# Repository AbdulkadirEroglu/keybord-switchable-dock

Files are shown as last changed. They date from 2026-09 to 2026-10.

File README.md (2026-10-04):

# Dual-PC Keyboard Router & Wireless Control Pad

A custom hardware project for sharing one physical USB keyboard between two computers while adding a detachable wireless control pad for call controls, media controls, macros, status feedback, and target selection.

The design prioritizes **reliability, recoverability, wired PC connections, explicit physical control, and independent debug paths**.

## System Overview

The project consists of two custom devices:

1. **Main Dock / Keyboard Router (v2)**
   - Accepts a normal USB keyboard (USB-C).
   - Connects to both Personal and Work PCs over USB and appears as a keyboard to each.
   - Routes keyboard/HID reports to the selected target.
   - Receives the pad's events and selector state over BLE.
   - Powered by its own **USB-C PD charger** (asks for 9 V; a 30 W charger is used). It never draws power from, or back-feeds, the PCs.
   - Chips on the board, built by **JLCPCB** (machine assembly); two through-hole parts are hand-soldered.

2. **Wireless Control Pad** (to be redesigned; current plan below)
   - Detachable and battery powered.
   - 12 mechanical keys.
   - Two rotary encoders with push switches.
   - 36 addressable RGB LEDs.
   - 1.69" colour IPS display (SPI).
   - Physical `PERSONAL | OFF | WORK` metal toggle switch.
   - Li-ion 21700 battery pack, charged while docked.
   - BLE is the normal data link; the pogo UART is reserved for diagnostics/recovery.

## High-Level Architecture

```text
┌──────────── WIRELESS CONTROL PAD ────────────┐
│ Pico 2 WH (RP2350 + CYW43439)   [v1 plan]    │
│ keys, encoders, RGB, display, selector,      │
│ battery + charger                            │
└──────────┬──────────────────────┬────────────┘
           │ BLE                  │ 7-pin magnetic pogo (5 V, DET, UART)
           ▼                      ▼
┌────────────────────── MAIN DOCK (v2) ──────────────────────┐
│ ESP32-C3-MINI-1 (BLE) ── UART ──┐                          │
│                                 ▼                          │
│ keyboard ═ USB-C ═ PIO-USB ═► RP2354A A ═ USB ═► PERSONAL  │
│                                 │ UART, RUN, BOOTSEL, SWD  │
│                                 ▼                          │
│                             RP2354A B ═══ USB ═► WORK      │
│                                                            │
│ USB-C PD charger ─ CH224A (9 V) ─ TPS54331 5 V ─ 3.3 V LDO │
└────────────────────────────────────────────────────────────┘
```

## Main Hardware

### Dock (v2)

| Function | Part |
|---|---|
| Keyboard host + Personal PC endpoint | RP2354A **A** (RP2350 with 2 MB flash, QFN-60): Pico-PIO-USB host + native USB device |
| Work PC endpoint | RP2354A **B** (native USB device) |
| BLE to the pad | ESP32-C3-MINI-1-H4X module (pre-certified, PCB antenna), UART to A |
| Power input | USB-C, CH224A PD sink (9 V, I2C status to A), SMBJ15A TVS |
| 5 V | TPS54331 buck (5.16 V, 3 A), SLO0630H6R8MTT 6.8 µH, SS54 |
| 3.3 V | AMS1117-3.3 |
| Keyboard VBUS | SY6280AAC, 1.0 A, switched on only when a keyboard is detected on CC |
| Pad 5 V (pogo) | SY6280AAC, 1.45 A, switched on in hardware when the pad is docked (DET) |
| ESD | TPD4E1U06 on every USB-C port and the pogo contacts |
| Connectors | 4 × USB-C (TYPE-C-31-M-12); 7-pin JST-XH header to the pogo board in the dock lid (straight 7-pin magnetic pogo contacts) |
| Crystals | ABM8-272-T3 (Raspberry Pi's recommended part) |

Every part, its value and LCSC number: [`hardware/dock-v2/DOCK_CONNECTIONS.md`](hardware/dock-v2/DOCK_CONNECTIONS.md). Why each was chosen: `docs/dock-v2-*.md`.

### Pad (v1 plan, to be redesigned)

| Function | Selected Part / Design |
|---|---|
| Pad MCU / wireless | Raspberry Pi Pico 2 WH, socketed (on-board buck-boost 3.3 V) |
| Pad GPIO expander | TCA9555 |
| Pad charger | TP4056 (switchable ≈ 146 / 510 mA, NTC 0–45 °C, Pico-controlled enable for a 70–80 % docked window) |
| Pad power path | TPS2116 (pogo 5 V priority, battery fallback) |
| Cell protection | DW01A + FS8205A |
| Battery | 2 × Samsung SDI INR21700-50E in parallel (3.6 V, ≈ 9.8 Ah Li-ion), dual 21700 holder |
| RGB 5 V boost | TPS61023 |
| RGB logic buffer | SN74AHCT1G125 |
| RGB LEDs | 36 × SK6812MINI-E (reverse mount) |
| Keys | 12 × Razer Yellow Linear (3-pin MX) in Kailh hot-swap sockets, FR4 plate |
| Encoders | 2 × Bourns PEC11R-4220F-S0024 (24 detents, push switch) |
| Target selector | Metal SPDT ON-OFF-ON toggle |
| Display | 1.69" 240×280 IPS TFT, ST7789, SPI, PWM backlight |

## Target Selection

The physical selector is located on the **control pad**, not the dock.

```text
PERSONAL
   │
  OFF
   │
 WORK
```

The mechanical switch is the source of truth. Its state travels:

```text
Toggle → Pad → BLE → ESP32-C3 → UART → RP2354A A
```

If the pad/BLE connection is lost, the dock must eventually release all active HID states and enter `OFF`.

## Communications

- Keyboard → RP2354A A: USB host (Pico-PIO-USB)
- RP2354A A → Personal PC: USB HID (native USB)
- RP2354A A ↔ RP2354A B: 1 Mbaud+ UART; B → Work PC: USB HID
- Pad ↔ dock: BLE (ESP32-C3 central, pad peripheral), ESP32-C3 ↔ A: UART
- Pogo UART (A's PIO UART): debug/recovery only

The internal UART protocol uses framed binary packets:

```text
SOF | TYPE | SEQ | LEN | PAYLOAD | CRC
```

Normal HID reports may be fire-and-forget. Critical control operations can require acknowledgement.

## Fail-Safe Philosophy

The design should fail toward **released keys and no routing**, not toward a stuck input.

- Target change → release the previous endpoint before changing the route.
- `OFF` → release both endpoints.
- BLE/pad timeout → release all and route OFF.
- A ↔ B link timeout → B sends a released state and idles; A can reset B.
- Keyboard faults → A power-cycles the keyboard's VBUS.
- Every MCU has a physical recovery path, and A can reflash B (SWD) and the ESP32-C3 (UART) from the Personal PC.

## Mechanical Baseline

- **Dock:** PCB 100 × 100 mm, 2 layers. PC cables leave at the back, the keyboard at the left, the charger at the right. **The pad sits on top of the dock:** the pogo contacts are on a small board in the dock lid, cabled to the dock board.
- **Pad (v1 plan):** wedge enclosure ≈ 160 × 110–120 mm, front ≈ 25 mm, back ≈ 44 mm, battery at the back under the display/encoder row.

Docking contacts (dock side), magnets on both sides:

```text
GND | +5V | DET | RX | TX | +5V | GND
```

## Repository Layout

```text
dock-pad/
├── hardware/
│   ├── dock-v2/        v2 dock: KiCad project, DOCK_CONNECTIONS.md, PCB_PLACEMENT.md
│   ├── dock/           v1 dock (Pico modules), reference
│   ├── pad/            pad (v1 plan)
│   ├── pogo/           pad pogo board
│   ├── libraries/      shared symbols/footprints/3D models (THIRD_PARTY.md)
│   ├── reference/      Raspberry Pi RP2350A Minimal design (MIT)
│   └── tools/          RPi core-layout copy script, dock v2 connection model and wiring checker
├── mechanical/
├── firmware/
├── datasheets/
├── docs/               dock v2 design decisions (dock-v2-*.md), pad drawings
├── README.md
└── DESIGN.md
```

## Current Project State

- **Dock v2 (branch `dock-v2`):** every part decided and placed on the six schematic sheets (154 parts, values, footprints, LCSC numbers). Next: wiring the schematic by hand from [DOCK_WIRING.md](hardware/dock-v2/DOCK_WIRING.md) (component by component; the circuit is explained in DOCK_CONNECTIONS.md) (checked with `hardware/tools/dock_v2_connections/check_wiring.py`), then placement and routing on a 4-layer board. The order cost will be calculated when the PCB is ready.
- **Pad:** being redesigned. Decided so far: **ESP32-S3-MINI-1-N8** (MCU + BLE, JLC assembly), the pad **sits on top of the dock** with its pogo board in the floor, **1 × 21700-50E** with an **ETA6003** switching charger (power path), charged only on the dock, TLV75733P 3.3 V LDO, direct-GPIO keys/encoders, SK6812MINI-E + XL-2020 LEDs on a TPS61023 5 V boost, Meon 1.69" ST7789 module. Decisions: `docs/pad-v2-*.md`. The rest of `hardware/pad/` is still the v1 plan.
- **v1 dock:** complete (routed, DRC clean) on `master`; superseded by v2.

See [DESIGN.md](DESIGN.md) for the engineering baseline.

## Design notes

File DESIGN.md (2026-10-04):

# DESIGN.md — Engineering Baseline

**Status (2026-09-29, branch `dock-v2`):**

- **Dock: v2**, chips on the board, JLCPCB assembly. Decided part by part in the design review; the reasoning is in `docs/dock-v2-mcu-selection.md`, `dock-v2-power-input.md`, `dock-v2-usb-ports.md`, `dock-v2-pogo.md`, `dock-v2-mcu-support.md`. The wiring is in [`hardware/dock-v2/DOCK_CONNECTIONS.md`](hardware/dock-v2/DOCK_CONNECTIONS.md), placement in [`hardware/dock-v2/PCB_PLACEMENT.md`](hardware/dock-v2/PCB_PLACEMENT.md). Sections 1–7 and 16–22 below describe the v2 dock.
- **Pad: to be redesigned.** Sections 8–14 are the v1 pad plan, kept unchanged as the starting point. Section 15 (docking) already has the v2 7-pin interface.
- **v1 dock** (three Pico modules, powered from the PCs): complete on `master` (`hardware/dock/`, the v1 version of this file).

## 1. Design Goals

- One physical USB keyboard shared between two computers.
- PC-side connections remain wired USB.
- No software running on either PC is required for basic keyboard routing.
- Physical `PERSONAL | OFF | WORK` selection (on the pad).
- Detachable wireless control pad.
- Robust recovery and debug access: every MCU can be reflashed without special tools.
- **The dock is powered by its own USB-C PD charger** (≥ 18 W; a 30 W charger is used). It does not draw power from the PCs, and it never back-feeds a PC that is switched off. (v1 ran from the PCs; dropped in v2, see `docs/dock-v2-power-input.md`.)
- Pad charges automatically while docked.
- BLE is used only between the pad and the dock.
- Failure states must avoid stuck keyboard/modifier/media reports.
- **Built by JLCPCB** (machine assembly of the fine-pitch parts); only a few through-hole parts are hand-soldered.

---

## 2. System Partitioning

### 2.1 Main Dock (v2)

Responsibilities:

- USB-host the physical keyboard (USB-C port, the dock is the source).
- Present a USB keyboard to each PC.
- Route keyboard/HID reports to the selected target.
- Receive pad events and the selector state over BLE.
- Power the keyboard (switched, current-limited) and the docked pad (switched by DET, current-limited).
- Negotiate 9 V from a USB-C PD charger and make 5 V and 3.3 V.

```text
 charger ═ J101 ─ CH224A (9 V) ─ TPS54331 ─ +5V ─┬─ AMS1117 ─ +3V3
                                                 ├─ SY6280 ─ KBD_VBUS ─► keyboard
                                                 └─ SY6280 ─ POGO_5V ──► pad
 keyboard ═ J201 ═ PIO-USB ─┐
                            ▼
 Personal PC ═ J202 ═══ RP2354A A ◄── UART0, RUN, BOOTSEL, SWD ──► RP2354A B ═══ J203 ═ Work PC
                            │  └── UART1 ──► ESP32-C3-MINI-1 ~~ BLE ~~ pad
                            └── PIO UART, DET ──► pogo J601 ═ pad (docked)
```

| Device | Ref | Job |
|---|---|---|
| RP2354A **A** (RP2350 + 2 MB flash, QFN-60) | U301 | Keyboard host (Pico-PIO-USB), Personal PC device (native USB), router, controls B, the ESP32 and the pogo |
| RP2354A **B** | U401 | Work PC device (native USB) |
| ESP32-C3-MINI-1-H4X | U501 | BLE central to the pad (pre-certified module, PCB antenna), UART to A |
| CH224A | U102 | USB-PD sink: asks for 9 V; I2C status to A |
| TPS54331 + SS54 + 6.8 µH | U103, D102, L101 | 5 V buck (5.16 V), 3 A; 100 % duty pass-through on a 5 V-only charger |
| AMS1117-3.3 | U104 | 3.3 V for A, B, the ESP32 |
| SY6280AAC × 2 | U202, U602 | Keyboard VBUS switch (1.0 A), pogo 5 V switch (1.45 A) |
| TPD4E1U06 × 5 | U101, U201, U203, U204, U601 | ESD on every USB-C port and the pogo contacts (clamps to GND only: no back-feed path into an unpowered PC) |
| TYPE-C-31-M-12 × 4 | J101, J201, J202, J203 | Power, keyboard, Personal PC, Work PC |
| Magnetic pogo, 7 pins | J601 | Pad docking (hand-soldered) |

Why two chips: no affordable MCU has three USB 2.0 controllers (researched in `docs/dock-v2-mcu-selection.md`); A does the host and one device, B the other device. Why RP2354A: same firmware base as v1 (TinyUSB + Pico-PIO-USB, hub support), UF2 flashing, no programmer needed.

### 2.2 Wireless Control Pad (v1 plan, to be redesigned)

> **Being redesigned (v2, 2026-10-04).** Decided so far: ESP32-S3-MINI-1-N8 replaces the Pico 2 WH and the TCA9555 (`docs/pad-v2-mcu-selection.md`); the pad sits on top of the dock (§15); one 21700-50E with an ETA6003 switching charger replaces the 2-cell pack, TP4056 and TPS2116, no USB-C charging, 3.3 V from a TLV75733P LDO (`docs/pad-v2-battery-charging.md`); keys, encoders and toggle on direct GPIOs (no TCA9555), hand-soldered hot-swap sockets and SK6812MINI-E key LEDs, XL-2020 ring LEDs, TPS61023 + AHCT1G125 (`docs/pad-v2-inputs-rgb.md`); Meon 1.69" ST7789V3 module on a cable, AO3401 power switch, PWM straight into BLK (`docs/pad-v2-display.md`). Sections 8–14 below are the v1 plan and are superseded where these docs differ.

Responsibilities:

- Read 12 mechanical keys.
- Decode two rotary encoders.
- Read two encoder push switches.
- Read the target selector.
- Drive 36 addressable RGB LEDs.
- Drive the display.
- Communicate with dock over BLE.
- Monitor battery and charger state.
- Manage sleep/wake and switched peripheral power.
- Charge from docked 5 V input.

Primary devices:

- MCU + BLE — Raspberry Pi Pico 2 WH (RP2350 + CYW43439), socketed like the dock modules (§18.1)
- TCA9555 — 16-bit I2C GPIO expander (keys, encoder switches, selector)
- TP4056 — Li-ion linear charger (ESOP-8), Pico-controlled enable
- TPS2116 — power path: pogo 5 V (priority) or battery → `PAD_SYS`
- DW01A + FS8205A — cell protection (over-discharge, overcurrent, short)
- TPS61023 — 5 V boost for the RGB LEDs
- TPS22919 — OLED load switch
- SN74AHCT1G125 — RGB data level shifter
- 2 × Samsung SDI INR21700-50E Li-ion cells (4900 mAh each, 9.8 Ah total) in parallel, in a dual 21700 holder, with a 10 k NTC between them
- 36 × SK6812MINI-E reverse-mount RGB LEDs
- 1.69" 240 × 280 ST7789 colour IPS display
- Separate small pogo board in the back wall (pogo connector, TVS, ESD), cable to the main board
- 12 × Razer Yellow Linear (MX-compatible, 3-pin) switches in Kailh hot-swap sockets, FR4 switch plate
- 2 × Bourns PEC11R-4220F-S0024 encoders with push switch

All parts are hand-solderable (leaded packages, or the TPS2116/TPS61023 TI SOT-5x3 family with extended hand-solder pads). No BGA/QFN/WSON parts: the BQ25185 and TPS63802 were dropped for that reason.

The Pico 2 WH has its own buck-boost 3.3 V regulator that runs from 1.8–5.5 V on `VSYS`, so the pad needs no 3.3 V regulator; the Pico's `3V3` pin (≤ 300 mA recommended) powers the TCA9555, pull-ups and the OLED switch.

---

## 3. Dock USB Ports (v2)

All four are the same 16-pin USB 2.0 USB-C receptacle (TYPE-C-31-M-12, rated 20 V / 5 A), each with a TPD4E1U06 within 5 mm (D+, D−, CC1, CC2).

| Port | Role | CC | Data | VBUS |
|---|---|---|---|---|
| J101 power (right edge) | sink | CH224A (built-in Rd) | CH224A D+/D− (QC/BC1.2) | VBUS_IN, SMBJ15A TVS |
| J201 keyboard (left edge) | **source** | 33 k Rp to 3.3 V (Default USB), read by A's ADC | A GPIO3 D+ / GPIO2 D− (PIO-USB, `PIO_USB_PINOUT_DMDP`) via 22 Ω, 15 k host pull-downs | KBD_VBUS from SY6280, 220 µF THT + 10 µF + 1 µF |
| J202 Personal PC (back) | sink | 5.1 k Rd | A USB_DP/DM via 22 Ω | **sense only**: 22 k / 33 k divider to A GPIO1 |
| J203 Work PC (back) | sink | 5.1 k Rd | B USB_DP/DM via 22 Ω | **sense only**: divider to B GPIO29 |

- **Keyboard port (cold socket):** KBD_VBUS stays off until A sees a sink's Rd on CC (≈ 0.44 V) for > 100 ms; off again on unplug. A charger or PC plugged in by mistake shows Rp, so the dock never turns VBUS on against it. EN has a 100 k pull-down: off at reset and with blank firmware.
- **PC ports:** the dock takes no power from the PCs. Each MCU enables its D+ pull-up (connects) only while its PC's VBUS is present.
- Ground is shared by both PCs, the charger and the dock (as in v1 and every KVM switch); the charger is isolated.

---

## 4. Dock Power (v2)

### 4.1 Input

```text
J101 VBUS ─ VBUS_IN ─┬─ SMBJ15A ─ GND
                     ├─ CH224A VHV/VBUS (CFG1 = 6.8 k → asks 9 V; SCL/SDA/PG → MCU A)
                     └─ TPS54331 VIN
```

- **9 V** is mandatory on every PD source above 15 W (12 V is optional and often missing).
- CH224A over I2C (0x22): which protocol won, requested voltage, maximum current of the current profile; can re-request 5 V. PG is a backup. The pad's charge speed follows from this (§12.2).
- On a charger without PD the dock still runs: the TPS54331 runs at 100 % duty and passes ≈ 4.7 V through; firmware then keeps pad charging slow.

### 4.2 Rails

| Rail | Source | Notes |
|---|---|---|
| +5V | TPS54331, 12 k / 2.2 k → 5.16 V | TI Table 7-1 values on Basic parts: 51 k + 4.7 nF + 47 pF compensation, 10 nF soft start, 3 × 22 µF out; L101 SLO0630H6R8MTT (Isat 8 A > 5.8 A max current limit). EN left open (a UVLO divider would stop the 5 V pass-through). |
| +3V3 | AMS1117-3.3 from +5V | ≤ 0.4 A peak (A, B, ESP32 BLE TX ≈ 170 mA at 0 dBm) |
| KBD_VBUS | SY6280, R_SET 6.8 k → 1.0 A (0.75–1.25 A) | EN from A (100 k pull-down); KBD_VBUS measured by A's ADC (replaces a fault pin) |
| POGO_5V | SY6280, R_SET 4.7 k → 1.45 A (1.09–1.81 A) | EN pulled high only when the pad grounds DET (hardware); A can veto (§15); POGO_5V measured by A's ADC |

### 4.3 Budget

| Load | Typical | Limit |
|---|---|---|
| Keyboard | 0.1–0.2 A (current keyboard: 200 mA rated) | 1.0 A |
| Pad (charging 0.51 A + electronics + LEDs) | 0.7–0.8 A | 1.45 A |
| 3.3 V rail | 0.15 A | 0.4 A |
| **+5V total** | **≈ 1 A** | ≈ 2.85 A at the nominal limits (TPS54331: 3 A) |

From 9 V at ≈ 90 % efficiency, even the worst case is ≈ 17 W: fine for the 30 W charger.

---

## 5. USB Endpoint Architecture (v2)

- **MCU A** is the keyboard host *and* the Personal PC's keyboard (native USB device). **MCU B** is the Work PC's keyboard. Each enumerates with its PC and stays enumerated when not selected.
- Each endpoint exposes at least Keyboard HID and Consumer Control HID; a vendor HID interface is optional.
- A and B run different firmware images (A: TinyUSB host + device + router + BLE link; B: device + link only).
- Each MCU watches its own PC's VBUS and connects its D+ pull-up only while VBUS is present (no back-feed into a PC that is off).
- A controls B: **RUN** (reset), **BOOTSEL** (via 1 k to B's QSPI_SS) and **SWD** (A can reflash and recover B, Raspberry Pi debugprobe style). B_RUN and B_BOOTSEL have 10 k pull-ups so A's reset-state pull-downs can't hold B in reset or BOOTSEL.

---

## 6. Internal Links (v2)

| Link | MCU A pins | Other end | Implementation |
|---|---|---|---|
| A ↔ B (HID reports, Work PC) | GPIO24 TX / GPIO23 RX | B GPIO5 RX / GPIO6 TX | hardware UART1 (RX on A and TX on B use the F11 aux function), 1 Mbaud or faster |
| A ↔ ESP32-C3 (BLE data, ESP32 flashing) | GPIO12 TX / GPIO13 RX | ESP32 RXD0 / TXD0 | hardware UART0 |
| ESP32 control | GPIO9 → EN, GPIO10 → GPIO9 (BOOT) | 10 k pull-ups, EN RC 10 k / 1 µF | open-drain |
| Pogo UART (diagnostics/recovery) | GPIO16 TX / GPIO15 RX; GPIO14 DET, GPIO11 OFF | pad, through 1 k on each side | PIO UART |
| CH224A | GPIO18 SDA / GPIO19 SCL, GPIO17 PG | CH224A | I2C1 |
| B control | GPIO20 RUN, GPIO25 BOOTSEL, GPIO22/21 SWCLK/SWDIO | B | open-drain / PIO SWD |

The full pin maps (every GPIO, with the reason for each choice) are in DOCK_CONNECTIONS.md §5–6. Keystrokes never pass through BLE: BLE carries only pad events and the selector state. With the radio on its own module, BLE stack faults can't disturb USB timing on A.

### 6.1 Packet Framing

Baseline (unchanged from v1):

```text
SOF | TYPE | SEQ | LEN | PAYLOAD | CRC
```

Likely message classes: `KEYBOARD_REPORT`, `CONSUMER_REPORT`, `RELEASE_ALL`, `PING`, `PONG`, `GET_STATUS`, `STATUS`, `RESET_USB`, `SET_MODE`.

Prefer complete HID state/report messages over key-down/key-up event streams. Normal HID traffic need not wait for an ACK; critical control operations may use ACK/sequence verification.

---

## 7. Routing Safety

Target changes (the Personal side is A's own USB device; the Work side is B over UART0):

- **PERSONAL → WORK:** receive the new selector state → release all on A's Personal device → change the route → B starts from a released state → forward the current state to B.
- **WORK → PERSONAL:** the same, reversed (`RELEASE_ALL` to B first).
- **Any target → OFF:** release Personal, send `RELEASE_ALL` to B, route NONE.
- **BLE loss** (no valid pad state for the timeout): release all, route OFF.
- **A ↔ B link loss:** B watches the link independently; on timeout it sends released keyboard and consumer reports, stays enumerated and idles safely. A resets B (RUN) if the link doesn't recover.
- **Keyboard faults:** A can power-cycle KBD_VBUS (SY6280 EN) to force re-enumeration.

---

> **Sections 8–14: the v1 pad plan, kept unchanged.** The pad will be redesigned; treat these as the starting point, not as decisions.

## 8. Pad User Interface

### 8.1 Mechanical Keys

V1:

- 12 keys
- Razer Yellow Linear (Gen-3) switches: MX-compatible, 3-pin, 45 g, transparent housing with an LED lens
- Kailh MX hot-swap sockets on the PCB
- 1.5 mm FR4 switch plate (14 mm cutouts), held on spacers to the pad PCB and enclosure. 3-pin switches have no PCB-locating pegs, so the plate carries them.
- 4 × 3 arrangement
- approximately 19.05 mm pitch
- One SK6812MINI-E per key, reverse-mounted under the switch's LED lens (§10)

```text
[01] [02] [03] [04]
[05] [06] [07] [08]
[09] [10] [11] [12]
```

### 8.2 Encoders

Two rotary encoders with push switches: Bourns PEC11R-4220F-S0024 (TME): 24 detents / 24 pulses, 20 mm metal flatted shaft, push switch, EC11-compatible 5-pin THT footprint (datasheet `datasheets/pec11r.pdf`). 24 detents = 2 clicks per LED on the 12-LED ring.

Intended roles:

- Encoder 1: volume
- Encoder 2: microphone/call controls

Quadrature A/B signals connect directly to Pico GPIO and are decoded by PIO. Each A/B line has a 10 kΩ pull-up to 3V3 and 10 nF to GND (debounce); the encoder common goes to GND.

Push switches connect through TCA9555.

### 8.3 Target Selector

Physical metal panel-mount SPDT `ON-OFF-ON` toggle.

States:

```text
PERSONAL
OFF
WORK
```

Two TCA9555 inputs encode the state:

| Input A | Input B | State |
|---:|---:|---|
| 0 | 1 | PERSONAL |
| 1 | 1 | OFF |
| 1 | 0 | WORK |
| 0 | 0 | INVALID / FAULT |

The selector is the authoritative target state.

---

## 9. TCA9555 Allocation

16 GPIO total:

```text
12 × mechanical keys
 2 × encoder push switches
 2 × target-selector contacts
------------------------------
16 × GPIO
```

- I2C SDA/SCL → Pico (hardware I2C)
- INT → Pico GPIO (also the wake source from dormant sleep)
- Exact pull-up implementation must be verified against the selected TCA9555 variant/datasheet during schematic capture.
- Encoder A/B signals do not use the expander.

### 9.1 Pad Pico GPIO Allocation

Initial map from the schematic (grouped by function; may be re-pinned by PCB position, as on the dock):

| GPIO | Pin | Signal | GPIO | Pin | Signal |
|---|---|---|---|---|---|
| GP0 | 1 | PAD_UART_TX (UART0, pogo) | GP16 | 21 | RGB_EN (TPS61023 EN) |
| GP1 | 2 | PAD_UART_RX (UART0, pogo) | GP17 | 22 | CHG_FAST (PROG MOSFET) |
| GP2 | 4 | ENC1_A (PIO) | GP18 | 24 | CHG_INHIBIT (CE MOSFET) |
| GP3 | 5 | ENC1_B (PIO) | GP19 | 25 | CHG_CHRG_N |
| GP4 | 6 | I2C_SDA (I2C0) | GP20 | 26 | CHG_STDBY_N |
| GP5 | 7 | I2C_SCL (I2C0) | GP21 | 27 | DOCKED (TPS2116 ST) |
| GP6 | 9 | ENC2_A (PIO) | GP22 | 29 | OLED_EN (TPS22919 ON) |
| GP7 | 10 | ENC2_B (PIO) | GP26 | 31 | VBAT_SENSE (ADC0, VBAT/2) |
| GP8 | 11 | TCA_INT_N (wake source) | GP27 | 32 | OLED_BLK (display backlight PWM) |
| GP9 | 12 | RGB_DATA_3V3 (PIO) | GP28 | 34 | spare (ADC2) |
| GP10 | 14 | OLED_SCK (SPI1) | GP15 | 20 | free (1×19 socket possible) |
| GP11 | 15 | OLED_MOSI (SPI1 TX) | | | |
| GP12 | 16 | OLED_DC | | | |
| GP13 | 17 | OLED_CS (SPI1 CSn) | | | |
| GP14 | 19 | OLED_RES | | | |

---

## 10. RGB System

### 10.1 LED Count

```text
Volume encoder ring       12
Microphone encoder ring   12
Key LEDs                  12
----------------------------
Total                     36
```

LED: SK6812MINI-E (reverse mount, side legs reachable with an iron), one part for keys and rings, one chain. Each LED sits in a small PCB cutout and shines up through it. Sourced from LCSC (C5149201), combined with the JLCPCB order.

Design power budget must tolerate approximately:

```text
36 × 15 mA ≈ 540 mA @ 5 V
≈ 2.7 W
```

even though firmware will normally impose a much lower global brightness.

### 10.2 RGB Power

```text
PAD_SYS
    │
TPS61023 (boost, EN from Pico)
    │
  5V_RGB
    ├── SN74AHCT1G125
    └── RGB LEDs
```

TPS61023 (SOT-563, hand-solder footprint like the TPS2116):

- Output set to ≈ 5.05 V: R1 = 750 kΩ (VOUT→FB), R2 = 100 kΩ (FB→GND); VREF ≈ 0.6 V ±2.5 %, worst case ≈ 5.2 V (< SK6812 5.5 V max).
- Inductor 1 µH, shielded ~4 × 4 mm, I_sat ≥ 4.5 A, DCR ≤ 20 mΩ (TI-recommended: Würth 74438357010, Coilcraft XEL4030-102ME, or equivalent). Worst-case peak ≈ 3.8 A at 2.7 V in, 1.5 A out.
- C_in 10 µF; C_out 2 × 22 µF X7R ≥ 16 V (≥ 4 µF effective after DC bias).
- `EN` from a Pico GPIO with a 100 kΩ pull-down, so the LEDs stay off while the Pico boots.
- True output disconnect when disabled: the LEDs draw nothing when the rail is off (SK6812 idle current would otherwise drain the cell).
- Docked (`PAD_SYS` ≈ 5 V) the device enters pass-through; on battery it boosts.

### 10.3 RGB Data

```text
Pico 3.3 V GPIO (PIO)
        │
SN74AHCT1G125
        │
 5 V logic data
        │
 33–100 Ω footprint
        │
 SK6812MINI-E DIN
```

Buffer supply comes from `5V_RGB` so the RGB subsystem loses both power and data drive when disabled.

---

## 11. Display

Display is required in V1.

Module: 1.69" 240 × 280 colour IPS TFT, ST7789 (V3) controller, SPI, rounded corners (Meon Otomasyon, "TFT LCD 1.69 İnç 240x280 ST7789 V3 SPI Display Modülü"). Chosen over the 1.3" monochrome OLED for colour and resolution at about the same module size, over the 1.9" 170 × 320 bar (not sold as a bare module in Turkey) and over the 2.0" GMT020-02 (its 62 × 37 mm module would push the board to ≈ 120 mm wide, and its backlight cannot be dimmed).

Typical pinout of these 8-pin modules (verify against the actual board before the PCB):

```text
GND
VCC   (3.3–5 V)
SCL   (SPI clock)
SDA   (SPI MOSI, not I2C)
RES
DC
CS
BLK   (backlight)
```

Backlight: ≈ 41 mA measured on this module type. BLK is driven through a P-MOSFET (AO3401A) from `OLED_VCC`, gate from Pico GP27 with a 10 kΩ pull-up to `OLED_VCC` (backlight off until firmware pulls GP27 low; PWM for dimming). The MOSFET works whether BLK is a direct LED anode or the input of an on-module transistor.

Firmware: ST7789 at 240 × 280 needs a 20-row offset (the controller RAM is 240 × 320).

Connection: the module is mounted to the case behind its window and wired to the main PCB with a short (≈ 10 cm) 9-wire JST-PH 2.0 mm cable (9-pin chosen because the ready-made cable is in stock at Robotistan). Main PCB: JST B9B-PH-K-S (9-pin PH, through-hole, shrouded, keyed; TME). Pins 1–8 carry the module's 8 signals; pin 9 is a second GND for a better SPI return path. The cable's bare end is soldered to the module's pads, both GND wires to the module's GND pad. The display's pads come unpopulated, so no header is needed on the module.

Mechanical allowance:

- module about 31 × 38 mm (typical); measure the real board outline, window and holes before placement

Power:

```text
Pico 3V3 → TPS22919 → OLED_VCC → module VCC and backlight MOSFET
```

The net names keep the `OLED_` prefix from the first design; they now refer to this TFT.

Shutdown sequence:

1. Turn the backlight off (GP27 high).
2. Put the display into sleep.
3. Put SPI/control pins into a safe low/high-impedance state.
4. Disable TPS22919.

---

## 12. Pad Battery and Charging

### 12.1 Cell

Samsung SDI INR21700-50E (datasheet: `datasheets/samsung-inr21700-50e.pdf`, spec v0.2). Buy from TME (authorized distributor, genuine cells); verify weight ≤ 69 g on arrival.

| Item | Datasheet value |
|---|---|
| Chemistry | Li-ion, 3.6 V nominal |
| Capacity | ≥ 4900 mAh (0.2C), ≥ 4753 mAh (1C) |
| Charge voltage | 4.2 V, CC-CV |
| Standard charge | 0.5C = 2450 mA, 0.02C cut-off |
| Max charge current | 4900 mA (not for cycle life) |
| Discharge cut-off | 2.5 V |
| Max continuous discharge | 9.8 A |
| Cycle life | ≥ 80 % after 500 cycles (0.5C charge to 4.2 V / 1C discharge to 2.5 V, full depth) |
| Charge temperature | 0 to 45 °C (cell surface) |
| Discharge temperature | −20 to 60 °C |
| Storage | ex-factory at ~30 % (3.43–3.63 V); 1 year at −20 to 23 °C |
| Size / weight | Ø 21.25 × 70.80 mm max (with sleeve), flat top, 69 g max |

Operating window chosen for maximum life. The datasheet gives only the hard limits; the narrower window is standard Li-ion practice (lower average voltage and shallower cycles slow both calendar and cycle ageing):

| Limit | Value | Enforced by |
|---|---|---|
| Hard max (datasheet) | 4.20 V | Charger CV regulation |
| Docked hold window (default) | stop at 4.00 V, resume below 3.90 V (≈ 80 % / 70 %) | Firmware via the charger enable pin |
| Full charge on request | 4.20 V | Firmware (e.g. before a long undocked session) |
| Charge current | ≈ 510 mA fast / 146 mA slow (≈ 0.05C / 0.015C for the 9.8 Ah pack) | TP4056 PROG network (§12.2) |
| Charge temperature | 0 to 45 °C | Charger NTC input |
| Low-battery warning | ≈ 3.50 V under light load | Firmware |
| Graceful shutdown | ≈ 3.30 V under light load | Firmware |
| Hard min (datasheet) | 2.5 V | — |
| Hardware backstop | ≈ 2.4 V (DW01A) | §12.4 |

Pack: 2 × INR21700-50E in parallel (1S2P, ≈ 9.8 Ah) in Motorobit's dual 21700 holder, which is wired in parallel internally and comes with flying leads. The holder is fixed to the case; its leads go to a 2-pin JST-XH (2.5 mm, 3 A) on the pad PCB, and the NTC to a separate 2-pin JST-XH. The holder's thin leads are adequate: the worst-case pack current is ≈ 1 A (full RGB brightness on battery). Insert both cells at the same voltage (charge each to 4.0 V first); after that they stay balanced. A 10 kΩ B3950 NTC sits between the two cells and goes to the charger's NTC input. Per-cell current is half the pack current, so every datasheet current limit has 2× margin.

### 12.2 Charger

TP4056 (NanJing Top Power, ESOP-8, datasheet `datasheets/tp4056.pdf`; genuine part LCSC C16581, also sold locally). Linear 4.2 V CC-CV Li-ion charger. The CN3058E chosen earlier was LiFePO4-only.

```text
POGO_5V → SMAJ5.0A → TP4056 VCC
                        └── BAT → DW01A/FS8205A → 2 × INR21700-50E
```

| Pin | Name | Connection |
|---|---|---|
| 1 | TEMP | NTC network: R1 = 5.6 kΩ (VCC→TEMP), NTC ∥ R2 = 75 kΩ (TEMP→GND). Charging runs only while TEMP is 45–80 % of VCC → ≈ 0–45 °C (the cell's charge range) |
| 2 | PROG | R_PROG = 8.2 kΩ to GND (≈ 146 mA); a 2N7002/AO3400 N-MOSFET, gate from a Pico GPIO (100 kΩ pull-down), adds 3.3 kΩ in parallel → ≈ 2.35 kΩ (≈ 510 mA). I = 1200 / R_PROG |
| 3 | GND + exposed pad | GND pour with vias; hand-solder hole from the back |
| 4 | VCC | `POGO_5V` (4–8 V), 10 µF |
| 5 | BAT | Pack + (protected side), 10 µF |
| 6 | STDBY | Open-drain, low = charge complete. 10 kΩ pull-up to 3V3, to Pico GPIO |
| 7 | CHRG | Open-drain, low = charging. 10 kΩ pull-up to 3V3, to Pico GPIO |
| 8 | CE | High = charge. 100 kΩ pull-up to `POGO_5V`; a 2N7002 from CE to GND, gate from a Pico GPIO (100 kΩ pull-down), pulls it low |

- Float voltage 4.2 V (4.137–4.263 V), C/10 termination, trickle below 2.9 V, automatic recharge, thermal regulation at 145 °C junction.
- CE defaults to charging. The pad charges even with blank, crashed or mid-flash firmware; the Pico only ever stops charging (docked hold window 3.90–4.00 V, §12.1).
- The charge speed is chosen by the dock over BLE from what its charger offers (CH224A over I2C, §4.1; v1 used the PC port's CC advertisement). Fast ≈ 510 mA is ≈ 0.05C for the 9.8 Ah pack; dissipation ≈ (5 − 3.7) V × 0.51 A ≈ 0.65 W.
- Both status pins high means no input, sleep, or temperature fault.
- SMAJ5.0A TVS on the pad's `POGO_5V` (pogo contacts hot-plug; ceramic input capacitors can ring).

No single leaded IC combines Li-ion charging, power path and protection (BQ2407x, BQ25185, MCP73871, ISL9301, LTC4089 are all QFN/DFN/WSON), so the pad uses three leaded blocks: TP4056 (charger), TPS2116 (power path, §12.3) and DW01A + FS8205A (protection, §12.4).

### 12.3 Power Path

A TPS2116 (same part and hand-solder footprint as the v1 dock's `U1`) selects the pad's system rail:

```text
POGO_5V ──► VIN1 (priority) ─┐
                             ├──► PAD_SYS
BAT (protected) ──► VIN2 ────┘
```

- PR1 divider 300 kΩ / 100 kΩ from `POGO_5V` (≈ 4.0 V switchover), MODE tied to VIN1, as on the v1 dock.
- Docked, the loads run from the pogo, so the charger sees only the cell and terminates correctly.
- `ST` (open-drain, high when VIN1 is in use) is pulled up to 3V3 and read by the Pico as the docked signal.
- Reverse-current blocking: with USB plugged into the Pico for flashing, VBUS reaches `PAD_SYS` but cannot flow back into the cell or the charger. No extra diode is needed.

### 12.4 Cell Protection

Linear chargers of this class have no battery undervoltage disconnect, so a DW01A + FS8205A pair (SOT-23-6 + TSSOP-8, the standard 1S protection) sits in the cell's negative lead:

- Over-discharge cut-off ≈ 2.4 V: a last-resort backstop if firmware hangs undocked (firmware shuts down at ≈ 3.3 V)
- Overcurrent and short-circuit protection
- Overcharge cut-off ≈ 4.3 V: backstop above the charger's 4.2 V.

Firmware remains the primary discharge limit (§14).

---

## 13. Pad Power Rails

```text
POGO +5V ──┬── SMAJ5.0A TVS
           ├── Charger ──► BAT ↔ INR21700-50E (via DW01A/FS8205A)
           │                 │
           └── TPS2116 VIN1  └── TPS2116 VIN2
                     │
                  PAD_SYS  (≈ 5 V docked, 3.3–4.2 V on battery)
                     │
                     ├── Pico 2 WH VSYS ──► on-board buck-boost ──► 3V3
                     │                                                ├── TCA9555
                     │                                                ├── encoder/switch pull-ups
                     │                                                └── TPS22919 → OLED
                     │
                     └── TPS61023 → 5V_RGB
                                     ├── SN74AHCT1G125
                                     └── 36 RGB LEDs
```

TPS61023 must be sized for the full RGB worst-case load, not merely normal firmware brightness (§10.2).

---

## 14. Battery Measurement

- Cell voltage: a permanent 100 kΩ / 100 kΩ divider from BAT to a Pico ADC pin (GP26–GP28), with 100 nF at the ADC pin. It draws ≈ 18 µA, which is negligible against 5000 mAh. It reads the cell even when docked.
- `PAD_SYS`: the Pico's own VSYS/3 on ADC3 (GP29, shared with the radio; the SDK handles the switching).

Firmware thresholds: see the operating-window table in §12.1 (warning ≈ 3.50 V, shutdown ≈ 3.30 V, docked hold 3.90–4.00 V). Voltage-to-charge mapping is approximate; charge counting in firmware can refine it later.

---

## 15. Docking Interface

Seven magnetic pogo contacts (Motorobit **straight** 7-pin 2.54 mm set, rated 1 A per contact). **The pad sits on top of the dock** (decided 2026-10-04): flat contacts on a small pogo board in the dock lid, spring pins on the pad's underside. The lid board connects 1:1 to the dock board's J601 (JST-XH 7-pin B7B-XH-A). Contact order:

```text
 dock (J601):  GND | +5V | DET | RX | TX | +5V | GND
 pad:          GND | +5V | TX  | RX | DET | +5V | GND      (mirror: pad pin 1 meets dock pin 7)
```

- **+5V at both ends (pins 2 and 6), GND at both ends (pins 1 and 7):** Because +5V (pins 2, 6) and GND (pins 1, 7) are mirror-symmetric, a pad fitted the wrong way round still gets +5V on +5V and GND on GND: it is powered and charges normally. Only the UART lines cross (dock TX → pad DET, pad TX → dock DET, RX ↔ RX), all through 1 kΩ, so nothing is damaged; the pogo UART just doesn't work that way round.
- **+5V on two contacts, GND on two:** 2 A capacity, so the dock's pogo switch can be set to 1.45 A (1.09–1.81 A) and the pad needs **no LED dimming while docked** (worst case: charging 0.51 A + electronics 0.15 A + all 36 LEDs white 0.54 A ≈ 1.2 A). On a low-tolerance switch the limit can cap that corner; the pad's power path then falls back to the battery, nothing is damaged.
- **DET:** the pad ties it to GND. On the dock, DET is pulled up to 3.3 V and drives a 2N7002 that holds the pogo switch's EN low while undocked. Docked, EN goes high and the pad gets 5 V **without firmware**. MCU A can veto through a second 2N7002 (POGO_OFF); its gate pull-down means "no veto" while A is in reset or has no firmware. A reads DET and measures POGO_5V.
- **RX/TX:** PIO UART on MCU A (GPIO16 TX / GPIO15 RX) through 1 kΩ on the dock and 1 kΩ on the pad; names from the dock's side. Reserved for diagnostics, recovery and fallback; it does not replace BLE during normal docking.
- ESD (TPD4E1U06) at the contacts on both sides; SMAJ5.0A on the pad's +5V.
- Magnets on both sides of the pogo area provide alignment and retention.
- **Orientation:** reversed docking is harmless (power pins are symmetric, see above), but the pogo UART only works the right way round. Mark pin 1 on both silkscreens and on the case.

Pad side: small pogo board (`hardware/pogo/`, 7 pins: +5V on pins 2 and 6) in the pad's **floor**, cable to the main board. The dock's lid board uses the same design: two identical boards facing each other meet pin 1 to pin 7, which gives the mirrored order above.

---

## 16. Debug and Recovery

Every programmable MCU has a physical debug/recovery path.

### Dock (v2)

| MCU | Normal update | Recovery |
|---|---|---|
| A (U301) | UF2: BOOTSEL A button (or firmware reboot-to-BOOTSEL) → drive on the **Personal PC** | RESET A button; SWD header J401 (GND, SWDIO, SWCLK) |
| B (U401) | UF2: BOOTSEL B button → drive on the **Work PC**; or A puts B into BOOTSEL (B_RUN + B_BOOTSEL) | **A reflashes B over SWD** (B_SWCLK/B_SWDIO); SWD header J501 |
| ESP32-C3 (U501) | A holds GPIO9 low, pulses EN, and bridges esptool from the Personal PC to the ESP32's UART0 | test pads TP503–505: TXD0/RXD0, GND (the native-USB pads were dropped) |

A single USB cable to the Personal PC can therefore update all three chips.

### Pad

- Pico 2 WH SWD: no SWD header on the pad PCB (the Pico's SWD holes would sit under key 5's centre post); a probe goes on the Pico 2 WH's own 3-pin JST-SH debug connector with the bottom cover off
- USB on the Pico itself (BOOTSEL/UF2) when the enclosure is open
- Pogo UART (§15) when docked

Pad recovery hierarchy:

```text
BLE  → normal operation
UART → diagnostics/recovery
SWD  → low-level recovery
```

---

## 17. Mechanical Baseline

### Dock (v2)

- PCB **90 × 70 mm** to start (shrink after placement), 4 layers, all SMD on top. Edges: **PC cables at the back** (Personal left, Work right), **keyboard left**, **charger right**, **pogo front** (see `hardware/dock-v2/PCB_PLACEMENT.md`).
- ESP32-C3 antenna at the left edge, front half; no metal, magnets or screws within ≈ 15 mm.
- **The pad sits on top of the dock** (decided 2026-10-04): saves table space; raises the pad by the dock's height. Pogo contacts on a small board in the dock lid, cabled to J601 (JST-XH 7-pin); the pad's pogo board sits in its floor.

### Pad (v1 plan, to be redesigned)

Wedge-shaped enclosure: keys, encoders and display all sit on one sloped top surface, so the main PCB is mounted at the same slope.

Decided (2026-09-28):

- **Slope 9–10°** (can change if the layout or ergonomics need it).
- **Heights: front ≈ 25 mm, back ≈ 44 mm** over ≈ 115 mm depth (≈ 9.4°). The first estimate (front 18–22, back 35–40 mm) is too low: the 21 mm battery holder at the back would hit the sloped PCB. The PCB underside must clear ≈ 28 mm (3 mm floor + 21 mm holder + 2 mm gap + 2 mm bottom-side parts) over the holder's front edge, which needs ≈ 25 mm at the front.
- **One main PCB** carries the keys, key LEDs, both encoders with their 12-LED rings (SK6812MINI-E on the board), the Pico and all power parts. Only the pogo board (forced by the slope) and the display (for a flush fit in the case window) are on cables. Rejected: off-board WS2812 rings (the locally sold 12-LED rings are 50 mm across, which widens the board instead of shrinking it; 37 mm rings have no reliable local source) and cabled encoder modules (no price gain, generic encoders, two more cables).
- **Display sideways** (landscape): 1.69" module ≈ 38 mm wide × 31 mm tall, between the two encoders, mounted to the case behind its window and connected by a 9-wire JST-PH cable (8 signals + a second GND).
- **Battery at the back**, under the top row (display/encoders), in the thick rear section. Never under the key field: the hot-swap sockets fill the underside there and the front is too thin.
- **Pogo board at the back**, in the back wall, on top of or beside the battery. Its height and position are aligned with the dock's pogo connector (J601 on the v2 dock) in the 3D enclosure design.
- **Selector toggle** (PERSONAL/OFF/WORK) on the right side of the key field, panel-mounted, wired to J5.
- **Pico** on the back side of the main PCB **under the key field**, long axis left-right, pin rows in the gaps between key rows (y = 50.0 and 67.78 mm), antenna end at the left board edge (plastic case wall there). The display strip can't take it: both of its ends are occupied by the encoder rings, and the antenna needs an edge. Exact positions: `hardware/pad/PCB_PLACEMENT.md`, drawings `docs/pad-pcb-1-top.png` … `docs/pad-pcb-4-front-cut.png`.

Main PCB sizing (20 mm knob; ring LEDs on a 12 mm radius, just outside the knob, so each ring is ≈ 27 mm across; 2 mm gaps to the display). Concept drawing: `docs/pad-concept.png`.

```text
                 BACK (high side, docks here; battery, Pico and pogo board below/behind)
 ┌───────────────────────────────────────────────────────┐
 │   ◯ ENC 1       ┌──────────────┐       ◯ ENC 2       │ ← top row ≈ 31–35 mm
 │  (12-LED ring)  │ 1.69" TFT    │    (12-LED ring)     │
 │                 │  sideways    │                      │
 │                 └──────────────┘                      │
 │          [01]   [02]   [03]   [04]                    │
 │          [05]   [06]   [07]   [08]                    │ ← keys 76 × 57 mm
 │          [09]   [10]   [11]   [12]                    │
 └───────────────────────────────────────────────────────┘
                 FRONT (low side)             main PCB 100 × 92 mm
```

Top row width ≈ 27 + 2 + 38 + 2 + 27 mm plus 1.5 mm edges ≈ 99–100 mm: the main PCB just fits the cheapest 100 × 100 mm JLCPCB size. Tight; if it ends a few mm over, the price step is small.

Enclosure envelope (from the first baseline, to be refined in CAD): width ~160 mm, depth ~110–120 mm. The PERSONAL/OFF/WORK toggle is panel-mounted in the enclosure to the right of the keys and wired to J5, so it widens the enclosure, not the PCB.

Still to measure before the PCB: display module outline, window and holes; knob diameter.

---

## 18. PCB Design Direction

### Dock (v2)

- **4 layers:** L1 parts + signals, L2 solid GND, L3 3.3 V / 5 V pours, L4 signals. **All SMD on the top side** (one-sided JLCPCB assembly).
- Rules (project file): clearance 0.15 mm, minimum track 0.15 mm, minimum drill 0.25 mm (what Raspberry Pi's RP2350 core layout uses; inside JLCPCB's standard 4-layer limits). Net classes: Default 0.2 mm, Power 0.6 mm (VBUS_IN, +5V, +3V3, KBD_VBUS, POGO_5V, GND, BUCK_SW), USB 90 Ω pairs.
- **RP2354A core:** Raspberry Pi's RP2350A Minimal layout copied exactly (regulator inductor orientation, pours, crystal), by `hardware/tools/copy_rpi_core_layout.py` after F8.
- ESD at each connector; USB pairs short, over solid ground; series resistors near the MCU.
- Buck hot loop (input caps → TPS54331 → PH → SS54) compact on L1 over L2 ground; feedback away from the switch node.
- ESP32-C3 antenna keep-out on all layers (in the footprint).
- Hand-soldered: C201 (220 µF THT, Özdisan) and J601 (pogo). Everything else is placed by JLCPCB.

### Pad (v1 plan)

- 2 layers, bottom GND pour; see `hardware/pad/PCB_PLACEMENT.md`.

---

## 19. KiCad Project Structure

```text
hardware/
├── dock-v2/                     v2 dock (this design)
│   ├── dock-v2.kicad_pro / .kicad_sch / .kicad_pcb
│   ├── power, usb_ports, mcu_a, mcu_b, ble, pogo .kicad_sch
│   ├── dock_v2_custom.kicad_sym  (RP2354A, ESP32-C3-MINI-1, CH224A, TPS54331, SY6280, TPD4E1U06)
│   ├── DOCK_CONNECTIONS.md       (wiring, pin maps; generated)
│   └── PCB_PLACEMENT.md
├── dock/                        v1 dock (reference; current on master)
├── pad/                         pad (v1 plan; to be redesigned)
├── pogo/                        pad pogo board (7-pin)
├── libraries/
│   ├── dock.pretty              Pogo-6, Pogo-7, v1 footprints
│   ├── dock_v2.pretty           RPi RP2350A QFN-60, core inductor/cap, ESP32-C3-MINI-1, 220 µF P5.00
│   └── THIRD_PARTY.md           sources and licences
├── reference/rpi-rp2350a-minimal/   Raspberry Pi's design (MIT)
└── tools/
    ├── copy_rpi_core_layout.py
    └── dock_v2_connections/     connection model, guide generator, wiring checker
```

Dock v2 sheets (annotation: sheet number × 100): POWER (1xx), USB_PORTS (2xx), MCU_A (3xx), MCU_B (4xx), BLE (5xx), POGO (6xx).

Pad hierarchical sheets (v1 plan):

```text
ROOT
├── BATTERY_CHARGER
├── POWER_RAILS
├── MCU (Pico 2 WH; file still named nrf52840.kicad_sch until renamed)
├── INPUTS
├── RGB
├── DISPLAY
└── DOCK_INTERFACE
```

---

## 20. Schematic Capture Order

### Dock (v2)

All parts are placed on their sheets (values, footprints, LCSC numbers). Wire them following [DOCK_WIRING.md](hardware/dock-v2/DOCK_WIRING.md) (component by component; DOCK_CONNECTIONS.md explains the circuit):

1. POWER: J101, CH224A, TPS54331, AMS1117 (+ PWR_FLAGs)
2. USB_PORTS: keyboard source port and switch, both PC ports
3. MCU_A: core (as RPi), then the GPIO map
4. MCU_B: core, links to A, pull-ups
5. BLE: ESP32-C3 straps and UART
6. POGO: connector, switch, DET/veto transistors
7. `hardware/tools/dock_v2_connections/check_wiring.py` until it reports OK, then ERC
8. F8, board outline, connectors at their edges, `copy_rpi_core_layout.py` for U301 and U401, then placement and routing

### Pad (v1 plan)

1. 21700 holder, NTC, DW01A + FS8205A protection
2. Pogo input (TVS, ESD, series resistors)
3. TP4056 charger with CE control and switchable PROG
4. TPS2116 power path → `PAD_SYS`
5. TPS61023 5V RGB rail
6. Pico 2 WH (socketed, VSYS, SWD header)
7. TCA9555 + switches/selector
8. Encoders
9. SN74AHCT1G125 + SK6812MINI-E chain
10. TPS22919 + OLED
11. Battery ADC divider
12. Power decoupling and final ERC review

---

## 21. Items to Verify

### Dock (v2), on the first boards

- CH224A: idle voltage of SCL/SDA (internal pull-up level) before connecting them to MCU A; behaviour with a charger that has no 9 V.
- TPS54331: loop with a load step on +5V; pass-through voltage on a 5 V-only charger at 2 A.
- USB enumeration with 22 Ω series resistors (RPi uses 27 Ω; 27 Ω is an Extended part).
- 220 µF lead spacing (footprint P5.00) and the 7-pin pogo body/ears (footprint scaled from Pogo-6) against the delivered parts.
- ESP32-C3 BLE with A, B and PIO-USB running together; RP2354A current at 240 MHz.

### Pad

Resolved for the pad before schematic capture:

- MCU: Raspberry Pi Pico 2 WH, socketed; no 3.3 V regulator (on-board buck-boost)
- Cell: 2 × Samsung SDI INR21700-50E in parallel, operating window §12.1
- Encoders: Bourns PEC11R-4220F-S0024 (24/24, 20 mm flatted shaft, push switch)
- Charger: TP4056, R_PROG 8.2 kΩ / 8.2 kΩ ∥ 3.3 kΩ (≈ 146 / 510 mA), CE default-on with Pico override, NTC R1 5.6 kΩ, R2 75 kΩ
- Power path: TPS2116, pogo priority, ST = docked sense
- Cell protection: DW01A + FS8205A
- RGB boost: TPS61023, 750 kΩ / 100 kΩ (≈ 5.05 V), 1 µH ≥ 4.5 A inductor
- LEDs: 36 × SK6812MINI-E (LCSC)
- Switches: Razer Yellow Linear, 3-pin MX, Kailh hot-swap, FR4 plate
- Display: 1.69" 240 × 280 ST7789 IPS TFT (Meon Otomasyon), backlight via P-MOSFET on GP27
- Pogo: separate pogo board (7 pins since the v2 dock review), 4-wire JST-XH cable to the main board; position part of the redesign
- Battery measurement: permanent 100 kΩ / 100 kΩ divider + Pico VSYS/3

---

## 22. Design Rule

When choosing between a slightly simpler implementation and one that materially improves diagnosis/recovery, prefer the recoverable implementation.

The project intentionally retains:

- independent USB endpoint MCUs (v2: A for Personal, B for Work)
- BLE normal link
- pogo UART fallback
- physical SWD access
- keyboard VBUS power control
- endpoint watchdogs
- explicit OFF state
- fail-safe HID release behavior

These are deliberate design features rather than temporary development conveniences.
Exception (v2): BLE runs on a separate pre-certified module (ESP32-C3) instead of a BLE-capable MCU, so no RF layout of our own is needed; A can reset and reflash it. Keystrokes never pass through BLE.

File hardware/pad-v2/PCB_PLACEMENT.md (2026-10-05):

# Pad v2 — PCB Placement Guide

Where everything goes on the pad v2 main board and the shared pogo board. The parts were decided in `docs/pad-v2-*.md`; the wiring guide (PAD_CONNECTIONS) comes with the schematic. The v1 guide (`hardware/pad/PCB_PLACEMENT.md`) is the starting point: key grid, encoder footprint and LED chain order are kept.

Drawing (to scale): [docs/pad-v2-pcb-top.png](../../docs/pad-v2-pcb-top.png).

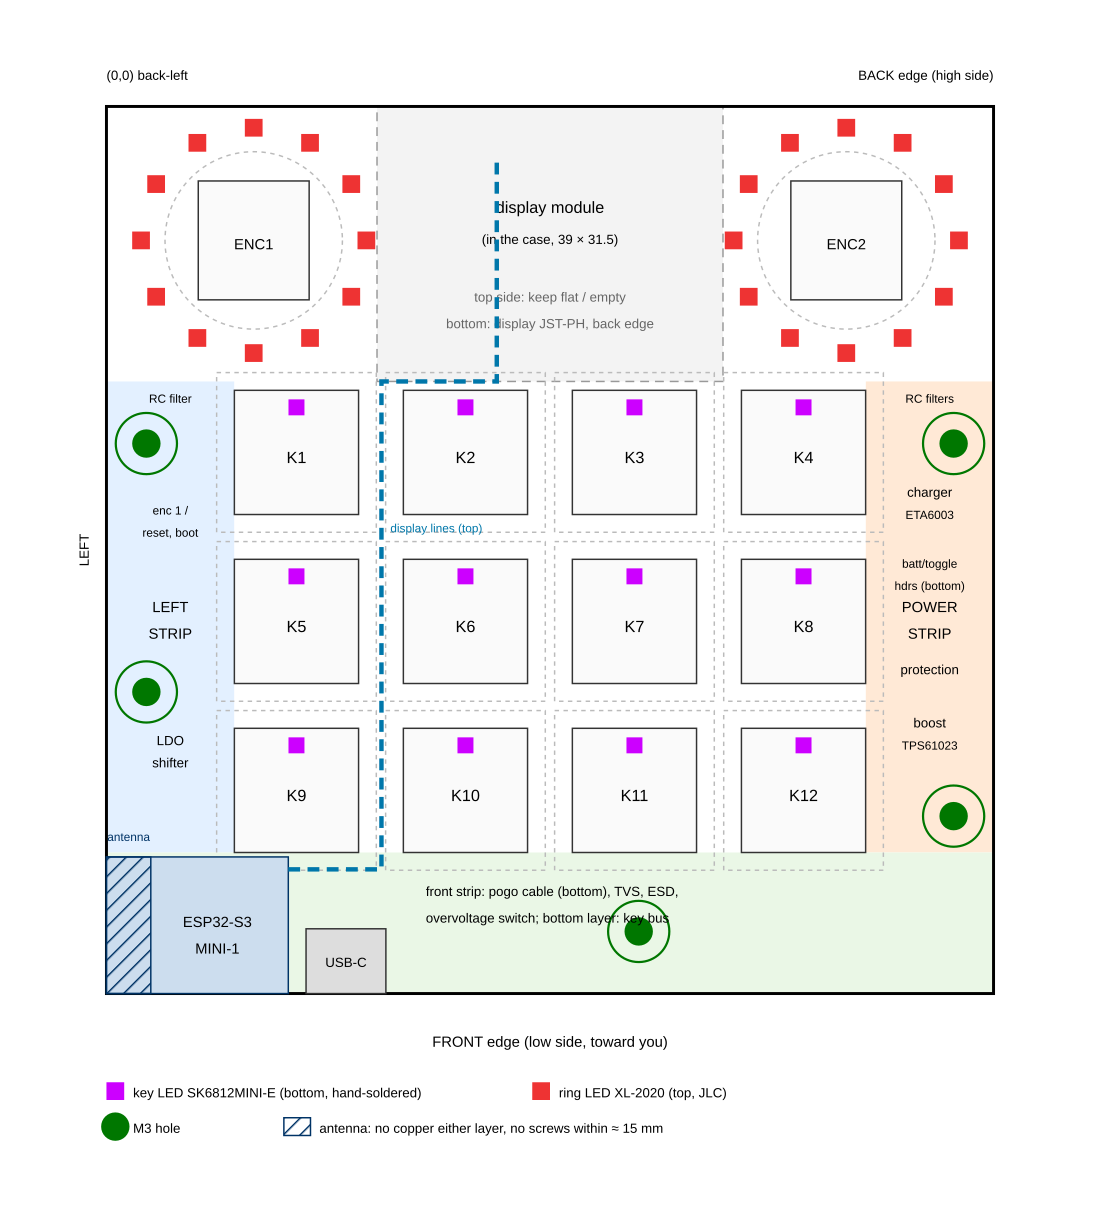
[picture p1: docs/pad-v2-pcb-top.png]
Pad v2 top view


## Contents

1. [What changed from v1](#1-what-changed-from-v1)
2. [Coordinates, outline, holes](#2-coordinates-outline-holes)
3. [Keys, sockets and key LEDs](#3-keys-sockets-and-key-leds)
4. [Encoders and ring LEDs](#4-encoders-and-ring-leds)
5. [ESP32-S3-MINI-1 and the antenna](#5-esp32-s3-mini-1-and-the-antenna)
6. [Zones for everything else](#6-zones-for-everything-else)
7. [Connectors](#7-connectors)
8. [Sides, heights and who solders what](#8-sides-heights-and-who-solders-what)
9. [Case, battery and docking](#9-case-battery-and-docking)
10. [Pogo board (pad floor and dock lid)](#10-pogo-board-pad-floor-and-dock-lid)
11. [Net classes](#11-net-classes)
12. [Open points](#12-open-points)
13. [Routing plan (GPIO map)](#13-routing-plan-gpio-map)

## 1. What changed from v1

| | v1 | v2 |
|---|---|---|
| Board | 100 × 92 mm | **100 × 100 mm** (the extra 8 mm at the front hold the ESP32 module) |
| MCU | socketed Pico 2 WH under the key field, bottom side | **ESP32-S3-MINI-1 at the front-left corner, top side** (JLC) |
| Encoders, rings, display | shafts at y = 16.6 | **1.5 mm further back (y = 15.1)**, so the key rows move back with them and the front strip is 15.9 mm deep |
| Key rows | y = 40.50 / 59.55 / 78.60 | **y = 39.00 / 58.05 / 77.10** (columns unchanged) |
| Ring LEDs | SK6812MINI-E, bottom side, through holes | **XL-2020RGBC-WS2812B, top side** (JLC) |
| Power parts, expander | bottom side, hand-soldered | **top side, JLC**; no expander (direct GPIOs) |
| Bottom side | almost everything | **only hand-soldered parts:** hot-swap sockets, key LEDs, THT encoder/connector pins |
| Pogo | board in the back wall, 4-wire cable | **board in the floor** (pad sits on top of the dock), 7-wire cable |

The JLC parts all sit on the top side, so the order stays single-sided assembly (no second-side setup fee).

## 2. Coordinates, outline, holes

Coordinates are **mm from the board's back-left corner**, seen from the top (key side): x to the right, y towards the front. KiCad setup as in v1: draw the outline, **Place → Grid Origin** at its top-left corner, and set **Display origin: Grid origin, Y axis: increases down**.

- **Outline:** 100 × 100 mm, already drawn in `pad-v2.kicad_pcb` from page position (100, 50) to (200, 150), with the grid origin at (100, 50). With **Display origin: Grid origin** the board reads (0, 0) to (100, 100). GND pours on both layers are in place. Fits JLC's 100 × 100 tier.
- **Mounting holes:** M3, `MountingHole:MountingHole_3.2mm_M3`, with schematic symbols this time (so the parity check stays clean).

| Hole | X | Y | Note |
|---|---|---|---|
| H1 | 4.50 | 38.00 | left strip, top |
| H2 | 95.50 | 38.00 | right strip, top |
| H3 | 4.50 | 66.00 | ≥ 15 mm from the antenna |
| H4 | 95.50 | 80.00 | right strip, bottom |
| H5 | 60.00 | 93.00 | front strip, ≈ 40 mm from the antenna |

## 3. Keys, sockets and key LEDs

- 4 × 3 grid, **19.05 mm pitch**. Columns x = **21.42, 40.47, 59.52, 78.58**; rows y = **39.00, 58.05, 77.10**.
- Switch footprint: MX with Kailh hot-swap socket and the two plastic-peg holes, so **3-pin and 5-pin switches** both fit (your pick, open). Origin = switch centre, **orientation 180°**: LED window towards the back, socket towards the front (as v1).
- **Key LED** (SK6812MINI-E, reverse mount) **5.08 mm behind the switch centre**, **bottom side**, shining up through its cutout. Its 100 nF goes on the **top side** in the gap between key rows, with a via to the LED's VDD (JLC places it; no 0402 for you to hand-solder).

| Key | X | Y | LED Y (bottom) |
|---|---|---|---|
| 1–4 | 21.42 / 40.47 / 59.52 / 78.58 | 39.00 | 33.92 |
| 5–8 | same | 58.05 | 52.97 |
| 9–12 | same | 77.10 | 72.02 |

Before ordering: print the key area 1:1 and check a switch, a socket and the LED window direction.

## 4. Encoders and ring LEDs

- Encoder footprint `dock:RotaryEncoder_Bourns_PEC11R-4xxxF-S_Vertical`, top side, 0°. Origin is pin A; **footprint position = shaft − (7.5, 2.5)**.

| Encoder | Role | Shaft | Footprint position |
|---|---|---|---|
| ENC1 | volume (left) | (16.60, 15.10) | (9.10, 12.60) |
| ENC2 | mic/call (right) | (83.40, 15.10) | (75.90, 12.60) |

- **Ring LEDs:** 12 per encoder, **top side**, on a **12.7 mm radius** (just outside a 20 mm knob), one every 30°. Each LED's 100 nF sits just outside the ring. The light reaches the case top through 12 small holes or a light-pipe ring (case design).
- Clock positions: 12 = towards the back edge. Chain order: see below the table.

| Clock | Ring 1 X | Ring 1 Y | Ring 2 X | Ring 2 Y |
|---|---|---|---|---|
| 6 | 16.60 | 27.80 | 83.40 | 27.80 |
| 7 | 10.25 | 26.10 | 77.05 | 26.10 |
| 8 | 5.60 | 21.45 | 72.40 | 21.45 |
| 9 | 3.90 | 15.10 | 70.70 | 15.10 |
| 10 | 5.60 | 8.75 | 72.40 | 8.75 |
| 11 | 10.25 | 4.10 | 77.05 | 4.10 |
| 12 | 16.60 | 2.40 | 83.40 | 2.40 |
| 1 | 22.95 | 4.10 | 89.75 | 4.10 |
| 2 | 27.60 | 8.75 | 94.40 | 8.75 |
| 3 | 29.30 | 15.10 | 96.10 | 15.10 |
| 4 | 27.60 | 21.45 | 94.40 | 21.45 |
| 5 | 22.95 | 26.10 | 89.75 | 26.10 |

**LED chain (changed 2026-10-05, firmware index = reference − 401):** 0–3 keys 9, 10, 11, 12; 4–7 keys 8, 7, 6, 5; 8–11 keys 1, 2, 3, 4; 12–23 ring 2 counter-clockwise from 7 o'clock (7, 6, 5 … 9, 8); 24–35 ring 1 counter-clockwise from 4 o'clock (4, 3, 2 … 6, 5). The chain starts at key 9, next to the ESP32, so the level shifter U402 and R404 sit at the bottom of the left strip and the data line is short. One long hop: ring 2's 8 o'clock LED to ring 1's 4 o'clock LED (≈ 45 mm, under the display).

## 5. ESP32-S3-MINI-1 and the antenna

- Module **15.4 × 20.5 mm, top side**, lying along the front edge at the **front-left corner**: x 0–20.5, y 84.6–100, **antenna end at the left board edge** (x = 0). Key 9's switch body ends at y 84.1, so 0.5 mm clearance.
- **Antenna keep-out:** no copper on either layer under and around the antenna end (the module's datasheet layout guide gives the exact zone), no screws, magnets or battery within ≈ 15 mm. The case wall at the front-left must be plastic.
- **Footprint:** `pad_v2:ESP32-S3-MINI-1` (`hardware/libraries/pad_v2.pretty`). Pads are KiCad's `ESP32-S2-MINI-1` land pattern (identical; KiCad's own S3 symbol points to it), with the body outline, courtyard and antenna keep-out redrawn for the 20.5 mm S3 module (datasheet v1.7, fig. 11-1). The keep-out covers only the antenna area, because the module sits inside the board with the antenna at the edge. **Position (9.50, 92.30), rotation 90°** puts the body at x 0–20.5, y 84.6–100 with the antenna at the left edge.
- **BLE path:** the dock's ESP32-C3 sits a few centimetres below, so the link is short; the battery (steel can) is at the back, away from the antenna.
- Decoupling (10 µF + 100 nF) at the module's 3V3 pins; the 3.3 V LDO in the left strip just above it.

## 6. Zones for everything else

Zones are in the drawing. Exact positions are your call while routing; keep the groups.

| Zone | Where | Parts |
|---|---|---|
| **Left strip** | x 0–14.4, y 31–84 (top) | top: encoder 1 RC filter (upper end), RESET and BOOT buttons, **TLV75733P LDO** + caps and the **level shifter SN74AHCT1G125 + R404** (lower end, near the ESP and key 9) |
| **Power strip** | x 85.6–100, y 31–84 (top) | top, from the back: encoder 2 RC filter, **ETA6003 charger** (QFN-16) + 2.2 µH + input/SYS/BAT caps + ISET1/ISET2 resistors, **DW01A + FS8205A** (TSSOP-8) protection, **TPS61023 boost** + 1 µH (≥ 4.5 A) + caps + FB divider. Keep each switcher's loop tight (input cap, IC, inductor, output cap within a few mm), FB dividers away from the inductors. The 3 MHz charger and 1 MHz boost stay on this side, away from the antenna |
| **Front strip** | y 84.1–100, x 20.5–100 | **USB-C** at the front edge, centre x = 27 (right next to the module's USB pins) with its TPD4E1U06; **pogo input:** SMBJ15A TVS, TPD4E1U06, 1 k series resistors on TX/RX, **WS3222D overvoltage switch** (cuts off at 5.69 V) feeding the charger |
| **Back strip** | x 30.5–69.5, y 0–31 | under the display module: **top side flat or empty** (≤ 1.2 mm parts at most); bottom: display connector |
| **Key field** | between switches | only flat SMD parts in the 5 mm gaps between switch bodies: key-LED 100 nF caps, LED data vias |

## 7. Connectors

All hand-soldered THT, **bottom side**, side-entry (horizontal) unless noted, opening towards the nearest edge.

| Connector | Type | Where | Wires |
|---|---|---|---|
| Display | JST-PH 9-pin, `S9B-PH-K` side entry | back strip, back edge | BLK CS DC RES SDA SCL VCC GND + GND |
| Pogo cable | JST-XH 7-pin (same as the dock's J601) | front strip, bottom | 1:1 to the pad's pogo board in the floor |
| Battery | JST-XH 2-pin | power strip, right edge | B+, B− (to FS8205A); from the 21700 holder's leads |
| Toggle | JST-XH 3-pin | power strip, right edge | PERSONAL, COM (GND), WORK |
| USB-C | TYPE-C-31-M-12 (as the dock), **top side, JLC** | **front edge, centre x = 27** | flashing / debug only (VBUS not used). Moved from the left edge: the ESP32's USB pins face this way, and it is ≥ 20 mm from the antenna |
| NTC | JST-XH 2-pin | power strip, next to the battery header | 10 k B3950 thermistor taped to the cell (or a 10 k resistor if you skip it) |

## 8. Sides, heights and who solders what

- **Top side (JLC):** ESP32-S3 module, all power parts, ring LEDs, all 0402/0603 passives, USB-C, buttons. Inside the key field the plate is ≈ 3.5 mm above the board: only flat SMD between switches. Under the display: flat or empty.
- **Bottom side (you, soldering iron):** 12 Kailh hot-swap sockets, 12 SK6812MINI-E (≈ 300–330 °C, 2–3 s per leg, keep sealed until use), the connectors above.
- **Through-hole (you):** 2 PEC11R encoders (top), THT connector pins.

## 9. Case, battery and docking

- Wedge as in v1: **front ≈ 25 mm, back ≈ 44 mm**, slope ≈ 9–10°. The main board sits under the case top at the slope; encoder shafts and keys come through it; the display module is mounted to the case behind its window, cabled to the back strip.
- **Battery:** one 21700 in a holder fixed to the case floor at the back, lying left-right under the back strip (its two leads and the NTC pair run to the power strip). With one cell the back could become a little lower than 44 mm; that's settled in the 3D model.
- **Floor:** flat, sits on the dock lid. The pad's pogo board is in the floor (§10); its position must match the dock lid board in the 3D design, with the magnets of the pogo set holding the pad.
- **Toggle:** panel-mounted on the right side of the case, wired to the 3-pin header.
- **USB-C:** opening in the front case wall, left of centre.

## 10. Pogo board (pad floor and dock lid)

One small board design, used twice:

- **Parts:** the straight Motorobit 7-pin 2.54 mm magnetic pogo set half (spring pins on the pad's board, flat contacts on the dock's), a **JST-XH 7-pin** header, two M2/M2.5 mounting holes. No other parts: the ESD, TVS and series resistors stay on the main boards (dock: U601 at J601; pad: front strip).
- **Pin mapping:** contact n ↔ header pin n, cable 1:1 on both sides. Two identical boards facing each other meet contact 1 to contact 7, which gives the mirrored order:

| Contact / pin | Dock lid board (dock names) | Pad floor board (pad names) |
|---|---|---|
| 1 | GND | GND |
| 2 | +5V | +5V |
| 3 | DET | PAD_RX (from dock TX) |
| 4 | RX | PAD_TX (to dock RX) |
| 5 | TX | DET → tied to GND on the pad main board |
| 6 | +5V | +5V |
| 7 | GND | GND |

- Size ≈ 30 × 12 mm (set by the pogo part and the header); exact footprint once the straight set is in hand. Mark contact 1 on both silkscreens and on the case.

## 11. Net classes

| Class | Nets | Width |
|---|---|---|
| Battery | B+, B−, FS8205 path | ≥ 1.0 mm |
| Power | POGO_5V (pad input), VSYS, 5V_RGB, 3V3 | ≥ 0.6 mm (single-LED branches 0.3 mm) |
| Switch nodes | ETA6003 SW, TPS61023 SW | short and wide (≥ 1 mm), small copper area |
| USB | D+ / D− | 0.3 mm pair, short |
| Default | everything else | 0.2–0.25 mm |

GND: pour on both layers, stitched; keep it out of the antenna keep-out and the key-LED cutouts.

## 12. Open points

- Pogo footprint for the straight set (check against the part), Kailh socket + 5-pin MX footprint (v1's `dock:SW_MX_Hotswap_Kailh` plus peg holes).
- Back height of the case with one cell.

## 13. Routing plan (GPIO map)

The full pin map is in [PAD_WIRING.md](PAD_WIRING.md) §2. It was chosen so each signal leaves the module on the side facing its destination. The module's four pad rows, as placed (rotation 90°):

| Row | Module pins | Where it is | Signals | How they leave |
|---|---|---|---|---|
| **Front** | 1–15 (GND, 3V3, IO0–IO11) | y = 99.3, only 0.3 mm from the board edge | BOOT, keys 2, 6, 10, 3, 7, 11, 4, 8, 12, VBAT_SENSE, VIN_SENSE | no room outward: a via **under the module** next to each pad, then the **bottom layer** eastwards. The hot-swap sockets are on the bottom anyway, so the keys need no second via |
| **Right** | 16–30 | x = 19.05, faces the front strip | south part (IO12–IO18): toggle, charger status/enable, encoder 2. Middle: USB D−/D+ to the connector 4 mm away. North part: CHG_ISEL, RGB_EN, then four display lines | south part is boxed in by the USB pair and connector: vias, bottom layer, eastwards. North part: top layer |
| **Back** | 31–45 | y = 85.3, faces key 9 and the left strip | east end (IO35–37): three display lines. Then keys 9, 5, 1 (column 1, straight up the gap at x ≈ 13). West end: encoder 1, RGB data, EN | top layer; TXD0/RXD0 (pogo UART) drop to the bottom and run east under the module |
| Antenna side | 46–60 | all GND | | |

Bundles, in the order that avoids crossings:

- **Key bus (bottom layer):** leaves under the module's right row at y ≈ 86–91 (north of the USB pads), runs east along the front strip. Order north → south = IO1 … IO9 = keys 2, 6, 10, 3, 7, 11, 4, 8, 12. It peels off northwards: keys 2 and 6 up the gap between columns 1 and 2 (x ≈ 31.5), key 10 straight to its socket, keys 3 and 7 up the next gap (x ≈ 50.6), key 11, keys 4 and 8 (x ≈ 69.6), key 12. Each key's **signal pad is its west socket pad** (x = column − 5.84), the east pad is GND.
- **Right-strip bus (bottom layer, south of the key bus):** VBAT_SENSE, VIN_SENSE, then IO18 … IO12 = ENC2_A, ENC2_B, ENC2_SW, CHG_EN_N, CHG_STAT, TGL_PERSONAL, TGL_WORK. At the right strip it turns north: the encoder lines stay on the inside and continue to the top, the charger and toggle lines peel off to the east.
- **Display bundle (top layer):** seven lines gather at the module's north-east corner, run east along y ≈ 85, then north through the gap between key columns 1 and 2 (top layer is free there between the peg holes, x 27.4–34.5), to J501 at the back. Lanes west → east: BLK, CS, DC, RES, SDA, SCL, DISP_EN_N = J501 pins 1–6 and Q501. Place J501 with pin 1 on the left; if the footprint ends up mirrored, tell me and I mirror the six assignments (they are free to swap).
- **Left strip (top layer):** ENC1_A, ENC1_B, ENC1_SW up to the encoder; RGB_DATA to U402 at the bottom of the strip; EN to the RESET button.
- **3V3 to the module (pin 3, at the front edge):** via behind the module → bottom layer under it → via next to pin 3. C201/C202 sit just behind the module (the module has its own decoupling inside).
- **Top layer under the switches is free** except for each switch's five holes; the bottom layer there holds the sockets and LEDs.

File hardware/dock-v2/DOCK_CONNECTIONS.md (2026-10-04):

# Dock v2 — Connection & Placement Guide

Use this to understand the v2 dock circuit, sheet by sheet (sketches, reasons, placement). **To wire the schematic, use the component-by-component list [DOCK_WIRING.md](DOCK_WIRING.md)**: every part, every pin, what it connects to and which label to draw.
All parts are already on their sheets (`hardware/dock-v2/`, placed, not wired) with the references used here.
Why each part was chosen is in `docs/dock-v2-*.md`; where it goes on the board is in [PCB_PLACEMENT.md](PCB_PLACEMENT.md).

The tables are generated from one connection model and checked against the placed schematic: 158 parts, 490 connected pins on 90 nets, 79 no-connect pins. Every pin of every part is listed once, either on a net or as a no-connect.

How to read the tables:

- **Parts**: what is on the sheet (value, footprint and LCSC number are already filled in).
- **Wiring**: each row is one pin and the net it belongs to. Everything with the same net name is wired together.
  Nets in **bold** leave the sheet: use a **global label** with exactly that name. The rest are **local labels** (or plain wires) inside the sheet.
- **Placement**: what has to sit next to what on the PCB, and why.

Net names used everywhere:

| Net | What it is |
|---|---|
| **GND** | Board ground (also the two PCs' and the charger's ground) |
| **VBUS_IN** | Charger input after J101: 9 V with a PD charger, 5 V without |
| **+5V** | Buck output, 5.16 V (≈ 4.7 V pass-through on a 5 V-only charger) |
| **+3V3** | AMS1117 output: both RP2354A, the ESP32-C3, all pull-ups |
| **KBD_VBUS** | Keyboard 5 V after the SY6280 switch (off until a keyboard is detected) |
| **POGO_5V** | Pad 5 V after the pogo SY6280 switch (on while the pad is docked); two contacts, limit ≈ 1.45 A |
| A_1V1, B_1V1 | Each RP2354A's own 1.1 V core rail. **Local labels, never a `+1V1` power symbol**: a power symbol is global and would join A's and B's regulators |
| PC1_VBUS, PC2_VBUS | The PCs' VBUS: **sense only**, never joined to a dock rail |

## Contents

1. [Power input and PD (J101, CH224A)](#1-power-input-and-pd-j101-ch224a)
2. [5 V buck and 3.3 V LDO](#2-5-v-buck-and-33-v-ldo)
3. [Keyboard port (J201, USB-C source)](#3-keyboard-port-j201-usb-c-source)
4. [PC ports (J202 Personal, J203 Work)](#4-pc-ports-j202-personal-j203-work)
5. [MCU A (RP2354A)](#5-mcu-a-rp2354a)
6. [MCU B (RP2354A)](#6-mcu-b-rp2354a)
7. [BLE (ESP32-C3-MINI-1)](#7-ble-esp32-c3-mini-1)
8. [Pogo interface](#8-pogo-interface)
9. [Signals that cross between sheets](#9-signals-that-cross-between-sheets)
10. [Board-wide rules, PWR_FLAGs and no-connects](#10-board-wide-rules-pwr_flags-and-no-connects)
11. [Appendix: full net index](#appendix--full-net-index-generated)

## The whole dock at a glance

```text
 charger ═ J101 ─ VBUS_IN ─┬─ CH224A (asks 9 V) ── I2C, PG ──────────────────────────┐
                           └─ TPS54331 ── +5V ─┬─ AMS1117 ── +3V3 ──► A, B, ESP32      │
                                               ├─ SY6280 ── KBD_VBUS ──► J201 keyboard │
                                               └─ SY6280 ── POGO_5V ───► J601 pogo     │
                                                                                       ▼
 keyboard ═ J201 ── PIO-USB (GPIO2/3) ──►┌────────────┐── UART1 ──►┌────────────┐
                    CC1/CC2 → ADC        │ RP2354A  A │◄─ RUN, BOOTSEL, SWD ─│ RP2354A  B │══ J203 ═ Work PC
 Personal PC ═ J202 ══ native USB ═══════│  (U301)    │            │  (U401)    │
                                         └─────┬──────┘            └────────────┘
                              UART0, EN, BOOT  │  PIO UART, DET, OFF, ADC
                                  ESP32-C3 ◄───┴───► pogo J601 ═ pad
```

Each sketch below is only a reading aid: `●` is a junction, `─` a wire, `→`/`←` show which way a signal goes. The tables under each sketch are the exact reference.

---

## 1. Power input and PD (J101, CH224A)

Sheet `power.kicad_sch`.

```text
 J101 VBUS (A4, A9, B4, B9) ──●── VBUS_IN ──► buck VIN (section 2)
                              ├── D101 SMBJ15A cathode (pin 1); anode (pin 2) ── GND
                              ├── C101 1 µF 50 V ── GND
                              └── U102 pin 1 VHV and pin 8 VBUS (tied together, datasheet)
 J101 CC1 (A5) ──●── PD_CC1 ── U102 pin 7        J101 D+ (A6, B6) ──●── PD_DP ── U102 pin 4
                 └── U101 pin 3 (ESD)                               └── U101 pin 1
 J101 CC2 (B5) ──●── PD_CC2 ── U102 pin 6        J101 D− (A7, B7) ──●── PD_DM ── U102 pin 5
                 └── U101 pin 4                                     └── U101 pin 6
 U102 pin 9 CFG1 ── PD_CFG1 ── R101 6.8 k ── GND            (requests 9 V on its own)
 U102 pin 2 CFG2/SCL ──●── PD_SCL ──► MCU A GPIO19      (R103 4.7 k to +3V3)
 U102 pin 3 CFG3/SDA ──●── PD_SDA ◄─► MCU A GPIO18      (R104 4.7 k to +3V3)
 U102 pin 10 PG ───────●── PD_PG ───► MCU A GPIO17      (R102 10 k to +3V3)
 U102 pin 11 (exposed pad) ── GND;  J101 A1, A12, B1, B12, SH ── GND;  SBU A8/B8: no-connect
```

**Parts**

| Ref | Value | Footprint | LCSC | Job |
|---|---|---|---|---|
| J101 | TYPE-C-31-M-12 | `USB_C_Receptacle_HRO_TYPE-C-31-M-12` | C165948 | Power input: charger, 9 V PD |
| U101 | TPD4E1U06DBVR | `SOT-23-6` | C124691 | ESD on CC1, CC2, D+, D-, <=5 mm from J101 |
| D101 | SMBJ15A | `D_SMB` | C113988 | VBUS_IN TVS, at J101 VBUS |
| U102 | CH224A | `SSOP-10-1EP_3.9x4.9mm_P1mm_EP2.1x3.3mm` | C42459160 | VBUS (8) tied to VHV (1) |
| C101 | 1uF | `C_0603_1608Metric` | C15849 | VHV to GND |
| R101 | 6.8k | `R_0402_1005Metric` | C25917 | CFG1 to GND: requests 9 V |
| R102 | 10k | `R_0402_1005Metric` | C25744 | PG pull-up to 3V3 |
| R103 | 4.7k | `R_0402_1005Metric` | C25900 | SCL pull-up to 3V3 |
| R104 | 4.7k | `R_0402_1005Metric` | C25900 | SDA pull-up to 3V3 |

**Wiring — J101 (USB-C, power input)**

| J101 pin | Name | Net | Also on this net |
|---|---|---|---|
| A1 | GND | **GND** | 138 other pins |
| A4 | VBUS | **VBUS_IN** | D101.1, U102.1, U102.8, C101.1, U103.2, C102.1, C103.1 |
| A5 | CC1 | **PD_CC1** | U101.3, U102.7 |
| A6 | D+ | **PD_DP** | U101.1, U102.4 |
| A7 | D- | **PD_DM** | U101.6, U102.5 |
| A8 | SBU1 | no-connect flag | |
| A9 | VBUS | **VBUS_IN** | D101.1, U102.1, U102.8, C101.1, U103.2, C102.1, C103.1 |
| A12 | GND | **GND** | 138 other pins |
| B1 | GND | **GND** | 138 other pins |
| B4 | VBUS | **VBUS_IN** | D101.1, U102.1, U102.8, C101.1, U103.2, C102.1, C103.1 |
| B5 | CC2 | **PD_CC2** | U101.4, U102.6 |
| B6 | D+ | **PD_DP** | U101.1, U102.4 |
| B7 | D- | **PD_DM** | U101.6, U102.5 |
| B8 | SBU2 | no-connect flag | |
| B9 | VBUS | **VBUS_IN** | D101.1, U102.1, U102.8, C101.1, U103.2, C102.1, C103.1 |
| B12 | GND | **GND** | 138 other pins |
| SH | SHIELD | **GND** | 138 other pins |

**Wiring — U101 (ESD) and U102 (CH224A)**

| U101 pin | Name | Net | Also on this net |
|---|---|---|---|
| 1 | D1+ | **PD_DP** | J101.A6, J101.B6, U102.4 |
| 2 | GND | **GND** | 142 other pins |
| 3 | D2+ | **PD_CC1** | J101.A5, U102.7 |
| 4 | D2- | **PD_CC2** | J101.B5, U102.6 |
| 5 | NC | no-connect flag | |
| 6 | D1- | **PD_DM** | J101.A7, J101.B7, U102.5 |

| U102 pin | Name | Net | Also on this net |
|---|---|---|---|
| 1 | VHV | **VBUS_IN** | J101.A4, J101.A9, J101.B4, J101.B9, D101.1, C101.1, U103.2, C102.1 … |
| 2 | CFG2/SCL | **PD_SCL** | R103.2, U301.31 |
| 3 | CFG3/SDA | **PD_SDA** | R104.2, U301.29 |
| 4 | DP | **PD_DP** | J101.A6, J101.B6, U101.1 |
| 5 | DM | **PD_DM** | J101.A7, J101.B7, U101.6 |
| 6 | CC2 | **PD_CC2** | J101.B5, U101.4 |
| 7 | CC1 | **PD_CC1** | J101.A5, U101.3 |
| 8 | VBUS | **VBUS_IN** | J101.A4, J101.A9, J101.B4, J101.B9, D101.1, C101.1, U103.2, C102.1 … |
| 9 | CFG1 | PD_CFG1 | R101.1 |
| 10 | PG | **PD_PG** | R102.2, U301.28 |
| 11 | GND | **GND** | 142 other pins |

| Part | Pin 1 | Pin 2 |
|---|---|---|
| D101 (1 = cathode band) | **VBUS_IN** | **GND** |
| C101 | **VBUS_IN** | **GND** |
| R101 | PD_CFG1 | **GND** |
| R102 | **+3V3** | **PD_PG** |
| R103 | **+3V3** | **PD_SCL** |
| R104 | **+3V3** | **PD_SDA** |

Notes:
- D101 uses KiCad's `D_TVS` symbol, drawn bidirectional (pins A1/A2). The SMBJ15A is **unidirectional**: pin 1 (A1) is the footprint's **cathode-band** pad, so pin 1 goes to VBUS_IN.
- Not verified: the level of the CH224A's internal CFG2/CFG3 pull-ups. Measure SCL/SDA idle voltage on the first board before connecting the I2C lines to MCU A (both are rated 6.5 V; the RP2354A pins are 3.3 V).

**Placement**

- J101 on the right edge. U101 within 5 mm of J101, signals pass its pads first. D101 right at J101's VBUS pads.
- U102 next to J101: short CC and D± runs. C101 at U102 pin 1. R101 at pin 9.
- VBUS_IN is a Power-class net (0.6 mm).

---

## 2. 5 V buck and 3.3 V LDO

Sheet `power.kicad_sch`. Values from TI's TPS54331 Table 7-1 (5 V design), on JLCPCB Basic parts: see `docs/dock-v2-power-input.md` §4b.

```text
 VBUS_IN ──●── U103 pin 2 VIN                    U103 pin 8 PH ──●── BUCK_SW ──●── L101 6.8 µH ──●── +5V
           ├── C102 10 µF ── GND                                 │             └── D102 SS54 cathode; anode ── GND
           └── C103 10 µF ── GND                                 └── C104 100 nF ── U103 pin 1 BOOT
 U103 pin 3 EN: no-connect (internal pull-up; a UVLO divider would stop the 5 V pass-through)
 U103 pin 4 SS ── BUCK_SS ── C105 10 nF ── GND                       (≈ 4 ms soft start)
 U103 pin 6 COMP ──●── BUCK_COMP ── R105 51 k ── BUCK_COMP_RC ── C106 4.7 nF ── GND
                   └── C107 47 pF ── GND
 +5V ── R106 12 k ──●── BUCK_FB ── U103 pin 5 VSENSE            (0.8 V × (1 + 12/2.2) = 5.16 V)
                    └── R107 2.2 k ── GND
 +5V ──●── C108, C109, C110 22 µF ── GND
       └── U104 pin 3 VI (AMS1117)   U104 pin 2 VO ──●── +3V3     U104 pin 1 GND
           C111 10 µF at VI                          └── C112 10 µF ── GND
```

**Parts**

| Ref | Value | Footprint | LCSC | Job |
|---|---|---|---|---|
| U103 | TPS54331DR | `SOIC-8_3.9x4.9mm_P1.27mm` | C9865 | EN left open (5 V pass-through) |
| C102 | 10uF | `C_0805_2012Metric` | C15850 | VIN, at pins 2/7 |
| C103 | 10uF | `C_0805_2012Metric` | C15850 | VIN |
| C104 | 100nF | `C_0402_1005Metric` | C1525 | BOOT to PH |
| C105 | 10nF | `C_0402_1005Metric` | C15195 | SS: ~4 ms soft start |
| R105 | 51k | `R_0402_1005Metric` | C25794 | COMP series R |
| C106 | 4.7nF | `C_0402_1005Metric` | C1538 | COMP series C |
| C107 | 47pF | `C_0402_1005Metric` | C1567 | COMP to GND |
| R106 | 12k | `R_0402_1005Metric` | C25752 | FB top: 0.8*(1+12/2.2)=5.16 V |
| R107 | 2.2k | `R_0402_1005Metric` | C25879 | FB bottom |
| D102 | SS54 | `D_SMC` | C22452 | catch diode PH to GND |
| L101 | 6.8uH | `L_TechFuse_SL0630` | C207841 | SLO0630H6R8MTT: Isat 8 A (> 5.8 A max current limit), 45 mOhm, 7.1x6.6x3.0 |
| C108 | 22uF 25V | `C_1206_3216Metric` | C12891 | +5V output |
| C109 | 22uF 25V | `C_1206_3216Metric` | C12891 | +5V output |
| C110 | 22uF 25V | `C_1206_3216Metric` | C12891 | +5V output |
| U104 | AMS1117-3.3 | `SOT-223-3_TabPin2` | C6186 | +5V to +3V3, tab on copper |
| C111 | 10uF | `C_0805_2012Metric` | C15850 | LDO input |
| C112 | 10uF | `C_0805_2012Metric` | C15850 | LDO output |
| H101 | (not in the schematic) | `— (choose)` | — | not in the schematic |
| H102 | (not in the schematic) | `— (choose)` | — | not in the schematic |
| H103 | (not in the schematic) | `— (choose)` | — | not in the schematic |
| H104 | (not in the schematic) | `— (choose)` | — | not in the schematic |

**Wiring — U103 (TPS54331) and U104 (AMS1117)**

| U103 pin | Name | Net | Also on this net |
|---|---|---|---|
| 1 | BOOT | BUCK_BOOT | C104.1 |
| 2 | VIN | **VBUS_IN** | J101.A4, J101.A9, J101.B4, J101.B9, D101.1, U102.1, U102.8, C101.1 … |
| 3 | EN | no-connect flag | |
| 4 | SS | BUCK_SS | C105.1 |
| 5 | VSENSE | BUCK_FB | R106.2, R107.1 |
| 6 | COMP | BUCK_COMP | R105.1, C107.1 |
| 7 | GND | **GND** | 142 other pins |
| 8 | PH | BUCK_SW | C104.2, D102.1, L101.1 |

| U104 pin | Name | Net | Also on this net |
|---|---|---|---|
| 1 | GND | **GND** | 142 other pins |
| 2 | VO | **+3V3** | 57 other pins |
| 3 | VI | **+5V** | 10 other pins |

| Part | Pin 1 | Pin 2 |
|---|---|---|
| C102 | **VBUS_IN** | **GND** |
| C103 | **VBUS_IN** | **GND** |
| C104 | BUCK_BOOT | BUCK_SW |
| C105 | BUCK_SS | **GND** |
| R105 | BUCK_COMP | BUCK_COMP_RC |
| C106 | BUCK_COMP_RC | **GND** |
| C107 | BUCK_COMP | **GND** |
| R106 | **+5V** | BUCK_FB |
| R107 | BUCK_FB | **GND** |
| D102 (1 = K, 2 = A) | BUCK_SW | **GND** |
| L101 | BUCK_SW | **+5V** |
| C108 | **+5V** | **GND** |
| C109 | **+5V** | **GND** |
| C110 | **+5V** | **GND** |
| C111 | **+5V** | **GND** |
| C112 | **+3V3** | **GND** |

H101–H104 (M3 holes) have no pins.

**Placement**

- Front-right corner. The **hot loop**: C102/C103 → U103 VIN/GND → PH → D102 → GND. Keep it tiny, on the top layer, over the In1 ground plane.
- L101 next to the PH pin; C108–C110 between L101 and the +5V trunk. Copper pour around U103 GND and D102 for heat.
- R106/R107 at U103 pin 5, fed from the +5V side of C108–C110; keep BUCK_FB away from BUCK_SW, L101 and D102.
- C104 right at pins 1 and 8. C105, R105/C106/C107 right at pins 4 and 6.
- U104 in the centre of the board (it feeds A, B and the ESP32); tab on a copper area. C111/C112 at its pins.
- L101 = Sunltech **SLO0630H6R8MTT** (C207841): 6.8 µH, saturation 8 A (above the TPS54331's 5.8 A maximum current limit, so it can't saturate in an overload), 45 mΩ, 7.1 × 6.6 × 3.0 mm, footprint `Inductor_SMD:L_TechFuse_SL0630` (same body and pad gap as Sunltech's land pattern). Extended part: JLCPCB has no Basic power inductor.

---

## 3. Keyboard port (J201, USB-C source)

Sheet `usb_ports.kicad_sch`. The dock is the **source** here: Rp pull-ups on CC, 5 V only after the firmware sees a keyboard (docs/dock-v2-usb-ports.md §4).

```text
 +5V ──●── U202 pin 5 IN (SY6280)        U202 pin 1 OUT ──●── KBD_VBUS ──► J201 VBUS (A4, A9, B4, B9)
       └── C204 1 µF ── GND                               ├── C201 220 µF THT (+ = pin 1), hand-soldered
 U202 pin 4 EN ──●── KBD_VBUS_EN ◄── MCU A GPIO8          ├── C202 10 µF, C203 1 µF ── GND
                 └── R208 100 k ── GND  (off at reset)    └── R209 10 k ──●── KBD_VBUS_SENSE ──► MCU A GPIO27 (ADC1)
 U202 pin 3 ISET ── R207 6.8 k ── GND  (1.0 A)                             └── R210 15 k ── GND
 +3V3 ── R201 33 k ──●── KBD_CC1 ── J201 CC1 (A5) ──► MCU A GPIO29 (ADC3);  U201 pin 3
 +3V3 ── R202 33 k ──●── KBD_CC2 ── J201 CC2 (B5) ──► MCU A GPIO28 (ADC2);  U201 pin 4
 J201 D+ (A6, B6) ──●── KBD_USBJ_D_P ── R205 22 Ω ── KBD_USB_D_P ──► MCU A GPIO3 (PIO-USB D+)
                    ├── U201 pin 1;  R203 15 k ── GND
 J201 D− (A7, B7) ──●── KBD_USBJ_D_N ── R206 22 Ω ── KBD_USB_D_N ──► MCU A GPIO2 (PIO-USB D−)
                    ├── U201 pin 6;  R204 15 k ── GND
 J201 A1, A12, B1, B12, SH ── GND;  SBU A8/B8: no-connect
```

**Parts**

| Ref | Value | Footprint | LCSC | Job |
|---|---|---|---|---|
| J201 | TYPE-C-31-M-12 | `USB_C_Receptacle_HRO_TYPE-C-31-M-12` | C165948 | Keyboard |
| U201 | TPD4E1U06DBVR | `SOT-23-6` | C124691 | ESD D+, D-, CC1, CC2 |
| R201 | 33k | `R_0402_1005Metric` | C25779 | CC1 Rp to 3V3 (Default USB) |
| R202 | 33k | `R_0402_1005Metric` | C25779 | CC2 Rp to 3V3 |
| R203 | 15k | `R_0402_1005Metric` | C25756 | D+ host pull-down |
| R204 | 15k | `R_0402_1005Metric` | C25756 | D- host pull-down |
| R205 | 22 | `R_0402_1005Metric` | C25092 | D+ series, near MCU A |
| R206 | 22 | `R_0402_1005Metric` | C25092 | D- series, near MCU A |
| U202 | SY6280AAC | `SOT-23-5` | C55136 | KBD_VBUS switch, EN from MCU A |
| R207 | 6.8k | `R_0402_1005Metric` | C25917 | ISET: 1.0 A |
| R208 | 100k | `R_0402_1005Metric` | C25741 | EN pull-down (off at reset) |
| C201 | 220uF 16V | `CP_Radial_D6.3mm_P5.00mm` | — | HAND-SOLDER: Koshin PKRJ-016V221ME070-T/A5.0 (Ozdisan) |
| C202 | 10uF | `C_0805_2012Metric` | C15850 | KBD_VBUS at J201 |
| C203 | 1uF | `C_0402_1005Metric` | C52923 | KBD_VBUS at J201 |
| C204 | 1uF | `C_0402_1005Metric` | C52923 | U202 input |
| R209 | 10k | `R_0402_1005Metric` | C25744 | KBD_VBUS divider top -> ADC |
| R210 | 15k | `R_0402_1005Metric` | C25756 | KBD_VBUS divider bottom |

**Wiring**

| J201 pin | Name | Net | Also on this net |
|---|---|---|---|
| A1 | GND | **GND** | 138 other pins |
| A4 | VBUS | **KBD_VBUS** | U202.1, C201.1, C202.1, C203.1, R209.1 |
| A5 | CC1 | **KBD_CC1** | U201.3, R201.2, U301.43 |
| A6 | D+ | KBD_USBJ_D_P | U201.1, R203.1, R205.1 |
| A7 | D- | KBD_USBJ_D_N | U201.6, R204.1, R206.1 |
| A8 | SBU1 | no-connect flag | |
| A9 | VBUS | **KBD_VBUS** | U202.1, C201.1, C202.1, C203.1, R209.1 |
| A12 | GND | **GND** | 138 other pins |
| B1 | GND | **GND** | 138 other pins |
| B4 | VBUS | **KBD_VBUS** | U202.1, C201.1, C202.1, C203.1, R209.1 |
| B5 | CC2 | **KBD_CC2** | U201.4, R202.2, U301.42 |
| B6 | D+ | KBD_USBJ_D_P | U201.1, R203.1, R205.1 |
| B7 | D- | KBD_USBJ_D_N | U201.6, R204.1, R206.1 |
| B8 | SBU2 | no-connect flag | |
| B9 | VBUS | **KBD_VBUS** | U202.1, C201.1, C202.1, C203.1, R209.1 |
| B12 | GND | **GND** | 138 other pins |
| SH | SHIELD | **GND** | 138 other pins |

| U201 pin | Name | Net | Also on this net |
|---|---|---|---|
| 1 | D1+ | KBD_USBJ_D_P | J201.A6, J201.B6, R203.1, R205.1 |
| 2 | GND | **GND** | 142 other pins |
| 3 | D2+ | **KBD_CC1** | J201.A5, R201.2, U301.43 |
| 4 | D2- | **KBD_CC2** | J201.B5, R202.2, U301.42 |
| 5 | NC | no-connect flag | |
| 6 | D1- | KBD_USBJ_D_N | J201.A7, J201.B7, R204.1, R206.1 |

| U202 pin | Name | Net | Also on this net |
|---|---|---|---|
| 1 | OUT | **KBD_VBUS** | J201.A4, J201.A9, J201.B4, J201.B9, C201.1, C202.1, C203.1, R209.1 |
| 2 | GND | **GND** | 142 other pins |
| 3 | ISET | KBD_ISET | R207.1 |
| 4 | EN | **KBD_VBUS_EN** | R208.1, U301.12 |
| 5 | IN | **+5V** | 10 other pins |

| Part | Pin 1 | Pin 2 |
|---|---|---|
| R201 | **+3V3** | **KBD_CC1** |
| R202 | **+3V3** | **KBD_CC2** |
| R203 | KBD_USBJ_D_P | **GND** |
| R204 | KBD_USBJ_D_N | **GND** |
| R205 | KBD_USBJ_D_P | **KBD_USB_D_P** |
| R206 | KBD_USBJ_D_N | **KBD_USB_D_N** |
| R207 | KBD_ISET | **GND** |
| R208 | **KBD_VBUS_EN** | **GND** |
| C201 (1 = +) | **KBD_VBUS** | **GND** |
| C202 | **KBD_VBUS** | **GND** |
| C203 | **KBD_VBUS** | **GND** |
| C204 | **+5V** | **GND** |
| R209 | **KBD_VBUS** | **KBD_VBUS_SENSE** |
| R210 | **KBD_VBUS_SENSE** | **GND** |

**Placement**

- J201 on the left edge. U201 within 5 mm. R201/R202 near J201.
- U202 between the +5V trunk and J201; R207 short to U202 pin 3. C201 (Ø 6.3 mm, THT) and C202/C203 at J201's VBUS pads.
- R205/R206 **near MCU A** (series termination at the driver); R203/R204 anywhere on the pair, near J201 is fine.
- KBD_USB pair as a 90 Ω differential pair; GPIO2/GPIO3 are on MCU A's left side, facing J201.
- KBD_VBUS is Power class.

---

## 4. PC ports (J202 Personal, J203 Work)

Sheet `usb_ports.kicad_sch`. The dock is a **sink** (Rd) but draws no power: VBUS is only sensed.

```text
 J202 (Personal PC, back edge)                               J203 (Work PC) is the same with R217–R222, U204,
 J202 VBUS ── PC1_VBUS ── R213 22 k ──●── PC1_VBUS_DET ──► MCU A GPIO1     PC2_* nets, MCU B GPIO29 and B's USB pins
                                      └── R214 33 k ── GND
 J202 CC1 (A5) ──●── PC1_CC1 ── R211 5.1 k ── GND;  U203 pin 3
 J202 CC2 (B5) ──●── PC1_CC2 ── R212 5.1 k ── GND;  U203 pin 4
 J202 D+ (A6, B6) ──●── PC1_USBJ_D_P ── R215 22 Ω ── PC1_USB_D_P ──► MCU A pin 52 USB_DP
                    └── U203 pin 1
 J202 D− (A7, B7) ──●── PC1_USBJ_D_N ── R216 22 Ω ── PC1_USB_D_N ──► MCU A pin 51 USB_DM
                    └── U203 pin 6
 J202 A1, A12, B1, B12, SH ── GND;  SBU A8/B8: no-connect
```

**Parts**

| Ref | Value | Footprint | LCSC | Job |
|---|---|---|---|---|
| J202 | TYPE-C-31-M-12 | `USB_C_Receptacle_HRO_TYPE-C-31-M-12` | C165948 | Personal PC |
| U203 | TPD4E1U06DBVR | `SOT-23-6` | C124691 | ESD D+, D-, CC1, CC2 |
| R211 | 5.1k | `R_0402_1005Metric` | C25905 | CC1 Rd |
| R212 | 5.1k | `R_0402_1005Metric` | C25905 | CC2 Rd |
| R213 | 22k | `R_0402_1005Metric` | C25768 | VBUS sense top |
| R214 | 33k | `R_0402_1005Metric` | C25779 | VBUS sense bottom |
| R215 | 22 | `R_0402_1005Metric` | C25092 | D+ series, near MCU A |
| R216 | 22 | `R_0402_1005Metric` | C25092 | D- series, near MCU A |
| J203 | TYPE-C-31-M-12 | `USB_C_Receptacle_HRO_TYPE-C-31-M-12` | C165948 | Work PC |
| U204 | TPD4E1U06DBVR | `SOT-23-6` | C124691 | ESD D+, D-, CC1, CC2 |
| R217 | 5.1k | `R_0402_1005Metric` | C25905 | CC1 Rd |
| R218 | 5.1k | `R_0402_1005Metric` | C25905 | CC2 Rd |
| R219 | 22k | `R_0402_1005Metric` | C25768 | VBUS sense top |
| R220 | 33k | `R_0402_1005Metric` | C25779 | VBUS sense bottom |
| R221 | 22 | `R_0402_1005Metric` | C25092 | D+ series, near MCU B |
| R222 | 22 | `R_0402_1005Metric` | C25092 | D- series, near MCU B |

**Wiring — J202 / U203 (Personal)**

| J202 pin | Name | Net | Also on this net |
|---|---|---|---|
| A1 | GND | **GND** | 138 other pins |
| A4 | VBUS | **PC1_VBUS** | R213.1 |
| A5 | CC1 | **PC1_CC1** | U203.3, R211.1 |
| A6 | D+ | PC1_USBJ_D_P | U203.1, R215.1 |
| A7 | D- | PC1_USBJ_D_N | U203.6, R216.1 |
| A8 | SBU1 | no-connect flag | |
| A9 | VBUS | **PC1_VBUS** | R213.1 |
| A12 | GND | **GND** | 138 other pins |
| B1 | GND | **GND** | 138 other pins |
| B4 | VBUS | **PC1_VBUS** | R213.1 |
| B5 | CC2 | **PC1_CC2** | U203.4, R212.1 |
| B6 | D+ | PC1_USBJ_D_P | U203.1, R215.1 |
| B7 | D- | PC1_USBJ_D_N | U203.6, R216.1 |
| B8 | SBU2 | no-connect flag | |
| B9 | VBUS | **PC1_VBUS** | R213.1 |
| B12 | GND | **GND** | 138 other pins |
| SH | SHIELD | **GND** | 138 other pins |

| U203 pin | Name | Net | Also on this net |
|---|---|---|---|
| 1 | D1+ | PC1_USBJ_D_P | J202.A6, J202.B6, R215.1 |
| 2 | GND | **GND** | 142 other pins |
| 3 | D2+ | **PC1_CC1** | J202.A5, R211.1 |
| 4 | D2- | **PC1_CC2** | J202.B5, R212.1 |
| 5 | NC | no-connect flag | |
| 6 | D1- | PC1_USBJ_D_N | J202.A7, J202.B7, R216.1 |

| Part | Pin 1 | Pin 2 |
|---|---|---|
| R211 | **PC1_CC1** | **GND** |
| R212 | **PC1_CC2** | **GND** |
| R213 | **PC1_VBUS** | **PC1_VBUS_DET** |
| R214 | **PC1_VBUS_DET** | **GND** |
| R215 | PC1_USBJ_D_P | **PC1_USB_D_P** |
| R216 | PC1_USBJ_D_N | **PC1_USB_D_N** |

**Wiring — J203 / U204 (Work)**

| J203 pin | Name | Net | Also on this net |
|---|---|---|---|
| A1 | GND | **GND** | 138 other pins |
| A4 | VBUS | **PC2_VBUS** | R219.1 |
| A5 | CC1 | **PC2_CC1** | U204.3, R217.1 |
| A6 | D+ | PC2_USBJ_D_P | U204.1, R221.1 |
| A7 | D- | PC2_USBJ_D_N | U204.6, R222.1 |
| A8 | SBU1 | no-connect flag | |
| A9 | VBUS | **PC2_VBUS** | R219.1 |
| A12 | GND | **GND** | 138 other pins |
| B1 | GND | **GND** | 138 other pins |
| B4 | VBUS | **PC2_VBUS** | R219.1 |
| B5 | CC2 | **PC2_CC2** | U204.4, R218.1 |
| B6 | D+ | PC2_USBJ_D_P | U204.1, R221.1 |
| B7 | D- | PC2_USBJ_D_N | U204.6, R222.1 |
| B8 | SBU2 | no-connect flag | |
| B9 | VBUS | **PC2_VBUS** | R219.1 |
| B12 | GND | **GND** | 138 other pins |
| SH | SHIELD | **GND** | 138 other pins |

| U204 pin | Name | Net | Also on this net |
|---|---|---|---|
| 1 | D1+ | PC2_USBJ_D_P | J203.A6, J203.B6, R221.1 |
| 2 | GND | **GND** | 142 other pins |
| 3 | D2+ | **PC2_CC1** | J203.A5, R217.1 |
| 4 | D2- | **PC2_CC2** | J203.B5, R218.1 |
| 5 | NC | no-connect flag | |
| 6 | D1- | PC2_USBJ_D_N | J203.A7, J203.B7, R222.1 |

| Part | Pin 1 | Pin 2 |
|---|---|---|
| R217 | **PC2_CC1** | **GND** |
| R218 | **PC2_CC2** | **GND** |
| R219 | **PC2_VBUS** | **PC2_VBUS_DET** |
| R220 | **PC2_VBUS_DET** | **GND** |
| R221 | PC2_USBJ_D_P | **PC2_USB_D_P** |
| R222 | PC2_USBJ_D_N | **PC2_USB_D_N** |

**Placement**

- J202 back edge, left (towards MCU A); J203 back edge, right (towards MCU B). ESD within 5 mm of each.
- R215/R216 near MCU A's USB pins, R221/R222 near MCU B's.
- PCx_VBUS is **never** connected to +5V or any dock rail. Firmware connects each MCU's USB (D+ pull-up) only while its PCx_VBUS_DET is high, so a switched-off PC is never back-fed.

---

## 5. MCU A (RP2354A)

Sheet `mcu_a.kicad_sch`. Core circuit = Raspberry Pi's Minimal design (`hardware/reference/rpi-rp2350a-minimal`); after F8, `hardware/tools/copy_rpi_core_layout.py … U301` copies RPi's layout.

```text
 +3V3 ──●── U301 IOVDD (1, 11, 20, 30, 38, 45), ADC_AVDD (44), USB_OTP_VDD (53), QSPI_IOVDD (54)
        ├── U301 pin 49 VREG_VIN ── C301 4.7 µF ── GND
        └── R301 33 Ω ──●── A_VREG_AVDD ── U301 pin 46;  C303 4.7 µF ── GND
 U301 pin 48 VREG_LX ── A_VREG_LX ── L301 pin 2      L301 pin 1 (dot) ──●── A_1V1
 A_1V1 ── U301 DVDD (6, 23, 39) and VREG_FB (50);  C302 4.7 µF, C304–C306 100 nF ── GND
 +3V3 ── C307–C313 100 nF, C314 10 µF ── GND          U301 pin 47 VREG_PGND, pin 61 pad ── GND
 U301 pin 21 XIN ──●── A_XIN ── Y301 pin 1;  C315 15 pF ── GND
 U301 pin 22 XOUT ── A_XOUT ── R302 1 k ── A_XOUT_R ──●── Y301 pin 3;  C316 15 pF ── GND
 Y301 pins 2, 4 ── GND
 U301 pin 60 QSPI_SS ── A_QSPI_SS ── R303 1 k ── A_BOOTSEL_BTN ── SW301 ── GND      (BOOTSEL A)
 U301 pin 26 RUN ── A_RUN ── SW302 ── GND                                            (RESET A)
 U301 pins 24/25 SWCLK/SWDIO ── J401 pins 3/2 (1x3 2.54 mm SWD header; pin 1 = GND)
 U301 GPIO0 ── A_LED ── R305 1 k ── A_LED_R ── D301 anode (2); cathode (1) ── GND
 QSPI_SD0–3, QSPI_SCLK (55–59): no-connect (the 2 MB flash inside uses them)
```

**Parts**

| Ref | Value | Footprint | LCSC | Job |
|---|---|---|---|---|
| U301 | RP2354A | `RP2350A_QFN-60_RPi_Vias` | C41378174 | A: keyboard host (PIO-USB) + Personal PC |
| L301 | 3.3uH | `L_Abracon_AOTA-B201610S3R3_0806` | C42411119 | pin 1 (dot) = +1V1, pin 2 = VREG_LX |
| C301 | 4.7uF | `C_0402_RPi_Wide` | C23733 | VREG_VIN (RPi C6) |
| C302 | 4.7uF | `C_0402_RPi_Wide` | C23733 | +1V1 output (RPi C7) |
| C303 | 4.7uF | `C_0402_1005Metric` | C23733 | VREG_AVDD (RPi C9) |
| R301 | 33 | `R_0402_1005Metric` | C25105 | 3V3 -> VREG_AVDD (RPi R3) |
| C304 | 100nF | `C_0402_1005Metric` | C1525 | DVDD 1 (+1V1) |
| C305 | 100nF | `C_0402_1005Metric` | C1525 | DVDD 2 (+1V1) |
| C306 | 100nF | `C_0402_1005Metric` | C1525 | DVDD 3 (+1V1) |
| C307 | 100nF | `C_0402_1005Metric` | C1525 | IOVDD / ADC / USB_OTP / QSPI (+3V3) |
| C308 | 100nF | `C_0402_1005Metric` | C1525 | IOVDD / ADC / USB_OTP / QSPI (+3V3) |
| C309 | 100nF | `C_0402_1005Metric` | C1525 | IOVDD / ADC / USB_OTP / QSPI (+3V3) |
| C310 | 100nF | `C_0402_1005Metric` | C1525 | IOVDD / ADC / USB_OTP / QSPI (+3V3) |
| C311 | 100nF | `C_0402_1005Metric` | C1525 | IOVDD / ADC / USB_OTP / QSPI (+3V3) |
| C312 | 100nF | `C_0402_1005Metric` | C1525 | IOVDD / ADC / USB_OTP / QSPI (+3V3) |
| C313 | 100nF | `C_0402_1005Metric` | C1525 | IOVDD / ADC / USB_OTP / QSPI (+3V3) |
| C314 | 10uF | `C_0805_2012Metric` | C15850 | +3V3 bulk |
| Y301 | 12MHz | `Crystal_SMD_3225-4Pin_3.2x2.5mm` | C20625731 | ABM8-272-T3 (10 pF, 50 ohm) |
| C315 | 15pF | `C_0402_1005Metric` | C1548 | XIN load |
| C316 | 15pF | `C_0402_1005Metric` | C1548 | XOUT load |
| R302 | 1k | `R_0402_1005Metric` | C11702 | XOUT series (RPi R2) |
| SW301 | SW_Push | `SW_Push_1P1T_XKB_TS-1187A` | C318884 | BOOTSEL A |
| R303 | 1k | `R_0402_1005Metric` | C11702 | QSPI_SS -> BOOTSEL button |
| SW302 | SW_Push | `SW_Push_1P1T_XKB_TS-1187A` | C318884 | RESET A (RUN to GND) |
| D301 | LED red | `LED_0603_1608Metric` | C2286 | status LED |
| R305 | 1k | `R_0402_1005Metric` | C11702 | LED series |
| J401 | Conn_01x03 | `PinHeader_1x03_P2.54mm_Vertical` | — |  |

**Pin map — MCU A GPIOs**

| GPIO | Pin | Net | Goes to |
|---|---|---|---|
| GPIO0 | 2 | A_LED | R305 → D301 |
| GPIO1 | 3 | **PC1_VBUS_DET** | J202 VBUS divider (R213/R214) |
| GPIO2 | 4 | **KBD_USB_D_N** | PIO-USB D− → R206 → J201 (D− = D+ − 1: PIO_USB_PINOUT_DMDP) |
| GPIO3 | 5 | **KBD_USB_D_P** | PIO-USB D+ → R205 → J201 |
| GPIO4 | 7 | spare (no-connect flag) |  |
| GPIO5 | 8 | spare (no-connect flag) |  |
| GPIO6 | 9 | spare (no-connect flag) |  |
| GPIO7 | 10 | spare (no-connect flag) |  |
| GPIO8 | 12 | **KBD_VBUS_EN** | U202 EN (R208 pull-down) |
| GPIO9 | 13 | **BLE_EN** | ESP32 EN, open-drain |
| GPIO10 | 14 | **BLE_BOOT** | ESP32 GPIO9, open-drain |
| GPIO11 | 15 | **POGO_OFF** | Q602 gate: high = pogo 5 V off |
| GPIO12 | 16 | **BLE_TX** | UART0 TX → ESP32 RXD0 (U501.30) |
| GPIO13 | 17 | **BLE_RX** | UART0 RX ← ESP32 TXD0 (U501.31) |
| GPIO14 | 18 | **POGO_DET** | pogo DET (low = docked), also Q601 gate |
| GPIO15 | 19 | **POGO_RX** | PIO UART RX ← R602 ← pogo pin 4 |
| GPIO16 | 27 | **POGO_TX** | PIO UART TX → R601 → pogo pin 5 |
| GPIO17 | 28 | **PD_PG** | CH224A PG (R102 pull-up) |
| GPIO18 | 29 | **PD_SDA** | I2C1 SDA → CH224A CFG3/SDA |
| GPIO19 | 31 | **PD_SCL** | I2C1 SCL → CH224A CFG2/SCL |
| GPIO20 | 32 | **B_RUN** | B RUN, open-drain (R406 pull-up) |
| GPIO21 | 33 | **B_SWDIO** | B SWDIO |
| GPIO22 | 34 | **B_SWCLK** | B SWCLK (PIO SWD probe) |
| GPIO23 | 35 | **B_LINK_RX** | UART1 RX (F11 aux) ← B GPIO6 (TX) |
| GPIO24 | 36 | **B_LINK_TX** | UART1 TX → B GPIO5 (RX) |
| GPIO25 | 37 | **B_BOOTSEL** | R404 → B QSPI_SS, open-drain (R407 pull-up) |
| GPIO26 | 40 | **POGO_5V_SENSE** | ADC0: R607/R608 divider |
| GPIO27 | 41 | **KBD_VBUS_SENSE** | ADC1: R209/R210 divider |
| GPIO28 | 42 | **KBD_CC2** | ADC2: J201 CC2 (Rp R202) |
| GPIO29 | 43 | **KBD_CC1** | ADC3: J201 CC1 (Rp R201) |

Why these pins (chosen to keep the routing on 2 layers with as few crossings as possible): hardware UART0 TX/RX exist on GPIO 0/1, 2/3, 12/13, 14/15, 16/17, 18/19, 28/29 (TX even, RX odd); UART1 on 4/5, 6/7, 8/9, 10/11, 20/21, 22/23, 24/25, 26/27 (any TX with any RX of the same UART); I2C1 SDA/SCL on 18/19 (and 2/3, 6/7, 10/11, 14/15, 22/23); the ADC only on 26–29; PIO-USB needs two adjacent GPIOs — here D− = D+ − 1, so the firmware uses `PIO_USB_PINOUT_DMDP` with `pin_dp = 3`. The ESP32 is on UART0 and the B link on UART1; the CH224A is on I2C1. Sides of the QFN-60 (top view, pin 1 top-left, counter-clockwise): left = GPIO0–11 (faces J201), bottom = GPIO12–18 (faces the ESP32 and the pogo), right = GPIO19–29 (faces MCU B; the CH224A lines run under B), top = regulator and USB (faces J202).

**Wiring — U301**

| U301 pin | Name | Net | Also on this net |
|---|---|---|---|
| 1 | IOVDD | **+3V3** | 48 other pins |
| 2 | GPIO0 | A_LED | R305.1 |
| 3 | GPIO1 | **PC1_VBUS_DET** | R213.2, R214.1 |
| 4 | GPIO2 | **KBD_USB_D_N** | R206.2 |
| 5 | GPIO3 | **KBD_USB_D_P** | R205.2 |
| 6 | DVDD | A_1V1 | L301.1, C302.1, C304.1, C305.1, C306.1 |
| 7 | GPIO4 | no-connect flag | |
| 8 | GPIO5 | no-connect flag | |
| 9 | GPIO6 | no-connect flag | |
| 10 | GPIO7 | no-connect flag | |
| 11 | IOVDD | **+3V3** | 48 other pins |
| 12 | GPIO8 | **KBD_VBUS_EN** | U202.4, R208.1 |
| 13 | GPIO9 | **BLE_EN** | U501.8, R501.2, C501.1 |
| 14 | GPIO10 | **BLE_BOOT** | U501.23, R504.2 |
| 15 | GPIO11 | **POGO_OFF** | Q602.1, R609.1 |
| 16 | GPIO12 | **BLE_TX** | U501.30, TP504.1 |
| 17 | GPIO13 | **BLE_RX** | U501.31, TP503.1 |
| 18 | GPIO14 | **POGO_DET** | R603.2, Q601.1, R604.2 |
| 19 | GPIO15 | **POGO_RX** | R602.2 |
| 20 | IOVDD | **+3V3** | 48 other pins |
| 21 | XIN | A_XIN | Y301.1, C315.1 |
| 22 | XOUT | A_XOUT | R302.1 |
| 23 | DVDD | A_1V1 | L301.1, C302.1, C304.1, C305.1, C306.1 |
| 24 | SWCLK | A_SWCLK | J401.3 |
| 25 | SWDIO | A_SWDIO | J401.2 |
| 26 | RUN | A_RUN | SW302.1 |
| 27 | GPIO16 | **POGO_TX** | R601.1 |
| 28 | GPIO17 | **PD_PG** | U102.10, R102.2 |
| 29 | GPIO18 | **PD_SDA** | U102.3, R104.2 |
| 30 | IOVDD | **+3V3** | 48 other pins |
| 31 | GPIO19 | **PD_SCL** | U102.2, R103.2 |
| 32 | GPIO20 | **B_RUN** | U401.26, R406.2 |
| 33 | GPIO21 | **B_SWDIO** | U401.25, J501.2 |
| 34 | GPIO22 | **B_SWCLK** | U401.24, J501.3 |
| 35 | GPIO23 | **B_LINK_RX** | U401.9 |
| 36 | GPIO24 | **B_LINK_TX** | U401.8 |
| 37 | GPIO25 | **B_BOOTSEL** | R404.1, R407.2 |
| 38 | IOVDD | **+3V3** | 48 other pins |
| 39 | DVDD | A_1V1 | L301.1, C302.1, C304.1, C305.1, C306.1 |
| 40 | GPIO26/ADC0 | **POGO_5V_SENSE** | R607.2, R608.1 |
| 41 | GPIO27/ADC1 | **KBD_VBUS_SENSE** | R209.2, R210.1 |
| 42 | GPIO28/ADC2 | **KBD_CC2** | J201.B5, U201.4, R202.2 |
| 43 | GPIO29/ADC3 | **KBD_CC1** | J201.A5, U201.3, R201.2 |
| 44 | ADC_AVDD | **+3V3** | 48 other pins |
| 45 | IOVDD | **+3V3** | 48 other pins |
| 46 | VREG_AVDD | A_VREG_AVDD | C303.1, R301.2 |
| 47 | VREG_PGND | **GND** | 141 other pins |
| 48 | VREG_LX | A_VREG_LX | L301.2 |
| 49 | VREG_VIN | **+3V3** | 48 other pins |
| 50 | VREG_FB | A_1V1 | L301.1, C302.1, C304.1, C305.1, C306.1 |
| 51 | USB_DM | **PC1_USB_D_N** | R216.2 |
| 52 | USB_DP | **PC1_USB_D_P** | R215.2 |
| 53 | USB_OTP_VDD | **+3V3** | 48 other pins |
| 54 | QSPI_IOVDD | **+3V3** | 48 other pins |
| 55 | QSPI_SD3 | no-connect flag | |
| 56 | QSPI_SCLK | no-connect flag | |
| 57 | QSPI_SD0 | no-connect flag | |
| 58 | QSPI_SD2 | no-connect flag | |
| 59 | QSPI_SD1 | no-connect flag | |
| 60 | QSPI_SS | A_QSPI_SS | R303.1 |
| 61 | GND | **GND** | 141 other pins |

| Part | Pin 1 | Pin 2 |
|---|---|---|
| L301 | A_1V1 | A_VREG_LX |
| C301 | **+3V3** | **GND** |
| C302 | A_1V1 | **GND** |
| C303 | A_VREG_AVDD | **GND** |
| R301 | **+3V3** | A_VREG_AVDD |
| C304 | A_1V1 | **GND** |
| C305 | A_1V1 | **GND** |
| C306 | A_1V1 | **GND** |
| C307 | **+3V3** | **GND** |
| C308 | **+3V3** | **GND** |
| C309 | **+3V3** | **GND** |
| C310 | **+3V3** | **GND** |
| C311 | **+3V3** | **GND** |
| C312 | **+3V3** | **GND** |
| C313 | **+3V3** | **GND** |
| C314 | **+3V3** | **GND** |
| C315 | A_XIN | **GND** |
| C316 | A_XOUT_R | **GND** |
| R302 | A_XOUT | A_XOUT_R |
| R303 | A_QSPI_SS | A_BOOTSEL_BTN |
| SW301 | A_BOOTSEL_BTN | **GND** |
| SW302 | A_RUN | **GND** |
| R305 | A_LED | A_LED_R |
| D301 (1 = K, 2 = A) | **GND** | A_LED_R |

Crystal: Y301 → A_XIN is 4 pins — 1 = A_XIN, 3 = A_XOUT_R, 2 and 4 = GND.

**Placement**

- U301 back-left; top side (regulator, USB pins) towards J202, left side towards J201.
- Run `copy_rpi_core_layout.py … U301`: it places L301, C301–C313, R301, Y301, C315, C316, R302 exactly as RPi does (inductor dot towards A_1V1) and copies the pours and tracks.
- C314 (10 µF) near U104's +3V3 feed into this chip. SW301/SW302 reachable from above.

---

## 6. MCU B (RP2354A)

Sheet `mcu_b.kicad_sch`. Same core as MCU A (B_ nets, U401 …). What differs: B has no reset button (A resets it), and A controls B's RUN, BOOTSEL and SWD.

```text
 (core: as MCU A, with U401, L401, C401–C416, R401, R402, Y401, B_* local nets)
 U401 pin 26 RUN ── B_RUN ◄── MCU A GPIO20 (open-drain);  R406 10 k to +3V3
 U401 pin 60 QSPI_SS ──●── B_QSPI_SS ── R403 1 k ── B_BOOTSEL_BTN ── SW401 ── GND     (BOOTSEL B)
                       └── R404 1 k ── B_BOOTSEL ◄── MCU A GPIO25 (open-drain);  R407 10 k to +3V3
 U401 pins 24/25 SWCLK/SWDIO ──●── B_SWCLK / B_SWDIO ◄── MCU A GPIO22 / GPIO21
                               └── J501 pins 3/2 (1x3 SWD header; pin 1 = GND)
 U401 GPIO6 (UART1 TX) ── B_LINK_RX ──► MCU A GPIO23 (UART1 RX)
 U401 GPIO5 (UART1 RX) ◄── B_LINK_TX ◄── MCU A GPIO24 (UART1 TX)
 U401 GPIO29 ◄── PC2_VBUS_DET;   U401 GPIO3 ── B_LED ── R405 1 k ── D401 ── GND
 U401 pins 52/51 USB_DP/DM ── PC2_USB_D_P / PC2_USB_D_N (from R221/R222)
```

R406/R407 matter: at reset and in BOOTSEL mode, MCU A's pins are inputs with weak pull-downs. Without the 10 k pull-ups, B_RUN and B_BOOTSEL would sit at mid-level against B's weak internal pull-ups, and B could stay in reset or boot into BOOTSEL whenever A restarts.

**Parts**

| Ref | Value | Footprint | LCSC | Job |
|---|---|---|---|---|
| U401 | RP2354A | `RP2350A_QFN-60_RPi_Vias` | C41378174 | B: Work PC device |
| L401 | 3.3uH | `L_Abracon_AOTA-B201610S3R3_0806` | C42411119 | pin 1 (dot) = +1V1, pin 2 = VREG_LX |
| C401 | 4.7uF | `C_0402_RPi_Wide` | C23733 | VREG_VIN (RPi C6) |
| C402 | 4.7uF | `C_0402_RPi_Wide` | C23733 | +1V1 output (RPi C7) |
| C403 | 4.7uF | `C_0402_1005Metric` | C23733 | VREG_AVDD (RPi C9) |
| R401 | 33 | `R_0402_1005Metric` | C25105 | 3V3 -> VREG_AVDD (RPi R3) |
| C404 | 100nF | `C_0402_1005Metric` | C1525 | DVDD 1 (+1V1) |
| C405 | 100nF | `C_0402_1005Metric` | C1525 | DVDD 2 (+1V1) |
| C406 | 100nF | `C_0402_1005Metric` | C1525 | DVDD 3 (+1V1) |
| C407 | 100nF | `C_0402_1005Metric` | C1525 | IOVDD / ADC / USB_OTP / QSPI (+3V3) |
| C408 | 100nF | `C_0402_1005Metric` | C1525 | IOVDD / ADC / USB_OTP / QSPI (+3V3) |
| C409 | 100nF | `C_0402_1005Metric` | C1525 | IOVDD / ADC / USB_OTP / QSPI (+3V3) |
| C410 | 100nF | `C_0402_1005Metric` | C1525 | IOVDD / ADC / USB_OTP / QSPI (+3V3) |
| C411 | 100nF | `C_0402_1005Metric` | C1525 | IOVDD / ADC / USB_OTP / QSPI (+3V3) |
| C412 | 100nF | `C_0402_1005Metric` | C1525 | IOVDD / ADC / USB_OTP / QSPI (+3V3) |
| C413 | 100nF | `C_0402_1005Metric` | C1525 | IOVDD / ADC / USB_OTP / QSPI (+3V3) |
| C414 | 10uF | `C_0805_2012Metric` | C15850 | +3V3 bulk |
| Y401 | 12MHz | `Crystal_SMD_3225-4Pin_3.2x2.5mm` | C20625731 | ABM8-272-T3 (10 pF, 50 ohm) |
| C415 | 15pF | `C_0402_1005Metric` | C1548 | XIN load |
| C416 | 15pF | `C_0402_1005Metric` | C1548 | XOUT load |
| R402 | 1k | `R_0402_1005Metric` | C11702 | XOUT series (RPi R2) |
| SW401 | SW_Push | `SW_Push_1P1T_XKB_TS-1187A` | C318884 | BOOTSEL B |
| R403 | 1k | `R_0402_1005Metric` | C11702 | QSPI_SS -> BOOTSEL button |
| R404 | 1k | `R_0402_1005Metric` | C11702 | QSPI_SS <- B_BOOTSEL from MCU A |
| R406 | 10k | `R_0402_1005Metric` | C25744 | B_RUN pull-up (beats A pull-down at reset) |
| R407 | 10k | `R_0402_1005Metric` | C25744 | B_BOOTSEL pull-up (beats A pull-down) |
| D401 | LED red | `LED_0603_1608Metric` | C2286 | status LED |
| R405 | 1k | `R_0402_1005Metric` | C11702 | LED series |
| J501 | Conn_01x03 | `PinHeader_1x03_P2.54mm_Vertical` | — |  |

**Pin map — MCU B GPIOs**

| GPIO | Pin | Net | Goes to |
|---|---|---|---|
| GPIO3 | 5 | B_LED | R405 → D401 |
| GPIO5 | 8 | **B_LINK_TX** | UART1 RX ← A GPIO24 |
| GPIO6 | 9 | **B_LINK_RX** | UART1 TX (F11 aux) → A GPIO23 |
| GPIO29 | 43 | **PC2_VBUS_DET** | J203 VBUS divider (R219/R220) |
| all other GPIOs | … | spare (no-connect flags) | |

**Wiring — U401**

| U401 pin | Name | Net | Also on this net |
|---|---|---|---|
| 1 | IOVDD | **+3V3** | 48 other pins |
| 2 | GPIO0 | no-connect flag | |
| 3 | GPIO1 | no-connect flag | |
| 4 | GPIO2 | no-connect flag | |
| 5 | GPIO3 | B_LED | R405.1 |
| 6 | DVDD | B_1V1 | L401.1, C402.1, C404.1, C405.1, C406.1 |
| 7 | GPIO4 | no-connect flag | |
| 8 | GPIO5 | **B_LINK_TX** | U301.36 |
| 9 | GPIO6 | **B_LINK_RX** | U301.35 |
| 10 | GPIO7 | no-connect flag | |
| 11 | IOVDD | **+3V3** | 48 other pins |
| 12 | GPIO8 | no-connect flag | |
| 13 | GPIO9 | no-connect flag | |
| 14 | GPIO10 | no-connect flag | |
| 15 | GPIO11 | no-connect flag | |
| 16 | GPIO12 | no-connect flag | |
| 17 | GPIO13 | no-connect flag | |
| 18 | GPIO14 | no-connect flag | |
| 19 | GPIO15 | no-connect flag | |
| 20 | IOVDD | **+3V3** | 48 other pins |
| 21 | XIN | B_XIN | Y401.1, C415.1 |
| 22 | XOUT | B_XOUT | R402.1 |
| 23 | DVDD | B_1V1 | L401.1, C402.1, C404.1, C405.1, C406.1 |
| 24 | SWCLK | **B_SWCLK** | U301.34, J501.3 |
| 25 | SWDIO | **B_SWDIO** | U301.33, J501.2 |
| 26 | RUN | **B_RUN** | U301.32, R406.2 |
| 27 | GPIO16 | no-connect flag | |
| 28 | GPIO17 | no-connect flag | |
| 29 | GPIO18 | no-connect flag | |
| 30 | IOVDD | **+3V3** | 48 other pins |
| 31 | GPIO19 | no-connect flag | |
| 32 | GPIO20 | no-connect flag | |
| 33 | GPIO21 | no-connect flag | |
| 34 | GPIO22 | no-connect flag | |
| 35 | GPIO23 | no-connect flag | |
| 36 | GPIO24 | no-connect flag | |
| 37 | GPIO25 | no-connect flag | |
| 38 | IOVDD | **+3V3** | 48 other pins |
| 39 | DVDD | B_1V1 | L401.1, C402.1, C404.1, C405.1, C406.1 |
| 40 | GPIO26/ADC0 | no-connect flag | |
| 41 | GPIO27/ADC1 | no-connect flag | |
| 42 | GPIO28/ADC2 | no-connect flag | |
| 43 | GPIO29/ADC3 | **PC2_VBUS_DET** | R219.2, R220.1 |
| 44 | ADC_AVDD | **+3V3** | 48 other pins |
| 45 | IOVDD | **+3V3** | 48 other pins |
| 46 | VREG_AVDD | B_VREG_AVDD | C403.1, R401.2 |
| 47 | VREG_PGND | **GND** | 141 other pins |
| 48 | VREG_LX | B_VREG_LX | L401.2 |
| 49 | VREG_VIN | **+3V3** | 48 other pins |
| 50 | VREG_FB | B_1V1 | L401.1, C402.1, C404.1, C405.1, C406.1 |
| 51 | USB_DM | **PC2_USB_D_N** | R222.2 |
| 52 | USB_DP | **PC2_USB_D_P** | R221.2 |
| 53 | USB_OTP_VDD | **+3V3** | 48 other pins |
| 54 | QSPI_IOVDD | **+3V3** | 48 other pins |
| 55 | QSPI_SD3 | no-connect flag | |
| 56 | QSPI_SCLK | no-connect flag | |
| 57 | QSPI_SD0 | no-connect flag | |
| 58 | QSPI_SD2 | no-connect flag | |
| 59 | QSPI_SD1 | no-connect flag | |
| 60 | QSPI_SS | B_QSPI_SS | R403.1, R404.2 |
| 61 | GND | **GND** | 141 other pins |

| Part | Pin 1 | Pin 2 |
|---|---|---|
| L401 | B_1V1 | B_VREG_LX |
| C401 | **+3V3** | **GND** |
| C402 | B_1V1 | **GND** |
| C403 | B_VREG_AVDD | **GND** |
| R401 | **+3V3** | B_VREG_AVDD |
| C404 | B_1V1 | **GND** |
| C405 | B_1V1 | **GND** |
| C406 | B_1V1 | **GND** |
| C407 | **+3V3** | **GND** |
| C408 | **+3V3** | **GND** |
| C409 | **+3V3** | **GND** |
| C410 | **+3V3** | **GND** |
| C411 | **+3V3** | **GND** |
| C412 | **+3V3** | **GND** |
| C413 | **+3V3** | **GND** |
| C414 | **+3V3** | **GND** |
| C415 | B_XIN | **GND** |
| C416 | B_XOUT_R | **GND** |
| R402 | B_XOUT | B_XOUT_R |
| R403 | B_QSPI_SS | B_BOOTSEL_BTN |
| R404 | **B_BOOTSEL** | B_QSPI_SS |
| R406 | **+3V3** | **B_RUN** |
| R407 | **+3V3** | **B_BOOTSEL** |
| SW401 | B_BOOTSEL_BTN | **GND** |
| R405 | B_LED | B_LED_R |
| D401 (1 = K, 2 = A) | **GND** | B_LED_R |

Crystal: Y401 → B_XIN (1 = B_XIN, 3 = B_XOUT_R, 2 and 4 = GND).

**Placement**

- U401 back-right; top side towards J203. Its left side (link, LED) faces MCU A; PC2_VBUS_DET is on the top-right pin towards J203.
- `copy_rpi_core_layout.py … U401` for the core.
- R406/R407 near U401 (RUN pin 26, QSPI_SS pin 60); R404 at QSPI_SS.

---
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

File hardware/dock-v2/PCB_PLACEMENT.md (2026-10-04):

# Dock v2 — PCB placement groups

Where the parts of the v2 dock go. **What connects to what: [DOCK_WIRING.md](DOCK_WIRING.md)** (component by component, for wiring) and [DOCK_CONNECTIONS.md](DOCK_CONNECTIONS.md) (the circuit explained, MCU pin maps). What each part does and why it was chosen is in the design docs:
[power input](../../docs/dock-v2-power-input.md), [USB ports](../../docs/dock-v2-usb-ports.md), [pogo](../../docs/dock-v2-pogo.md), [MCU support](../../docs/dock-v2-mcu-support.md), [MCU selection](../../docs/dock-v2-mcu-selection.md).

References below match the placed schematic and DOCK_CONNECTIONS.md, using one hundred-block per schematic sheet (KiCad: *Annotate → Use first free number after sheet number × 100*). Renumber freely.

| Sheet | File | Refs |
|---|---|---|
| 1 Power | `power.kicad_sch` | 1xx |
| 2 USB ports | `usb_ports.kicad_sch` | 2xx |
| 3 MCU A | `mcu_a.kicad_sch` | 3xx |
| 4 MCU B | `mcu_b.kicad_sch` | 4xx |
| 5 BLE | `ble.kicad_sch` | 5xx |
| 6 Pogo | `pogo.kicad_sch` | 6xx |
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

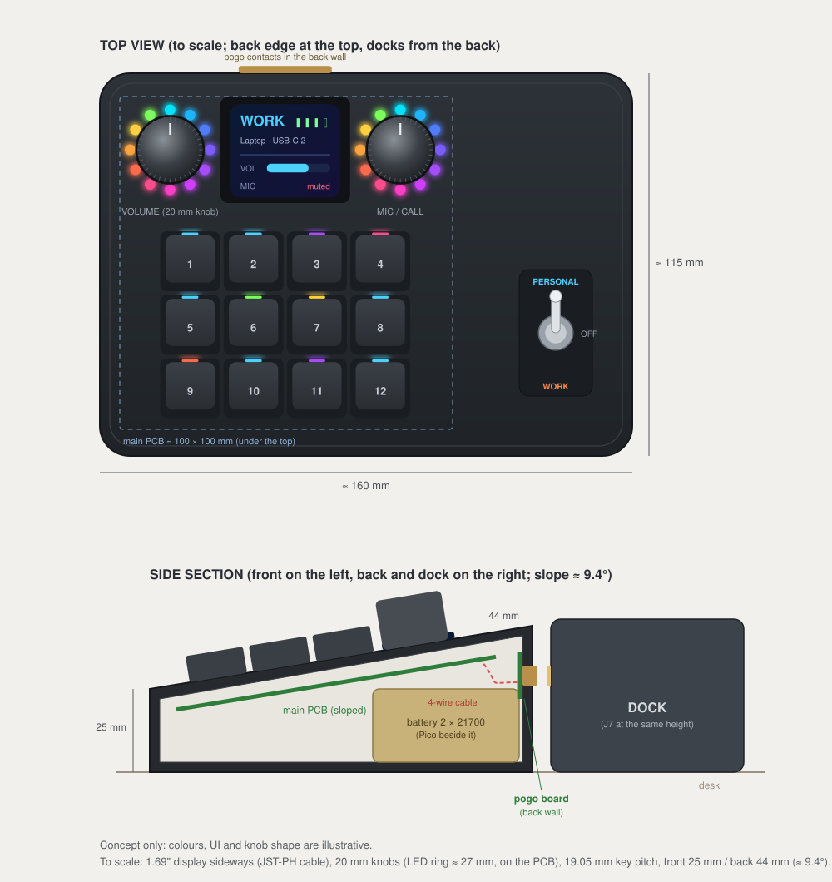
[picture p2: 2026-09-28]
docs/pad-concept.png

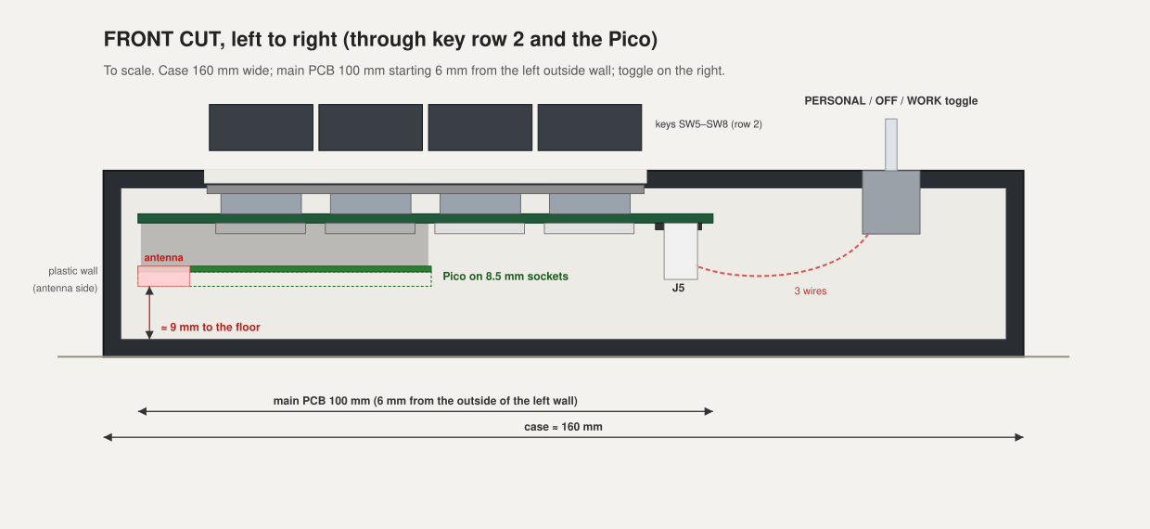
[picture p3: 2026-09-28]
docs/pad-pcb-4-front-cut.png

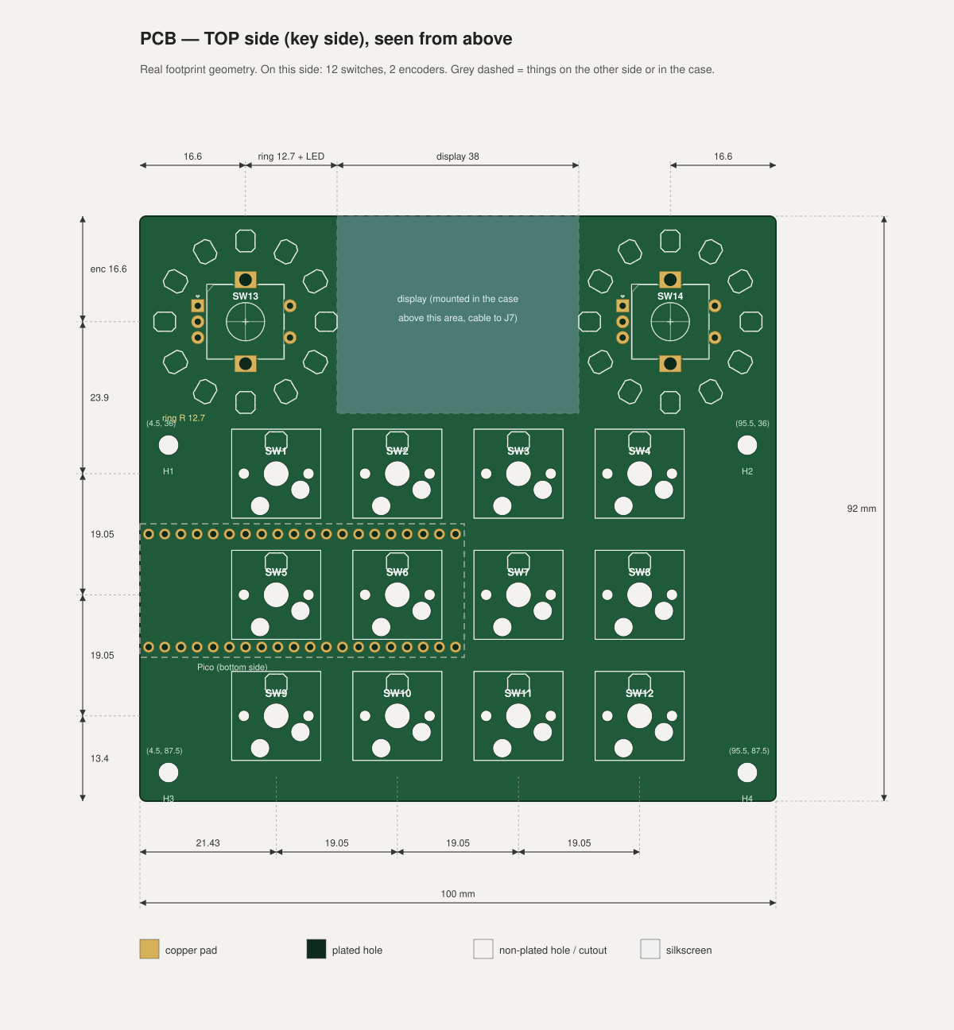
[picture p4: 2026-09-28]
docs/pad-pcb-1-top.png

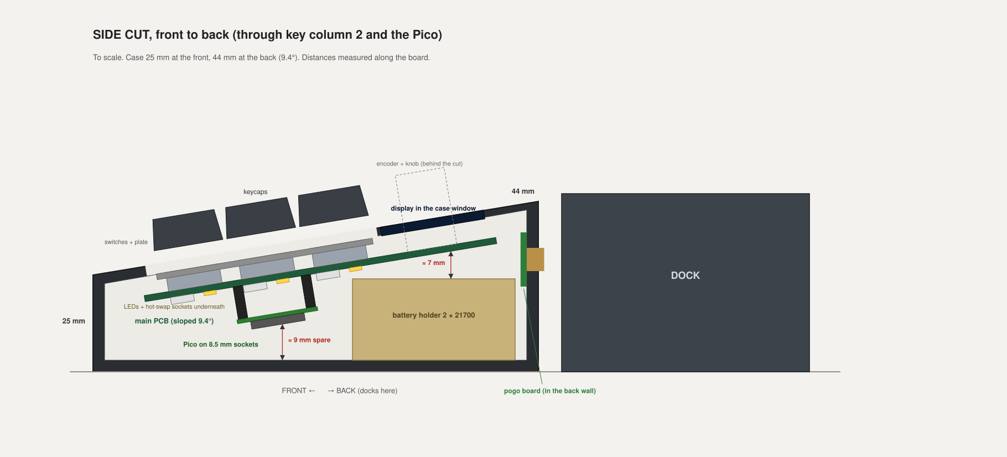
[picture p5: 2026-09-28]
docs/pad-pcb-3-side-cut.png

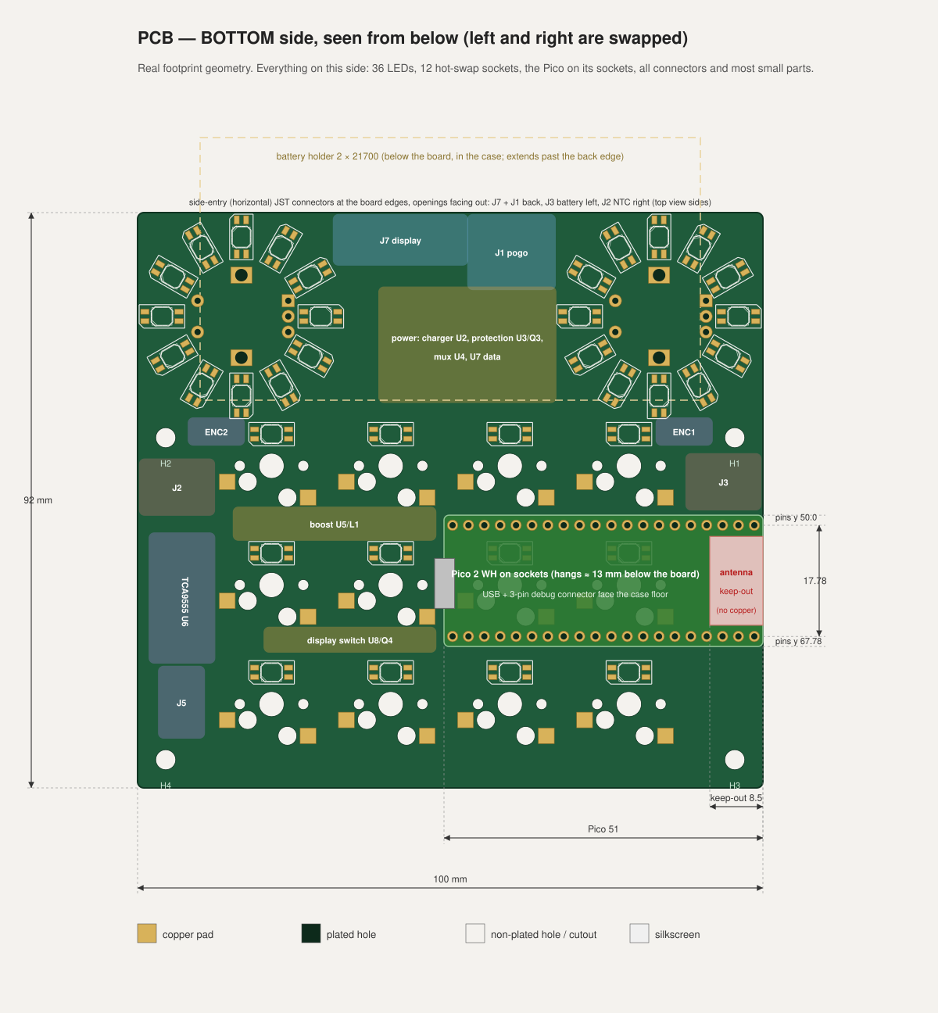
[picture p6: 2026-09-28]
docs/pad-pcb-2-bottom.png

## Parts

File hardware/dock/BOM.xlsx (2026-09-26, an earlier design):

Dock-pad — Dock PCB bill of materials
Generated from the hardware/dock schematic (66 parts) plus mechanical items. Prices in TL.
Boards to build |  | 1 |  | How to use:
Total cost (TL) |  | 3499.96 TL |  | Yellow cells are yours to edit: boards to build, spares, pack size, price per pack, shop, URL, notes.
Lines with a price |  | 25 |  | Black cells are formulas: Needed = Qty/board × Boards + Spares; Packs = ROUNDUP(Needed ÷ Pack size); Line total = Packs × Price per pack.
Lines still missing a price |  | 0 |  | Blue prices were seen on the listed shop on 2026-09-24 — verify before ordering. USD prices: multiply by the rate in C8.
USD → TL rate |  | 48.92
# | Group | Refs | Description | Part number | Package / footprint | Qty / board | Spares | Needed | Pack size | Packs to order | Price per pack (TL) | Line total (TL) | Shop | URL | Notes
1 | Modules | A1 | Host + BLE module | Raspberry Pi Pico 2 W | Socketed, 2×20 headers | 1 | 0 | 1 | 1 | 1 | 559.61 | 559.61 | Robotistan | https://www.robotistan.com/raspberry-pi-pico-2-w-header | Solder male 1×20 headers + a 1×3 header on the debug holes (pointing down)
2 | Modules | A2, A3 | HID endpoint modules | Raspberry Pi Pico 2 | Socketed, 2×20 headers | 2 | 0 | 2 | 1 | 2 | 416.24 | 832.48 | Robotistan | https://www.robotistan.com/raspberry-pi-pico-2-header?language=tr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 | Solder male 1×20 headers (pointing down)
3 | ICs | U1 | Priority power mux 2.5 A | TPS2116DRLR | SOT-583-8 (hand-solder footprint) | 1 | 4 | 5 | 1 | 5 | 34.31 | 171.55 | tme | https://www.tme.eu/tr/tr/details/tps2116drlr/analog-coklayicilar-ve-anahtarlar/texas-instruments/ | Seen at LCSC for ~0.25 USD (2026-09-24). Tiny 0.5 mm pitch — spares recommended
4 | ICs | U3 | USB power switch, active-high EN | TPS2553DBVR | SOT-23-6 | 1 | 1 | 2 | 1 | 2 | 26.81 | 53.62 | Özdisan | https://ozdisan.com/integrated-circuits-ics/power-management-ics/power-switches/TPS2553DBVR | Price seen 2026-09-24 (1 pc) — verify before ordering
5 | ICs | U8 | USB power switch, active-low EN | TPS2552DBVR | SOT-23-6 | 1 | 1 | 2 | 1 | 2 | 27.02 | 54.04 | Özdisan | https://ozdisan.com/integrated-circuits-ics/power-management-ics/power-switches/TPS2552DBVR | Price seen 2026-09-24 (1 pc) — verify before ordering. Not the -1 (latch-off) version
6 | ICs | U4, U5, U6, U9 | 4-channel ESD protection | TPD4E1U06DBVR | SOT-23-6 | 4 | 2 | 6 | 1 | 6 | 11.88 | 71.28 | Özdisan | https://ozdisan.com/power-semiconductors/diodes-diode-modules-and-rectifiers/tvs-diodes/TPD4E1U06DBVR | Price seen 2026-09-24 (1 pc) — verify before ordering
7 | Connectors | J1, J4, J5 | USB-C receptacle, USB 2.0, 16-pin SMD | KLS L-KLS1-5416-L1-01-R | USB-C 16-pin SMD | 3 | 2 | 5 | 1 | 5 | 4.16 | 20.82 | Özdisan | https://www.ozdisan.com/p/usb-konnektorler-357/kls-electronic-l-kls1-5416-l1-01-r-1564461 | Fine-pitch pads — spares for practice
8 | Connectors | J7 | Pogo connector, 6-pin, 2.54 mm | (choose — must mate with the pad side) | THT 1×6, 2.54 mm | 1 | 0 | 1 | 1 | 1 | 360.00 | 360.00 | Motorbit | https://www.motorobit.com/6-pin-254mm-90c-pogo-pin-magnetic-connector-set-with-ear | GND | +5V | DET | RX | TX | GND
9 | Connectors | J2, J3, J6 | SWD header 1×5, 2.54 mm | Male pin header 1×5 | THT | 3 | 0 | 3 | 8 | 1 | 3.6 | 3.60 | Motorbit | https://www.motorobit.com/1x40-erkek-header-40-pin-254mm-180-derece | Can be cut from a 1×40 strip
10 | Capacitors | C13, C14, C15, C16 | Bulk capacitor 100 µF 25 V, 105 °C | Panasonic EEE-FK1E101XP | 6.3 × 7.7 mm SMD can | 4 | 1 | 5 | 1 | 5 | 14.33 | 71.65 | Özdisan | https://www.ozdisan.com/passive-components/capacitors/aluminum-capacitors/EEE-FK1E101XP/622893 | Price seen 2026-09-24 (1 pc) — verify before ordering. Polarized: stripe = −
11 | Capacitors | C3, C6, C7, C8, C9, C11, C12 | 1 µF, ≥10 V, X7R | samsung CL21B105KBFNNNE | 0805 capacitor | 7 | 13 | 20 | 1 | 20 | 1.27 | 25.38 | Özdisan | https://www.ozdisan.com/p/smt-smd-ve-mlcc-kapasitorler-184/samsung-cl21b105kbfnnne-347740?catSequenceId=184
12 | Capacitors | C1, C2, C10 | 100 nF, ≥16 V, X7R | samsung CL21B104KBCNNNC | 0805 capacitor | 3 | 17 | 20 | 1 | 20 | 0.53 | 10.55 | Özdisan | https://www.ozdisan.com/p/smt-smd-ve-mlcc-kapasitorler-184/samsung-cl21b104kbcnnnc-14777?catSequenceId=184 | Shield termination
13 | Resistors | R3, R6, R13, R17, R18, R24, R29, R30, R31, R32, R36, R37 | 10 kΩ 1% | 0805S8F1002T5E | 0805 resistor | 12 | 3 | 15 | 100 | 1 | 10.68 | 10.68 | Özdisan | https://www.ozdisan.com/p/smt-smd-ve-cip-direncler-194/royalohm-0805s8f1002t5e-30240?catSequenceId=194
14 | Resistors | R25, R26, R27, R33, R34 | 1 kΩ 1% | RC0805FR-071KL | 0805 resistor | 5 | 2 | 7 | 50 | 1 | 12.60 | 12.60 | Özdisan | https://www.ozdisan.com/p/smt-smd-ve-cip-direncler-194/yageo-rc0805fr-071kl-460155?catSequenceId=194
15 | Resistors | R11, R12, R15, R16 | 5.1 kΩ 1% | 0805S8F5101T5E | 0805 resistor | 4 | 2 | 6 | 100 | 1 | 10.68 | 10.68 | Özdisan | https://www.ozdisan.com/p/smt-smd-ve-cip-direncler-194/royalohm-0805s8f5101t5e-358456?catSequenceId=194 | USB-C CC pull-downs
16 | Resistors | R9, R10, R14 | 330 Ω 1% | 0805S8F3300T5E | 0805 resistor | 3 | 2 | 5 | 100 | 1 | 10.68 | 10.68 | Özdisan | https://www.ozdisan.com/p/smt-smd-ve-cip-direncler-194/royalohm-0805s8f3300t5e-36831?catSequenceId=194
17 | Resistors | R5, R23 | 26.1 kΩ 1% | 0805S8F2612T5E | 0805 resistor | 2 | 2 | 4 | 100 | 1 | 7.26 | 7.26 | Özdisan | https://www.ozdisan.com/p/smt-smd-ve-cip-direncler-194/royalohm-0805s8f2612t5e-505551?catSequenceId=194 | Sets the 1 A current limit (U3, U8)
18 | Resistors | R7, R8 | 56 kΩ 1% | 0805S8F5602T5E | 0805 resistor | 2 | 2 | 4 | 100 | 1 | 10.68 | 10.68 | Özdisan | https://www.ozdisan.com/p/smt-smd-ve-cip-direncler-194/royalohm-0805s8f5602t5e-340670?catSequenceId=194 | Keyboard-port CC pull-ups
19 | Resistors | R19, R21 | 22 kΩ 1% | 0805S8F2202T5E | 0805 resistor | 2 | 2 | 4 | 100 | 1 | 10.68 | 10.68 | Özdisan | https://www.ozdisan.com/p/smt-smd-ve-cip-direncler-194/royalohm-0805s8f2202t5e-335040?catSequenceId=194 | VBUS sense divider (top)
20 | Resistors | R20, R22 | 33 kΩ 1% | 0805S8F3302T5E | 0805 resistor | 2 | 2 | 4 | 100 | 1 | 10.68 | 10.68 | Özdisan | https://www.ozdisan.com/p/smt-smd-ve-cip-direncler-194/royalohm-0805s8f3302t5e-339608?catSequenceId=194 | VBUS sense divider (bottom)
21 | Resistors | R2, R28 | 100 kΩ 1% | 0805S8F1003T5E | 0805 resistor | 2 | 2 | 4 | 100 | 1 | 10.68 | 10.68 | Özdisan | https://www.ozdisan.com/p/smt-smd-ve-cip-direncler-194/royalohm-0805s8f1003t5e-30244?catSequenceId=194
22 | Resistors | R1 | 300 kΩ 1% | 0805S8F3003T5E | 0805 resistor | 1 | 2 | 3 | 100 | 1 | 10.68 | 10.68 | Özdisan |  | TPS2116 PR1 divider (≈4.0 V switchover)
23 | Mechanical | — | Female socket 2.54 mm, 8.5 mm tall (cut from 1×40) | generic | THT | 6 | 3 | 9 | 2 | 5 | 6.60 | 33.00 | motorbit | https://www.motorobit.com/1x40-disi-header-40-pin-180-derece | One 1×40 strip gives one 1×20 + one 1×19 (a pin is lost at the cut). Put the 1×19 on the pin 1–20 side, leaving pin 1 or 20 empty: GP0 and GP15 are unused on all three Picos
27 | Mechanical | — | Spring probe P50-B1 | P50-B1 | 0.68 mm barrel, 16.35 mm | 15 | 0 | 15 | 100 | 1 | 270.00 | 270.00 | motorbit | https://www.motorobit.com/yayli-pogo-p50-b1-test-probu-100-adet | 10 required + 5 optional (GND). Sold as 100-pack; price seen 2026-09-24 — verify
28 | PCB | — | Dock PCB, 2-layer, 100 × 100 mm, 1.6 mm, HASL | JLCPCB / PCBWay | — | 1 | 0 | 1 | 5 | 1 | 857.08 | 857.08 | JLCPCB |  | 17.52 USD for 5 boards incl. e-post shipping to my address (JLCPCB quote 2026-09-26). Import taxes not included
 |  |  |  |  |  |  |  |  |  |  | Total | 3499.96

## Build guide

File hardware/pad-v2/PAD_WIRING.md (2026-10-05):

# Pad v2 — Wiring List (component by component)

Open a sheet, go through its parts in the order below (same order as the dashed group boxes), and for each pin draw what the **Draw** column says. After wiring, `python3 hardware/tools/pad_v2_connections/check_wiring.py` compares the schematic with this list (it checks which pins are joined; net names may differ).

How to draw each kind of connection:

- **power symbol** `GND`, `+3V3`: KiCad power symbols (they connect across all sheets).
- **global label**: the net continues on another sheet. Same name on every sheet where it appears.
- **wire (or local label)**: the net stays on this sheet.
- **no-connect flag**: the pin is deliberately unused: put an X on it.
- Each connection appears at both of its ends. Draw it once.
- Resistors, capacitors, inductors and push switches may be drawn either way round. The four ESD channels of a TPD4E1U06 (pins 1, 3, 4, 6) are interchangeable.

## 1. Power chain

```text
 pogo +5V (J101 2, 6) ─ D101 TVS ─ U102 WS3222D (cuts off at 5.69 V) ─ VIN_PROT ─ U103 ETA6003 ─┬─ VSYS ─┬─ U105 LDO ─ +3V3 ─ ESP32, display, pull-ups
                                                                                │        └─ U401 boost ─ 5V_RGB ─ 36 LEDs, U402
                                                                                └─ VBAT ─ J102 battery + ;  battery − = BAT_N ─ Q101 ─ GND
```

- `BAT_N` (battery minus) is **not** GND: it reaches GND only through Q101 (the protection FETs). Only J102 pin 2, U104 GND, C107 and Q101 S1 are on BAT_N.
- Put a PWR_FLAG on: `POGO_5V`, `VIN_PROT`, `VSYS`, `VBAT`, `BAT_N`, `+3V3`, `GND`, `5V_RGB`, `DISP_VCC` (ERC needs one on every supply net that no power-output pin drives).

## 2. ESP32-S3 pin map

Chosen for the placement in PCB_PLACEMENT.md (module at the front-left, rotation 90°): each signal leaves the module on the side facing its destination. All 39 GPIOs are used.

| GPIO | Module pin | Net | Leaves the module at | Goes to |
|---|---|---|---|---|
| IO0 | 4 | BOOT | front edge row (via under the module) | SW202 (BOOT button); strapping pin, internal pull-up |
| IO1 | 5 | KEY2 | front edge row (via under the module) | SW302 (key 2) |
| IO2 | 6 | KEY6 | front edge row (via under the module) | SW306 (key 6) |
| IO3 | 7 | KEY10 | front edge row (via under the module) | SW310 (key 10) |
| IO4 | 8 | KEY3 | front edge row (via under the module) | SW303 (key 3) |
| IO5 | 9 | KEY7 | front edge row (via under the module) | SW307 (key 7) |
| IO6 | 10 | KEY11 | front edge row (via under the module) | SW311 (key 11) |
| IO7 | 11 | KEY4 | front edge row (via under the module) | SW304 (key 4) |
| IO8 | 12 | KEY8 | front edge row (via under the module) | SW308 (key 8) |
| IO9 | 13 | KEY12 | front edge row (via under the module) | SW312 (key 12) |
| IO10 | 14 | VBAT_SENSE | front edge row (via under the module) | R117/R118 divider (ADC1_CH9) |
| IO11 | 15 | VIN_SENSE | front edge row (via under the module) | R106/R107 divider: dock 5 V present (ADC2_CH0 or digital) |
| IO12 | 16 | TGL_WORK | right row, south of USB (pocket: via, bottom layer) | J301 pin 3 |
| IO13 | 17 | TGL_PERSONAL | right row, south of USB (pocket: via, bottom layer) | J301 pin 1 |
| IO14 | 18 | CHG_STAT | right row, south of USB (pocket: via, bottom layer) | ETA6003 STAT (open drain, R114 pull-up) |
| IO15 | 19 | CHG_EN_N | right row, south of USB (pocket: via, bottom layer) | ETA6003 ENB: low = charge (R113 pull-down) |
| IO16 | 20 | ENC2_SW | right row, south of USB (pocket: via, bottom layer) | SW314 push switch |
| IO17 | 21 | ENC2_B | right row, south of USB (pocket: via, bottom layer) | SW314 B through R308/C304 |
| IO18 | 22 | ENC2_A | right row, south of USB (pocket: via, bottom layer) | SW314 A through R307/C303 |
| IO19 | 23 | USB_DN | right row | J201 D- (fixed pin) |
| IO20 | 24 | USB_DP | right row | J201 D+ (fixed pin) |
| IO21 | 25 | CHG_ISEL | right row, north of USB | ETA6003 USB_DET: low = 1.0 A, high = 0.45 A |
| IO26 | 26 | RGB_EN | right row, north of USB | TPS61023 EN (R403 pull-down) |
| IO47 | 27 | DISP_EN_N | right row, north | Q501 gate: low = display on (R501 pull-up) |
| IO33 | 28 | DISP_SCL | right row, north | J501 pin 6 |
| IO34 | 29 | DISP_SDA | right row, north | J501 pin 5 |
| IO48 | 30 | DISP_RES | right row, north | J501 pin 4 |
| IO35 | 31 | DISP_DC | back row, east end | J501 pin 3 |
| IO36 | 32 | DISP_CS | back row, east end | J501 pin 2 |
| IO37 | 33 | DISP_BLK | back row, east end | J501 pin 1 (backlight PWM) |
| IO38 | 34 | KEY9 | back row | SW309 (key 9) |
| IO39 | 35 | KEY5 | back row | SW305 (key 5) |
| IO40 | 36 | KEY1 | back row | SW301 (key 1) |
| IO41 | 37 | ENC1_B | back row | SW313 B through R304/C302 |
| IO42 | 38 | ENC1_A | back row | SW313 A through R303/C301 |
| TXD0 (IO43) | 39 | PAD_TX | back row (via, bottom layer) | R102 -> pogo pin 4 (UART0 TX, also the ROM bootloader) |
| RXD0 (IO44) | 40 | PAD_RX | back row (via, bottom layer) | R101 <- pogo pin 3 (UART0 RX) |
| IO45 | 41 | ENC1_SW | back row, west | SW313 push switch (strapping pin IO45: no external pull-up) |
| IO46 | 44 | RGB_DATA | back row, west | U402 input (strapping pin IO46: low at reset) |

Notes:

- **Strapping pins:** IO0 = BOOT button. IO45 must not be pulled high at reset (it carries only the encoder switch to GND). IO46 is low at reset (RGB data idles low). IO3 is a key to GND (harmless).
- The display, encoder and key pins can be swapped among themselves in firmware (GPIO matrix); USB (IO19/20), UART0 (TXD0/RXD0) and the ADC pin IO10 are fixed.
- Firmware: enable the internal pull-ups on the key, encoder-switch, toggle and BOOT pins.

## 3. LED chain (firmware index = reference − 401)

| Index | LED | Where |
|---|---|---|
| 0 | D401 | key 9 (SK6812MINI-E, bottom) |
| 1 | D402 | key 10 (SK6812MINI-E, bottom) |
| 2 | D403 | key 11 (SK6812MINI-E, bottom) |
| 3 | D404 | key 12 (SK6812MINI-E, bottom) |
| 4 | D405 | key 8 (SK6812MINI-E, bottom) |
| 5 | D406 | key 7 (SK6812MINI-E, bottom) |
| 6 | D407 | key 6 (SK6812MINI-E, bottom) |
| 7 | D408 | key 5 (SK6812MINI-E, bottom) |
| 8 | D409 | key 1 (SK6812MINI-E, bottom) |
| 9 | D410 | key 2 (SK6812MINI-E, bottom) |
| 10 | D411 | key 3 (SK6812MINI-E, bottom) |
| 11 | D412 | key 4 (SK6812MINI-E, bottom) |
| 12 | D413 | ring 2, 7 o'clock (XL-2020, top) |
| 13 | D414 | ring 2, 6 o'clock (XL-2020, top) |
| 14 | D415 | ring 2, 5 o'clock (XL-2020, top) |
| 15 | D416 | ring 2, 4 o'clock (XL-2020, top) |
| 16 | D417 | ring 2, 3 o'clock (XL-2020, top) |
| 17 | D418 | ring 2, 2 o'clock (XL-2020, top) |
| 18 | D419 | ring 2, 1 o'clock (XL-2020, top) |
| 19 | D420 | ring 2, 12 o'clock (XL-2020, top) |
| 20 | D421 | ring 2, 11 o'clock (XL-2020, top) |
| 21 | D422 | ring 2, 10 o'clock (XL-2020, top) |
| 22 | D423 | ring 2, 9 o'clock (XL-2020, top) |
| 23 | D424 | ring 2, 8 o'clock (XL-2020, top) |
| 24 | D425 | ring 1, 4 o'clock (XL-2020, top) |
| 25 | D426 | ring 1, 3 o'clock (XL-2020, top) |
| 26 | D427 | ring 1, 2 o'clock (XL-2020, top) |
| 27 | D428 | ring 1, 1 o'clock (XL-2020, top) |
| 28 | D429 | ring 1, 12 o'clock (XL-2020, top) |
| 29 | D430 | ring 1, 11 o'clock (XL-2020, top) |
| 30 | D431 | ring 1, 10 o'clock (XL-2020, top) |
| 31 | D432 | ring 1, 9 o'clock (XL-2020, top) |
| 32 | D433 | ring 1, 8 o'clock (XL-2020, top) |
| 33 | D434 | ring 1, 7 o'clock (XL-2020, top) |
| 34 | D435 | ring 1, 6 o'clock (XL-2020, top) |
| 35 | D436 | ring 1, 5 o'clock (XL-2020, top) |

## Sheets

---

## Sheet POWER

File `power.kicad_sch` · 44 parts

- Power symbols: `+3V3`, `GND`
- Global labels on this sheet: `CHG_EN_N`, `CHG_ISEL`, `CHG_STAT`, `PAD_RX`, `PAD_TX`, `VBAT_SENSE`, `VIN_SENSE`, `VSYS`
- PWR_FLAG on: `+3V3`, `BAT_N`, `GND`, `POGO_5V`, `VBAT`, `VIN_PROT`, `VSYS`
- No-connect flags: 5

### Pogo input (front strip)

#### J101 · Pogo cable (to floor board) · HAND-SOLDER, bottom. 1 GND, 2 +5V, 3 PAD_RX (dock TX), 4 PAD_TX (dock RX), 5 DET -> GND, 6 +5V, 7 GND

| Pin | Net | Connects to | Draw |
|---|---|---|---|
| 1 Pin_1 | GND |  | power symbol `GND` |
| 2 Pin_2 | POGO_5V | D101.1 (A1), U102.6 (IN), U102.7 (IN), U102.8 (IN), C101.1, R103.1 | wire (or local label `POGO_5V`) |
| 3 Pin_3 | PAD_RX_J | U101.1 (D1+), R101.1 | wire (or local label `PAD_RX_J`) |
| 4 Pin_4 | PAD_TX_J | U101.3 (D2+), R102.1 | wire (or local label `PAD_TX_J`) |
| 5 Pin_5 | GND |  | power symbol `GND` |
| 6 Pin_6 | POGO_5V | D101.1 (A1), U102.6 (IN), U102.7 (IN), U102.8 (IN), C101.1, R103.1 | wire (or local label `POGO_5V`) |
| 7 Pin_7 | GND |  | power symbol `GND` |

#### D101 · SMBJ15A · TVS on the pogo +5V (before the OVP switch): pin 1 (cathode band) to +5V, pin 2 to GND

| Pin | Net | Connects to | Draw |
|---|---|---|---|
| 1 A1 | POGO_5V | J101.2 (Pin_2), J101.6 (Pin_6), U102.6 (IN), U102.7 (IN), U102.8 (IN), C101.1, R103.1 | wire (or local label `POGO_5V`) |
| 2 A2 | GND |  | power symbol `GND` |

#### U101 · TPD4E1U06DBVR · ESD on PAD_RX and PAD_TX at J101

| Pin | Net | Connects to | Draw |
|---|---|---|---|
| 1 D1+ | PAD_RX_J | J101.3 (Pin_3), R101.1 | wire (or local label `PAD_RX_J`) |
| 2 GND | GND |  | power symbol `GND` |
| 3 D2+ | PAD_TX_J | J101.4 (Pin_4), R102.1 | wire (or local label `PAD_TX_J`) |
| 4 D2- | — | nothing | no-connect flag (X) |
| 5 NC | — | nothing | no-connect flag (X) |
| 6 D1- | — | nothing | no-connect flag (X) |

#### R101 · 1k · PAD_RX series (J101 pin 3 to ESP RXD0)

| Pin | Net | Connects to | Draw |
|---|---|---|---|
| 1 | PAD_RX_J | J101.3 (Pin_3), U101.1 (D1+) | wire (or local label `PAD_RX_J`) |
| 2 | PAD_RX | MCU sheet: U201.40 (RXD0) | **global label `PAD_RX`** |

#### R102 · 1k · PAD_TX series (ESP TXD0 to J101 pin 4)

| Pin | Net | Connects to | Draw |
|---|---|---|---|
| 1 | PAD_TX_J | J101.4 (Pin_4), U101.3 (D2+) | wire (or local label `PAD_TX_J`) |
| 2 | PAD_TX | MCU sheet: U201.39 (TXD0) | **global label `PAD_TX`** |

### Overvoltage switch WS3222D (5.69 V)

#### U102 · WS3222D · pogo +5V -> VIN_PROT (charger input); EP to GND

| Pin | Net | Connects to | Draw |
|---|---|---|---|
| 1 OUT | VIN_PROT | U103.2 (IN), R106.1, C102.1, C103.1, R110.1, R111.1 | wire (or local label `VIN_PROT`) |
| 2 OUT | VIN_PROT | U103.2 (IN), R106.1, C102.1, C103.1, R110.1, R111.1 | wire (or local label `VIN_PROT`) |
| 3 OUT | VIN_PROT | U103.2 (IN), R106.1, C102.1, C103.1, R110.1, R111.1 | wire (or local label `VIN_PROT`) |
| 4 GND | GND |  | power symbol `GND` |
| 5 OVLO | OVLO | R104.2, R105.1 | wire (or local label `OVLO`) |
| 6 IN | POGO_5V | J101.2 (Pin_2), J101.6 (Pin_6), D101.1 (A1), C101.1, R103.1 | wire (or local label `POGO_5V`) |
| 7 IN | POGO_5V | J101.2 (Pin_2), J101.6 (Pin_6), D101.1 (A1), C101.1, R103.1 | wire (or local label `POGO_5V`) |
| 8 IN | POGO_5V | J101.2 (Pin_2), J101.6 (Pin_6), D101.1 (A1), C101.1, R103.1 | wire (or local label `POGO_5V`) |
| 9 EP | GND |  | power symbol `GND` |

#### C101 · 1uF 50V · U102 IN

| Pin | Net | Connects to | Draw |
|---|---|---|---|
| 1 | POGO_5V | J101.2 (Pin_2), J101.6 (Pin_6), D101.1 (A1), U102.6 (IN), U102.7 (IN), U102.8 (IN), R103.1 | wire (or local label `POGO_5V`) |
| 2 | GND |  | power symbol `GND` |

#### R103 · 51k · OVLO top, part 1 (IN to R104)

| Pin | Net | Connects to | Draw |
|---|---|---|---|
| 1 | POGO_5V | J101.2 (Pin_2), J101.6 (Pin_6), D101.1 (A1), U102.6 (IN), U102.7 (IN), U102.8 (IN), C101.1 | wire (or local label `POGO_5V`) |
| 2 | OVLO_TOP | R104.1 | wire (or local label `OVLO_TOP`) |

#### R104 · 5.1k · OVLO top, part 2 (R103 to OVLO): 56.1k total

| Pin | Net | Connects to | Draw |
|---|---|---|---|
| 1 | OVLO_TOP | R103.2 | wire (or local label `OVLO_TOP`) |
| 2 | OVLO | U102.5 (OVLO), R105.1 | wire (or local label `OVLO`) |

#### R105 · 15k · OVLO bottom: 1.2 x (1 + 56.1/15) = 5.69 V

| Pin | Net | Connects to | Draw |
|---|---|---|---|
| 1 | OVLO | U102.5 (OVLO), R104.2 | wire (or local label `OVLO`) |
| 2 | GND |  | power symbol `GND` |

#### R106 · 10k · dock-5V sense top (VIN_PROT -> VIN_SENSE, IO11)

| Pin | Net | Connects to | Draw |
|---|---|---|---|
| 1 | VIN_PROT | U102.1 (OUT), U102.2 (OUT), U102.3 (OUT), U103.2 (IN), C102.1, C103.1, R110.1, R111.1 | wire (or local label `VIN_PROT`) |
| 2 | VIN_SENSE | R107.1; MCU sheet: U201.15 (IO11) | **global label `VIN_SENSE`** |

#### R107 · 15k · dock-5V sense bottom

| Pin | Net | Connects to | Draw |
|---|---|---|---|
| 1 | VIN_SENSE | R106.2; MCU sheet: U201.15 (IO11) | **global label `VIN_SENSE`** |
| 2 | GND |  | power symbol `GND` |

### Charger ETA6003 (1 A / 0.45 A, power path)

#### U103 · ETA6003 · ENPPB to GND; ENB = CHG_EN_N (IO15); USB_DET = CHG_ISEL (IO21); STAT = CHG_STAT (IO14); EP to GND

| Pin | Net | Connects to | Draw |
|---|---|---|---|
| 1 SYS | VSYS | L101.2, C104.1, C105.1, U105.1 (IN), U105.3 (EN), C109.1; RGB sheet: U401.3 (VIN), L401.1, C401.1 | **global label `VSYS`** |
| 2 IN | VIN_PROT | U102.1 (OUT), U102.2 (OUT), U102.3 (OUT), R106.1, C102.1, C103.1, R110.1, R111.1 | wire (or local label `VIN_PROT`) |
| 3 SW | CHG_SW | L101.1 | wire (or local label `CHG_SW`) |
| 4 SW | CHG_SW | L101.1 | wire (or local label `CHG_SW`) |
| 5 PGND | GND |  | power symbol `GND` |
| 6 ENB | CHG_EN_N | R113.1; MCU sheet: U201.19 (IO15) | **global label `CHG_EN_N`** |
| 7 NTC | CHG_NTC | J103.1 (Pin_1), R110.2, R111.2, R112.1 | wire (or local label `CHG_NTC`) |
| 8 ENPPB | GND |  | power symbol `GND` |
| 9 STAT | CHG_STAT | R114.1; MCU sheet: U201.18 (IO14) | **global label `CHG_STAT`** |
| 10 GND | GND |  | power symbol `GND` |
| 11 ISET1 | CHG_ISET1 | R108.1 | wire (or local label `CHG_ISET1`) |
| 12 ISET2 | CHG_ISET2 | R109.1 | wire (or local label `CHG_ISET2`) |
| 13 USB_DET | CHG_ISEL | MCU sheet: U201.25 (IO21) | **global label `CHG_ISEL`** |
| 14 BATT | VBAT | J102.1 (Pin_1), C106.1, R115.1, R117.1 | wire (or local label `VBAT`) |
| 15 SYS | VSYS | L101.2, C104.1, C105.1, U105.1 (IN), U105.3 (EN), C109.1; RGB sheet: U401.3 (VIN), L401.1, C401.1 | **global label `VSYS`** |
| 16 BATT | VBAT | J102.1 (Pin_1), C106.1, R115.1, R117.1 | wire (or local label `VBAT`) |
| 17 EP | GND |  | power symbol `GND` |

#### C102 · 10uF · IN (pin 2) to PGND (pin 5), closest to the IC

| Pin | Net | Connects to | Draw |
|---|---|---|---|
| 1 | VIN_PROT | U102.1 (OUT), U102.2 (OUT), U102.3 (OUT), U103.2 (IN), R106.1, C103.1, R110.1, R111.1 | wire (or local label `VIN_PROT`) |
| 2 | GND |  | power symbol `GND` |

#### C103 · 10uF · IN to GND (pin 10)

| Pin | Net | Connects to | Draw |
|---|---|---|---|
| 1 | VIN_PROT | U102.1 (OUT), U102.2 (OUT), U102.3 (OUT), U103.2 (IN), R106.1, C102.1, R110.1, R111.1 | wire (or local label `VIN_PROT`) |
| 2 | GND |  | power symbol `GND` |

#### L101 · 2.2uH · SW to SYS. Isat >= 3.5 A, 4x4 mm (LCSC number at BOM time)

| Pin | Net | Connects to | Draw |
|---|---|---|---|
| 1 | CHG_SW | U103.3 (SW), U103.4 (SW) | wire (or local label `CHG_SW`) |
| 2 | VSYS | U103.1 (SYS), U103.15 (SYS), C104.1, C105.1, U105.1 (IN), U105.3 (EN), C109.1; RGB sheet: U401.3 (VIN), L401.1, C401.1 | **global label `VSYS`** |

#### C104 · 22uF · SYS output

| Pin | Net | Connects to | Draw |
|---|---|---|---|
| 1 | VSYS | U103.1 (SYS), U103.15 (SYS), L101.2, C105.1, U105.1 (IN), U105.3 (EN), C109.1; RGB sheet: U401.3 (VIN), L401.1, C401.1 | **global label `VSYS`** |
| 2 | GND |  | power symbol `GND` |

#### C105 · 22uF · SYS output

| Pin | Net | Connects to | Draw |
|---|---|---|---|
| 1 | VSYS | U103.1 (SYS), U103.15 (SYS), L101.2, C104.1, U105.1 (IN), U105.3 (EN), C109.1; RGB sheet: U401.3 (VIN), L401.1, C401.1 | **global label `VSYS`** |
| 2 | GND |  | power symbol `GND` |

#### C106 · 10uF · BATT

| Pin | Net | Connects to | Draw |
|---|---|---|---|
| 1 | VBAT | U103.14 (BATT), U103.16 (BATT), J102.1 (Pin_1), R115.1, R117.1 | wire (or local label `VBAT`) |
| 2 | GND |  | power symbol `GND` |

#### R108 · 1k · ISET1: 1.0 A (USB_DET low)

| Pin | Net | Connects to | Draw |
|---|---|---|---|
| 1 | CHG_ISET1 | U103.11 (ISET1) | wire (or local label `CHG_ISET1`) |
| 2 | GND |  | power symbol `GND` |

#### R109 · 2.2k · ISET2: 0.45 A (USB_DET high)

| Pin | Net | Connects to | Draw |
|---|---|---|---|
| 1 | CHG_ISET2 | U103.12 (ISET2) | wire (or local label `CHG_ISET2`) |
| 2 | GND |  | power symbol `GND` |

#### R110 · 10k · NTC top a (IN to NTC), parallel with R111

| Pin | Net | Connects to | Draw |
|---|---|---|---|
| 1 | VIN_PROT | U102.1 (OUT), U102.2 (OUT), U102.3 (OUT), U103.2 (IN), R106.1, C102.1, C103.1, R111.1 | wire (or local label `VIN_PROT`) |
| 2 | CHG_NTC | U103.7 (NTC), J103.1 (Pin_1), R111.2, R112.1 | wire (or local label `CHG_NTC`) |

#### R111 · 33k · NTC top b: 10k || 33k = 7.67k

| Pin | Net | Connects to | Draw |
|---|---|---|---|
| 1 | VIN_PROT | U102.1 (OUT), U102.2 (OUT), U102.3 (OUT), U103.2 (IN), R106.1, C102.1, C103.1, R110.1 | wire (or local label `VIN_PROT`) |
| 2 | CHG_NTC | U103.7 (NTC), J103.1 (Pin_1), R110.2, R112.1 | wire (or local label `CHG_NTC`) |

#### R112 · 100k · NTC to GND (parallel with the 10k B3950 NTC): charge window 0-45 C

| Pin | Net | Connects to | Draw |
|---|---|---|---|
| 1 | CHG_NTC | U103.7 (NTC), J103.1 (Pin_1), R110.2, R111.2 | wire (or local label `CHG_NTC`) |
| 2 | GND |  | power symbol `GND` |

#### R113 · 100k · ENB pull-down: charging on without firmware

| Pin | Net | Connects to | Draw |
|---|---|---|---|
| 1 | CHG_EN_N | U103.6 (ENB); MCU sheet: U201.19 (IO15) | **global label `CHG_EN_N`** |
| 2 | GND |  | power symbol `GND` |

#### R114 · 10k · STAT pull-up to 3V3

| Pin | Net | Connects to | Draw |
|---|---|---|---|
| 1 | CHG_STAT | U103.9 (STAT); MCU sheet: U201.18 (IO14) | **global label `CHG_STAT`** |
| 2 | +3V3 |  | power symbol `+3V3` |

### Battery protection and sense

#### J102 · Battery 1x 21700 (holder with leads) · HAND-SOLDER, bottom. 1 B+, 2 B-

| Pin | Net | Connects to | Draw |
|---|---|---|---|
| 1 Pin_1 | VBAT | U103.14 (BATT), U103.16 (BATT), C106.1, R115.1, R117.1 | wire (or local label `VBAT`) |
| 2 Pin_2 | BAT_N | U104.6 (GND), Q101.2 (S1), Q101.3 (S1), C107.2 | wire (or local label `BAT_N`) |

#### J103 · NTC 10k B3950 (on the cell) · HAND-SOLDER, bottom. 1 NTC, 2 GND. No thermistor: fit a 10k resistor across it

| Pin | Net | Connects to | Draw |
|---|---|---|---|
| 1 Pin_1 | CHG_NTC | U103.7 (NTC), R110.2, R111.2, R112.1 | wire (or local label `CHG_NTC`) |
| 2 Pin_2 | GND |  | power symbol `GND` |

#### U104 · DW01A · cell protection

| Pin | Net | Connects to | Draw |
|---|---|---|---|
| 1 OD | DW_OD | Q101.4 (G1) | wire (or local label `DW_OD`) |
| 2 CS | DW_CS | R116.1 | wire (or local label `DW_CS`) |
| 3 OC | DW_OC | Q101.5 (G2) | wire (or local label `DW_OC`) |
| 4 TD | — | nothing | no-connect flag (X) |
| 5 VCC | DW_VCC | R115.2, C107.1 | wire (or local label `DW_VCC`) |
| 6 GND | BAT_N | J102.2 (Pin_2), Q101.2 (S1), Q101.3 (S1), C107.2 | wire (or local label `BAT_N`) |

#### Q101 · FS8205A · dual N-FET between B- and GND

| Pin | Net | Connects to | Draw |
|---|---|---|---|
| 1 D12 | FET_D | (only this part) | wire (or local label `FET_D`) |
| 2 S1 | BAT_N | J102.2 (Pin_2), U104.6 (GND), C107.2 | wire (or local label `BAT_N`) |
| 3 S1 | BAT_N | J102.2 (Pin_2), U104.6 (GND), C107.2 | wire (or local label `BAT_N`) |
| 4 G1 | DW_OD | U104.1 (OD) | wire (or local label `DW_OD`) |
| 5 G2 | DW_OC | U104.3 (OC) | wire (or local label `DW_OC`) |
| 6 S2 | GND |  | power symbol `GND` |
| 7 S2 | GND |  | power symbol `GND` |
| 8 D12 | FET_D | (only this part) | wire (or local label `FET_D`) |

#### R115 · 100 · DW01A VCC series (100 ohm; LCSC number at BOM time)

| Pin | Net | Connects to | Draw |
|---|---|---|---|
| 1 | VBAT | U103.14 (BATT), U103.16 (BATT), J102.1 (Pin_1), C106.1, R117.1 | wire (or local label `VBAT`) |
| 2 | DW_VCC | U104.5 (VCC), C107.1 | wire (or local label `DW_VCC`) |

#### C107 · 100nF · DW01A VCC

| Pin | Net | Connects to | Draw |
|---|---|---|---|
| 1 | DW_VCC | U104.5 (VCC), R115.2 | wire (or local label `DW_VCC`) |
| 2 | BAT_N | J102.2 (Pin_2), U104.6 (GND), Q101.2 (S1), Q101.3 (S1) | wire (or local label `BAT_N`) |

#### R116 · 1k · DW01A CS

| Pin | Net | Connects to | Draw |
|---|---|---|---|
| 1 | DW_CS | U104.2 (CS) | wire (or local label `DW_CS`) |
| 2 | GND |  | power symbol `GND` |

#### R117 · 100k · battery sense top (VBAT -> VBAT_SENSE, IO10)

| Pin | Net | Connects to | Draw |
|---|---|---|---|
| 1 | VBAT | U103.14 (BATT), U103.16 (BATT), J102.1 (Pin_1), C106.1, R115.1 | wire (or local label `VBAT`) |
| 2 | VBAT_SENSE | R118.1, C108.1; MCU sheet: U201.14 (IO10) | **global label `VBAT_SENSE`** |

#### R118 · 100k · battery sense bottom

| Pin | Net | Connects to | Draw |
|---|---|---|---|
| 1 | VBAT_SENSE | R117.2, C108.1; MCU sheet: U201.14 (IO10) | **global label `VBAT_SENSE`** |
| 2 | GND |  | power symbol `GND` |

#### C108 · 100nF · battery sense filter

| Pin | Net | Connects to | Draw |
|---|---|---|---|
| 1 | VBAT_SENSE | R117.2, R118.1; MCU sheet: U201.14 (IO10) | **global label `VBAT_SENSE`** |
| 2 | GND |  | power symbol `GND` |

### 3.3 V LDO (left strip, near the ESP32)

#### U105 · TLV75733PDBV · VSYS -> 3V3, EN tied to IN

| Pin | Net | Connects to | Draw |
|---|---|---|---|
| 1 IN | VSYS | U103.1 (SYS), U103.15 (SYS), L101.2, C104.1, C105.1, C109.1; RGB sheet: U401.3 (VIN), L401.1, C401.1 | **global label `VSYS`** |
| 2 GND | GND |  | power symbol `GND` |
| 3 EN | VSYS | U103.1 (SYS), U103.15 (SYS), L101.2, C104.1, C105.1, C109.1; RGB sheet: U401.3 (VIN), L401.1, C401.1 | **global label `VSYS`** |
| 4 NC | — | nothing | no-connect flag (X) |
| 5 OUT | +3V3 |  | power symbol `+3V3` |

#### C109 · 1uF · LDO input

| Pin | Net | Connects to | Draw |
|---|---|---|---|
| 1 | VSYS | U103.1 (SYS), U103.15 (SYS), L101.2, C104.1, C105.1, U105.1 (IN), U105.3 (EN); RGB sheet: U401.3 (VIN), L401.1, C401.1 | **global label `VSYS`** |
| 2 | GND |  | power symbol `GND` |

#### C110 · 1uF · LDO output

| Pin | Net | Connects to | Draw |
|---|---|---|---|
| 1 | +3V3 |  | power symbol `+3V3` |
| 2 | GND |  | power symbol `GND` |

### Mounting holes (M3)

#### H101 · M3 · (4.5, 38)

No pins (mechanical only).

#### H102 · M3 · (95.5, 38)

No pins (mechanical only).

#### H103 · M3 · (4.5, 66)

No pins (mechanical only).

#### H104 · M3 · (95.5, 80)

No pins (mechanical only).

#### H105 · M3 · (60, 93)

No pins (mechanical only).

---

## Sheet MCU

File `mcu.kicad_sch` · 11 parts

- Power symbols: `+3V3`, `GND`
- Global labels on this sheet: `CHG_EN_N`, `CHG_ISEL`, `CHG_STAT`, `DISP_BLK`, `DISP_CS`, `DISP_DC`, `DISP_EN_N`, `DISP_RES`, `DISP_SCL`, `DISP_SDA`, `ENC1_A`, `ENC1_B`, `ENC1_SW`, `ENC2_A`, `ENC2_B`, `ENC2_SW`, `KEY1`, `KEY10`, `KEY11`, `KEY12`, `KEY2`, `KEY3`, `KEY4`, `KEY5`, `KEY6`, `KEY7`, `KEY8`, `KEY9`, `PAD_RX`, `PAD_TX`, `RGB_DATA`, `RGB_EN`, `TGL_PERSONAL`, `TGL_WORK`, `VBAT_SENSE`, `VIN_SENSE`
- PWR_FLAG on: none
- No-connect flags: 5

### ESP32-S3-MINI-1 (front-left, antenna at the left edge)

#### U201 · ESP32-S3-MINI-1-N8 · position (9.50, 92.30), rotation 90

| Pin | Net | Connects to | Draw |
|---|---|---|---|
| 1 GND | GND |  | power symbol `GND` |
| 2 GND | GND |  | power symbol `GND` |
| 3 3V3 | +3V3 |  | power symbol `+3V3` |
| 4 IO0 | BOOT | SW202.1 | wire (or local label `BOOT`) |
| 5 IO1 | KEY2 | INPUTS sheet: SW302.1 | **global label `KEY2`** |
| 6 IO2 | KEY6 | INPUTS sheet: SW306.1 | **global label `KEY6`** |
| 7 IO3 | KEY10 | INPUTS sheet: SW310.1 | **global label `KEY10`** |
| 8 IO4 | KEY3 | INPUTS sheet: SW303.1 | **global label `KEY3`** |
| 9 IO5 | KEY7 | INPUTS sheet: SW307.1 | **global label `KEY7`** |
| 10 IO6 | KEY11 | INPUTS sheet: SW311.1 | **global label `KEY11`** |
| 11 IO7 | KEY4 | INPUTS sheet: SW304.1 | **global label `KEY4`** |
| 12 IO8 | KEY8 | INPUTS sheet: SW308.1 | **global label `KEY8`** |
| 13 IO9 | KEY12 | INPUTS sheet: SW312.1 | **global label `KEY12`** |
| 14 IO10 | VBAT_SENSE | POWER sheet: R117.2, R118.1, C108.1 | **global label `VBAT_SENSE`** |
| 15 IO11 | VIN_SENSE | POWER sheet: R106.2, R107.1 | **global label `VIN_SENSE`** |
| 16 IO12 | TGL_WORK | INPUTS sheet: J301.3 (Pin_3) | **global label `TGL_WORK`** |
| 17 IO13 | TGL_PERSONAL | INPUTS sheet: J301.1 (Pin_1) | **global label `TGL_PERSONAL`** |
| 18 IO14 | CHG_STAT | POWER sheet: U103.9 (STAT), R114.1 | **global label `CHG_STAT`** |
| 19 IO15 | CHG_EN_N | POWER sheet: U103.6 (ENB), R113.1 | **global label `CHG_EN_N`** |
| 20 IO16 | ENC2_SW | INPUTS sheet: SW314.S1 | **global label `ENC2_SW`** |
| 21 IO17 | ENC2_B | INPUTS sheet: R308.2, C304.1 | **global label `ENC2_B`** |
| 22 IO18 | ENC2_A | INPUTS sheet: R307.2, C303.1 | **global label `ENC2_A`** |
| 23 USB_D- | USB_DN | J201.A7 (D-), J201.B7 (D-), U202.3 (D2+) | wire (or local label `USB_DN`) |
| 24 USB_D+ | USB_DP | J201.A6 (D+), J201.B6 (D+), U202.1 (D1+) | wire (or local label `USB_DP`) |
| 25 IO21 | CHG_ISEL | POWER sheet: U103.13 (USB_DET) | **global label `CHG_ISEL`** |
| 26 IO26 | RGB_EN | RGB sheet: U401.2 (EN), R403.1 | **global label `RGB_EN`** |
| 27 IO47 | DISP_EN_N | DISPLAY sheet: Q501.1 (G), R501.1 | **global label `DISP_EN_N`** |
| 28 IO33 | DISP_SCL | DISPLAY sheet: J501.6 (Pin_6) | **global label `DISP_SCL`** |
| 29 IO34 | DISP_SDA | DISPLAY sheet: J501.5 (Pin_5) | **global label `DISP_SDA`** |
| 30 IO48 | DISP_RES | DISPLAY sheet: J501.4 (Pin_4) | **global label `DISP_RES`** |
| 31 IO35 | DISP_DC | DISPLAY sheet: J501.3 (Pin_3) | **global label `DISP_DC`** |
| 32 IO36 | DISP_CS | DISPLAY sheet: J501.2 (Pin_2) | **global label `DISP_CS`** |
| 33 IO37 | DISP_BLK | DISPLAY sheet: J501.1 (Pin_1) | **global label `DISP_BLK`** |
| 34 IO38 | KEY9 | INPUTS sheet: SW309.1 | **global label `KEY9`** |
| 35 IO39 | KEY5 | INPUTS sheet: SW305.1 | **global label `KEY5`** |
| 36 IO40 | KEY1 | INPUTS sheet: SW301.1 | **global label `KEY1`** |
| 37 IO41 | ENC1_B | INPUTS sheet: R304.2, C302.1 | **global label `ENC1_B`** |
| 38 IO42 | ENC1_A | INPUTS sheet: R303.2, C301.1 | **global label `ENC1_A`** |
| 39 TXD0 | PAD_TX | POWER sheet: R102.2 | **global label `PAD_TX`** |
| 40 RXD0 | PAD_RX | POWER sheet: R101.2 | **global label `PAD_RX`** |
| 41 IO45 | ENC1_SW | INPUTS sheet: SW313.S1 | **global label `ENC1_SW`** |
| 42 GND | GND |  | power symbol `GND` |
| 43 GND | GND |  | power symbol `GND` |
| 44 IO46 | RGB_DATA | RGB sheet: U402.2 | **global label `RGB_DATA`** |
| 45 EN | ESP_EN | R201.2, C203.1, SW201.1 | wire (or local label `ESP_EN`) |
| 46 GND | GND |  | power symbol `GND` |
| 47 GND | GND |  | power symbol `GND` |
| 48 GND | GND |  | power symbol `GND` |
| 49 GND | GND |  | power symbol `GND` |
| 50 GND | GND |  | power symbol `GND` |
| 51 GND | GND |  | power symbol `GND` |
| 52 GND | GND |  | power symbol `GND` |
| 53 GND | GND |  | power symbol `GND` |
| 54 GND | GND |  | power symbol `GND` |
| 55 GND | GND |  | power symbol `GND` |
| 56 GND | GND |  | power symbol `GND` |
| 57 GND | GND |  | power symbol `GND` |
| 58 GND | GND |  | power symbol `GND` |
| 59 GND | GND |  | power symbol `GND` |
| 60 GND | GND |  | power symbol `GND` |
| 61 GND | GND |  | power symbol `GND` |
| 62 GND | GND |  | power symbol `GND` |
| 63 GND | GND |  | power symbol `GND` |
| 64 GND | GND |  | power symbol `GND` |
| 65 GND | GND |  | power symbol `GND` |

#### C201 · 10uF · 3V3 at the module

| Pin | Net | Connects to | Draw |
|---|---|---|---|
| 1 | +3V3 |  | power symbol `+3V3` |
| 2 | GND |  | power symbol `GND` |

#### C202 · 100nF · 3V3 at the module

| Pin | Net | Connects to | Draw |
|---|---|---|---|
| 1 | +3V3 |  | power symbol `+3V3` |
| 2 | GND |  | power symbol `GND` |

### Reset and boot

#### R201 · 10k · EN pull-up

| Pin | Net | Connects to | Draw |
|---|---|---|---|
| 1 | +3V3 |  | power symbol `+3V3` |
| 2 | ESP_EN | U201.45 (EN), C203.1, SW201.1 | wire (or local label `ESP_EN`) |

#### C203 · 1uF · EN to GND (RC delay)

| Pin | Net | Connects to | Draw |
|---|---|---|---|
| 1 | ESP_EN | U201.45 (EN), R201.2, SW201.1 | wire (or local label `ESP_EN`) |
| 2 | GND |  | power symbol `GND` |

#### SW201 · SW_Push · RESET: EN to GND

| Pin | Net | Connects to | Draw |
|---|---|---|---|
| 1 | ESP_EN | U201.45 (EN), R201.2, C203.1 | wire (or local label `ESP_EN`) |
| 2 | GND |  | power symbol `GND` |

#### SW202 · SW_Push · BOOT: GPIO0 to GND

| Pin | Net | Connects to | Draw |
|---|---|---|---|
| 1 | BOOT | U201.4 (IO0) | wire (or local label `BOOT`) |
| 2 | GND |  | power symbol `GND` |

### USB-C (flashing / debug only, front edge next to the module)

#### J201 · TYPE-C-31-M-12 · FRONT edge, x = 27 (next to the module). D+/D- to IO20/IO19; VBUS pins joined, not used

| Pin | Net | Connects to | Draw |
|---|---|---|---|
| A1 GND | GND |  | power symbol `GND` |
| A4 VBUS | USB_VBUS | (only this part) | wire (or local label `USB_VBUS`) |
| A5 CC1 | USB_CC1 | R202.1 | wire (or local label `USB_CC1`) |
| A6 D+ | USB_DP | U201.24 (USB_D+), U202.1 (D1+) | wire (or local label `USB_DP`) |
| A7 D- | USB_DN | U201.23 (USB_D-), U202.3 (D2+) | wire (or local label `USB_DN`) |
| A8 SBU1 | — | nothing | no-connect flag (X) |
| A9 VBUS | USB_VBUS | (only this part) | wire (or local label `USB_VBUS`) |
| A12 GND | GND |  | power symbol `GND` |
| B1 GND | GND |  | power symbol `GND` |
| B4 VBUS | USB_VBUS | (only this part) | wire (or local label `USB_VBUS`) |
| B5 CC2 | USB_CC2 | R203.1 | wire (or local label `USB_CC2`) |
| B6 D+ | USB_DP | U201.24 (USB_D+), U202.1 (D1+) | wire (or local label `USB_DP`) |
| B7 D- | USB_DN | U201.23 (USB_D-), U202.3 (D2+) | wire (or local label `USB_DN`) |
| B8 SBU2 | — | nothing | no-connect flag (X) |
| B9 VBUS | USB_VBUS | (only this part) | wire (or local label `USB_VBUS`) |
| B12 GND | GND |  | power symbol `GND` |
| SH SHIELD | GND |  | power symbol `GND` |

#### U202 · TPD4E1U06DBVR · ESD on D+, D-

| Pin | Net | Connects to | Draw |
|---|---|---|---|
| 1 D1+ | USB_DP | U201.24 (USB_D+), J201.A6 (D+), J201.B6 (D+) | wire (or local label `USB_DP`) |
| 2 GND | GND |  | power symbol `GND` |
| 3 D2+ | USB_DN | U201.23 (USB_D-), J201.A7 (D-), J201.B7 (D-) | wire (or local label `USB_DN`) |
| 4 D2- | — | nothing | no-connect flag (X) |
| 5 NC | — | nothing | no-connect flag (X) |
| 6 D1- | — | nothing | no-connect flag (X) |

#### R202 · 5.1k · CC1 Rd

| Pin | Net | Connects to | Draw |
|---|---|---|---|
| 1 | USB_CC1 | J201.A5 (CC1) | wire (or local label `USB_CC1`) |
| 2 | GND |  | power symbol `GND` |

#### R203 · 5.1k · CC2 Rd

| Pin | Net | Connects to | Draw |
|---|---|---|---|
| 1 | USB_CC2 | J201.B5 (CC2) | wire (or local label `USB_CC2`) |
| 2 | GND |  | power symbol `GND` |

---

## Sheet INPUTS

File `inputs.kicad_sch` · 27 parts

- Power symbols: `+3V3`, `GND`
- Global labels on this sheet: `ENC1_A`, `ENC1_B`, `ENC1_SW`, `ENC2_A`, `ENC2_B`, `ENC2_SW`, `KEY1`, `KEY10`, `KEY11`, `KEY12`, `KEY2`, `KEY3`, `KEY4`, `KEY5`, `KEY6`, `KEY7`, `KEY8`, `KEY9`, `TGL_PERSONAL`, `TGL_WORK`
- PWR_FLAG on: none
- No-connect flags: 0

### Keys 1-12 (one GPIO each, other side to GND)

#### SW301 · MX switch (hot-swap socket) · key 1 -> IO40; socket HAND-SOLDER, bottom

| Pin | Net | Connects to | Draw |
|---|---|---|---|
| 1 | KEY1 | MCU sheet: U201.36 (IO40) | **global label `KEY1`** |
| 2 | GND |  | power symbol `GND` |

#### SW302 · MX switch (hot-swap socket) · key 2 -> IO1; socket HAND-SOLDER, bottom

| Pin | Net | Connects to | Draw |
|---|---|---|---|
| 1 | KEY2 | MCU sheet: U201.5 (IO1) | **global label `KEY2`** |
| 2 | GND |  | power symbol `GND` |

#### SW303 · MX switch (hot-swap socket) · key 3 -> IO4; socket HAND-SOLDER, bottom

| Pin | Net | Connects to | Draw |
|---|---|---|---|
| 1 | KEY3 | MCU sheet: U201.8 (IO4) | **global label `KEY3`** |
| 2 | GND |  | power symbol `GND` |

#### SW304 · MX switch (hot-swap socket) · key 4 -> IO7; socket HAND-SOLDER, bottom

| Pin | Net | Connects to | Draw |
|---|---|---|---|
| 1 | KEY4 | MCU sheet: U201.11 (IO7) | **global label `KEY4`** |
| 2 | GND |  | power symbol `GND` |

#### SW305 · MX switch (hot-swap socket) · key 5 -> IO39; socket HAND-SOLDER, bottom

| Pin | Net | Connects to | Draw |
|---|---|---|---|
| 1 | KEY5 | MCU sheet: U201.35 (IO39) | **global label `KEY5`** |
| 2 | GND |  | power symbol `GND` |

#### SW306 · MX switch (hot-swap socket) · key 6 -> IO2; socket HAND-SOLDER, bottom

| Pin | Net | Connects to | Draw |
|---|---|---|---|
| 1 | KEY6 | MCU sheet: U201.6 (IO2) | **global label `KEY6`** |
| 2 | GND |  | power symbol `GND` |

#### SW307 · MX switch (hot-swap socket) · key 7 -> IO5; socket HAND-SOLDER, bottom

| Pin | Net | Connects to | Draw |
|---|---|---|---|
| 1 | KEY7 | MCU sheet: U201.9 (IO5) | **global label `KEY7`** |
| 2 | GND |  | power symbol `GND` |

#### SW308 · MX switch (hot-swap socket) · key 8 -> IO8; socket HAND-SOLDER, bottom

| Pin | Net | Connects to | Draw |
|---|---|---|---|
| 1 | KEY8 | MCU sheet: U201.12 (IO8) | **global label `KEY8`** |
| 2 | GND |  | power symbol `GND` |

#### SW309 · MX switch (hot-swap socket) · key 9 -> IO38; socket HAND-SOLDER, bottom

| Pin | Net | Connects to | Draw |
|---|---|---|---|
| 1 | KEY9 | MCU sheet: U201.34 (IO38) | **global label `KEY9`** |
| 2 | GND |  | power symbol `GND` |

#### SW310 · MX switch (hot-swap socket) · key 10 -> IO3; socket HAND-SOLDER, bottom

| Pin | Net | Connects to | Draw |
|---|---|---|---|
| 1 | KEY10 | MCU sheet: U201.7 (IO3) | **global label `KEY10`** |
| 2 | GND |  | power symbol `GND` |

#### SW311 · MX switch (hot-swap socket) · key 11 -> IO6; socket HAND-SOLDER, bottom

| Pin | Net | Connects to | Draw |
|---|---|---|---|
| 1 | KEY11 | MCU sheet: U201.10 (IO6) | **global label `KEY11`** |
| 2 | GND |  | power symbol `GND` |

#### SW312 · MX switch (hot-swap socket) · key 12 -> IO9; socket HAND-SOLDER, bottom

| Pin | Net | Connects to | Draw |
|---|---|---|---|
| 1 | KEY12 | MCU sheet: U201.13 (IO9) | **global label `KEY12`** |
| 2 | GND |  | power symbol `GND` |

### Encoder 1: volume (left)

#### SW313 · PEC11R-4220F-S0024 · HAND-SOLDER. C, MP (lugs), S2 to GND; A/B via RC to IO42/IO41; S1 to IO45

| Pin | Net | Connects to | Draw |
|---|---|---|---|
| A | ENC1_A_RAW | R301.1, R303.1 | wire (or local label `ENC1_A_RAW`) |
| B | ENC1_B_RAW | R302.1, R304.1 | wire (or local label `ENC1_B_RAW`) |
| C | GND |  | power symbol `GND` |
| MP | GND |  | power symbol `GND` |
| S1 | ENC1_SW | MCU sheet: U201.41 (IO45) | **global label `ENC1_SW`** |
| S2 | GND |  | power symbol `GND` |

#### R301 · 10k · A pull-up to 3V3

| Pin | Net | Connects to | Draw |
|---|---|---|---|
| 1 | ENC1_A_RAW | SW313.A, R303.1 | wire (or local label `ENC1_A_RAW`) |
| 2 | +3V3 |  | power symbol `+3V3` |

#### R302 · 10k · B pull-up to 3V3

| Pin | Net | Connects to | Draw |
|---|---|---|---|
| 1 | ENC1_B_RAW | SW313.B, R304.1 | wire (or local label `ENC1_B_RAW`) |
| 2 | +3V3 |  | power symbol `+3V3` |

#### R303 · 10k · A series

| Pin | Net | Connects to | Draw |
|---|---|---|---|
| 1 | ENC1_A_RAW | SW313.A, R301.1 | wire (or local label `ENC1_A_RAW`) |
| 2 | ENC1_A | C301.1; MCU sheet: U201.38 (IO42) | **global label `ENC1_A`** |

#### R304 · 10k · B series

| Pin | Net | Connects to | Draw |
|---|---|---|---|
| 1 | ENC1_B_RAW | SW313.B, R302.1 | wire (or local label `ENC1_B_RAW`) |
| 2 | ENC1_B | C302.1; MCU sheet: U201.37 (IO41) | **global label `ENC1_B`** |

#### C301 · 10nF · A filter, GPIO side

| Pin | Net | Connects to | Draw |
|---|---|---|---|
| 1 | ENC1_A | R303.2; MCU sheet: U201.38 (IO42) | **global label `ENC1_A`** |
| 2 | GND |  | power symbol `GND` |

#### C302 · 10nF · B filter, GPIO side

| Pin | Net | Connects to | Draw |
|---|---|---|---|
| 1 | ENC1_B | R304.2; MCU sheet: U201.37 (IO41) | **global label `ENC1_B`** |
| 2 | GND |  | power symbol `GND` |

### Encoder 2: mic / call (right)

#### SW314 · PEC11R-4220F-S0024 · HAND-SOLDER. C, MP, S2 to GND; A/B via RC to IO18/IO17; S1 to IO16

| Pin | Net | Connects to | Draw |
|---|---|---|---|
| A | ENC2_A_RAW | R305.1, R307.1 | wire (or local label `ENC2_A_RAW`) |
| B | ENC2_B_RAW | R306.1, R308.1 | wire (or local label `ENC2_B_RAW`) |
| C | GND |  | power symbol `GND` |
| MP | GND |  | power symbol `GND` |
| S1 | ENC2_SW | MCU sheet: U201.20 (IO16) | **global label `ENC2_SW`** |
| S2 | GND |  | power symbol `GND` |

#### R305 · 10k · A pull-up to 3V3

| Pin | Net | Connects to | Draw |
|---|---|---|---|
| 1 | ENC2_A_RAW | SW314.A, R307.1 | wire (or local label `ENC2_A_RAW`) |
| 2 | +3V3 |  | power symbol `+3V3` |

#### R306 · 10k · B pull-up to 3V3

| Pin | Net | Connects to | Draw |
|---|---|---|---|
| 1 | ENC2_B_RAW | SW314.B, R308.1 | wire (or local label `ENC2_B_RAW`) |
| 2 | +3V3 |  | power symbol `+3V3` |

#### R307 · 10k · A series

| Pin | Net | Connects to | Draw |
|---|---|---|---|
| 1 | ENC2_A_RAW | SW314.A, R305.1 | wire (or local label `ENC2_A_RAW`) |
| 2 | ENC2_A | C303.1; MCU sheet: U201.22 (IO18) | **global label `ENC2_A`** |

#### R308 · 10k · B series

| Pin | Net | Connects to | Draw |
|---|---|---|---|
| 1 | ENC2_B_RAW | SW314.B, R306.1 | wire (or local label `ENC2_B_RAW`) |
| 2 | ENC2_B | C304.1; MCU sheet: U201.21 (IO17) | **global label `ENC2_B`** |

#### C303 · 10nF · A filter, GPIO side

| Pin | Net | Connects to | Draw |
|---|---|---|---|
| 1 | ENC2_A | R307.2; MCU sheet: U201.22 (IO18) | **global label `ENC2_A`** |
| 2 | GND |  | power symbol `GND` |

#### C304 · 10nF · B filter, GPIO side

| Pin | Net | Connects to | Draw |
|---|---|---|---|
| 1 | ENC2_B | R308.2; MCU sheet: U201.21 (IO17) | **global label `ENC2_B`** |
| 2 | GND |  | power symbol `GND` |

### Selector toggle (on the case)

#### J301 · Toggle PERSONAL-OFF-WORK · HAND-SOLDER, bottom. 1 PERSONAL (IO13), 2 GND (common), 3 WORK (IO12)

| Pin | Net | Connects to | Draw |
|---|---|---|---|
| 1 Pin_1 | TGL_PERSONAL | MCU sheet: U201.17 (IO13) | **global label `TGL_PERSONAL`** |
| 2 Pin_2 | GND |  | power symbol `GND` |
| 3 Pin_3 | TGL_WORK | MCU sheet: U201.16 (IO12) | **global label `TGL_WORK`** |

---

## Sheet RGB

File `rgb.kicad_sch` · 83 parts

- Power symbols: `GND`
- Global labels on this sheet: `RGB_DATA`, `RGB_EN`, `VSYS`
- PWR_FLAG on: `5V_RGB`
- No-connect flags: 1

### 5 V boost TPS61023 (power strip)

#### U401 · TPS61023DRLR · VSYS -> 5V_RGB; EN = RGB_EN (IO26), true disconnect when low

| Pin | Net | Connects to | Draw |
|---|---|---|---|
| 1 FB | BOOST_FB | R401.2, R402.1 | wire (or local label `BOOST_FB`) |
| 2 EN | RGB_EN | R403.1; MCU sheet: U201.26 (IO26) | **global label `RGB_EN`** |
| 3 VIN | VSYS | L401.1, C401.1; POWER sheet: U103.1 (SYS), U103.15 (SYS), L101.2, C104.1, C105.1, U105.1 (IN), U105.3 (EN), C109.1 | **global label `VSYS`** |
| 4 GND | GND |  | power symbol `GND` |
| 5 SW | BOOST_SW | L401.2 | wire (or local label `BOOST_SW`) |
| 6 VOUT | 5V_RGB | 77 other pins: use the label | wire (or local label `5V_RGB`) |

#### L401 · 1uH · XRNR4030-1uH/N, Isat 5.26 A

| Pin | Net | Connects to | Draw |
|---|---|---|---|
| 1 | VSYS | U401.3 (VIN), C401.1; POWER sheet: U103.1 (SYS), U103.15 (SYS), L101.2, C104.1, C105.1, U105.1 (IN), U105.3 (EN), C109.1 | **global label `VSYS`** |
| 2 | BOOST_SW | U401.5 (SW) | wire (or local label `BOOST_SW`) |

#### C401 · 10uF · boost input

| Pin | Net | Connects to | Draw |
|---|---|---|---|
| 1 | VSYS | U401.3 (VIN), L401.1; POWER sheet: U103.1 (SYS), U103.15 (SYS), L101.2, C104.1, C105.1, U105.1 (IN), U105.3 (EN), C109.1 | **global label `VSYS`** |
| 2 | GND |  | power symbol `GND` |

#### C402 · 22uF · 5V_RGB output

| Pin | Net | Connects to | Draw |
|---|---|---|---|
| 1 | 5V_RGB | 77 other pins: use the label | wire (or local label `5V_RGB`) |
| 2 | GND |  | power symbol `GND` |

#### C403 · 22uF · 5V_RGB output

| Pin | Net | Connects to | Draw |
|---|---|---|---|
| 1 | 5V_RGB | 77 other pins: use the label | wire (or local label `5V_RGB`) |
| 2 | GND |  | power symbol `GND` |

#### R401 · 51k · FB top: 0.595 x (1 + 51/6.8) = 5.06 V

| Pin | Net | Connects to | Draw |
|---|---|---|---|
| 1 | 5V_RGB | 77 other pins: use the label | wire (or local label `5V_RGB`) |
| 2 | BOOST_FB | U401.1 (FB), R402.1 | wire (or local label `BOOST_FB`) |

#### R402 · 6.8k · FB bottom

| Pin | Net | Connects to | Draw |
|---|---|---|---|
| 1 | BOOST_FB | U401.1 (FB), R401.2 | wire (or local label `BOOST_FB`) |
| 2 | GND |  | power symbol `GND` |

#### R403 · 100k · EN pull-down (LEDs off at reset)

| Pin | Net | Connects to | Draw |
|---|---|---|---|
| 1 | RGB_EN | U401.2 (EN); MCU sheet: U201.26 (IO26) | **global label `RGB_EN`** |
| 2 | GND |  | power symbol `GND` |

### Data level shifter

#### U402 · SN74AHCT1G125DBVR · input RGB_DATA (IO46); powered from 5V_RGB; OE (pin 1) to GND; place near the ESP32 / key 9

| Pin | Net | Connects to | Draw |
|---|---|---|---|
| 1 | GND |  | power symbol `GND` |
| 2 | RGB_DATA | MCU sheet: U201.44 (IO46) | **global label `RGB_DATA`** |
| 3 GND | GND |  | power symbol `GND` |
| 4 | RGB_DATA_5V | R404.1 | wire (or local label `RGB_DATA_5V`) |
| 5 VCC | 5V_RGB | 77 other pins: use the label | wire (or local label `5V_RGB`) |

#### C404 · 100nF · U402 VCC

| Pin | Net | Connects to | Draw |
|---|---|---|---|
| 1 | 5V_RGB | 77 other pins: use the label | wire (or local label `5V_RGB`) |
| 2 | GND |  | power symbol `GND` |

#### R404 · 33 · series, U402 output to D401 DIN (key 9 LED)

| Pin | Net | Connects to | Draw |
|---|---|---|---|
| 1 | RGB_DATA_5V | U402.4 | wire (or local label `RGB_DATA_5V`) |
| 2 | LED_D0 | D401.2 (DIN) | wire (or local label `LED_D0`) |

### Key LEDs: keys 9, 10, 11, 12 (chain starts here)

#### D401 · SK6812MINI-E · chain index 0: key 9 (bottom side, HAND-SOLDER)

| Pin | Net | Connects to | Draw |
|---|---|---|---|
| 1 VSS | GND |  | power symbol `GND` |
| 2 DIN | LED_D0 | R404.2 | wire (or local label `LED_D0`) |
| 3 VDD | 5V_RGB | 77 other pins: use the label | wire (or local label `5V_RGB`) |
| 4 DOUT | LED_D1 | D402.2 (DIN) | wire (or local label `LED_D1`) |

#### C405 · 100nF · at D401 VDD (top side)

| Pin | Net | Connects to | Draw |
|---|---|---|---|
| 1 | 5V_RGB | 77 other pins: use the label | wire (or local label `5V_RGB`) |
| 2 | GND |  | power symbol `GND` |

#### D402 · SK6812MINI-E · chain index 1: key 10 (bottom side, HAND-SOLDER)

| Pin | Net | Connects to | Draw |
|---|---|---|---|
| 1 VSS | GND |  | power symbol `GND` |
| 2 DIN | LED_D1 | D401.4 (DOUT) | wire (or local label `LED_D1`) |
| 3 VDD | 5V_RGB | 77 other pins: use the label | wire (or local label `5V_RGB`) |
| 4 DOUT | LED_D2 | D403.2 (DIN) | wire (or local label `LED_D2`) |

#### C406 · 100nF · at D402 VDD (top side)

| Pin | Net | Connects to | Draw |
|---|---|---|---|
| 1 | 5V_RGB | 77 other pins: use the label | wire (or local label `5V_RGB`) |
| 2 | GND |  | power symbol `GND` |

#### D403 · SK6812MINI-E · chain index 2: key 11 (bottom side, HAND-SOLDER)

| Pin | Net | Connects to | Draw |
|---|---|---|---|
| 1 VSS | GND |  | power symbol `GND` |
| 2 DIN | LED_D2 | D402.4 (DOUT) | wire (or local label `LED_D2`) |
| 3 VDD | 5V_RGB | 77 other pins: use the label | wire (or local label `5V_RGB`) |
| 4 DOUT | LED_D3 | D404.2 (DIN) | wire (or local label `LED_D3`) |

#### C407 · 100nF · at D403 VDD (top side)

| Pin | Net | Connects to | Draw |
|---|---|---|---|
| 1 | 5V_RGB | 77 other pins: use the label | wire (or local label `5V_RGB`) |
| 2 | GND |  | power symbol `GND` |

#### D404 · SK6812MINI-E · chain index 3: key 12 (bottom side, HAND-SOLDER)

| Pin | Net | Connects to | Draw |
|---|---|---|---|
| 1 VSS | GND |  | power symbol `GND` |
| 2 DIN | LED_D3 | D403.4 (DOUT) | wire (or local label `LED_D3`) |
| 3 VDD | 5V_RGB | 77 other pins: use the label | wire (or local label `5V_RGB`) |
| 4 DOUT | LED_D4 | D405.2 (DIN) | wire (or local label `LED_D4`) |

#### C408 · 100nF · at D404 VDD (top side)

| Pin | Net | Connects to | Draw |
|---|---|---|---|
| 1 | 5V_RGB | 77 other pins: use the label | wire (or local label `5V_RGB`) |
| 2 | GND |  | power symbol `GND` |

### Key LEDs: keys 8, 7, 6, 5

#### D405 · SK6812MINI-E · chain index 4: key 8 (bottom side, HAND-SOLDER)

| Pin | Net | Connects to | Draw |
|---|---|---|---|
| 1 VSS | GND |  | power symbol `GND` |
| 2 DIN | LED_D4 | D404.4 (DOUT) | wire (or local label `LED_D4`) |
| 3 VDD | 5V_RGB | 77 other pins: use the label | wire (or local label `5V_RGB`) |
| 4 DOUT | LED_D5 | D406.2 (DIN) | wire (or local label `LED_D5`) |

#### C409 · 100nF · at D405 VDD (top side)

| Pin | Net | Connects to | Draw |
|---|---|---|---|
| 1 | 5V_RGB | 77 other pins: use the label | wire (or local label `5V_RGB`) |
| 2 | GND |  | power symbol `GND` |

#### D406 · SK6812MINI-E · chain index 5: key 7 (bottom side, HAND-SOLDER)

| Pin | Net | Connects to | Draw |
|---|---|---|---|
| 1 VSS | GND |  | power symbol `GND` |
| 2 DIN | LED_D5 | D405.4 (DOUT) | wire (or local label `LED_D5`) |
| 3 VDD | 5V_RGB | 77 other pins: use the label | wire (or local label `5V_RGB`) |
| 4 DOUT | LED_D6 | D407.2 (DIN) | wire (or local label `LED_D6`) |

#### C410 · 100nF · at D406 VDD (top side)

| Pin | Net | Connects to | Draw |
|---|---|---|---|
| 1 | 5V_RGB | 77 other pins: use the label | wire (or local label `5V_RGB`) |
| 2 | GND |  | power symbol `GND` |

#### D407 · SK6812MINI-E · chain index 6: key 6 (bottom side, HAND-SOLDER)

| Pin | Net | Connects to | Draw |
|---|---|---|---|
| 1 VSS | GND |  | power symbol `GND` |
| 2 DIN | LED_D6 | D406.4 (DOUT) | wire (or local label `LED_D6`) |
| 3 VDD | 5V_RGB | 77 other pins: use the label | wire (or local label `5V_RGB`) |
| 4 DOUT | LED_D7 | D408.2 (DIN) | wire (or local label `LED_D7`) |

#### C411 · 100nF · at D407 VDD (top side)

| Pin | Net | Connects to | Draw |
|---|---|---|---|
| 1 | 5V_RGB | 77 other pins: use the label | wire (or local label `5V_RGB`) |
| 2 | GND |  | power symbol `GND` |

#### D408 · SK6812MINI-E · chain index 7: key 5 (bottom side, HAND-SOLDER)

| Pin | Net | Connects to | Draw |
|---|---|---|---|
| 1 VSS | GND |  | power symbol `GND` |
| 2 DIN | LED_D7 | D407.4 (DOUT) | wire (or local label `LED_D7`) |
| 3 VDD | 5V_RGB | 77 other pins: use the label | wire (or local label `5V_RGB`) |
| 4 DOUT | LED_D8 | D409.2 (DIN) | wire (or local label `LED_D8`) |

#### C412 · 100nF · at D408 VDD (top side)

| Pin | Net | Connects to | Draw |
|---|---|---|---|
| 1 | 5V_RGB | 77 other pins: use the label | wire (or local label `5V_RGB`) |
| 2 | GND |  | power symbol `GND` |

### Key LEDs: keys 1, 2, 3, 4

#### D409 · SK6812MINI-E · chain index 8: key 1 (bottom side, HAND-SOLDER)

| Pin | Net | Connects to | Draw |
|---|---|---|---|
| 1 VSS | GND |  | power symbol `GND` |
| 2 DIN | LED_D8 | D408.4 (DOUT) | wire (or local label `LED_D8`) |
| 3 VDD | 5V_RGB | 77 other pins: use the label | wire (or local label `5V_RGB`) |
| 4 DOUT | LED_D9 | D410.2 (DIN) | wire (or local label `LED_D9`) |

#### C413 · 100nF · at D409 VDD (top side)

| Pin | Net | Connects to | Draw |
|---|---|---|---|
| 1 | 5V_RGB | 77 other pins: use the label | wire (or local label `5V_RGB`) |
| 2 | GND |  | power symbol `GND` |

#### D410 · SK6812MINI-E · chain index 9: key 2 (bottom side, HAND-SOLDER)

| Pin | Net | Connects to | Draw |
|---|---|---|---|
| 1 VSS | GND |  | power symbol `GND` |
| 2 DIN | LED_D9 | D409.4 (DOUT) | wire (or local label `LED_D9`) |
| 3 VDD | 5V_RGB | 77 other pins: use the label | wire (or local label `5V_RGB`) |
| 4 DOUT | LED_D10 | D411.2 (DIN) | wire (or local label `LED_D10`) |

#### C414 · 100nF · at D410 VDD (top side)

| Pin | Net | Connects to | Draw |
|---|---|---|---|
| 1 | 5V_RGB | 77 other pins: use the label | wire (or local label `5V_RGB`) |
| 2 | GND |  | power symbol `GND` |

#### D411 · SK6812MINI-E · chain index 10: key 3 (bottom side, HAND-SOLDER)

| Pin | Net | Connects to | Draw |
|---|---|---|---|
| 1 VSS | GND |  | power symbol `GND` |
| 2 DIN | LED_D10 | D410.4 (DOUT) | wire (or local label `LED_D10`) |
| 3 VDD | 5V_RGB | 77 other pins: use the label | wire (or local label `5V_RGB`) |
| 4 DOUT | LED_D11 | D412.2 (DIN) | wire (or local label `LED_D11`) |

#### C415 · 100nF · at D411 VDD (top side)

| Pin | Net | Connects to | Draw |
|---|---|---|---|
| 1 | 5V_RGB | 77 other pins: use the label | wire (or local label `5V_RGB`) |
| 2 | GND |  | power symbol `GND` |

#### D412 · SK6812MINI-E · chain index 11: key 4 (bottom side, HAND-SOLDER)

| Pin | Net | Connects to | Draw |
|---|---|---|---|
| 1 VSS | GND |  | power symbol `GND` |
| 2 DIN | LED_D11 | D411.4 (DOUT) | wire (or local label `LED_D11`) |
| 3 VDD | 5V_RGB | 77 other pins: use the label | wire (or local label `5V_RGB`) |
| 4 DOUT | LED_D12 | D413.3 (DIN) | wire (or local label `LED_D12`) |

#### C416 · 100nF · at D412 VDD (top side)

| Pin | Net | Connects to | Draw |
|---|---|---|---|
| 1 | 5V_RGB | 77 other pins: use the label | wire (or local label `5V_RGB`) |
| 2 | GND |  | power symbol `GND` |

### Ring 2 (ENC2), counter-clockwise from 7 o'clock

#### D413 · XL-2020RGBC-WS2812B · chain index 12: ring 2, 7 o'clock

| Pin | Net | Connects to | Draw |
|---|---|---|---|
| 1 DOUT | LED_D13 | D414.3 (DIN) | wire (or local label `LED_D13`) |
| 2 VSS | GND |  | power symbol `GND` |
| 3 DIN | LED_D12 | D412.4 (DOUT) | wire (or local label `LED_D12`) |
| 4 VDD | 5V_RGB | 77 other pins: use the label | wire (or local label `5V_RGB`) |

#### C417 · 100nF · at D413 VDD (top side)

| Pin | Net | Connects to | Draw |
|---|---|---|---|
| 1 | 5V_RGB | 77 other pins: use the label | wire (or local label `5V_RGB`) |
| 2 | GND |  | power symbol `GND` |

#### D414 · XL-2020RGBC-WS2812B · chain index 13: ring 2, 6 o'clock

| Pin | Net | Connects to | Draw |
|---|---|---|---|
| 1 DOUT | LED_D14 | D415.3 (DIN) | wire (or local label `LED_D14`) |
| 2 VSS | GND |  | power symbol `GND` |
| 3 DIN | LED_D13 | D413.1 (DOUT) | wire (or local label `LED_D13`) |
| 4 VDD | 5V_RGB | 77 other pins: use the label | wire (or local label `5V_RGB`) |

#### C418 · 100nF · at D414 VDD (top side)

| Pin | Net | Connects to | Draw |
|---|---|---|---|
| 1 | 5V_RGB | 77 other pins: use the label | wire (or local label `5V_RGB`) |
| 2 | GND |  | power symbol `GND` |

#### D415 · XL-2020RGBC-WS2812B · chain index 14: ring 2, 5 o'clock

| Pin | Net | Connects to | Draw |
|---|---|---|---|
| 1 DOUT | LED_D15 | D416.3 (DIN) | wire (or local label `LED_D15`) |
| 2 VSS | GND |  | power symbol `GND` |
| 3 DIN | LED_D14 | D414.1 (DOUT) | wire (or local label `LED_D14`) |
| 4 VDD | 5V_RGB | 77 other pins: use the label | wire (or local label `5V_RGB`) |

#### C419 · 100nF · at D415 VDD (top side)

| Pin | Net | Connects to | Draw |
|---|---|---|---|
| 1 | 5V_RGB | 77 other pins: use the label | wire (or local label `5V_RGB`) |
| 2 | GND |  | power symbol `GND` |

#### D416 · XL-2020RGBC-WS2812B · chain index 15: ring 2, 4 o'clock

| Pin | Net | Connects to | Draw |
|---|---|---|---|
| 1 DOUT | LED_D16 | D417.3 (DIN) | wire (or local label `LED_D16`) |
| 2 VSS | GND |  | power symbol `GND` |
| 3 DIN | LED_D15 | D415.1 (DOUT) | wire (or local label `LED_D15`) |
| 4 VDD | 5V_RGB | 77 other pins: use the label | wire (or local label `5V_RGB`) |

#### C420 · 100nF · at D416 VDD (top side)

| Pin | Net | Connects to | Draw |
|---|---|---|---|
| 1 | 5V_RGB | 77 other pins: use the label | wire (or local label `5V_RGB`) |
| 2 | GND |  | power symbol `GND` |

#### D417 · XL-2020RGBC-WS2812B · chain index 16: ring 2, 3 o'clock

| Pin | Net | Connects to | Draw |
|---|---|---|---|
| 1 DOUT | LED_D17 | D418.3 (DIN) | wire (or local label `LED_D17`) |
| 2 VSS | GND |  | power symbol `GND` |
| 3 DIN | LED_D16 | D416.1 (DOUT) | wire (or local label `LED_D16`) |
| 4 VDD | 5V_RGB | 77 other pins: use the label | wire (or local label `5V_RGB`) |

#### C421 · 100nF · at D417 VDD (top side)

| Pin | Net | Connects to | Draw |
|---|---|---|---|
| 1 | 5V_RGB | 77 other pins: use the label | wire (or local label `5V_RGB`) |
| 2 | GND |  | power symbol `GND` |

#### D418 · XL-2020RGBC-WS2812B · chain index 17: ring 2, 2 o'clock

| Pin | Net | Connects to | Draw |
|---|---|---|---|
| 1 DOUT | LED_D18 | D419.3 (DIN) | wire (or local label `LED_D18`) |
| 2 VSS | GND |  | power symbol `GND` |
| 3 DIN | LED_D17 | D417.1 (DOUT) | wire (or local label `LED_D17`) |
| 4 VDD | 5V_RGB | 77 other pins: use the label | wire (or local label `5V_RGB`) |

#### C422 · 100nF · at D418 VDD (top side)

| Pin | Net | Connects to | Draw |
|---|---|---|---|
| 1 | 5V_RGB | 77 other pins: use the label | wire (or local label `5V_RGB`) |
| 2 | GND |  | power symbol `GND` |

#### D419 · XL-2020RGBC-WS2812B · chain index 18: ring 2, 1 o'clock

| Pin | Net | Connects to | Draw |
|---|---|---|---|
| 1 DOUT | LED_D19 | D420.3 (DIN) | wire (or local label `LED_D19`) |
| 2 VSS | GND |  | power symbol `GND` |
| 3 DIN | LED_D18 | D418.1 (DOUT) | wire (or local label `LED_D18`) |
| 4 VDD | 5V_RGB | 77 other pins: use the label | wire (or local label `5V_RGB`) |

#### C423 · 100nF · at D419 VDD (top side)

| Pin | Net | Connects to | Draw |
|---|---|---|---|
| 1 | 5V_RGB | 77 other pins: use the label | wire (or local label `5V_RGB`) |
| 2 | GND |  | power symbol `GND` |

#### D420 · XL-2020RGBC-WS2812B · chain index 19: ring 2, 12 o'clock

| Pin | Net | Connects to | Draw |
|---|---|---|---|
| 1 DOUT | LED_D20 | D421.3 (DIN) | wire (or local label `LED_D20`) |
| 2 VSS | GND |  | power symbol `GND` |
| 3 DIN | LED_D19 | D419.1 (DOUT) | wire (or local label `LED_D19`) |
| 4 VDD | 5V_RGB | 77 other pins: use the label | wire (or local label `5V_RGB`) |

#### C424 · 100nF · at D420 VDD (top side)

| Pin | Net | Connects to | Draw |
|---|---|---|---|
| 1 | 5V_RGB | 77 other pins: use the label | wire (or local label `5V_RGB`) |
| 2 | GND |  | power symbol `GND` |

#### D421 · XL-2020RGBC-WS2812B · chain index 20: ring 2, 11 o'clock

| Pin | Net | Connects to | Draw |
|---|---|---|---|
| 1 DOUT | LED_D21 | D422.3 (DIN) | wire (or local label `LED_D21`) |
| 2 VSS | GND |  | power symbol `GND` |
| 3 DIN | LED_D20 | D420.1 (DOUT) | wire (or local label `LED_D20`) |
| 4 VDD | 5V_RGB | 77 other pins: use the label | wire (or local label `5V_RGB`) |

#### C425 · 100nF · at D421 VDD (top side)

| Pin | Net | Connects to | Draw |
|---|---|---|---|
| 1 | 5V_RGB | 77 other pins: use the label | wire (or local label `5V_RGB`) |
| 2 | GND |  | power symbol `GND` |

#### D422 · XL-2020RGBC-WS2812B · chain index 21: ring 2, 10 o'clock

| Pin | Net | Connects to | Draw |
|---|---|---|---|
| 1 DOUT | LED_D22 | D423.3 (DIN) | wire (or local label `LED_D22`) |
| 2 VSS | GND |  | power symbol `GND` |
| 3 DIN | LED_D21 | D421.1 (DOUT) | wire (or local label `LED_D21`) |
| 4 VDD | 5V_RGB | 77 other pins: use the label | wire (or local label `5V_RGB`) |

#### C426 · 100nF · at D422 VDD (top side)

| Pin | Net | Connects to | Draw |
|---|---|---|---|
| 1 | 5V_RGB | 77 other pins: use the label | wire (or local label `5V_RGB`) |
| 2 | GND |  | power symbol `GND` |

#### D423 · XL-2020RGBC-WS2812B · chain index 22: ring 2, 9 o'clock

| Pin | Net | Connects to | Draw |
|---|---|---|---|
| 1 DOUT | LED_D23 | D424.3 (DIN) | wire (or local label `LED_D23`) |
| 2 VSS | GND |  | power symbol `GND` |
| 3 DIN | LED_D22 | D422.1 (DOUT) | wire (or local label `LED_D22`) |
| 4 VDD | 5V_RGB | 77 other pins: use the label | wire (or local label `5V_RGB`) |

#### C427 · 100nF · at D423 VDD (top side)

| Pin | Net | Connects to | Draw |
|---|---|---|---|
| 1 | 5V_RGB | 77 other pins: use the label | wire (or local label `5V_RGB`) |
| 2 | GND |  | power symbol `GND` |

#### D424 · XL-2020RGBC-WS2812B · chain index 23: ring 2, 8 o'clock

| Pin | Net | Connects to | Draw |
|---|---|---|---|
| 1 DOUT | LED_D24 | D425.3 (DIN) | wire (or local label `LED_D24`) |
| 2 VSS | GND |  | power symbol `GND` |
| 3 DIN | LED_D23 | D423.1 (DOUT) | wire (or local label `LED_D23`) |
| 4 VDD | 5V_RGB | 77 other pins: use the label | wire (or local label `5V_RGB`) |

#### C428 · 100nF · at D424 VDD (top side)

| Pin | Net | Connects to | Draw |
|---|---|---|---|
| 1 | 5V_RGB | 77 other pins: use the label | wire (or local label `5V_RGB`) |
| 2 | GND |  | power symbol `GND` |

### Ring 1 (ENC1), counter-clockwise from 4 o'clock

#### D425 · XL-2020RGBC-WS2812B · chain index 24: ring 1, 4 o'clock

| Pin | Net | Connects to | Draw |
|---|---|---|---|
| 1 DOUT | LED_D25 | D426.3 (DIN) | wire (or local label `LED_D25`) |
| 2 VSS | GND |  | power symbol `GND` |
| 3 DIN | LED_D24 | D424.1 (DOUT) | wire (or local label `LED_D24`) |
| 4 VDD | 5V_RGB | 77 other pins: use the label | wire (or local label `5V_RGB`) |

#### C429 · 100nF · at D425 VDD (top side)

| Pin | Net | Connects to | Draw |
|---|---|---|---|
| 1 | 5V_RGB | 77 other pins: use the label | wire (or local label `5V_RGB`) |
| 2 | GND |  | power symbol `GND` |

#### D426 · XL-2020RGBC-WS2812B · chain index 25: ring 1, 3 o'clock

| Pin | Net | Connects to | Draw |
|---|---|---|---|
| 1 DOUT | LED_D26 | D427.3 (DIN) | wire (or local label `LED_D26`) |
| 2 VSS | GND |  | power symbol `GND` |
| 3 DIN | LED_D25 | D425.1 (DOUT) | wire (or local label `LED_D25`) |
| 4 VDD | 5V_RGB | 77 other pins: use the label | wire (or local label `5V_RGB`) |

#### C430 · 100nF · at D426 VDD (top side)

| Pin | Net | Connects to | Draw |
|---|---|---|---|
| 1 | 5V_RGB | 77 other pins: use the label | wire (or local label `5V_RGB`) |
| 2 | GND |  | power symbol `GND` |

#### D427 · XL-2020RGBC-WS2812B · chain index 26: ring 1, 2 o'clock

| Pin | Net | Connects to | Draw |
|---|---|---|---|
| 1 DOUT | LED_D27 | D428.3 (DIN) | wire (or local label `LED_D27`) |
| 2 VSS | GND |  | power symbol `GND` |
| 3 DIN | LED_D26 | D426.1 (DOUT) | wire (or local label `LED_D26`) |
| 4 VDD | 5V_RGB | 77 other pins: use the label | wire (or local label `5V_RGB`) |

#### C431 · 100nF · at D427 VDD (top side)

| Pin | Net | Connects to | Draw |
|---|---|---|---|
| 1 | 5V_RGB | 77 other pins: use the label | wire (or local label `5V_RGB`) |
| 2 | GND |  | power symbol `GND` |

#### D428 · XL-2020RGBC-WS2812B · chain index 27: ring 1, 1 o'clock

| Pin | Net | Connects to | Draw |
|---|---|---|---|
| 1 DOUT | LED_D28 | D429.3 (DIN) | wire (or local label `LED_D28`) |
| 2 VSS | GND |  | power symbol `GND` |
| 3 DIN | LED_D27 | D427.1 (DOUT) | wire (or local label `LED_D27`) |
| 4 VDD | 5V_RGB | 77 other pins: use the label | wire (or local label `5V_RGB`) |

#### C432 · 100nF · at D428 VDD (top side)

| Pin | Net | Connects to | Draw |
|---|---|---|---|
| 1 | 5V_RGB | 77 other pins: use the label | wire (or local label `5V_RGB`) |
| 2 | GND |  | power symbol `GND` |

#### D429 · XL-2020RGBC-WS2812B · chain index 28: ring 1, 12 o'clock

| Pin | Net | Connects to | Draw |
|---|---|---|---|
| 1 DOUT | LED_D29 | D430.3 (DIN) | wire (or local label `LED_D29`) |
| 2 VSS | GND |  | power symbol `GND` |
| 3 DIN | LED_D28 | D428.1 (DOUT) | wire (or local label `LED_D28`) |
| 4 VDD | 5V_RGB | 77 other pins: use the label | wire (or local label `5V_RGB`) |

#### C433 · 100nF · at D429 VDD (top side)

| Pin | Net | Connects to | Draw |
|---|---|---|---|
| 1 | 5V_RGB | 77 other pins: use the label | wire (or local label `5V_RGB`) |
| 2 | GND |  | power symbol `GND` |

#### D430 · XL-2020RGBC-WS2812B · chain index 29: ring 1, 11 o'clock

| Pin | Net | Connects to | Draw |
|---|---|---|---|
| 1 DOUT | LED_D30 | D431.3 (DIN) | wire (or local label `LED_D30`) |
| 2 VSS | GND |  | power symbol `GND` |
| 3 DIN | LED_D29 | D429.1 (DOUT) | wire (or local label `LED_D29`) |
| 4 VDD | 5V_RGB | 77 other pins: use the label | wire (or local label `5V_RGB`) |

#### C434 · 100nF · at D430 VDD (top side)

| Pin | Net | Connects to | Draw |
|---|---|---|---|
| 1 | 5V_RGB | 77 other pins: use the label | wire (or local label `5V_RGB`) |
| 2 | GND |  | power symbol `GND` |

#### D431 · XL-2020RGBC-WS2812B · chain index 30: ring 1, 10 o'clock

| Pin | Net | Connects to | Draw |
|---|---|---|---|
| 1 DOUT | LED_D31 | D432.3 (DIN) | wire (or local label `LED_D31`) |
| 2 VSS | GND |  | power symbol `GND` |
| 3 DIN | LED_D30 | D430.1 (DOUT) | wire (or local label `LED_D30`) |
| 4 VDD | 5V_RGB | 77 other pins: use the label | wire (or local label `5V_RGB`) |

#### C435 · 100nF · at D431 VDD (top side)

| Pin | Net | Connects to | Draw |
|---|---|---|---|
| 1 | 5V_RGB | 77 other pins: use the label | wire (or local label `5V_RGB`) |
| 2 | GND |  | power symbol `GND` |

#### D432 · XL-2020RGBC-WS2812B · chain index 31: ring 1, 9 o'clock

| Pin | Net | Connects to | Draw |
|---|---|---|---|
| 1 DOUT | LED_D32 | D433.3 (DIN) | wire (or local label `LED_D32`) |
| 2 VSS | GND |  | power symbol `GND` |
| 3 DIN | LED_D31 | D431.1 (DOUT) | wire (or local label `LED_D31`) |
| 4 VDD | 5V_RGB | 77 other pins: use the label | wire (or local label `5V_RGB`) |

#### C436 · 100nF · at D432 VDD (top side)

| Pin | Net | Connects to | Draw |
|---|---|---|---|
| 1 | 5V_RGB | 77 other pins: use the label | wire (or local label `5V_RGB`) |
| 2 | GND |  | power symbol `GND` |

#### D433 · XL-2020RGBC-WS2812B · chain index 32: ring 1, 8 o'clock

| Pin | Net | Connects to | Draw |
|---|---|---|---|
| 1 DOUT | LED_D33 | D434.3 (DIN) | wire (or local label `LED_D33`) |
| 2 VSS | GND |  | power symbol `GND` |
| 3 DIN | LED_D32 | D432.1 (DOUT) | wire (or local label `LED_D32`) |
| 4 VDD | 5V_RGB | 77 other pins: use the label | wire (or local label `5V_RGB`) |

#### C437 · 100nF · at D433 VDD (top side)

| Pin | Net | Connects to | Draw |
|---|---|---|---|
| 1 | 5V_RGB | 77 other pins: use the label | wire (or local label `5V_RGB`) |
| 2 | GND |  | power symbol `GND` |

#### D434 · XL-2020RGBC-WS2812B · chain index 33: ring 1, 7 o'clock

| Pin | Net | Connects to | Draw |
|---|---|---|---|
| 1 DOUT | LED_D34 | D435.3 (DIN) | wire (or local label `LED_D34`) |
| 2 VSS | GND |  | power symbol `GND` |
| 3 DIN | LED_D33 | D433.1 (DOUT) | wire (or local label `LED_D33`) |
| 4 VDD | 5V_RGB | 77 other pins: use the label | wire (or local label `5V_RGB`) |

#### C438 · 100nF · at D434 VDD (top side)

| Pin | Net | Connects to | Draw |
|---|---|---|---|
| 1 | 5V_RGB | 77 other pins: use the label | wire (or local label `5V_RGB`) |
| 2 | GND |  | power symbol `GND` |

#### D435 · XL-2020RGBC-WS2812B · chain index 34: ring 1, 6 o'clock

| Pin | Net | Connects to | Draw |
|---|---|---|---|
| 1 DOUT | LED_D35 | D436.3 (DIN) | wire (or local label `LED_D35`) |
| 2 VSS | GND |  | power symbol `GND` |
| 3 DIN | LED_D34 | D434.1 (DOUT) | wire (or local label `LED_D34`) |
| 4 VDD | 5V_RGB | 77 other pins: use the label | wire (or local label `5V_RGB`) |

#### C439 · 100nF · at D435 VDD (top side)

| Pin | Net | Connects to | Draw |
|---|---|---|---|
| 1 | 5V_RGB | 77 other pins: use the label | wire (or local label `5V_RGB`) |
| 2 | GND |  | power symbol `GND` |

#### D436 · XL-2020RGBC-WS2812B · chain index 35: ring 1, 5 o'clock

| Pin | Net | Connects to | Draw |
|---|---|---|---|
| 1 DOUT | — | nothing | no-connect flag (X) |
| 2 VSS | GND |  | power symbol `GND` |
| 3 DIN | LED_D35 | D435.1 (DOUT) | wire (or local label `LED_D35`) |
| 4 VDD | 5V_RGB | 77 other pins: use the label | wire (or local label `5V_RGB`) |

#### C440 · 100nF · at D436 VDD (top side)

| Pin | Net | Connects to | Draw |
|---|---|---|---|
| 1 | 5V_RGB | 77 other pins: use the label | wire (or local label `5V_RGB`) |
| 2 | GND |  | power symbol `GND` |

---

## Sheet DISPLAY

File `display.kicad_sch` · 4 parts

- Power symbols: `+3V3`, `GND`
- Global labels on this sheet: `DISP_BLK`, `DISP_CS`, `DISP_DC`, `DISP_EN_N`, `DISP_RES`, `DISP_SCL`, `DISP_SDA`
- PWR_FLAG on: `DISP_VCC`
- No-connect flags: 0

### Display connector (back strip, bottom side)

#### J501 · Display 1.69in ST7789V3 · HAND-SOLDER. 1 BLK IO37, 2 CS IO36, 3 DC IO35, 4 RES IO48, 5 SDA IO34, 6 SCL IO33, 7 VCC, 8 GND, 9 GND

| Pin | Net | Connects to | Draw |
|---|---|---|---|
| 1 Pin_1 | DISP_BLK | MCU sheet: U201.33 (IO37) | **global label `DISP_BLK`** |
| 2 Pin_2 | DISP_CS | MCU sheet: U201.32 (IO36) | **global label `DISP_CS`** |
| 3 Pin_3 | DISP_DC | MCU sheet: U201.31 (IO35) | **global label `DISP_DC`** |
| 4 Pin_4 | DISP_RES | MCU sheet: U201.30 (IO48) | **global label `DISP_RES`** |
| 5 Pin_5 | DISP_SDA | MCU sheet: U201.29 (IO34) | **global label `DISP_SDA`** |
| 6 Pin_6 | DISP_SCL | MCU sheet: U201.28 (IO33) | **global label `DISP_SCL`** |
| 7 Pin_7 | DISP_VCC | Q501.3 (D), C501.1 | wire (or local label `DISP_VCC`) |
| 8 Pin_8 | GND |  | power symbol `GND` |
| 9 Pin_9 | GND |  | power symbol `GND` |

#### C501 · 1uF · DISP_VCC at J501

| Pin | Net | Connects to | Draw |
|---|---|---|---|
| 1 | DISP_VCC | J501.7 (Pin_7), Q501.3 (D) | wire (or local label `DISP_VCC`) |
| 2 | GND |  | power symbol `GND` |

### Display power switch

#### Q501 · AO3401A · source 3V3, drain DISP_VCC, gate DISP_EN_N (IO47), low = on

| Pin | Net | Connects to | Draw |
|---|---|---|---|
| 1 G | DISP_EN_N | R501.1; MCU sheet: U201.27 (IO47) | **global label `DISP_EN_N`** |
| 2 S | +3V3 |  | power symbol `+3V3` |
| 3 D | DISP_VCC | J501.7 (Pin_7), C501.1 | wire (or local label `DISP_VCC`) |

#### R501 · 100k · gate pull-up to 3V3 (off at reset)

| Pin | Net | Connects to | Draw |
|---|---|---|---|
| 1 | DISP_EN_N | Q501.1 (G); MCU sheet: U201.27 (IO47) | **global label `DISP_EN_N`** |
| 2 | +3V3 |  | power symbol `+3V3` |

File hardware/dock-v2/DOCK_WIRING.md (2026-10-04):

# Dock v2 — Wiring List (component by component)

Open a sheet, go through its parts in the order below (same order as the dashed group boxes on the sheet), and for each pin draw what the **Draw** column says.
Generated from the same checked connection model as [DOCK_CONNECTIONS.md](DOCK_CONNECTIONS.md) (the sketches and reasons are there). After wiring, `python3 hardware/tools/dock_v2_connections/check_wiring.py` compares the schematic with this list.

How to draw each kind of connection:

- **power symbol** `GND`, `+3V3`, `+5V`: the KiCad power symbols (they connect across all sheets by themselves).
- **global label**: the net continues on another sheet. Use a global label with exactly this name on every sheet where it appears.
- **wire (or local label)**: the net stays on this sheet. Draw a wire to the listed pins, or put the same local label on each pin if the parts are far apart.
- **no-connect flag**: the pin is deliberately unused: put an X on it.
- The same net is listed at every pin that belongs to it, so each connection appears twice (once from each end). Draw it once.
- `A_*` and `B_*` nets are each MCU's own (for example A_1V1 and B_1V1): use local labels, never power symbols, or the two chips' rails would be joined.

## Contents

- [POWER](#sheet-power)
- [USB_PORTS](#sheet-usb_ports)
- [MCU_A](#sheet-mcu_a)
- [MCU_B](#sheet-mcu_b)
- [BLE](#sheet-ble)
- [POGO](#sheet-pogo)

---

## Sheet POWER

File `power.kicad_sch` · 31 parts

- Power symbols: `+3V3`, `+5V`, `GND`
- Global labels on this sheet: `PD_PG`, `PD_SCL`, `PD_SDA`
- PWR_FLAG on: `+5V`, `VBUS_IN`
- No-connect flags: 4

### USB-C power input (right edge)

On the PCB: right edge, y ≈ 48 (J101 mouth on the edge; ESD and TVS within 5 mm)

#### J101 · TYPE-C-31-M-12 · Power input: charger, 9 V PD

| Pin | Net | Connects to | Draw |
|---|---|---|---|
| A1 GND | GND |  | power symbol `GND` |
| A4 VBUS | VBUS_IN | D101.1 (A1), U102.1 (VHV), U102.8 (VBUS), C101.1, U103.2 (VIN), C102.1, C103.1 | wire (or local label `VBUS_IN`) |
| A5 CC1 | PD_CC1 | U101.3 (D2+), U102.7 (CC1) | wire (or local label `PD_CC1`) |
| A6 D+ | PD_DP | U101.1 (D1+), U102.4 (DP) | wire (or local label `PD_DP`) |
| A7 D- | PD_DM | U101.6 (D1-), U102.5 (DM) | wire (or local label `PD_DM`) |
| A8 SBU1 | — | nothing | no-connect flag (X) |
| A9 VBUS | VBUS_IN | D101.1 (A1), U102.1 (VHV), U102.8 (VBUS), C101.1, U103.2 (VIN), C102.1, C103.1 | wire (or local label `VBUS_IN`) |
| A12 GND | GND |  | power symbol `GND` |
| B1 GND | GND |  | power symbol `GND` |
| B4 VBUS | VBUS_IN | D101.1 (A1), U102.1 (VHV), U102.8 (VBUS), C101.1, U103.2 (VIN), C102.1, C103.1 | wire (or local label `VBUS_IN`) |
| B5 CC2 | PD_CC2 | U101.4 (D2-), U102.6 (CC2) | wire (or local label `PD_CC2`) |
| B6 D+ | PD_DP | U101.1 (D1+), U102.4 (DP) | wire (or local label `PD_DP`) |
| B7 D- | PD_DM | U101.6 (D1-), U102.5 (DM) | wire (or local label `PD_DM`) |
| B8 SBU2 | — | nothing | no-connect flag (X) |
| B9 VBUS | VBUS_IN | D101.1 (A1), U102.1 (VHV), U102.8 (VBUS), C101.1, U103.2 (VIN), C102.1, C103.1 | wire (or local label `VBUS_IN`) |
| B12 GND | GND |  | power symbol `GND` |
| SH SHIELD | GND |  | power symbol `GND` |

#### U101 · TPD4E1U06DBVR · ESD on CC1, CC2, D+, D-, <=5 mm from J101

| Pin | Net | Connects to | Draw |
|---|---|---|---|
| 1 D1+ | PD_DP | J101.A6 (D+), J101.B6 (D+), U102.4 (DP) | wire (or local label `PD_DP`) |
| 2 GND | GND |  | power symbol `GND` |
| 3 D2+ | PD_CC1 | J101.A5 (CC1), U102.7 (CC1) | wire (or local label `PD_CC1`) |
| 4 D2- | PD_CC2 | J101.B5 (CC2), U102.6 (CC2) | wire (or local label `PD_CC2`) |
| 5 NC | — | nothing | no-connect flag (X) |
| 6 D1- | PD_DM | J101.A7 (D-), J101.B7 (D-), U102.5 (DM) | wire (or local label `PD_DM`) |

#### D101 · SMBJ15A · VBUS_IN TVS, at J101 VBUS

| Pin | Net | Connects to | Draw |
|---|---|---|---|
| 1 A1 | VBUS_IN | J101.A4 (VBUS), J101.A9 (VBUS), J101.B4 (VBUS), J101.B9 (VBUS), U102.1 (VHV), U102.8 (VBUS), C101.1, U103.2 (VIN), C102.1, C103.1 | wire (or local label `VBUS_IN`) |
| 2 A2 | GND |  | power symbol `GND` |

### PD sink CH224A (9 V, I2C to MCU A)

On the PCB: right edge, next to J101

#### U102 · CH224A · VBUS (8) tied to VHV (1)

| Pin | Net | Connects to | Draw |
|---|---|---|---|
| 1 VHV | VBUS_IN | J101.A4 (VBUS), J101.A9 (VBUS), J101.B4 (VBUS), J101.B9 (VBUS), D101.1 (A1), C101.1, U103.2 (VIN), C102.1, C103.1 | wire (or local label `VBUS_IN`) |
| 2 CFG2/SCL | PD_SCL | R103.2; MCU_A sheet: U301.31 (GPIO19) | **global label `PD_SCL`** |
| 3 CFG3/SDA | PD_SDA | R104.2; MCU_A sheet: U301.29 (GPIO18) | **global label `PD_SDA`** |
| 4 DP | PD_DP | J101.A6 (D+), J101.B6 (D+), U101.1 (D1+) | wire (or local label `PD_DP`) |
| 5 DM | PD_DM | J101.A7 (D-), J101.B7 (D-), U101.6 (D1-) | wire (or local label `PD_DM`) |
| 6 CC2 | PD_CC2 | J101.B5 (CC2), U101.4 (D2-) | wire (or local label `PD_CC2`) |
| 7 CC1 | PD_CC1 | J101.A5 (CC1), U101.3 (D2+) | wire (or local label `PD_CC1`) |
| 8 VBUS | VBUS_IN | J101.A4 (VBUS), J101.A9 (VBUS), J101.B4 (VBUS), J101.B9 (VBUS), D101.1 (A1), C101.1, U103.2 (VIN), C102.1, C103.1 | wire (or local label `VBUS_IN`) |
| 9 CFG1 | PD_CFG1 | R101.1 | wire (or local label `PD_CFG1`) |
| 10 PG | PD_PG | R102.2; MCU_A sheet: U301.28 (GPIO17) | **global label `PD_PG`** |
| 11 GND | GND |  | power symbol `GND` |

#### C101 · 1uF · VHV to GND

| Pin | Net | Connects to | Draw |
|---|---|---|---|
| 1 | VBUS_IN | J101.A4 (VBUS), J101.A9 (VBUS), J101.B4 (VBUS), J101.B9 (VBUS), D101.1 (A1), U102.1 (VHV), U102.8 (VBUS), U103.2 (VIN), C102.1, C103.1 | wire (or local label `VBUS_IN`) |
| 2 | GND |  | power symbol `GND` |

#### R101 · 6.8k · CFG1 to GND: requests 9 V

| Pin | Net | Connects to | Draw |
|---|---|---|---|
| 1 | PD_CFG1 | U102.9 (CFG1) | wire (or local label `PD_CFG1`) |
| 2 | GND |  | power symbol `GND` |

#### R102 · 10k · PG pull-up to 3V3

| Pin | Net | Connects to | Draw |
|---|---|---|---|
| 1 | +3V3 |  | power symbol `+3V3` |
| 2 | PD_PG | U102.10 (PG); MCU_A sheet: U301.28 (GPIO17) | **global label `PD_PG`** |

#### R103 · 4.7k · SCL pull-up to 3V3

| Pin | Net | Connects to | Draw |
|---|---|---|---|
| 1 | +3V3 |  | power symbol `+3V3` |
| 2 | PD_SCL | U102.2 (CFG2/SCL); MCU_A sheet: U301.31 (GPIO19) | **global label `PD_SCL`** |

#### R104 · 4.7k · SDA pull-up to 3V3

| Pin | Net | Connects to | Draw |
|---|---|---|---|
| 1 | +3V3 |  | power symbol `+3V3` |
| 2 | PD_SDA | U102.3 (CFG3/SDA); MCU_A sheet: U301.29 (GPIO18) | **global label `PD_SDA`** |

### 5 V buck TPS54331 (TI Table 7-1, 5 V)

On the PCB: front-right corner (keep the hot loop tiny)

#### U103 · TPS54331DR · EN left open (5 V pass-through)

| Pin | Net | Connects to | Draw |
|---|---|---|---|
| 1 BOOT | BUCK_BOOT | C104.1 | wire (or local label `BUCK_BOOT`) |
| 2 VIN | VBUS_IN | J101.A4 (VBUS), J101.A9 (VBUS), J101.B4 (VBUS), J101.B9 (VBUS), D101.1 (A1), U102.1 (VHV), U102.8 (VBUS), C101.1, C102.1, C103.1 | wire (or local label `VBUS_IN`) |
| 3 EN | — | nothing | no-connect flag (X) |
| 4 SS | BUCK_SS | C105.1 | wire (or local label `BUCK_SS`) |
| 5 VSENSE | BUCK_FB | R106.2, R107.1 | wire (or local label `BUCK_FB`) |
| 6 COMP | BUCK_COMP | R105.1, C107.1 | wire (or local label `BUCK_COMP`) |
| 7 GND | GND |  | power symbol `GND` |
| 8 PH | BUCK_SW | C104.2, D102.1 (K), L101.1 | wire (or local label `BUCK_SW`) |

#### C102 · 10uF · VIN, at pins 2/7

| Pin | Net | Connects to | Draw |
|---|---|---|---|
| 1 | VBUS_IN | J101.A4 (VBUS), J101.A9 (VBUS), J101.B4 (VBUS), J101.B9 (VBUS), D101.1 (A1), U102.1 (VHV), U102.8 (VBUS), C101.1, U103.2 (VIN), C103.1 | wire (or local label `VBUS_IN`) |
| 2 | GND |  | power symbol `GND` |

#### C103 · 10uF · VIN

| Pin | Net | Connects to | Draw |
|---|---|---|---|
| 1 | VBUS_IN | J101.A4 (VBUS), J101.A9 (VBUS), J101.B4 (VBUS), J101.B9 (VBUS), D101.1 (A1), U102.1 (VHV), U102.8 (VBUS), C101.1, U103.2 (VIN), C102.1 | wire (or local label `VBUS_IN`) |
| 2 | GND |  | power symbol `GND` |

#### C104 · 100nF · BOOT to PH

| Pin | Net | Connects to | Draw |
|---|---|---|---|
| 1 | BUCK_BOOT | U103.1 (BOOT) | wire (or local label `BUCK_BOOT`) |
| 2 | BUCK_SW | U103.8 (PH), D102.1 (K), L101.1 | wire (or local label `BUCK_SW`) |

#### C105 · 10nF · SS: ~4 ms soft start

| Pin | Net | Connects to | Draw |
|---|---|---|---|
| 1 | BUCK_SS | U103.4 (SS) | wire (or local label `BUCK_SS`) |
| 2 | GND |  | power symbol `GND` |

#### R105 · 51k · COMP series R

| Pin | Net | Connects to | Draw |
|---|---|---|---|
| 1 | BUCK_COMP | U103.6 (COMP), C107.1 | wire (or local label `BUCK_COMP`) |
| 2 | BUCK_COMP_RC | C106.1 | wire (or local label `BUCK_COMP_RC`) |

#### C106 · 4.7nF · COMP series C

| Pin | Net | Connects to | Draw |
|---|---|---|---|
| 1 | BUCK_COMP_RC | R105.2 | wire (or local label `BUCK_COMP_RC`) |
| 2 | GND |  | power symbol `GND` |

#### C107 · 47pF · COMP to GND

| Pin | Net | Connects to | Draw |
|---|---|---|---|
| 1 | BUCK_COMP | U103.6 (COMP), R105.1 | wire (or local label `BUCK_COMP`) |
| 2 | GND |  | power symbol `GND` |

#### R106 · 12k · FB top: 0.8*(1+12/2.2)=5.16 V

| Pin | Net | Connects to | Draw |
|---|---|---|---|
| 1 | +5V |  | power symbol `+5V` |
| 2 | BUCK_FB | U103.5 (VSENSE), R107.1 | wire (or local label `BUCK_FB`) |

#### R107 · 2.2k · FB bottom

| Pin | Net | Connects to | Draw |
|---|---|---|---|
| 1 | BUCK_FB | U103.5 (VSENSE), R106.2 | wire (or local label `BUCK_FB`) |
| 2 | GND |  | power symbol `GND` |

#### D102 · SS54 · catch diode PH to GND

| Pin | Net | Connects to | Draw |
|---|---|---|---|
| 1 K | BUCK_SW | U103.8 (PH), C104.2, L101.1 | wire (or local label `BUCK_SW`) |
| 2 A | GND |  | power symbol `GND` |

#### L101 · 6.8uH · SLO0630H6R8MTT: Isat 8 A (> 5.8 A max current limit), 45 mOhm, 7.1x6.6x3.0

| Pin | Net | Connects to | Draw |
|---|---|---|---|
| 1 | BUCK_SW | U103.8 (PH), C104.2, D102.1 (K) | wire (or local label `BUCK_SW`) |
| 2 | +5V |  | power symbol `+5V` |

#### C108 · 22uF 25V · +5V output

| Pin | Net | Connects to | Draw |
|---|---|---|---|
| 1 | +5V |  | power symbol `+5V` |
| 2 | GND |  | power symbol `GND` |

#### C109 · 22uF 25V · +5V output

| Pin | Net | Connects to | Draw |
|---|---|---|---|
| 1 | +5V |  | power symbol `+5V` |
| 2 | GND |  | power symbol `GND` |

#### C110 · 22uF 25V · +5V output

| Pin | Net | Connects to | Draw |
|---|---|---|---|
| 1 | +5V |  | power symbol `+5V` |
| 2 | GND |  | power symbol `GND` |

### 3.3 V LDO

On the PCB: centre of the board, ≈ (45, 38)

#### U104 · AMS1117-3.3 · +5V to +3V3, tab on copper

| Pin | Net | Connects to | Draw |
|---|---|---|---|
| 1 GND | GND |  | power symbol `GND` |
| 2 VO | +3V3 |  | power symbol `+3V3` |
| 3 VI | +5V |  | power symbol `+5V` |

#### C111 · 10uF · LDO input

| Pin | Net | Connects to | Draw |
|---|---|---|---|
| 1 | +5V |  | power symbol `+5V` |
| 2 | GND |  | power symbol `GND` |

#### C112 · 10uF · LDO output

| Pin | Net | Connects to | Draw |
|---|---|---|---|
| 1 | +3V3 |  | power symbol `+3V3` |
| 2 | GND |  | power symbol `GND` |

### Mounting holes (M3)

On the PCB: (4, 4), (86, 4), (86, 66), (20, 66)

#### H101 · (not in the schematic) · not in the schematic

No pins (mechanical only).

#### H102 · (not in the schematic) · not in the schematic

No pins (mechanical only).

#### H103 · (not in the schematic) · not in the schematic

No pins (mechanical only).

#### H104 · (not in the schematic) · not in the schematic

No pins (mechanical only).

---

## Sheet USB_PORTS

File `usb_ports.kicad_sch` · 33 parts

- Power symbols: `+3V3`, `+5V`, `GND`
- Global labels on this sheet: `KBD_CC1`, `KBD_CC2`, `KBD_USB_D_N`, `KBD_USB_D_P`, `KBD_VBUS_EN`, `KBD_VBUS_SENSE`, `PC1_USB_D_N`, `PC1_USB_D_P`, `PC1_VBUS_DET`, `PC2_USB_D_N`, `PC2_USB_D_P`, `PC2_VBUS_DET`
- PWR_FLAG on: none
- No-connect flags: 9

### Keyboard port J201 (USB-C source, left edge)

On the PCB: left edge, y ≈ 18 (22 Ω resistors near MCU A)

#### J201 · TYPE-C-31-M-12 · Keyboard

| Pin | Net | Connects to | Draw |
|---|---|---|---|
| A1 GND | GND |  | power symbol `GND` |
| A4 VBUS | KBD_VBUS | U202.1 (OUT), C201.1, C202.1, C203.1, R209.1 | wire (or local label `KBD_VBUS`) |
| A5 CC1 | KBD_CC1 | U201.3 (D2+), R201.2; MCU_A sheet: U301.43 (GPIO29/ADC3) | **global label `KBD_CC1`** |
| A6 D+ | KBD_USBJ_D_P | U201.1 (D1+), R203.1, R205.1 | wire (or local label `KBD_USBJ_D_P`) |
| A7 D- | KBD_USBJ_D_N | U201.6 (D1-), R204.1, R206.1 | wire (or local label `KBD_USBJ_D_N`) |
| A8 SBU1 | — | nothing | no-connect flag (X) |
| A9 VBUS | KBD_VBUS | U202.1 (OUT), C201.1, C202.1, C203.1, R209.1 | wire (or local label `KBD_VBUS`) |
| A12 GND | GND |  | power symbol `GND` |
| B1 GND | GND |  | power symbol `GND` |
| B4 VBUS | KBD_VBUS | U202.1 (OUT), C201.1, C202.1, C203.1, R209.1 | wire (or local label `KBD_VBUS`) |
| B5 CC2 | KBD_CC2 | U201.4 (D2-), R202.2; MCU_A sheet: U301.42 (GPIO28/ADC2) | **global label `KBD_CC2`** |
| B6 D+ | KBD_USBJ_D_P | U201.1 (D1+), R203.1, R205.1 | wire (or local label `KBD_USBJ_D_P`) |
| B7 D- | KBD_USBJ_D_N | U201.6 (D1-), R204.1, R206.1 | wire (or local label `KBD_USBJ_D_N`) |
| B8 SBU2 | — | nothing | no-connect flag (X) |
| B9 VBUS | KBD_VBUS | U202.1 (OUT), C201.1, C202.1, C203.1, R209.1 | wire (or local label `KBD_VBUS`) |
| B12 GND | GND |  | power symbol `GND` |
| SH SHIELD | GND |  | power symbol `GND` |

#### U201 · TPD4E1U06DBVR · ESD D+, D-, CC1, CC2

| Pin | Net | Connects to | Draw |
|---|---|---|---|
| 1 D1+ | KBD_USBJ_D_P | J201.A6 (D+), J201.B6 (D+), R203.1, R205.1 | wire (or local label `KBD_USBJ_D_P`) |
| 2 GND | GND |  | power symbol `GND` |
| 3 D2+ | KBD_CC1 | J201.A5 (CC1), R201.2; MCU_A sheet: U301.43 (GPIO29/ADC3) | **global label `KBD_CC1`** |
| 4 D2- | KBD_CC2 | J201.B5 (CC2), R202.2; MCU_A sheet: U301.42 (GPIO28/ADC2) | **global label `KBD_CC2`** |
| 5 NC | — | nothing | no-connect flag (X) |
| 6 D1- | KBD_USBJ_D_N | J201.A7 (D-), J201.B7 (D-), R204.1, R206.1 | wire (or local label `KBD_USBJ_D_N`) |

#### R201 · 33k · CC1 Rp to 3V3 (Default USB)

| Pin | Net | Connects to | Draw |
|---|---|---|---|
| 1 | +3V3 |  | power symbol `+3V3` |
| 2 | KBD_CC1 | J201.A5 (CC1), U201.3 (D2+); MCU_A sheet: U301.43 (GPIO29/ADC3) | **global label `KBD_CC1`** |

#### R202 · 33k · CC2 Rp to 3V3

| Pin | Net | Connects to | Draw |
|---|---|---|---|
| 1 | +3V3 |  | power symbol `+3V3` |
| 2 | KBD_CC2 | J201.B5 (CC2), U201.4 (D2-); MCU_A sheet: U301.42 (GPIO28/ADC2) | **global label `KBD_CC2`** |

#### R203 · 15k · D+ host pull-down

| Pin | Net | Connects to | Draw |
|---|---|---|---|
| 1 | KBD_USBJ_D_P | J201.A6 (D+), J201.B6 (D+), U201.1 (D1+), R205.1 | wire (or local label `KBD_USBJ_D_P`) |
| 2 | GND |  | power symbol `GND` |

#### R204 · 15k · D- host pull-down

| Pin | Net | Connects to | Draw |
|---|---|---|---|
| 1 | KBD_USBJ_D_N | J201.A7 (D-), J201.B7 (D-), U201.6 (D1-), R206.1 | wire (or local label `KBD_USBJ_D_N`) |
| 2 | GND |  | power symbol `GND` |

#### R205 · 22 · D+ series, near MCU A

| Pin | Net | Connects to | Draw |
|---|---|---|---|
| 1 | KBD_USBJ_D_P | J201.A6 (D+), J201.B6 (D+), U201.1 (D1+), R203.1 | wire (or local label `KBD_USBJ_D_P`) |
| 2 | KBD_USB_D_P | MCU_A sheet: U301.5 (GPIO3) | **global label `KBD_USB_D_P`** |

#### R206 · 22 · D- series, near MCU A

| Pin | Net | Connects to | Draw |
|---|---|---|---|
| 1 | KBD_USBJ_D_N | J201.A7 (D-), J201.B7 (D-), U201.6 (D1-), R204.1 | wire (or local label `KBD_USBJ_D_N`) |
| 2 | KBD_USB_D_N | MCU_A sheet: U301.4 (GPIO2) | **global label `KBD_USB_D_N`** |

### Keyboard VBUS switch

On the PCB: between J201 and the +5V trunk; C201 (THT) at J201

#### U202 · SY6280AAC · KBD_VBUS switch, EN from MCU A

| Pin | Net | Connects to | Draw |
|---|---|---|---|
| 1 OUT | KBD_VBUS | J201.A4 (VBUS), J201.A9 (VBUS), J201.B4 (VBUS), J201.B9 (VBUS), C201.1, C202.1, C203.1, R209.1 | wire (or local label `KBD_VBUS`) |
| 2 GND | GND |  | power symbol `GND` |
| 3 ISET | KBD_ISET | R207.1 | wire (or local label `KBD_ISET`) |
| 4 EN | KBD_VBUS_EN | R208.1; MCU_A sheet: U301.12 (GPIO8) | **global label `KBD_VBUS_EN`** |
| 5 IN | +5V |  | power symbol `+5V` |

#### R207 · 6.8k · ISET: 1.0 A

| Pin | Net | Connects to | Draw |
|---|---|---|---|
| 1 | KBD_ISET | U202.3 (ISET) | wire (or local label `KBD_ISET`) |
| 2 | GND |  | power symbol `GND` |

#### R208 · 100k · EN pull-down (off at reset)

| Pin | Net | Connects to | Draw |
|---|---|---|---|
| 1 | KBD_VBUS_EN | U202.4 (EN); MCU_A sheet: U301.12 (GPIO8) | **global label `KBD_VBUS_EN`** |
| 2 | GND |  | power symbol `GND` |

#### C201 · 220uF 16V · HAND-SOLDER: Koshin PKRJ-016V221ME070-T/A5.0 (Ozdisan)

| Pin | Net | Connects to | Draw |
|---|---|---|---|
| 1 | KBD_VBUS | J201.A4 (VBUS), J201.A9 (VBUS), J201.B4 (VBUS), J201.B9 (VBUS), U202.1 (OUT), C202.1, C203.1, R209.1 | wire (or local label `KBD_VBUS`) |
| 2 | GND |  | power symbol `GND` |

#### C202 · 10uF · KBD_VBUS at J201

| Pin | Net | Connects to | Draw |
|---|---|---|---|
| 1 | KBD_VBUS | J201.A4 (VBUS), J201.A9 (VBUS), J201.B4 (VBUS), J201.B9 (VBUS), U202.1 (OUT), C201.1, C203.1, R209.1 | wire (or local label `KBD_VBUS`) |
| 2 | GND |  | power symbol `GND` |

#### C203 · 1uF · KBD_VBUS at J201

| Pin | Net | Connects to | Draw |
|---|---|---|---|
| 1 | KBD_VBUS | J201.A4 (VBUS), J201.A9 (VBUS), J201.B4 (VBUS), J201.B9 (VBUS), U202.1 (OUT), C201.1, C202.1, R209.1 | wire (or local label `KBD_VBUS`) |
| 2 | GND |  | power symbol `GND` |

#### C204 · 1uF · U202 input

| Pin | Net | Connects to | Draw |
|---|---|---|---|
| 1 | +5V |  | power symbol `+5V` |
| 2 | GND |  | power symbol `GND` |

#### R209 · 10k · KBD_VBUS divider top -> ADC

| Pin | Net | Connects to | Draw |
|---|---|---|---|
| 1 | KBD_VBUS | J201.A4 (VBUS), J201.A9 (VBUS), J201.B4 (VBUS), J201.B9 (VBUS), U202.1 (OUT), C201.1, C202.1, C203.1 | wire (or local label `KBD_VBUS`) |
| 2 | KBD_VBUS_SENSE | R210.1; MCU_A sheet: U301.41 (GPIO27/ADC1) | **global label `KBD_VBUS_SENSE`** |

#### R210 · 15k · KBD_VBUS divider bottom

| Pin | Net | Connects to | Draw |
|---|---|---|---|
| 1 | KBD_VBUS_SENSE | R209.2; MCU_A sheet: U301.41 (GPIO27/ADC1) | **global label `KBD_VBUS_SENSE`** |
| 2 | GND |  | power symbol `GND` |

### Personal PC port J202 (back, left)

On the PCB: back edge, left, above MCU A (22 Ω near MCU A)

#### J202 · TYPE-C-31-M-12 · Personal PC

| Pin | Net | Connects to | Draw |
|---|---|---|---|
| A1 GND | GND |  | power symbol `GND` |
| A4 VBUS | PC1_VBUS | R213.1 | wire (or local label `PC1_VBUS`) |
| A5 CC1 | PC1_CC1 | U203.3 (D2+), R211.1 | wire (or local label `PC1_CC1`) |
| A6 D+ | PC1_USBJ_D_P | U203.1 (D1+), R215.1 | wire (or local label `PC1_USBJ_D_P`) |
| A7 D- | PC1_USBJ_D_N | U203.6 (D1-), R216.1 | wire (or local label `PC1_USBJ_D_N`) |
| A8 SBU1 | — | nothing | no-connect flag (X) |
| A9 VBUS | PC1_VBUS | R213.1 | wire (or local label `PC1_VBUS`) |
| A12 GND | GND |  | power symbol `GND` |
| B1 GND | GND |  | power symbol `GND` |
| B4 VBUS | PC1_VBUS | R213.1 | wire (or local label `PC1_VBUS`) |
| B5 CC2 | PC1_CC2 | U203.4 (D2-), R212.1 | wire (or local label `PC1_CC2`) |
| B6 D+ | PC1_USBJ_D_P | U203.1 (D1+), R215.1 | wire (or local label `PC1_USBJ_D_P`) |
| B7 D- | PC1_USBJ_D_N | U203.6 (D1-), R216.1 | wire (or local label `PC1_USBJ_D_N`) |
| B8 SBU2 | — | nothing | no-connect flag (X) |
| B9 VBUS | PC1_VBUS | R213.1 | wire (or local label `PC1_VBUS`) |
| B12 GND | GND |  | power symbol `GND` |
| SH SHIELD | GND |  | power symbol `GND` |

#### U203 · TPD4E1U06DBVR · ESD D+, D-, CC1, CC2

| Pin | Net | Connects to | Draw |
|---|---|---|---|
| 1 D1+ | PC1_USBJ_D_P | J202.A6 (D+), J202.B6 (D+), R215.1 | wire (or local label `PC1_USBJ_D_P`) |
| 2 GND | GND |  | power symbol `GND` |
| 3 D2+ | PC1_CC1 | J202.A5 (CC1), R211.1 | wire (or local label `PC1_CC1`) |
| 4 D2- | PC1_CC2 | J202.B5 (CC2), R212.1 | wire (or local label `PC1_CC2`) |
| 5 NC | — | nothing | no-connect flag (X) |
| 6 D1- | PC1_USBJ_D_N | J202.A7 (D-), J202.B7 (D-), R216.1 | wire (or local label `PC1_USBJ_D_N`) |

#### R211 · 5.1k · CC1 Rd

| Pin | Net | Connects to | Draw |
|---|---|---|---|
| 1 | PC1_CC1 | J202.A5 (CC1), U203.3 (D2+) | wire (or local label `PC1_CC1`) |
| 2 | GND |  | power symbol `GND` |

#### R212 · 5.1k · CC2 Rd

| Pin | Net | Connects to | Draw |
|---|---|---|---|
| 1 | PC1_CC2 | J202.B5 (CC2), U203.4 (D2-) | wire (or local label `PC1_CC2`) |
| 2 | GND |  | power symbol `GND` |

#### R213 · 22k · VBUS sense top

| Pin | Net | Connects to | Draw |
|---|---|---|---|
| 1 | PC1_VBUS | J202.A4 (VBUS), J202.A9 (VBUS), J202.B4 (VBUS), J202.B9 (VBUS) | wire (or local label `PC1_VBUS`) |
| 2 | PC1_VBUS_DET | R214.1; MCU_A sheet: U301.3 (GPIO1) | **global label `PC1_VBUS_DET`** |

#### R214 · 33k · VBUS sense bottom

| Pin | Net | Connects to | Draw |
|---|---|---|---|
| 1 | PC1_VBUS_DET | R213.2; MCU_A sheet: U301.3 (GPIO1) | **global label `PC1_VBUS_DET`** |
| 2 | GND |  | power symbol `GND` |

#### R215 · 22 · D+ series, near MCU A

| Pin | Net | Connects to | Draw |
|---|---|---|---|
| 1 | PC1_USBJ_D_P | J202.A6 (D+), J202.B6 (D+), U203.1 (D1+) | wire (or local label `PC1_USBJ_D_P`) |
| 2 | PC1_USB_D_P | MCU_A sheet: U301.52 (USB_DP) | **global label `PC1_USB_D_P`** |

#### R216 · 22 · D- series, near MCU A

| Pin | Net | Connects to | Draw |
|---|---|---|---|
| 1 | PC1_USBJ_D_N | J202.A7 (D-), J202.B7 (D-), U203.6 (D1-) | wire (or local label `PC1_USBJ_D_N`) |
| 2 | PC1_USB_D_N | MCU_A sheet: U301.51 (USB_DM) | **global label `PC1_USB_D_N`** |

### Work PC port J203 (back, right)

On the PCB: back edge, right, above MCU B (22 Ω near MCU B)

#### J203 · TYPE-C-31-M-12 · Work PC

| Pin | Net | Connects to | Draw |
|---|---|---|---|
| A1 GND | GND |  | power symbol `GND` |
| A4 VBUS | PC2_VBUS | R219.1 | wire (or local label `PC2_VBUS`) |
| A5 CC1 | PC2_CC1 | U204.3 (D2+), R217.1 | wire (or local label `PC2_CC1`) |
| A6 D+ | PC2_USBJ_D_P | U204.1 (D1+), R221.1 | wire (or local label `PC2_USBJ_D_P`) |
| A7 D- | PC2_USBJ_D_N | U204.6 (D1-), R222.1 | wire (or local label `PC2_USBJ_D_N`) |
| A8 SBU1 | — | nothing | no-connect flag (X) |
| A9 VBUS | PC2_VBUS | R219.1 | wire (or local label `PC2_VBUS`) |
| A12 GND | GND |  | power symbol `GND` |
| B1 GND | GND |  | power symbol `GND` |
| B4 VBUS | PC2_VBUS | R219.1 | wire (or local label `PC2_VBUS`) |
| B5 CC2 | PC2_CC2 | U204.4 (D2-), R218.1 | wire (or local label `PC2_CC2`) |
| B6 D+ | PC2_USBJ_D_P | U204.1 (D1+), R221.1 | wire (or local label `PC2_USBJ_D_P`) |
| B7 D- | PC2_USBJ_D_N | U204.6 (D1-), R222.1 | wire (or local label `PC2_USBJ_D_N`) |
| B8 SBU2 | — | nothing | no-connect flag (X) |
| B9 VBUS | PC2_VBUS | R219.1 | wire (or local label `PC2_VBUS`) |
| B12 GND | GND |  | power symbol `GND` |
| SH SHIELD | GND |  | power symbol `GND` |

#### U204 · TPD4E1U06DBVR · ESD D+, D-, CC1, CC2

| Pin | Net | Connects to | Draw |
|---|---|---|---|
| 1 D1+ | PC2_USBJ_D_P | J203.A6 (D+), J203.B6 (D+), R221.1 | wire (or local label `PC2_USBJ_D_P`) |
| 2 GND | GND |  | power symbol `GND` |
| 3 D2+ | PC2_CC1 | J203.A5 (CC1), R217.1 | wire (or local label `PC2_CC1`) |
| 4 D2- | PC2_CC2 | J203.B5 (CC2), R218.1 | wire (or local label `PC2_CC2`) |
| 5 NC | — | nothing | no-connect flag (X) |
| 6 D1- | PC2_USBJ_D_N | J203.A7 (D-), J203.B7 (D-), R222.1 | wire (or local label `PC2_USBJ_D_N`) |

#### R217 · 5.1k · CC1 Rd

| Pin | Net | Connects to | Draw |
|---|---|---|---|
| 1 | PC2_CC1 | J203.A5 (CC1), U204.3 (D2+) | wire (or local label `PC2_CC1`) |
| 2 | GND |  | power symbol `GND` |

#### R218 · 5.1k · CC2 Rd

| Pin | Net | Connects to | Draw |
|---|---|---|---|
| 1 | PC2_CC2 | J203.B5 (CC2), U204.4 (D2-) | wire (or local label `PC2_CC2`) |
| 2 | GND |  | power symbol `GND` |

#### R219 · 22k · VBUS sense top

| Pin | Net | Connects to | Draw |
|---|---|---|---|
| 1 | PC2_VBUS | J203.A4 (VBUS), J203.A9 (VBUS), J203.B4 (VBUS), J203.B9 (VBUS) | wire (or local label `PC2_VBUS`) |
| 2 | PC2_VBUS_DET | R220.1; MCU_B sheet: U401.43 (GPIO29/ADC3) | **global label `PC2_VBUS_DET`** |

#### R220 · 33k · VBUS sense bottom

| Pin | Net | Connects to | Draw |
|---|---|---|---|
| 1 | PC2_VBUS_DET | R219.2; MCU_B sheet: U401.43 (GPIO29/ADC3) | **global label `PC2_VBUS_DET`** |
| 2 | GND |  | power symbol `GND` |

#### R221 · 22 · D+ series, near MCU B

| Pin | Net | Connects to | Draw |
|---|---|---|---|
| 1 | PC2_USBJ_D_P | J203.A6 (D+), J203.B6 (D+), U204.1 (D1+) | wire (or local label `PC2_USBJ_D_P`) |
| 2 | PC2_USB_D_P | MCU_B sheet: U401.52 (USB_DP) | **global label `PC2_USB_D_P`** |

#### R222 · 22 · D- series, near MCU B

| Pin | Net | Connects to | Draw |
|---|---|---|---|
| 1 | PC2_USBJ_D_N | J203.A7 (D-), J203.B7 (D-), U204.6 (D1-) | wire (or local label `PC2_USBJ_D_N`) |
| 2 | PC2_USB_D_N | MCU_B sheet: U401.51 (USB_DM) | **global label `PC2_USB_D_N`** |

---

## Sheet MCU_A

File `mcu_a.kicad_sch` · 27 parts

- Power symbols: `+3V3`, `GND`
- Global labels on this sheet: `A_SWCLK`, `A_SWDIO`, `BLE_BOOT`, `BLE_EN`, `BLE_RX`, `BLE_TX`, `B_BOOTSEL`, `B_LINK_RX`, `B_LINK_TX`, `B_RUN`, `B_SWCLK`, `B_SWDIO`, `KBD_CC1`, `KBD_CC2`, `KBD_USB_D_N`, `KBD_USB_D_P`, `KBD_VBUS_EN`, `KBD_VBUS_SENSE`, `PC1_USB_D_N`, `PC1_USB_D_P`, `PC1_VBUS_DET`, `PD_PG`, `PD_SCL`, `PD_SDA`, `POGO_5V_SENSE`, `POGO_DET`, `POGO_OFF`, `POGO_RX`, `POGO_TX`
- PWR_FLAG on: `A_1V1`, `A_VREG_AVDD`
- No-connect flags: 9

### RP2354A A

On the PCB: back-left, ≈ (24, 22); regulator/USB side towards J202

#### U301 · RP2354A · A: keyboard host (PIO-USB) + Personal PC

| Pin | Net | Connects to | Draw |
|---|---|---|---|
| 1 IOVDD | +3V3 |  | power symbol `+3V3` |
| 2 GPIO0 | A_LED | R305.1 | wire (or local label `A_LED`) |
| 3 GPIO1 | PC1_VBUS_DET | USB_PORTS sheet: R213.2, R214.1 | **global label `PC1_VBUS_DET`** |
| 4 GPIO2 | KBD_USB_D_N | USB_PORTS sheet: R206.2 | **global label `KBD_USB_D_N`** |
| 5 GPIO3 | KBD_USB_D_P | USB_PORTS sheet: R205.2 | **global label `KBD_USB_D_P`** |
| 6 DVDD | A_1V1 | L301.1, C302.1, C304.1, C305.1, C306.1 | wire (or local label `A_1V1`) |
| 7 GPIO4 | — | nothing | no-connect flag (X) |
| 8 GPIO5 | — | nothing | no-connect flag (X) |
| 9 GPIO6 | — | nothing | no-connect flag (X) |
| 10 GPIO7 | — | nothing | no-connect flag (X) |
| 11 IOVDD | +3V3 |  | power symbol `+3V3` |
| 12 GPIO8 | KBD_VBUS_EN | USB_PORTS sheet: U202.4 (EN), R208.1 | **global label `KBD_VBUS_EN`** |
| 13 GPIO9 | BLE_EN | BLE sheet: U501.8 (EN/CHIP_PU), R501.2, C501.1 | **global label `BLE_EN`** |
| 14 GPIO10 | BLE_BOOT | BLE sheet: U501.23 (GPIO9), R504.2 | **global label `BLE_BOOT`** |
| 15 GPIO11 | POGO_OFF | POGO sheet: Q602.1 (G), R609.1 | **global label `POGO_OFF`** |
| 16 GPIO12 | BLE_TX | BLE sheet: U501.30 (GPIO20/U0RXD), TP504.1 | **global label `BLE_TX`** |
| 17 GPIO13 | BLE_RX | BLE sheet: U501.31 (GPIO21/U0TXD), TP503.1 | **global label `BLE_RX`** |
| 18 GPIO14 | POGO_DET | POGO sheet: R603.2, Q601.1 (G), R604.2 | **global label `POGO_DET`** |
| 19 GPIO15 | POGO_RX | POGO sheet: R602.2 | **global label `POGO_RX`** |
| 20 IOVDD | +3V3 |  | power symbol `+3V3` |
| 21 XIN | A_XIN | Y301.1, C315.1 | wire (or local label `A_XIN`) |
| 22 XOUT | A_XOUT | R302.1 | wire (or local label `A_XOUT`) |
| 23 DVDD | A_1V1 | L301.1, C302.1, C304.1, C305.1, C306.1 | wire (or local label `A_1V1`) |
| 24 SWCLK | A_SWCLK | MCU_B sheet: J401.3 (Pin_3) | **global label `A_SWCLK`** |
| 25 SWDIO | A_SWDIO | MCU_B sheet: J401.2 (Pin_2) | **global label `A_SWDIO`** |
| 26 RUN | A_RUN | SW302.1 | wire (or local label `A_RUN`) |
| 27 GPIO16 | POGO_TX | POGO sheet: R601.1 | **global label `POGO_TX`** |
| 28 GPIO17 | PD_PG | POWER sheet: U102.10 (PG), R102.2 | **global label `PD_PG`** |
| 29 GPIO18 | PD_SDA | POWER sheet: U102.3 (CFG3/SDA), R104.2 | **global label `PD_SDA`** |
| 30 IOVDD | +3V3 |  | power symbol `+3V3` |
| 31 GPIO19 | PD_SCL | POWER sheet: U102.2 (CFG2/SCL), R103.2 | **global label `PD_SCL`** |
| 32 GPIO20 | B_RUN | MCU_B sheet: U401.26 (RUN), R406.2 | **global label `B_RUN`** |
| 33 GPIO21 | B_SWDIO | MCU_B sheet: U401.25 (SWDIO); BLE sheet: J501.2 (Pin_2) | **global label `B_SWDIO`** |
| 34 GPIO22 | B_SWCLK | MCU_B sheet: U401.24 (SWCLK); BLE sheet: J501.3 (Pin_3) | **global label `B_SWCLK`** |
| 35 GPIO23 | B_LINK_RX | MCU_B sheet: U401.9 (GPIO6) | **global label `B_LINK_RX`** |
| 36 GPIO24 | B_LINK_TX | MCU_B sheet: U401.8 (GPIO5) | **global label `B_LINK_TX`** |
| 37 GPIO25 | B_BOOTSEL | MCU_B sheet: R404.1, R407.2 | **global label `B_BOOTSEL`** |
| 38 IOVDD | +3V3 |  | power symbol `+3V3` |
| 39 DVDD | A_1V1 | L301.1, C302.1, C304.1, C305.1, C306.1 | wire (or local label `A_1V1`) |
| 40 GPIO26/ADC0 | POGO_5V_SENSE | POGO sheet: R607.2, R608.1 | **global label `POGO_5V_SENSE`** |
| 41 GPIO27/ADC1 | KBD_VBUS_SENSE | USB_PORTS sheet: R209.2, R210.1 | **global label `KBD_VBUS_SENSE`** |
| 42 GPIO28/ADC2 | KBD_CC2 | USB_PORTS sheet: J201.B5 (CC2), U201.4 (D2-), R202.2 | **global label `KBD_CC2`** |
| 43 GPIO29/ADC3 | KBD_CC1 | USB_PORTS sheet: J201.A5 (CC1), U201.3 (D2+), R201.2 | **global label `KBD_CC1`** |
| 44 ADC_AVDD | +3V3 |  | power symbol `+3V3` |
| 45 IOVDD | +3V3 |  | power symbol `+3V3` |
| 46 VREG_AVDD | A_VREG_AVDD | C303.1, R301.2 | wire (or local label `A_VREG_AVDD`) |
| 47 VREG_PGND | GND |  | power symbol `GND` |
| 48 VREG_LX | A_VREG_LX | L301.2 | wire (or local label `A_VREG_LX`) |
| 49 VREG_VIN | +3V3 |  | power symbol `+3V3` |
| 50 VREG_FB | A_1V1 | L301.1, C302.1, C304.1, C305.1, C306.1 | wire (or local label `A_1V1`) |
| 51 USB_DM | PC1_USB_D_N | USB_PORTS sheet: R216.2 | **global label `PC1_USB_D_N`** |
| 52 USB_DP | PC1_USB_D_P | USB_PORTS sheet: R215.2 | **global label `PC1_USB_D_P`** |
| 53 USB_OTP_VDD | +3V3 |  | power symbol `+3V3` |
| 54 QSPI_IOVDD | +3V3 |  | power symbol `+3V3` |
| 55 QSPI_SD3 | — | nothing | no-connect flag (X) |
| 56 QSPI_SCLK | — | nothing | no-connect flag (X) |
| 57 QSPI_SD0 | — | nothing | no-connect flag (X) |
| 58 QSPI_SD2 | — | nothing | no-connect flag (X) |
| 59 QSPI_SD1 | — | nothing | no-connect flag (X) |
| 60 QSPI_SS | A_QSPI_SS | R303.1 | wire (or local label `A_QSPI_SS`) |
| 61 GND | GND |  | power symbol `GND` |

### Core regulator (copy_rpi_core_layout.py)

On the PCB: around the MCU exactly as Raspberry Pi (placed by copy_rpi_core_layout.py)

#### L301 · 3.3uH · pin 1 (dot) = +1V1, pin 2 = VREG_LX

| Pin | Net | Connects to | Draw |
|---|---|---|---|
| 1 | A_1V1 | U301.6 (DVDD), U301.23 (DVDD), U301.39 (DVDD), U301.50 (VREG_FB), C302.1, C304.1, C305.1, C306.1 | wire (or local label `A_1V1`) |
| 2 | A_VREG_LX | U301.48 (VREG_LX) | wire (or local label `A_VREG_LX`) |

#### C301 · 4.7uF · VREG_VIN (RPi C6)

| Pin | Net | Connects to | Draw |
|---|---|---|---|
| 1 | +3V3 |  | power symbol `+3V3` |
| 2 | GND |  | power symbol `GND` |

#### C302 · 4.7uF · +1V1 output (RPi C7)

| Pin | Net | Connects to | Draw |
|---|---|---|---|
| 1 | A_1V1 | U301.6 (DVDD), U301.23 (DVDD), U301.39 (DVDD), U301.50 (VREG_FB), L301.1, C304.1, C305.1, C306.1 | wire (or local label `A_1V1`) |
| 2 | GND |  | power symbol `GND` |

#### C303 · 4.7uF · VREG_AVDD (RPi C9)

| Pin | Net | Connects to | Draw |
|---|---|---|---|
| 1 | A_VREG_AVDD | U301.46 (VREG_AVDD), R301.2 | wire (or local label `A_VREG_AVDD`) |
| 2 | GND |  | power symbol `GND` |

#### R301 · 33 · 3V3 -> VREG_AVDD (RPi R3)

| Pin | Net | Connects to | Draw |
|---|---|---|---|
| 1 | +3V3 |  | power symbol `+3V3` |
| 2 | A_VREG_AVDD | U301.46 (VREG_AVDD), C303.1 | wire (or local label `A_VREG_AVDD`) |

### Decoupling

On the PCB: one capacitor on each power pin (placed by copy_rpi_core_layout.py)

#### C304 · 100nF · DVDD 1 (+1V1)

| Pin | Net | Connects to | Draw |
|---|---|---|---|
| 1 | A_1V1 | U301.6 (DVDD), U301.23 (DVDD), U301.39 (DVDD), U301.50 (VREG_FB), L301.1, C302.1, C305.1, C306.1 | wire (or local label `A_1V1`) |
| 2 | GND |  | power symbol `GND` |

#### C305 · 100nF · DVDD 2 (+1V1)

| Pin | Net | Connects to | Draw |
|---|---|---|---|
| 1 | A_1V1 | U301.6 (DVDD), U301.23 (DVDD), U301.39 (DVDD), U301.50 (VREG_FB), L301.1, C302.1, C304.1, C306.1 | wire (or local label `A_1V1`) |
| 2 | GND |  | power symbol `GND` |

#### C306 · 100nF · DVDD 3 (+1V1)

| Pin | Net | Connects to | Draw |
|---|---|---|---|
| 1 | A_1V1 | U301.6 (DVDD), U301.23 (DVDD), U301.39 (DVDD), U301.50 (VREG_FB), L301.1, C302.1, C304.1, C305.1 | wire (or local label `A_1V1`) |
| 2 | GND |  | power symbol `GND` |

#### C307 · 100nF · IOVDD / ADC / USB_OTP / QSPI (+3V3)

| Pin | Net | Connects to | Draw |
|---|---|---|---|
| 1 | +3V3 |  | power symbol `+3V3` |
| 2 | GND |  | power symbol `GND` |

#### C308 · 100nF · IOVDD / ADC / USB_OTP / QSPI (+3V3)

| Pin | Net | Connects to | Draw |
|---|---|---|---|
| 1 | +3V3 |  | power symbol `+3V3` |
| 2 | GND |  | power symbol `GND` |

#### C309 · 100nF · IOVDD / ADC / USB_OTP / QSPI (+3V3)

| Pin | Net | Connects to | Draw |
|---|---|---|---|
| 1 | +3V3 |  | power symbol `+3V3` |
| 2 | GND |  | power symbol `GND` |

#### C310 · 100nF · IOVDD / ADC / USB_OTP / QSPI (+3V3)

| Pin | Net | Connects to | Draw |
|---|---|---|---|
| 1 | +3V3 |  | power symbol `+3V3` |
| 2 | GND |  | power symbol `GND` |

#### C311 · 100nF · IOVDD / ADC / USB_OTP / QSPI (+3V3)

| Pin | Net | Connects to | Draw |
|---|---|---|---|
| 1 | +3V3 |  | power symbol `+3V3` |
| 2 | GND |  | power symbol `GND` |

#### C312 · 100nF · IOVDD / ADC / USB_OTP / QSPI (+3V3)

| Pin | Net | Connects to | Draw |
|---|---|---|---|
| 1 | +3V3 |  | power symbol `+3V3` |
| 2 | GND |  | power symbol `GND` |

#### C313 · 100nF · IOVDD / ADC / USB_OTP / QSPI (+3V3)

| Pin | Net | Connects to | Draw |
|---|---|---|---|
| 1 | +3V3 |  | power symbol `+3V3` |
| 2 | GND |  | power symbol `GND` |

#### C314 · 10uF · +3V3 bulk

| Pin | Net | Connects to | Draw |
|---|---|---|---|
| 1 | +3V3 |  | power symbol `+3V3` |
| 2 | GND |  | power symbol `GND` |

### Crystal

On the PCB: next to XIN/XOUT (placed by copy_rpi_core_layout.py)

#### Y301 · 12MHz · ABM8-272-T3 (10 pF, 50 ohm)

| Pin | Net | Connects to | Draw |
|---|---|---|---|
| 1 | A_XIN | U301.21 (XIN), C315.1 | wire (or local label `A_XIN`) |
| 2 G | GND |  | power symbol `GND` |
| 3 | A_XOUT_R | C316.1, R302.2 | wire (or local label `A_XOUT_R`) |
| 4 G | GND |  | power symbol `GND` |

#### C315 · 15pF · XIN load

| Pin | Net | Connects to | Draw |
|---|---|---|---|
| 1 | A_XIN | U301.21 (XIN), Y301.1 | wire (or local label `A_XIN`) |
| 2 | GND |  | power symbol `GND` |

#### C316 · 15pF · XOUT load

| Pin | Net | Connects to | Draw |
|---|---|---|---|
| 1 | A_XOUT_R | Y301.3, R302.2 | wire (or local label `A_XOUT_R`) |
| 2 | GND |  | power symbol `GND` |

#### R302 · 1k · XOUT series (RPi R2)

| Pin | Net | Connects to | Draw |
|---|---|---|---|
| 1 | A_XOUT | U301.22 (XOUT) | wire (or local label `A_XOUT`) |
| 2 | A_XOUT_R | Y301.3, C316.1 | wire (or local label `A_XOUT_R`) |

### Buttons, SWD pads, LED

On the PCB: near the MCU, buttons reachable from above

#### SW301 · SW_Push · BOOTSEL A

| Pin | Net | Connects to | Draw |
|---|---|---|---|
| 1 | A_BOOTSEL_BTN | R303.2 | wire (or local label `A_BOOTSEL_BTN`) |
| 2 | GND |  | power symbol `GND` |

#### R303 · 1k · QSPI_SS -> BOOTSEL button

| Pin | Net | Connects to | Draw |
|---|---|---|---|
| 1 | A_QSPI_SS | U301.60 (QSPI_SS) | wire (or local label `A_QSPI_SS`) |
| 2 | A_BOOTSEL_BTN | SW301.1 | wire (or local label `A_BOOTSEL_BTN`) |

#### SW302 · SW_Push · RESET A (RUN to GND)

| Pin | Net | Connects to | Draw |
|---|---|---|---|
| 1 | A_RUN | U301.26 (RUN) | wire (or local label `A_RUN`) |
| 2 | GND |  | power symbol `GND` |

#### D301 · LED red · status LED

| Pin | Net | Connects to | Draw |
|---|---|---|---|
| 1 K | GND |  | power symbol `GND` |
| 2 A | A_LED_R | R305.2 | wire (or local label `A_LED_R`) |

#### R305 · 1k · LED series

| Pin | Net | Connects to | Draw |
|---|---|---|---|
| 1 | A_LED | U301.2 (GPIO0) | wire (or local label `A_LED`) |
| 2 | A_LED_R | D301.2 (A) | wire (or local label `A_LED_R`) |

#### J401 · Conn_01x03

| Pin | Net | Connects to | Draw |
|---|---|---|---|
| 1 Pin_1 | GND |  | power symbol `GND` |
| 2 Pin_2 | A_SWDIO | U301.25 (SWDIO) | **global label `A_SWDIO`** |
| 3 Pin_3 | A_SWCLK | U301.24 (SWCLK) | **global label `A_SWCLK`** |

---

## Sheet MCU_B

File `mcu_b.kicad_sch` · 29 parts

- Power symbols: `+3V3`, `GND`
- Global labels on this sheet: `B_BOOTSEL`, `B_LINK_RX`, `B_LINK_TX`, `B_RUN`, `B_SWCLK`, `B_SWDIO`, `PC2_USB_D_N`, `PC2_USB_D_P`, `PC2_VBUS_DET`
- PWR_FLAG on: `B_1V1`, `B_VREG_AVDD`
- No-connect flags: 31

### RP2354A B

On the PCB: back-right, ≈ (64, 22); regulator/USB side towards J203

#### U401 · RP2354A · B: Work PC device

| Pin | Net | Connects to | Draw |
|---|---|---|---|
| 1 IOVDD | +3V3 |  | power symbol `+3V3` |
| 2 GPIO0 | — | nothing | no-connect flag (X) |
| 3 GPIO1 | — | nothing | no-connect flag (X) |
| 4 GPIO2 | — | nothing | no-connect flag (X) |
| 5 GPIO3 | B_LED | R405.1 | wire (or local label `B_LED`) |
| 6 DVDD | B_1V1 | L401.1, C402.1, C404.1, C405.1, C406.1 | wire (or local label `B_1V1`) |
| 7 GPIO4 | — | nothing | no-connect flag (X) |
| 8 GPIO5 | B_LINK_TX | MCU_A sheet: U301.36 (GPIO24) | **global label `B_LINK_TX`** |
| 9 GPIO6 | B_LINK_RX | MCU_A sheet: U301.35 (GPIO23) | **global label `B_LINK_RX`** |
| 10 GPIO7 | — | nothing | no-connect flag (X) |
| 11 IOVDD | +3V3 |  | power symbol `+3V3` |
| 12 GPIO8 | — | nothing | no-connect flag (X) |
| 13 GPIO9 | — | nothing | no-connect flag (X) |
| 14 GPIO10 | — | nothing | no-connect flag (X) |
| 15 GPIO11 | — | nothing | no-connect flag (X) |
| 16 GPIO12 | — | nothing | no-connect flag (X) |
| 17 GPIO13 | — | nothing | no-connect flag (X) |
| 18 GPIO14 | — | nothing | no-connect flag (X) |
| 19 GPIO15 | — | nothing | no-connect flag (X) |
| 20 IOVDD | +3V3 |  | power symbol `+3V3` |
| 21 XIN | B_XIN | Y401.1, C415.1 | wire (or local label `B_XIN`) |
| 22 XOUT | B_XOUT | R402.1 | wire (or local label `B_XOUT`) |
| 23 DVDD | B_1V1 | L401.1, C402.1, C404.1, C405.1, C406.1 | wire (or local label `B_1V1`) |
| 24 SWCLK | B_SWCLK | MCU_A sheet: U301.34 (GPIO22); BLE sheet: J501.3 (Pin_3) | **global label `B_SWCLK`** |
| 25 SWDIO | B_SWDIO | MCU_A sheet: U301.33 (GPIO21); BLE sheet: J501.2 (Pin_2) | **global label `B_SWDIO`** |
| 26 RUN | B_RUN | R406.2; MCU_A sheet: U301.32 (GPIO20) | **global label `B_RUN`** |
| 27 GPIO16 | — | nothing | no-connect flag (X) |
| 28 GPIO17 | — | nothing | no-connect flag (X) |
| 29 GPIO18 | — | nothing | no-connect flag (X) |
| 30 IOVDD | +3V3 |  | power symbol `+3V3` |
| 31 GPIO19 | — | nothing | no-connect flag (X) |
| 32 GPIO20 | — | nothing | no-connect flag (X) |
| 33 GPIO21 | — | nothing | no-connect flag (X) |
| 34 GPIO22 | — | nothing | no-connect flag (X) |
| 35 GPIO23 | — | nothing | no-connect flag (X) |
| 36 GPIO24 | — | nothing | no-connect flag (X) |
| 37 GPIO25 | — | nothing | no-connect flag (X) |
| 38 IOVDD | +3V3 |  | power symbol `+3V3` |
| 39 DVDD | B_1V1 | L401.1, C402.1, C404.1, C405.1, C406.1 | wire (or local label `B_1V1`) |
| 40 GPIO26/ADC0 | — | nothing | no-connect flag (X) |
| 41 GPIO27/ADC1 | — | nothing | no-connect flag (X) |
| 42 GPIO28/ADC2 | — | nothing | no-connect flag (X) |
| 43 GPIO29/ADC3 | PC2_VBUS_DET | USB_PORTS sheet: R219.2, R220.1 | **global label `PC2_VBUS_DET`** |
| 44 ADC_AVDD | +3V3 |  | power symbol `+3V3` |
| 45 IOVDD | +3V3 |  | power symbol `+3V3` |
| 46 VREG_AVDD | B_VREG_AVDD | C403.1, R401.2 | wire (or local label `B_VREG_AVDD`) |
| 47 VREG_PGND | GND |  | power symbol `GND` |
| 48 VREG_LX | B_VREG_LX | L401.2 | wire (or local label `B_VREG_LX`) |
| 49 VREG_VIN | +3V3 |  | power symbol `+3V3` |
| 50 VREG_FB | B_1V1 | L401.1, C402.1, C404.1, C405.1, C406.1 | wire (or local label `B_1V1`) |
| 51 USB_DM | PC2_USB_D_N | USB_PORTS sheet: R222.2 | **global label `PC2_USB_D_N`** |
| 52 USB_DP | PC2_USB_D_P | USB_PORTS sheet: R221.2 | **global label `PC2_USB_D_P`** |
| 53 USB_OTP_VDD | +3V3 |  | power symbol `+3V3` |
| 54 QSPI_IOVDD | +3V3 |  | power symbol `+3V3` |
| 55 QSPI_SD3 | — | nothing | no-connect flag (X) |
| 56 QSPI_SCLK | — | nothing | no-connect flag (X) |
| 57 QSPI_SD0 | — | nothing | no-connect flag (X) |
| 58 QSPI_SD2 | — | nothing | no-connect flag (X) |
| 59 QSPI_SD1 | — | nothing | no-connect flag (X) |
| 60 QSPI_SS | B_QSPI_SS | R403.1, R404.2 | wire (or local label `B_QSPI_SS`) |
| 61 GND | GND |  | power symbol `GND` |

### Core regulator (copy_rpi_core_layout.py)

On the PCB: around the MCU exactly as Raspberry Pi (placed by copy_rpi_core_layout.py)

#### L401 · 3.3uH · pin 1 (dot) = +1V1, pin 2 = VREG_LX

| Pin | Net | Connects to | Draw |
|---|---|---|---|
| 1 | B_1V1 | U401.6 (DVDD), U401.23 (DVDD), U401.39 (DVDD), U401.50 (VREG_FB), C402.1, C404.1, C405.1, C406.1 | wire (or local label `B_1V1`) |
| 2 | B_VREG_LX | U401.48 (VREG_LX) | wire (or local label `B_VREG_LX`) |

#### C401 · 4.7uF · VREG_VIN (RPi C6)

| Pin | Net | Connects to | Draw |
|---|---|---|---|
| 1 | +3V3 |  | power symbol `+3V3` |
| 2 | GND |  | power symbol `GND` |

#### C402 · 4.7uF · +1V1 output (RPi C7)

| Pin | Net | Connects to | Draw |
|---|---|---|---|
| 1 | B_1V1 | U401.6 (DVDD), U401.23 (DVDD), U401.39 (DVDD), U401.50 (VREG_FB), L401.1, C404.1, C405.1, C406.1 | wire (or local label `B_1V1`) |
| 2 | GND |  | power symbol `GND` |

#### C403 · 4.7uF · VREG_AVDD (RPi C9)

| Pin | Net | Connects to | Draw |
|---|---|---|---|
| 1 | B_VREG_AVDD | U401.46 (VREG_AVDD), R401.2 | wire (or local label `B_VREG_AVDD`) |
| 2 | GND |  | power symbol `GND` |

#### R401 · 33 · 3V3 -> VREG_AVDD (RPi R3)

| Pin | Net | Connects to | Draw |
|---|---|---|---|
| 1 | +3V3 |  | power symbol `+3V3` |
| 2 | B_VREG_AVDD | U401.46 (VREG_AVDD), C403.1 | wire (or local label `B_VREG_AVDD`) |

### Decoupling

On the PCB: one capacitor on each power pin (placed by copy_rpi_core_layout.py)

#### C404 · 100nF · DVDD 1 (+1V1)

| Pin | Net | Connects to | Draw |
|---|---|---|---|
| 1 | B_1V1 | U401.6 (DVDD), U401.23 (DVDD), U401.39 (DVDD), U401.50 (VREG_FB), L401.1, C402.1, C405.1, C406.1 | wire (or local label `B_1V1`) |
| 2 | GND |  | power symbol `GND` |

#### C405 · 100nF · DVDD 2 (+1V1)

| Pin | Net | Connects to | Draw |
|---|---|---|---|
| 1 | B_1V1 | U401.6 (DVDD), U401.23 (DVDD), U401.39 (DVDD), U401.50 (VREG_FB), L401.1, C402.1, C404.1, C406.1 | wire (or local label `B_1V1`) |
| 2 | GND |  | power symbol `GND` |

#### C406 · 100nF · DVDD 3 (+1V1)

| Pin | Net | Connects to | Draw |
|---|---|---|---|
| 1 | B_1V1 | U401.6 (DVDD), U401.23 (DVDD), U401.39 (DVDD), U401.50 (VREG_FB), L401.1, C402.1, C404.1, C405.1 | wire (or local label `B_1V1`) |
| 2 | GND |  | power symbol `GND` |

#### C407 · 100nF · IOVDD / ADC / USB_OTP / QSPI (+3V3)

| Pin | Net | Connects to | Draw |
|---|---|---|---|
| 1 | +3V3 |  | power symbol `+3V3` |
| 2 | GND |  | power symbol `GND` |

#### C408 · 100nF · IOVDD / ADC / USB_OTP / QSPI (+3V3)

| Pin | Net | Connects to | Draw |
|---|---|---|---|
| 1 | +3V3 |  | power symbol `+3V3` |
| 2 | GND |  | power symbol `GND` |

#### C409 · 100nF · IOVDD / ADC / USB_OTP / QSPI (+3V3)

| Pin | Net | Connects to | Draw |
|---|---|---|---|
| 1 | +3V3 |  | power symbol `+3V3` |
| 2 | GND |  | power symbol `GND` |

#### C410 · 100nF · IOVDD / ADC / USB_OTP / QSPI (+3V3)

| Pin | Net | Connects to | Draw |
|---|---|---|---|
| 1 | +3V3 |  | power symbol `+3V3` |
| 2 | GND |  | power symbol `GND` |

#### C411 · 100nF · IOVDD / ADC / USB_OTP / QSPI (+3V3)

| Pin | Net | Connects to | Draw |
|---|---|---|---|
| 1 | +3V3 |  | power symbol `+3V3` |
| 2 | GND |  | power symbol `GND` |

#### C412 · 100nF · IOVDD / ADC / USB_OTP / QSPI (+3V3)

| Pin | Net | Connects to | Draw |
|---|---|---|---|
| 1 | +3V3 |  | power symbol `+3V3` |
| 2 | GND |  | power symbol `GND` |

#### C413 · 100nF · IOVDD / ADC / USB_OTP / QSPI (+3V3)

| Pin | Net | Connects to | Draw |
|---|---|---|---|
| 1 | +3V3 |  | power symbol `+3V3` |
| 2 | GND |  | power symbol `GND` |

#### C414 · 10uF · +3V3 bulk

| Pin | Net | Connects to | Draw |
|---|---|---|---|
| 1 | +3V3 |  | power symbol `+3V3` |
| 2 | GND |  | power symbol `GND` |

### Crystal

On the PCB: next to XIN/XOUT (placed by copy_rpi_core_layout.py)

#### Y401 · 12MHz · ABM8-272-T3 (10 pF, 50 ohm)

| Pin | Net | Connects to | Draw |
|---|---|---|---|
| 1 | B_XIN | U401.21 (XIN), C415.1 | wire (or local label `B_XIN`) |
| 2 G | GND |  | power symbol `GND` |
| 3 | B_XOUT_R | C416.1, R402.2 | wire (or local label `B_XOUT_R`) |
| 4 G | GND |  | power symbol `GND` |

#### C415 · 15pF · XIN load

| Pin | Net | Connects to | Draw |
|---|---|---|---|
| 1 | B_XIN | U401.21 (XIN), Y401.1 | wire (or local label `B_XIN`) |
| 2 | GND |  | power symbol `GND` |

#### C416 · 15pF · XOUT load

| Pin | Net | Connects to | Draw |
|---|---|---|---|
| 1 | B_XOUT_R | Y401.3, R402.2 | wire (or local label `B_XOUT_R`) |
| 2 | GND |  | power symbol `GND` |

#### R402 · 1k · XOUT series (RPi R2)

| Pin | Net | Connects to | Draw |
|---|---|---|---|
| 1 | B_XOUT | U401.22 (XOUT) | wire (or local label `B_XOUT`) |
| 2 | B_XOUT_R | Y401.3, C416.1 | wire (or local label `B_XOUT_R`) |

### Buttons, SWD pads, LED

On the PCB: near the MCU, buttons reachable from above

#### SW401 · SW_Push · BOOTSEL B

| Pin | Net | Connects to | Draw |
|---|---|---|---|
| 1 | B_BOOTSEL_BTN | R403.2 | wire (or local label `B_BOOTSEL_BTN`) |
| 2 | GND |  | power symbol `GND` |

#### R403 · 1k · QSPI_SS -> BOOTSEL button

| Pin | Net | Connects to | Draw |
|---|---|---|---|
| 1 | B_QSPI_SS | U401.60 (QSPI_SS), R404.2 | wire (or local label `B_QSPI_SS`) |
| 2 | B_BOOTSEL_BTN | SW401.1 | wire (or local label `B_BOOTSEL_BTN`) |

#### R404 · 1k · QSPI_SS <- B_BOOTSEL from MCU A

| Pin | Net | Connects to | Draw |
|---|---|---|---|
| 1 | B_BOOTSEL | R407.2; MCU_A sheet: U301.37 (GPIO25) | **global label `B_BOOTSEL`** |
| 2 | B_QSPI_SS | U401.60 (QSPI_SS), R403.1 | wire (or local label `B_QSPI_SS`) |

#### R406 · 10k · B_RUN pull-up (beats A pull-down at reset)

| Pin | Net | Connects to | Draw |
|---|---|---|---|
| 1 | +3V3 |  | power symbol `+3V3` |
| 2 | B_RUN | U401.26 (RUN); MCU_A sheet: U301.32 (GPIO20) | **global label `B_RUN`** |

#### R407 · 10k · B_BOOTSEL pull-up (beats A pull-down)

| Pin | Net | Connects to | Draw |
|---|---|---|---|
| 1 | +3V3 |  | power symbol `+3V3` |
| 2 | B_BOOTSEL | R404.1; MCU_A sheet: U301.37 (GPIO25) | **global label `B_BOOTSEL`** |

#### D401 · LED red · status LED

| Pin | Net | Connects to | Draw |
|---|---|---|---|
| 1 K | GND |  | power symbol `GND` |
| 2 A | B_LED_R | R405.2 | wire (or local label `B_LED_R`) |

#### R405 · 1k · LED series

| Pin | Net | Connects to | Draw |
|---|---|---|---|
| 1 | B_LED | U401.5 (GPIO3) | wire (or local label `B_LED`) |
| 2 | B_LED_R | D401.2 (A) | wire (or local label `B_LED_R`) |

#### J501 · Conn_01x03

| Pin | Net | Connects to | Draw |
|---|---|---|---|
| 1 Pin_1 | GND |  | power symbol `GND` |
| 2 Pin_2 | B_SWDIO | U401.25 (SWDIO); MCU_A sheet: U301.33 (GPIO21) | **global label `B_SWDIO`** |
| 3 Pin_3 | B_SWCLK | U401.24 (SWCLK); MCU_A sheet: U301.34 (GPIO22) | **global label `B_SWCLK`** |

---

## Sheet BLE

File `ble.kicad_sch` · 11 parts

- Power symbols: `+3V3`, `GND`
- Global labels on this sheet: `BLE_BOOT`, `BLE_EN`, `BLE_RX`, `BLE_TX`
- PWR_FLAG on: none
- No-connect flags: 24

### ESP32-C3-MINI-1 (antenna at the left edge)

On the PCB: left edge, front half, antenna end on the edge, keep-out clear

#### U501 · ESP32-C3-MINI-1-H4X · BLE; UART0 to MCU A UART1

| Pin | Net | Connects to | Draw |
|---|---|---|---|
| 1 GND | GND |  | power symbol `GND` |
| 2 GND | GND |  | power symbol `GND` |
| 3 3V3 | +3V3 |  | power symbol `+3V3` |
| 4 NC | — | nothing | no-connect flag (X) |
| 5 GPIO2/ADC1_CH2 | BLE_GPIO2 | R503.2 | wire (or local label `BLE_GPIO2`) |
| 6 GPIO3/ADC1_CH3 | — | nothing | no-connect flag (X) |
| 7 NC | — | nothing | no-connect flag (X) |
| 8 EN/CHIP_PU | BLE_EN | R501.2, C501.1; MCU_A sheet: U301.13 (GPIO9) | **global label `BLE_EN`** |
| 9 NC | — | nothing | no-connect flag (X) |
| 10 NC | — | nothing | no-connect flag (X) |
| 11 GND | GND |  | power symbol `GND` |
| 12 GPIO0/ADC1_CH0/XTAL_32K_P | — | nothing | no-connect flag (X) |
| 13 GPIO1/ADC1_CH1/XTAL_32K_N | — | nothing | no-connect flag (X) |
| 14 GND | GND |  | power symbol `GND` |
| 15 NC | — | nothing | no-connect flag (X) |
| 16 GPIO10 | — | nothing | no-connect flag (X) |
| 17 NC | — | nothing | no-connect flag (X) |
| 18 GPIO4/ADC1_CH4 | — | nothing | no-connect flag (X) |
| 19 GPIO5/ADC2_CH0 | — | nothing | no-connect flag (X) |
| 20 GPIO6 | — | nothing | no-connect flag (X) |
| 21 GPIO7 | — | nothing | no-connect flag (X) |
| 22 GPIO8 | BLE_GPIO8 | R502.2 | wire (or local label `BLE_GPIO8`) |
| 23 GPIO9 | BLE_BOOT | R504.2; MCU_A sheet: U301.14 (GPIO10) | **global label `BLE_BOOT`** |
| 24 NC | — | nothing | no-connect flag (X) |
| 25 NC | — | nothing | no-connect flag (X) |
| 26 GPIO18/USB_D- | — | nothing | no-connect flag (X) |
| 27 GPIO19/USB_D+ | — | nothing | no-connect flag (X) |
| 28 NC | — | nothing | no-connect flag (X) |
| 29 NC | — | nothing | no-connect flag (X) |
| 30 GPIO20/U0RXD | BLE_TX | TP504.1; MCU_A sheet: U301.16 (GPIO12) | **global label `BLE_TX`** |
| 31 GPIO21/U0TXD | BLE_RX | TP503.1; MCU_A sheet: U301.17 (GPIO13) | **global label `BLE_RX`** |
| 32 NC | — | nothing | no-connect flag (X) |
| 33 NC | — | nothing | no-connect flag (X) |
| 34 NC | — | nothing | no-connect flag (X) |
| 35 NC | — | nothing | no-connect flag (X) |
| 36 GND | GND |  | power symbol `GND` |
| 37 GND | GND |  | power symbol `GND` |
| 38 GND | GND |  | power symbol `GND` |
| 39 GND | GND |  | power symbol `GND` |
| 40 GND | GND |  | power symbol `GND` |
| 41 GND | GND |  | power symbol `GND` |
| 42 GND | GND |  | power symbol `GND` |
| 43 GND | GND |  | power symbol `GND` |
| 44 GND | GND |  | power symbol `GND` |
| 45 GND | GND |  | power symbol `GND` |
| 46 GND | GND |  | power symbol `GND` |
| 47 GND | GND |  | power symbol `GND` |
| 48 GND | GND |  | power symbol `GND` |
| 49 GND | GND |  | power symbol `GND` |
| 50 GND | GND |  | power symbol `GND` |
| 51 GND | GND |  | power symbol `GND` |
| 52 GND | GND |  | power symbol `GND` |
| 53 GND | GND |  | power symbol `GND` |

#### C502 · 10uF · 3V3 bulk

| Pin | Net | Connects to | Draw |
|---|---|---|---|
| 1 | +3V3 |  | power symbol `+3V3` |
| 2 | GND |  | power symbol `GND` |

#### C503 · 100nF · 3V3 at pin 3

| Pin | Net | Connects to | Draw |
|---|---|---|---|
| 1 | +3V3 |  | power symbol `+3V3` |
| 2 | GND |  | power symbol `GND` |

### Reset / boot straps

On the PCB: at the module's EN (8), GPIO8/9 (22/23), GPIO2 (5) pins

#### R501 · 10k · EN pull-up (also MCU A, open-drain)

| Pin | Net | Connects to | Draw |
|---|---|---|---|
| 1 | +3V3 |  | power symbol `+3V3` |
| 2 | BLE_EN | U501.8 (EN/CHIP_PU), C501.1; MCU_A sheet: U301.13 (GPIO9) | **global label `BLE_EN`** |

#### C501 · 1uF · EN RC delay

| Pin | Net | Connects to | Draw |
|---|---|---|---|
| 1 | BLE_EN | U501.8 (EN/CHIP_PU), R501.2; MCU_A sheet: U301.13 (GPIO9) | **global label `BLE_EN`** |
| 2 | GND |  | power symbol `GND` |

#### R502 · 10k · GPIO8 pull-up

| Pin | Net | Connects to | Draw |
|---|---|---|---|
| 1 | +3V3 |  | power symbol `+3V3` |
| 2 | BLE_GPIO8 | U501.22 (GPIO8) | wire (or local label `BLE_GPIO8`) |

#### R503 · 10k · GPIO2 pull-up

| Pin | Net | Connects to | Draw |
|---|---|---|---|
| 1 | +3V3 |  | power symbol `+3V3` |
| 2 | BLE_GPIO2 | U501.5 (GPIO2/ADC1_CH2) | wire (or local label `BLE_GPIO2`) |

#### R504 · 10k · GPIO9 (BOOT) pull-up, beats A pull-down

| Pin | Net | Connects to | Draw |
|---|---|---|---|
| 1 | +3V3 |  | power symbol `+3V3` |
| 2 | BLE_BOOT | U501.23 (GPIO9); MCU_A sheet: U301.14 (GPIO10) | **global label `BLE_BOOT`** |

### Test pads (UART, GND)

On the PCB: near the module, reachable with a probe

#### TP503 · TestPoint · TXD0

| Pin | Net | Connects to | Draw |
|---|---|---|---|
| 1 | BLE_RX | U501.31 (GPIO21/U0TXD); MCU_A sheet: U301.17 (GPIO13) | **global label `BLE_RX`** |

#### TP504 · TestPoint · RXD0

| Pin | Net | Connects to | Draw |
|---|---|---|---|
| 1 | BLE_TX | U501.30 (GPIO20/U0RXD); MCU_A sheet: U301.16 (GPIO12) | **global label `BLE_TX`** |

#### TP505 · TestPoint · GND

| Pin | Net | Connects to | Draw |
|---|---|---|---|
| 1 | GND |  | power symbol `GND` |

---

## Sheet POGO

File `pogo.kicad_sch` · 17 parts

- Power symbols: `+3V3`, `+5V`, `GND`
- Global labels on this sheet: `POGO_5V_SENSE`, `POGO_DET`, `POGO_OFF`, `POGO_RX`, `POGO_TX`
- PWR_FLAG on: none
- No-connect flags: 2

### Pogo connector (front edge)

On the PCB: front edge, centre (hand-soldered); ESD right at the pins

#### J601 · B7B-XH-A (to lid pogo board) · HAND-SOLDER: JST-XH 7-pin header; 1:1 cable to the pogo board in the dock lid (contacts: guide §8)

| Pin | Net | Connects to | Draw |
|---|---|---|---|
| 1 Pin_1 | GND |  | power symbol `GND` |
| 2 Pin_2 | POGO_5V | U602.1 (OUT), C602.1, C603.1, R607.1 | wire (or local label `POGO_5V`) |
| 3 Pin_3 | POGO_DET_J | U601.4 (D2-), R603.1 | wire (or local label `POGO_DET_J`) |
| 4 Pin_4 | POGO_RX_J | U601.3 (D2+), R602.1 | wire (or local label `POGO_RX_J`) |
| 5 Pin_5 | POGO_TX_J | U601.6 (D1-), R601.2 | wire (or local label `POGO_TX_J`) |
| 6 Pin_6 | POGO_5V | U602.1 (OUT), C602.1, C603.1, R607.1 | wire (or local label `POGO_5V`) |
| 7 Pin_7 | GND |  | power symbol `GND` |

#### U601 · TPD4E1U06DBVR · ESD on DET, TX, RX (1 spare)

| Pin | Net | Connects to | Draw |
|---|---|---|---|
| 1 D1+ | — | nothing | no-connect flag (X) |
| 2 GND | GND |  | power symbol `GND` |
| 3 D2+ | POGO_RX_J | J601.4 (Pin_4), R602.1 | wire (or local label `POGO_RX_J`) |
| 4 D2- | POGO_DET_J | J601.3 (Pin_3), R603.1 | wire (or local label `POGO_DET_J`) |
| 5 NC | — | nothing | no-connect flag (X) |
| 6 D1- | POGO_TX_J | J601.5 (Pin_5), R601.2 | wire (or local label `POGO_TX_J`) |

#### R601 · 1k · TX series

| Pin | Net | Connects to | Draw |
|---|---|---|---|
| 1 | POGO_TX | MCU_A sheet: U301.27 (GPIO16) | **global label `POGO_TX`** |
| 2 | POGO_TX_J | J601.5 (Pin_5), U601.6 (D1-) | wire (or local label `POGO_TX_J`) |

#### R602 · 1k · RX series

| Pin | Net | Connects to | Draw |
|---|---|---|---|
| 1 | POGO_RX_J | J601.4 (Pin_4), U601.3 (D2+) | wire (or local label `POGO_RX_J`) |
| 2 | POGO_RX | MCU_A sheet: U301.19 (GPIO15) | **global label `POGO_RX`** |

#### R603 · 1k · DET series

| Pin | Net | Connects to | Draw |
|---|---|---|---|
| 1 | POGO_DET_J | J601.3 (Pin_3), U601.4 (D2-) | wire (or local label `POGO_DET_J`) |
| 2 | POGO_DET | Q601.1 (G), R604.2; MCU_A sheet: U301.18 (GPIO14) | **global label `POGO_DET`** |

### Pogo 5 V switch (hardware DET enable)

On the PCB: behind J601

#### U602 · SY6280AAC · POGO_5V switch

| Pin | Net | Connects to | Draw |
|---|---|---|---|
| 1 OUT | POGO_5V | J601.2 (Pin_2), J601.6 (Pin_6), C602.1, C603.1, R607.1 | wire (or local label `POGO_5V`) |
| 2 GND | GND |  | power symbol `GND` |
| 3 ISET | POGO_ISET | R606.1 | wire (or local label `POGO_ISET`) |
| 4 EN | POGO_EN | Q601.3 (D), Q602.3 (D), R605.2 | wire (or local label `POGO_EN`) |
| 5 IN | +5V |  | power symbol `+5V` |

#### Q601 · 2N7002 · DET inverter -> U602 EN

| Pin | Net | Connects to | Draw |
|---|---|---|---|
| 1 G | POGO_DET | R603.2, R604.2; MCU_A sheet: U301.18 (GPIO14) | **global label `POGO_DET`** |
| 2 S | GND |  | power symbol `GND` |
| 3 D | POGO_EN | U602.4 (EN), Q602.3 (D), R605.2 | wire (or local label `POGO_EN`) |

#### R604 · 10k · DET pull-up to 3V3

| Pin | Net | Connects to | Draw |
|---|---|---|---|
| 1 | +3V3 |  | power symbol `+3V3` |
| 2 | POGO_DET | R603.2, Q601.1 (G); MCU_A sheet: U301.18 (GPIO14) | **global label `POGO_DET`** |

#### R605 · 100k · EN pull-up to 3V3

| Pin | Net | Connects to | Draw |
|---|---|---|---|
| 1 | +3V3 |  | power symbol `+3V3` |
| 2 | POGO_EN | U602.4 (EN), Q601.3 (D), Q602.3 (D) | wire (or local label `POGO_EN`) |

#### Q602 · 2N7002 · POGO_OFF veto: pulls EN low

| Pin | Net | Connects to | Draw |
|---|---|---|---|
| 1 G | POGO_OFF | R609.1; MCU_A sheet: U301.15 (GPIO11) | **global label `POGO_OFF`** |
| 2 S | GND |  | power symbol `GND` |
| 3 D | POGO_EN | U602.4 (EN), Q601.3 (D), R605.2 | wire (or local label `POGO_EN`) |

#### R609 · 100k · Q602 gate pull-down (no veto at reset)

| Pin | Net | Connects to | Draw |
|---|---|---|---|
| 1 | POGO_OFF | Q602.1 (G); MCU_A sheet: U301.15 (GPIO11) | **global label `POGO_OFF`** |
| 2 | GND |  | power symbol `GND` |

#### R606 · 4.7k · ISET: 6800/4700 = 1.45 A (1.09-1.81 A); 2 x 1 A +5V contacts

| Pin | Net | Connects to | Draw |
|---|---|---|---|
| 1 | POGO_ISET | U602.3 (ISET) | wire (or local label `POGO_ISET`) |
| 2 | GND |  | power symbol `GND` |

#### C601 · 1uF · POGO_5V output

| Pin | Net | Connects to | Draw |
|---|---|---|---|
| 1 | +5V |  | power symbol `+5V` |
| 2 | GND |  | power symbol `GND` |

#### C602 · 10uF · POGO_5V output

| Pin | Net | Connects to | Draw |
|---|---|---|---|
| 1 | POGO_5V | J601.2 (Pin_2), J601.6 (Pin_6), U602.1 (OUT), C603.1, R607.1 | wire (or local label `POGO_5V`) |
| 2 | GND |  | power symbol `GND` |

#### C603 · 1uF · U602 input

| Pin | Net | Connects to | Draw |
|---|---|---|---|
| 1 | POGO_5V | J601.2 (Pin_2), J601.6 (Pin_6), U602.1 (OUT), C602.1, R607.1 | wire (or local label `POGO_5V`) |
| 2 | GND |  | power symbol `GND` |

#### R607 · 10k · POGO_5V divider top -> ADC

| Pin | Net | Connects to | Draw |
|---|---|---|---|
| 1 | POGO_5V | J601.2 (Pin_2), J601.6 (Pin_6), U602.1 (OUT), C602.1, C603.1 | wire (or local label `POGO_5V`) |
| 2 | POGO_5V_SENSE | R608.1; MCU_A sheet: U301.40 (GPIO26/ADC0) | **global label `POGO_5V_SENSE`** |

#### R608 · 15k · POGO_5V divider bottom

| Pin | Net | Connects to | Draw |
|---|---|---|---|
| 1 | POGO_5V_SENSE | R607.2; MCU_A sheet: U301.40 (GPIO26/ADC0) | **global label `POGO_5V_SENSE`** |
| 2 | GND |  | power symbol `GND` |

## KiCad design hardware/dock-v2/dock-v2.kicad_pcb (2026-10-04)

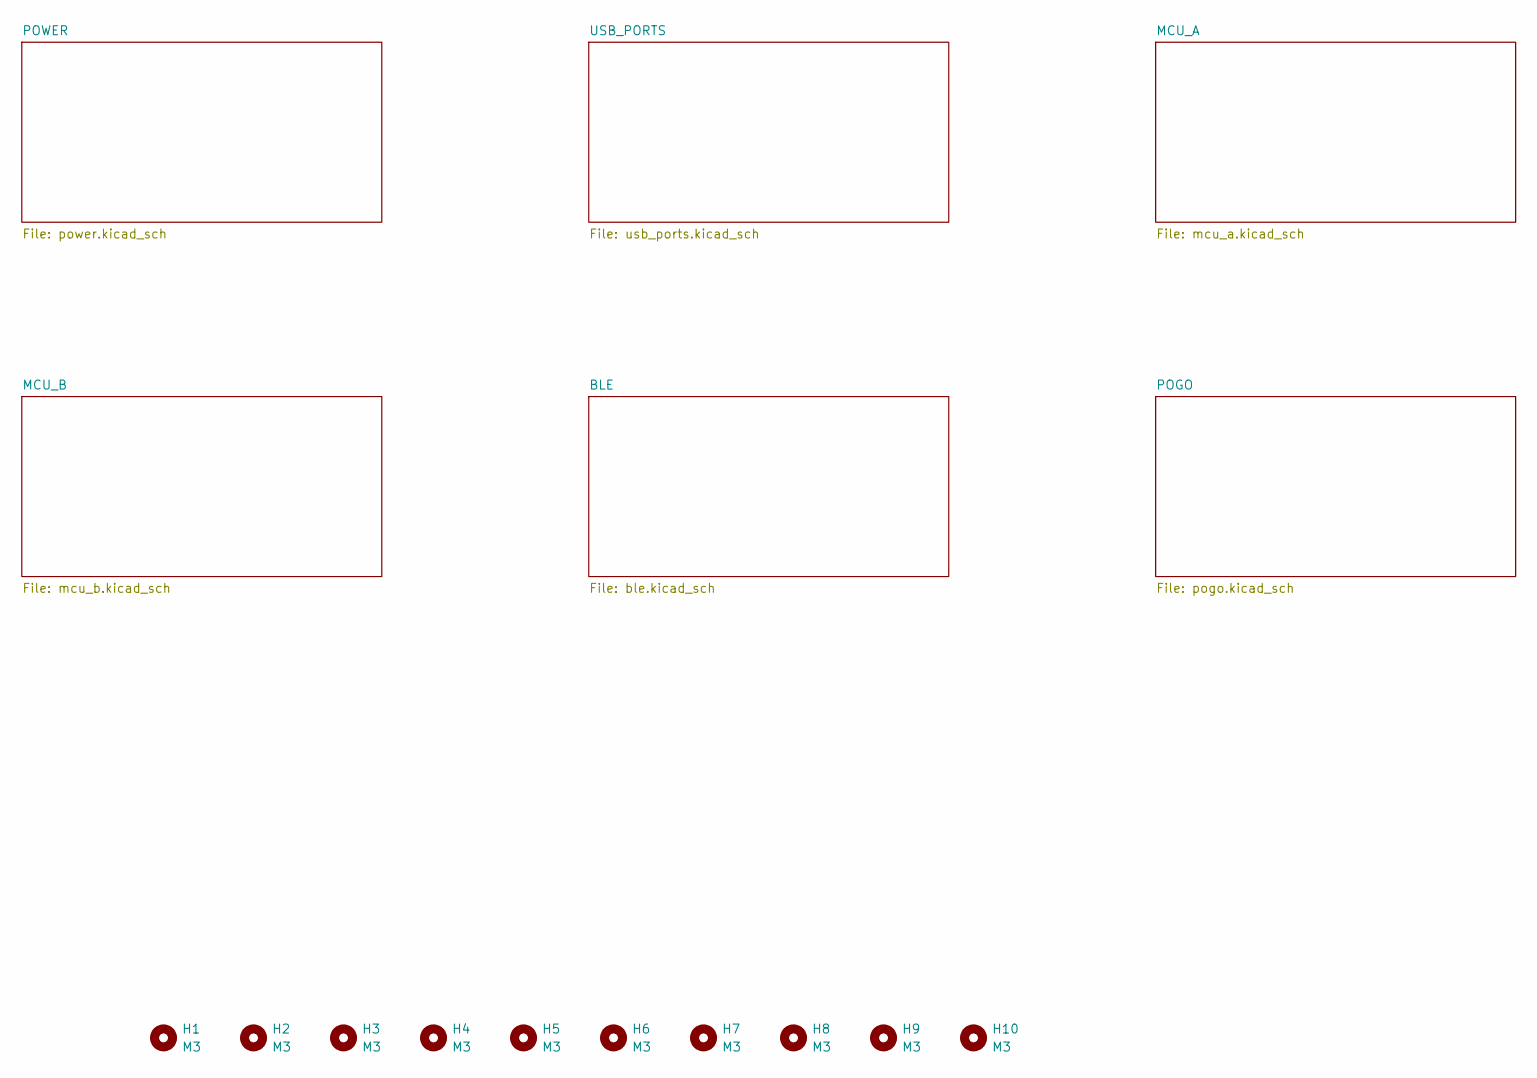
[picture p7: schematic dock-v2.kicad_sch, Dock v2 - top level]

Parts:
H1, H2, H3, H4, H5, H6, H7, H8, H9, H10: M3; MountingHole_3.2mm_M3

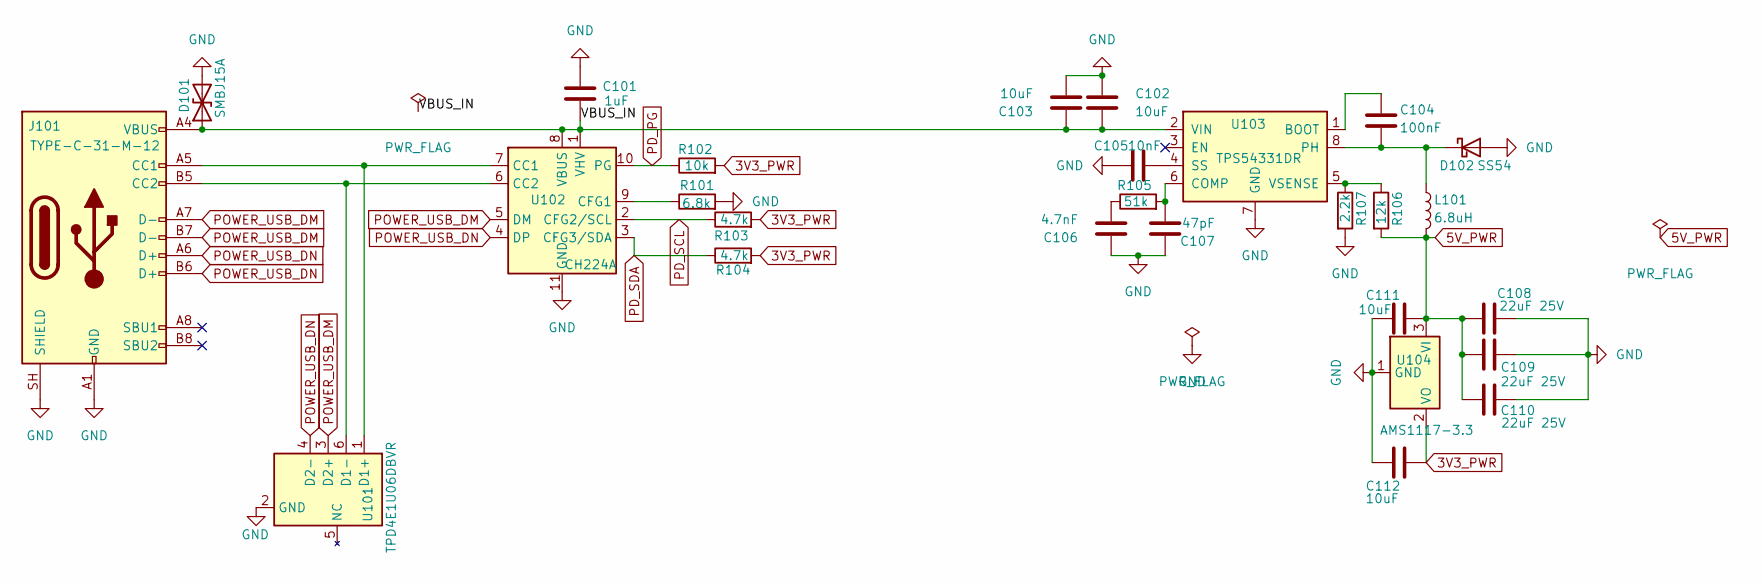
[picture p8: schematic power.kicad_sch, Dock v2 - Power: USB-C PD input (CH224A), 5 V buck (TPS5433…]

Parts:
C101: 1uF; C_0603_1608Metric; LCSC C15849
C102, C103, C111, C112: 10uF; C_0805_2012Metric; LCSC C15850
C104: 100nF; C_0402_1005Metric; LCSC C1525
C105: 10nF; C_0402_1005Metric; LCSC C15195
C106: 4.7nF; C_0402_1005Metric; LCSC C1538
C107: 47pF; C_0402_1005Metric; LCSC C1567
C108, C109, C110: 22uF 25V; C_1206_3216Metric; LCSC C12891
D101: SMBJ15A; D_SMB; LCSC C113988
D102: SS54; D_SMC; LCSC C22452
J101: TYPE-C-31-M-12; USB_C_Receptacle_HRO_TYPE-C-31-M-12; LCSC C165948
L101: 6.8uH; L_TechFuse_SL0630; LCSC C207841
R101: 6.8k; R_0402_1005Metric; LCSC C25917
R102: 10k; R_0402_1005Metric; LCSC C25744
R103, R104: 4.7k; R_0402_1005Metric; LCSC C25900
R105: 51k; R_0402_1005Metric; LCSC C25794
R106: 12k; R_0402_1005Metric; LCSC C25752
R107: 2.2k; R_0402_1005Metric; LCSC C25879
U101: TPD4E1U06DBVR; SOT-23-6; LCSC C124691
U102: CH224A; SSOP-10-1EP_3.9x4.9mm_P1mm_EP2.1x3.3mm; LCSC C42459160
U103: TPS54331DR; SOIC-8_3.9x4.9mm_P1.27mm; LCSC C9865
U104: AMS1117-3.3; SOT-223-3_TabPin2; LCSC C6186

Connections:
3V3_PWR: C112.1, R102.2, R103.2, R104.2, U104.2 (VO); also elsewhere on the board
5V_PWR: C108.1, C109.2, C110.1, C111.1, L101.2, R106.2, U104.3 (VI); also elsewhere on the board
/POWER/VBUS_IN: C101.2, C102.2, C103.1, D101.1 (A1), J101.A4 (VBUS), J101.A9 (VBUS), J101.B4 (VBUS), J101.B9 (VBUS), U102.1 (VHV), U102.8 (VBUS), U103.2 (VIN)
GND: C101.1, C102.1, C103.2, C105.1, C106.1, C107.1, C108.2, C109.1, C110.2, C111.2, C112.2, D101.2 (A2), D102.2 (A), J101.A1 (GND), J101.A12 (GND), J101.B1 (GND), J101.B12 (GND), J101.SH (SHIELD), R101.2, R107.2, U101.2 (GND), U102.11 (GND), U103.7 (GND), U104.1 (GND); also elsewhere on the board
unnamed: C106.2, R105.1
unnamed: C104.2, D102.1 (K), L101.1, U103.8 (PH)
unnamed: J101.A5 (CC1), U101.1 (D1+), U102.7 (CC1)
unnamed: J101.B5 (CC2), U101.6 (D1-), U102.6 (CC2)
unnamed: R101.1, U102.9 (CFG1)
unnamed: C104.1, U103.1 (BOOT)
unnamed: C107.2, R105.2, U103.6 (COMP)
unnamed: C105.2, U103.4 (SS)
unnamed: R106.1, R107.1, U103.5 (VSENSE)
PD_PG: R102.1, U102.10 (PG); also elsewhere on the board
PD_SCL: R103.1, U102.2 (CFG2/SCL); also elsewhere on the board
PD_SDA: R104.1, U102.3 (CFG3/SDA); also elsewhere on the board
POWER_USB_DM: J101.A7 (D-), J101.B7 (D-), U101.3 (D2+), U102.5 (DM)
POWER_USB_DN: J101.A6 (D+), J101.B6 (D+), U101.4 (D2-), U102.4 (DP)

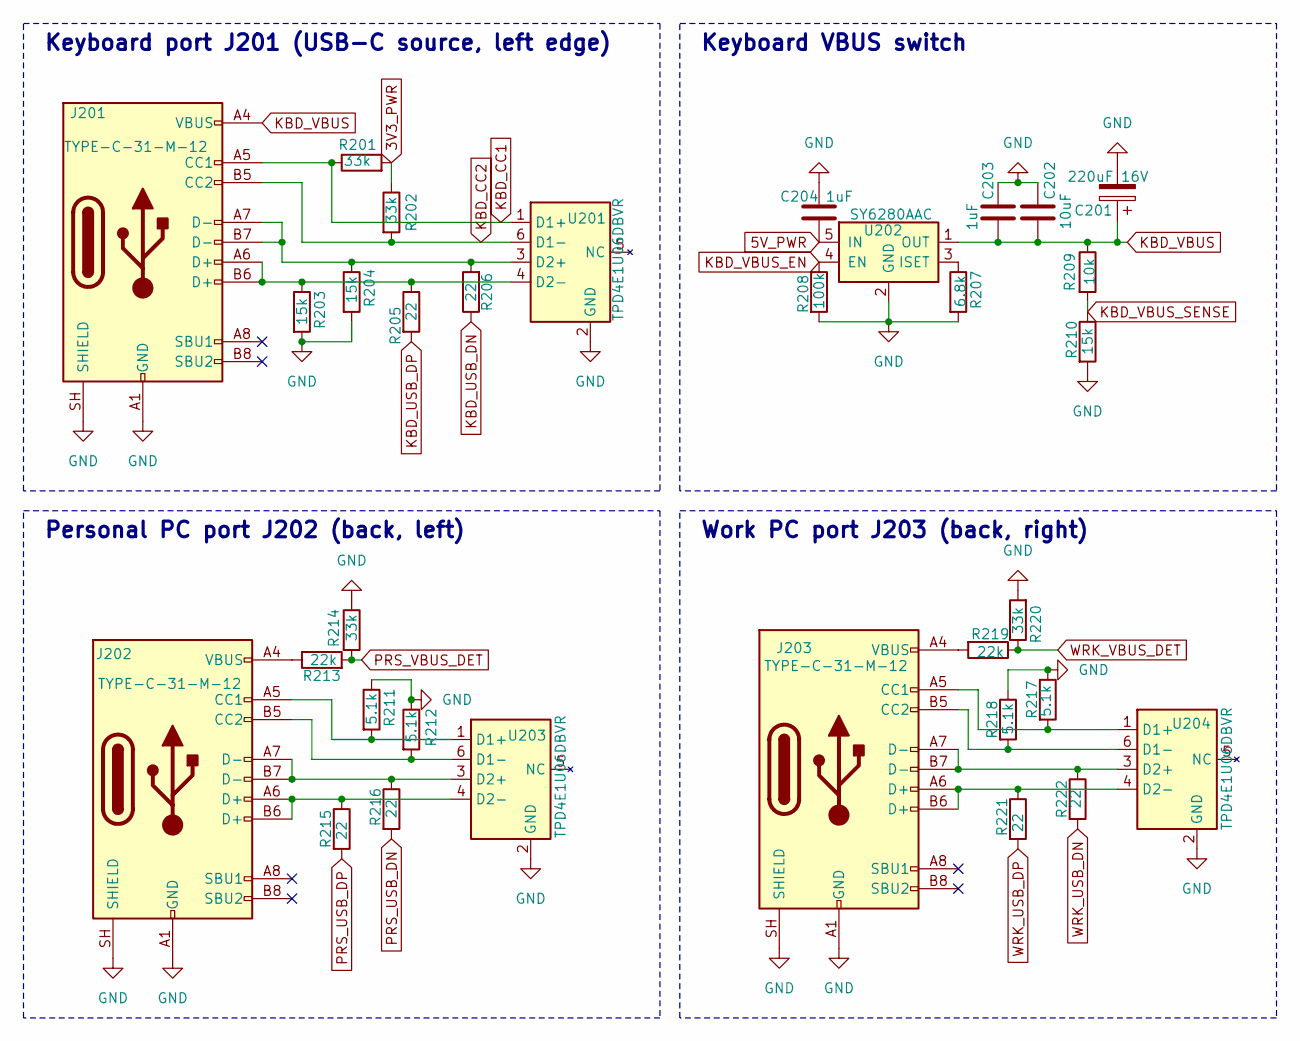
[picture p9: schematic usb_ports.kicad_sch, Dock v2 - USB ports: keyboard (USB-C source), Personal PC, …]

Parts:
C201: 220uF 16V; CP_Radial_D6.3mm_P5.00mm
C202: 10uF; C_0805_2012Metric; LCSC C15850
C203, C204: 1uF; C_0402_1005Metric; LCSC C52923
J201, J202, J203: TYPE-C-31-M-12; USB_C_Receptacle_HRO_TYPE-C-31-M-12; LCSC C165948
R201, R202, R214, R220: 33k; R_0402_1005Metric; LCSC C25779
R203, R204, R210: 15k; R_0402_1005Metric; LCSC C25756
R205, R206, R215, R216, R221, R222: 22; R_0402_1005Metric; LCSC C25092
R207: 6.8k; R_0402_1005Metric; LCSC C25917
R208: 100k; R_0402_1005Metric; LCSC C25741
R209: 10k; R_0402_1005Metric; LCSC C25744
R211, R212, R217, R218: 5.1k; R_0402_1005Metric; LCSC C25905
R213, R219: 22k; R_0402_1005Metric; LCSC C25768
U201, U203, U204: TPD4E1U06DBVR; SOT-23-6; LCSC C124691
U202: SY6280AAC; SOT-23-5; LCSC C55136

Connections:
3V3_PWR: R201.2, R202.1; also elsewhere on the board
5V_PWR: C204.2, U202.5 (IN); also elsewhere on the board
GND: C201.2, C202.1, C203.2, C204.1, J201.A1 (GND), J201.A12 (GND), J201.B1 (GND), J201.B12 (GND), J201.SH (SHIELD), J202.A1 (GND), J202.A12 (GND), J202.B1 (GND), J202.B12 (GND), J202.SH (SHIELD), J203.A1 (GND), J203.A12 (GND), J203.B1 (GND), J203.B12 (GND), J203.SH (SHIELD), R203.2, R204.2, R207.2, R208.2, R210.2, R211.1, R212.1, R214.1, R217.1, R218.1, R220.2, U201.2 (GND), U202.2 (GND), U203.2 (GND), U204.2 (GND); also elsewhere on the board
KBD_CC1: J201.A5 (CC1), R201.1, U201.1 (D1+); also elsewhere on the board
KBD_CC2: J201.B5 (CC2), R202.2, U201.6 (D1-); also elsewhere on the board
KBD_USB_DN: R206.1; also elsewhere on the board
KBD_USB_DP: R205.2; also elsewhere on the board
KBD_VBUS: C201.1, C202.2, C203.1, J201.A4 (VBUS), J201.A9 (VBUS), J201.B4 (VBUS), J201.B9 (VBUS), R209.1, U202.1 (OUT)
KBD_VBUS_EN: R208.1, U202.4 (EN); also elsewhere on the board
KBD_VBUS_SENSE: R209.2, R210.1; also elsewhere on the board
unnamed: J202.A5 (CC1), R211.2, U203.1 (D1+)
unnamed: J202.B5 (CC2), R212.2, U203.6 (D1-)
unnamed: J202.A4 (VBUS), J202.A9 (VBUS), J202.B4 (VBUS), J202.B9 (VBUS), R213.1
unnamed: J203.A5 (CC1), R217.2, U204.1 (D1+)
unnamed: J203.B5 (CC2), R218.2, U204.6 (D1-)
unnamed: J203.A4 (VBUS), J203.A9 (VBUS), J203.B4 (VBUS), J203.B9 (VBUS), R219.2
unnamed: J201.A7 (D-), J201.B7 (D-), R204.1, R206.2, U201.3 (D2+)
unnamed: J201.A6 (D+), J201.B6 (D+), R203.1, R205.1, U201.4 (D2-)
unnamed: R207.1, U202.3 (ISET)
unnamed: J202.A7 (D-), J202.B7 (D-), R216.1, U203.3 (D2+)
unnamed: J202.A6 (D+), J202.B6 (D+), R215.1, U203.4 (D2-)
unnamed: J203.A7 (D-), J203.B7 (D-), R222.1, U204.3 (D2+)
unnamed: J203.A6 (D+), J203.B6 (D+), R221.1, U204.4 (D2-)
PRS_USB_DN: R216.2; also elsewhere on the board
PRS_USB_DP: R215.2; also elsewhere on the board
PRS_VBUS_DET: R213.2, R214.2; also elsewhere on the board
WRK_USB_DN: R222.2; also elsewhere on the board
WRK_USB_DP: R221.2; also elsewhere on the board
WRK_VBUS_DET: R219.1, R220.1; also elsewhere on the board

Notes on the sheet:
Keyboard VBUS switch
Keyboard port J201 (USB-C source, left edge)
Personal PC port J202 (back, left)
Work PC port J203 (back, right)

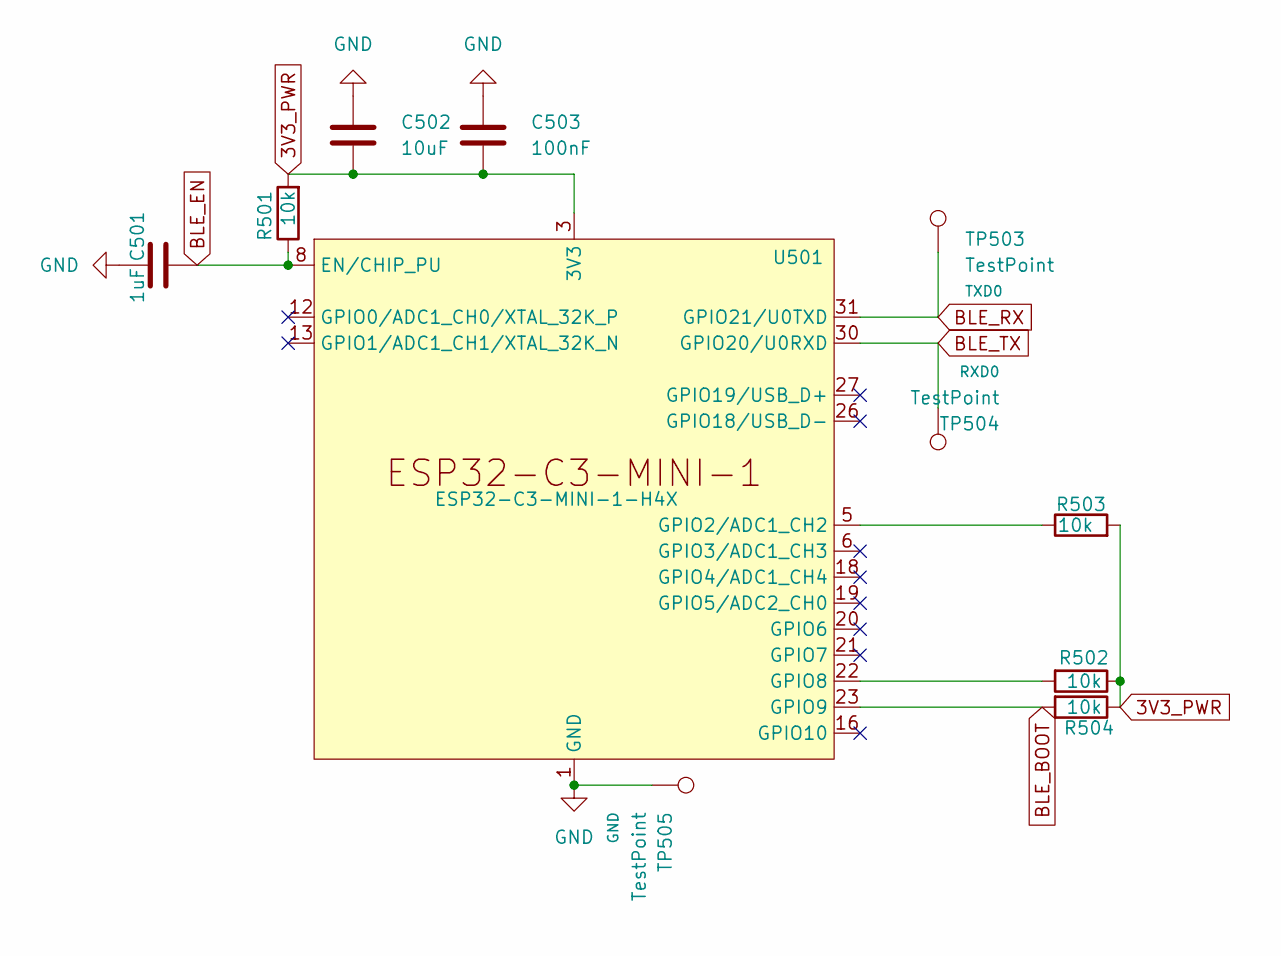
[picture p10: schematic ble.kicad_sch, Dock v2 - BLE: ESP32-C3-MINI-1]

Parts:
C501: 1uF; C_0402_1005Metric; LCSC C52923
C502: 10uF; C_0805_2012Metric; LCSC C15850
C503: 100nF; C_0402_1005Metric; LCSC C1525
R501, R502, R503, R504: 10k; R_0402_1005Metric; LCSC C25744
TP503, TP504, TP505: TestPoint; TestPoint_Pad_D1.0mm
U501: ESP32-C3-MINI-1-H4X; ESP32-C3-MINI-1; LCSC C41349510

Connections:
3V3_PWR: C502.2, C503.2, R501.2, R502.1, R503.2, R504.1, U501.3 (3V3); also elsewhere on the board
BLE_BOOT: R504.2, U501.23 (GPIO9); also elsewhere on the board
BLE_EN: C501.2, R501.1, U501.8 (EN/CHIP_PU); also elsewhere on the board
BLE_RX: TP503.1 (1_1), U501.31 (GPIO21/U0TXD); also elsewhere on the board
BLE_TX: TP504.1 (1_1), U501.30 (GPIO20/U0RXD); also elsewhere on the board
GND: C501.1, C502.1, C503.1, TP505.1 (1_1), U501.1 (GND), U501.2 (GND), U501.11 (GND), U501.14 (GND), U501.36 (GND), U501.37 (GND), U501.38 (GND), U501.39 (GND), U501.40 (GND), U501.41 (GND), U501.42 (GND), U501.43 (GND), U501.44 (GND), U501.45 (GND), U501.46 (GND), U501.47 (GND), U501.48 (GND), U501.49 (GND), U501.50 (GND), U501.51 (GND), U501.52 (GND), U501.53 (GND); also elsewhere on the board
unnamed: R503.1, U501.5 (GPIO2/ADC1_CH2)
unnamed: R502.2, U501.22 (GPIO8)

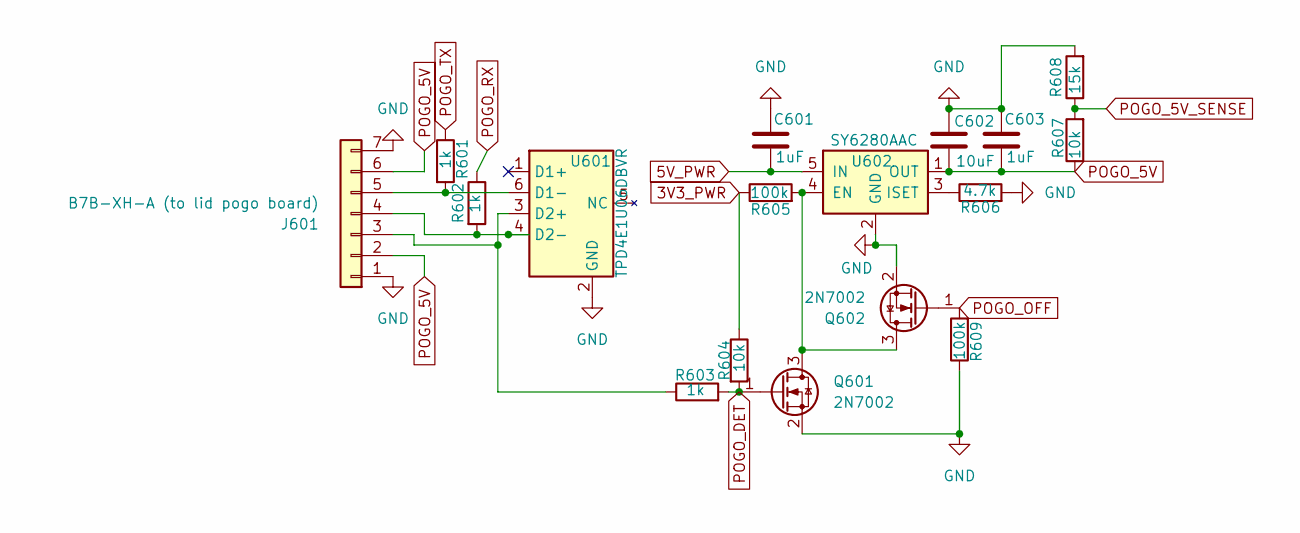
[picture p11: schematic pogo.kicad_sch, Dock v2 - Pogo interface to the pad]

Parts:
C601, C603: 1uF; C_0402_1005Metric; LCSC C52923
C602: 10uF; C_0805_2012Metric; LCSC C15850
J601: B7B-XH-A (to lid pogo board); JST_XH_B7B-XH-A_1x07_P2.50mm_Vertical_EdgeTrim; LCSC C144398
Q601, Q602: 2N7002; SOT-23; LCSC C8545
R601, R602, R603: 1k; R_0402_1005Metric; LCSC C11702
R604, R607: 10k; R_0402_1005Metric; LCSC C25744
R605, R609: 100k; R_0402_1005Metric; LCSC C25741
R606: 4.7k; R_0402_1005Metric; LCSC C25900
R608: 15k; R_0402_1005Metric; LCSC C25756
U601: TPD4E1U06DBVR; SOT-23-6; LCSC C124691
U602: SY6280AAC; SOT-23-5; LCSC C55136

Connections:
3V3_PWR: R604.1, R605.1; also elsewhere on the board
5V_PWR: C601.2, U602.5 (IN); also elsewhere on the board
GND: C601.1, C602.1, C603.1, J601.1, J601.7, Q601.2 (S), Q602.2 (S), R606.2, R608.2, R609.1, U601.2 (GND), U602.2 (GND); also elsewhere on the board
unnamed: J601.3, R603.1, U601.3 (D2+)
unnamed: J601.4, R602.2, U601.4 (D2-)
unnamed: J601.5, R601.2, U601.6 (D1-)
unnamed: Q601.3 (D), Q602.3 (D), R605.2, U602.4 (EN)
unnamed: R606.1, U602.3 (ISET)
POGO_5V: C602.2, C603.2, J601.2, J601.6, R607.1, U602.1 (OUT)
POGO_5V_SENSE: R607.2, R608.1; also elsewhere on the board
POGO_DET: Q601.1 (G), R603.2, R604.2; also elsewhere on the board
POGO_OFF: Q602.1 (G), R609.2; also elsewhere on the board
POGO_RX: R602.1; also elsewhere on the board
POGO_TX: R601.1; also elsewhere on the board

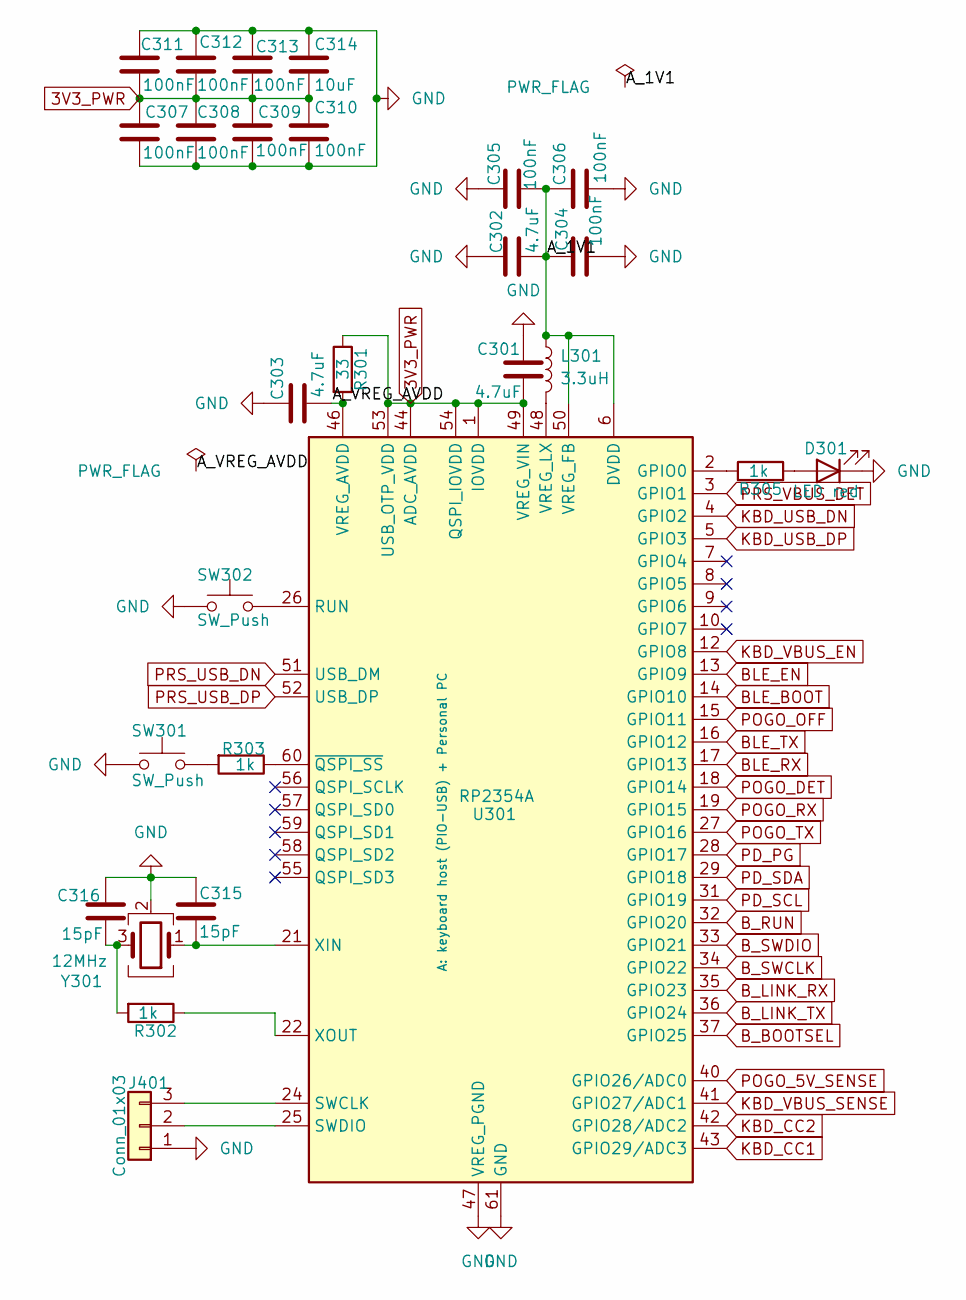
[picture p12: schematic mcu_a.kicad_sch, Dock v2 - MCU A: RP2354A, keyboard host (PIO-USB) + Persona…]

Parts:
C301, C302: 4.7uF; C_0402_RPi_Wide; LCSC C23733
C303: 4.7uF; C_0402_1005Metric; LCSC C23733
C304, C305, C306, C307, C308, C309, C310, C311, C312, C313: 100nF; C_0402_1005Metric; LCSC C1525
C314: 10uF; C_0805_2012Metric; LCSC C15850
C315, C316: 15pF; C_0402_1005Metric; LCSC C1548
D301: LED red; LED_0603_1608Metric; LCSC C2286
J401: Conn_01x03; PinHeader_1x03_P2.54mm_Vertical
L301: 3.3uH; L_Abracon_AOTA-B201610S3R3_0806; LCSC C42411119
R301: 33; R_0402_1005Metric; LCSC C25105
R302, R303, R305: 1k; R_0402_1005Metric; LCSC C11702
SW301, SW302: SW_Push; SW_Push_1P1T_XKB_TS-1187A; LCSC C318884
U301: RP2354A; RP2350A_QFN-60_RPi_Vias; LCSC C41378174
Y301: 12MHz; Crystal_SMD_3225-4Pin_3.2x2.5mm; LCSC C20625731

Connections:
3V3_PWR: C301.2, C307.1, C308.1, C309.1, C310.1, C311.2, C312.2, C313.2, C314.2, R301.1, U301.1 (IOVDD), U301.11 (IOVDD), U301.20 (IOVDD), U301.30 (IOVDD), U301.38 (IOVDD), U301.44 (ADC_AVDD), U301.45 (IOVDD), U301.49 (VREG_VIN), U301.53 (USB_OTP_VDD), U301.54 (QSPI_IOVDD); also elsewhere on the board
/MCU_A/A_1V1: C302.2, C304.1, C305.2, C306.1, L301.1, U301.6 (DVDD), U301.23 (DVDD), U301.39 (DVDD), U301.50 (VREG_FB)
/MCU_A/A_VREG_AVDD: C303.2, R301.2, U301.46 (VREG_AVDD)
BLE_BOOT: U301.14 (GPIO10); also elsewhere on the board
BLE_EN: U301.13 (GPIO9); also elsewhere on the board
BLE_RX: U301.17 (GPIO13); also elsewhere on the board
BLE_TX: U301.16 (GPIO12); also elsewhere on the board
B_BOOTSEL: U301.37 (GPIO25); also elsewhere on the board
B_LINK_RX: U301.35 (GPIO23); also elsewhere on the board
B_LINK_TX: U301.36 (GPIO24); also elsewhere on the board
B_RUN: U301.32 (GPIO20); also elsewhere on the board
B_SWCLK: U301.34 (GPIO22); also elsewhere on the board
B_SWDIO: U301.33 (GPIO21); also elsewhere on the board
GND: C301.1, C302.1, C303.1, C304.2, C305.1, C306.2, C307.2, C308.2, C309.2, C310.2, C311.1, C312.1, C313.1, C314.1, C315.1, C316.1, D301.1 (K), J401.1, SW301.1, SW302.1, U301.47 (VREG_PGND), U301.61 (GND), Y301.2 (G), Y301.4 (G); also elsewhere on the board
KBD_CC1: U301.43 (GPIO29/ADC3); also elsewhere on the board
KBD_CC2: U301.42 (GPIO28/ADC2); also elsewhere on the board
KBD_USB_DN: U301.4 (GPIO2); also elsewhere on the board
KBD_USB_DP: U301.5 (GPIO3); also elsewhere on the board
KBD_VBUS_EN: U301.12 (GPIO8); also elsewhere on the board
KBD_VBUS_SENSE: U301.41 (GPIO27/ADC1); also elsewhere on the board
unnamed: C316.2, R302.2, Y301.3
unnamed: D301.2 (A), R305.2
unnamed: J401.2, U301.25 (SWDIO)
unnamed: J401.3, U301.24 (SWCLK)
unnamed: R303.2, SW301.2
unnamed: R305.1, U301.2 (GPIO0)
unnamed: SW302.2, U301.26 (RUN)
unnamed: L301.2, U301.48 (VREG_LX)
unnamed: C315.2, U301.21 (XIN), Y301.1
unnamed: R302.1, U301.22 (XOUT)
unnamed: R303.1, U301.60 (~QSPI_SS)
PD_PG: U301.28 (GPIO17); also elsewhere on the board
PD_SCL: U301.31 (GPIO19); also elsewhere on the board
PD_SDA: U301.29 (GPIO18); also elsewhere on the board
POGO_5V_SENSE: U301.40 (GPIO26/ADC0); also elsewhere on the board
POGO_DET: U301.18 (GPIO14); also elsewhere on the board
POGO_OFF: U301.15 (GPIO11); also elsewhere on the board
POGO_RX: U301.19 (GPIO15); also elsewhere on the board
POGO_TX: U301.27 (GPIO16); also elsewhere on the board
PRS_USB_DN: U301.51 (USB_DM); also elsewhere on the board
PRS_USB_DP: U301.52 (USB_DP); also elsewhere on the board
PRS_VBUS_DET: U301.3 (GPIO1); also elsewhere on the board

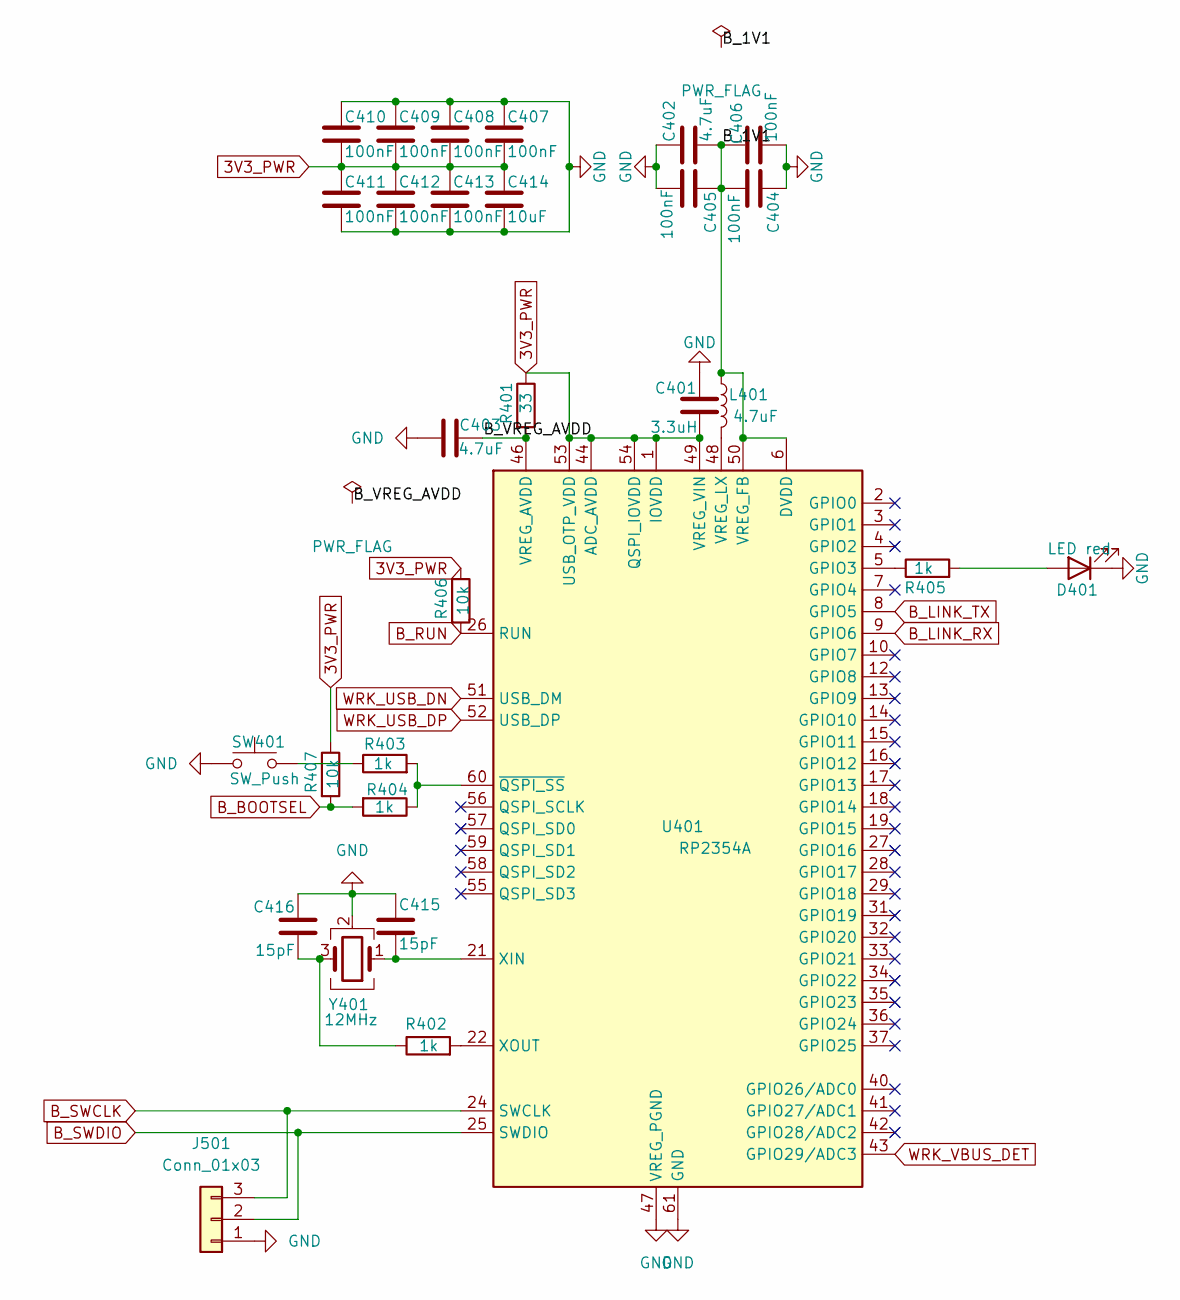
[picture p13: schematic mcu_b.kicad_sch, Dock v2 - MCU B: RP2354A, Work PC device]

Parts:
C401, C402: 4.7uF; C_0402_RPi_Wide; LCSC C23733
C403: 4.7uF; C_0402_1005Metric; LCSC C23733
C404, C405, C406, C407, C408, C409, C410, C411, C412, C413: 100nF; C_0402_1005Metric; LCSC C1525
C414: 10uF; C_0805_2012Metric; LCSC C15850
C415, C416: 15pF; C_0402_1005Metric; LCSC C1548
D401: LED red; LED_0603_1608Metric; LCSC C2286
J501: Conn_01x03; PinHeader_1x03_P2.54mm_Vertical
L401: 3.3uH; L_Abracon_AOTA-B201610S3R3_0806; LCSC C42411119
R401: 33; R_0402_1005Metric; LCSC C25105
R402, R403, R404, R405: 1k; R_0402_1005Metric; LCSC C11702
R406, R407: 10k; R_0402_1005Metric; LCSC C25744
SW401: SW_Push; SW_Push_1P1T_XKB_TS-1187A; LCSC C318884
U401: RP2354A; RP2350A_QFN-60_RPi_Vias; LCSC C41378174
Y401: 12MHz; Crystal_SMD_3225-4Pin_3.2x2.5mm; LCSC C20625731

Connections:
3V3_PWR: C401.2, C407.2, C408.2, C409.2, C410.2, C411.1, C412.1, C413.1, C414.1, R401.1, R406.1, R407.1, U401.1 (IOVDD), U401.11 (IOVDD), U401.20 (IOVDD), U401.30 (IOVDD), U401.38 (IOVDD), U401.44 (ADC_AVDD), U401.45 (IOVDD), U401.49 (VREG_VIN), U401.53 (USB_OTP_VDD), U401.54 (QSPI_IOVDD); also elsewhere on the board
/MCU_B/B_1V1: C402.2, C404.2, C405.1, C406.1, L401.1, U401.6 (DVDD), U401.23 (DVDD), U401.39 (DVDD), U401.50 (VREG_FB)
/MCU_B/B_VREG_AVDD: C403.2, R401.2, U401.46 (VREG_AVDD)
B_BOOTSEL: R404.2, R407.2; also elsewhere on the board
B_LINK_RX: U401.9 (GPIO6); also elsewhere on the board
B_LINK_TX: U401.8 (GPIO5); also elsewhere on the board
B_RUN: R406.2, U401.26 (RUN); also elsewhere on the board
B_SWCLK: J501.3, U401.24 (SWCLK); also elsewhere on the board
B_SWDIO: J501.2, U401.25 (SWDIO); also elsewhere on the board
GND: C401.1, C402.1, C403.1, C404.1, C405.2, C406.2, C407.1, C408.1, C409.1, C410.1, C411.2, C412.2, C413.2, C414.2, C415.1, C416.2, D401.1 (K), J501.1, SW401.1, U401.47 (VREG_PGND), U401.61 (GND), Y401.2 (G), Y401.4 (G); also elsewhere on the board
unnamed: C416.1, R402.1, Y401.3
unnamed: D401.2 (A), R405.2
unnamed: R403.1, SW401.2
unnamed: R405.1, U401.5 (GPIO3)
unnamed: L401.2, U401.48 (VREG_LX)
unnamed: C415.2, U401.21 (XIN), Y401.1
unnamed: R402.2, U401.22 (XOUT)
unnamed: R403.2, R404.1, U401.60 (~QSPI_SS)
WRK_USB_DN: U401.51 (USB_DM); also elsewhere on the board
WRK_USB_DP: U401.52 (USB_DP); also elsewhere on the board
WRK_VBUS_DET: U401.43 (GPIO29/ADC3); also elsewhere on the board

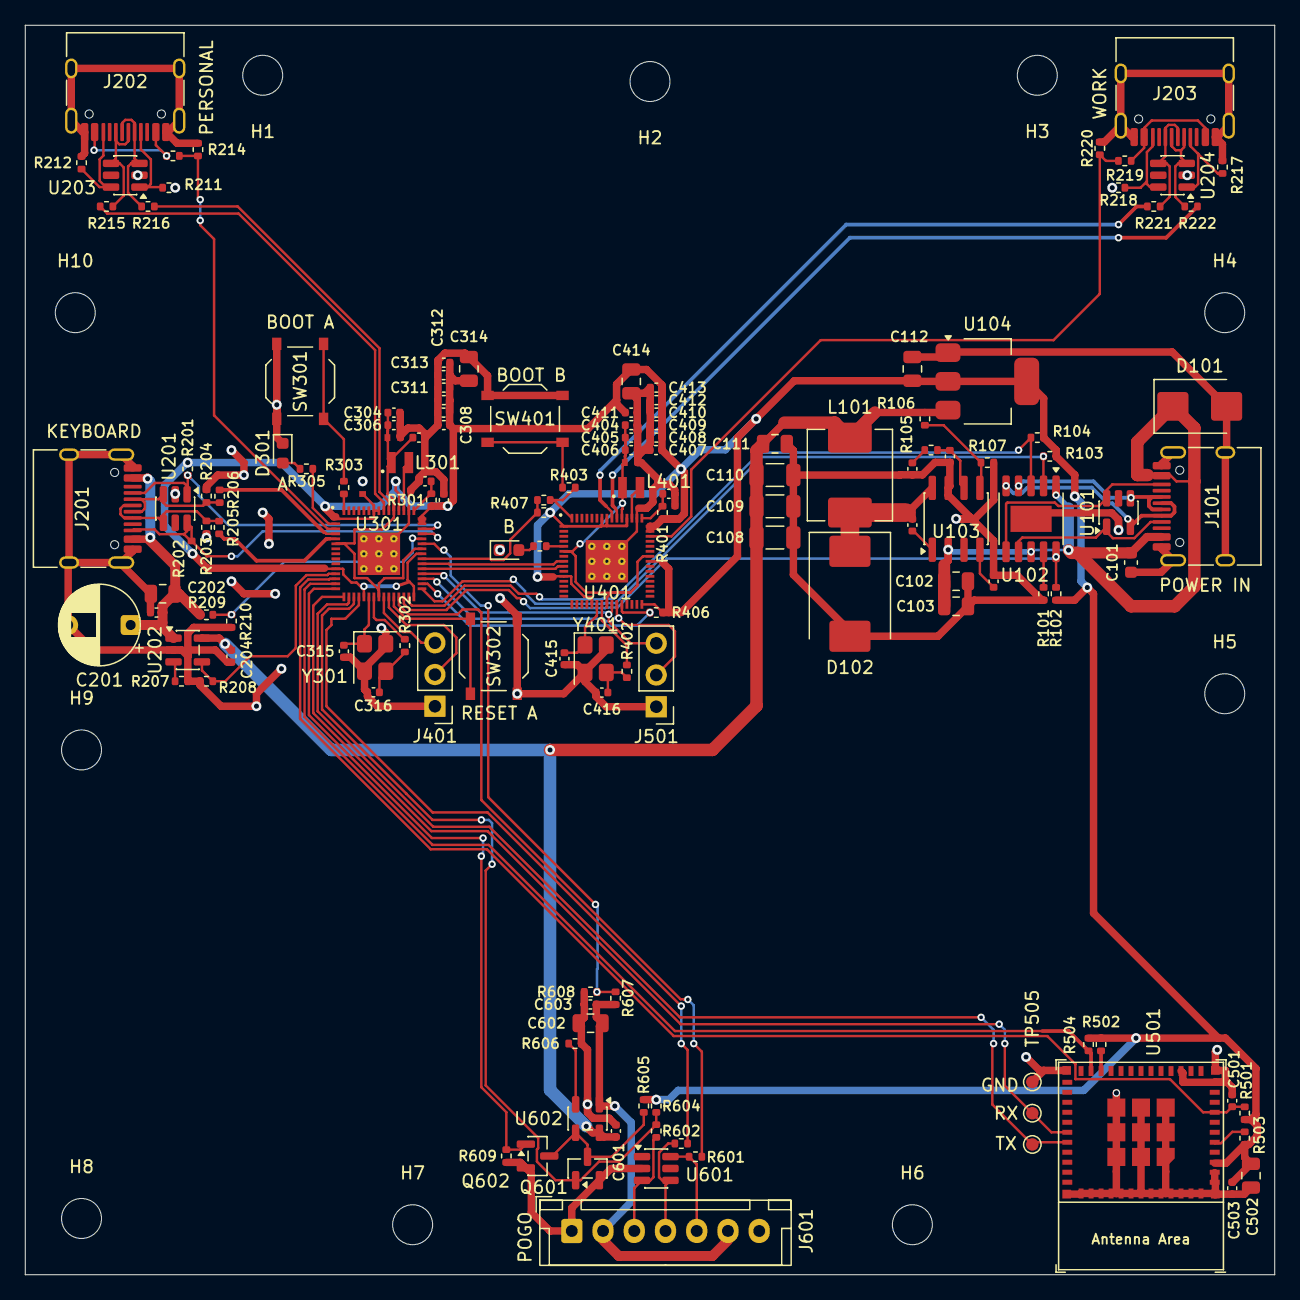
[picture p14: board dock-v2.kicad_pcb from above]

Board: 2 copper layers, 100.0 x 100.0 mm, 154 parts (0 on the bottom side), 90 nets.

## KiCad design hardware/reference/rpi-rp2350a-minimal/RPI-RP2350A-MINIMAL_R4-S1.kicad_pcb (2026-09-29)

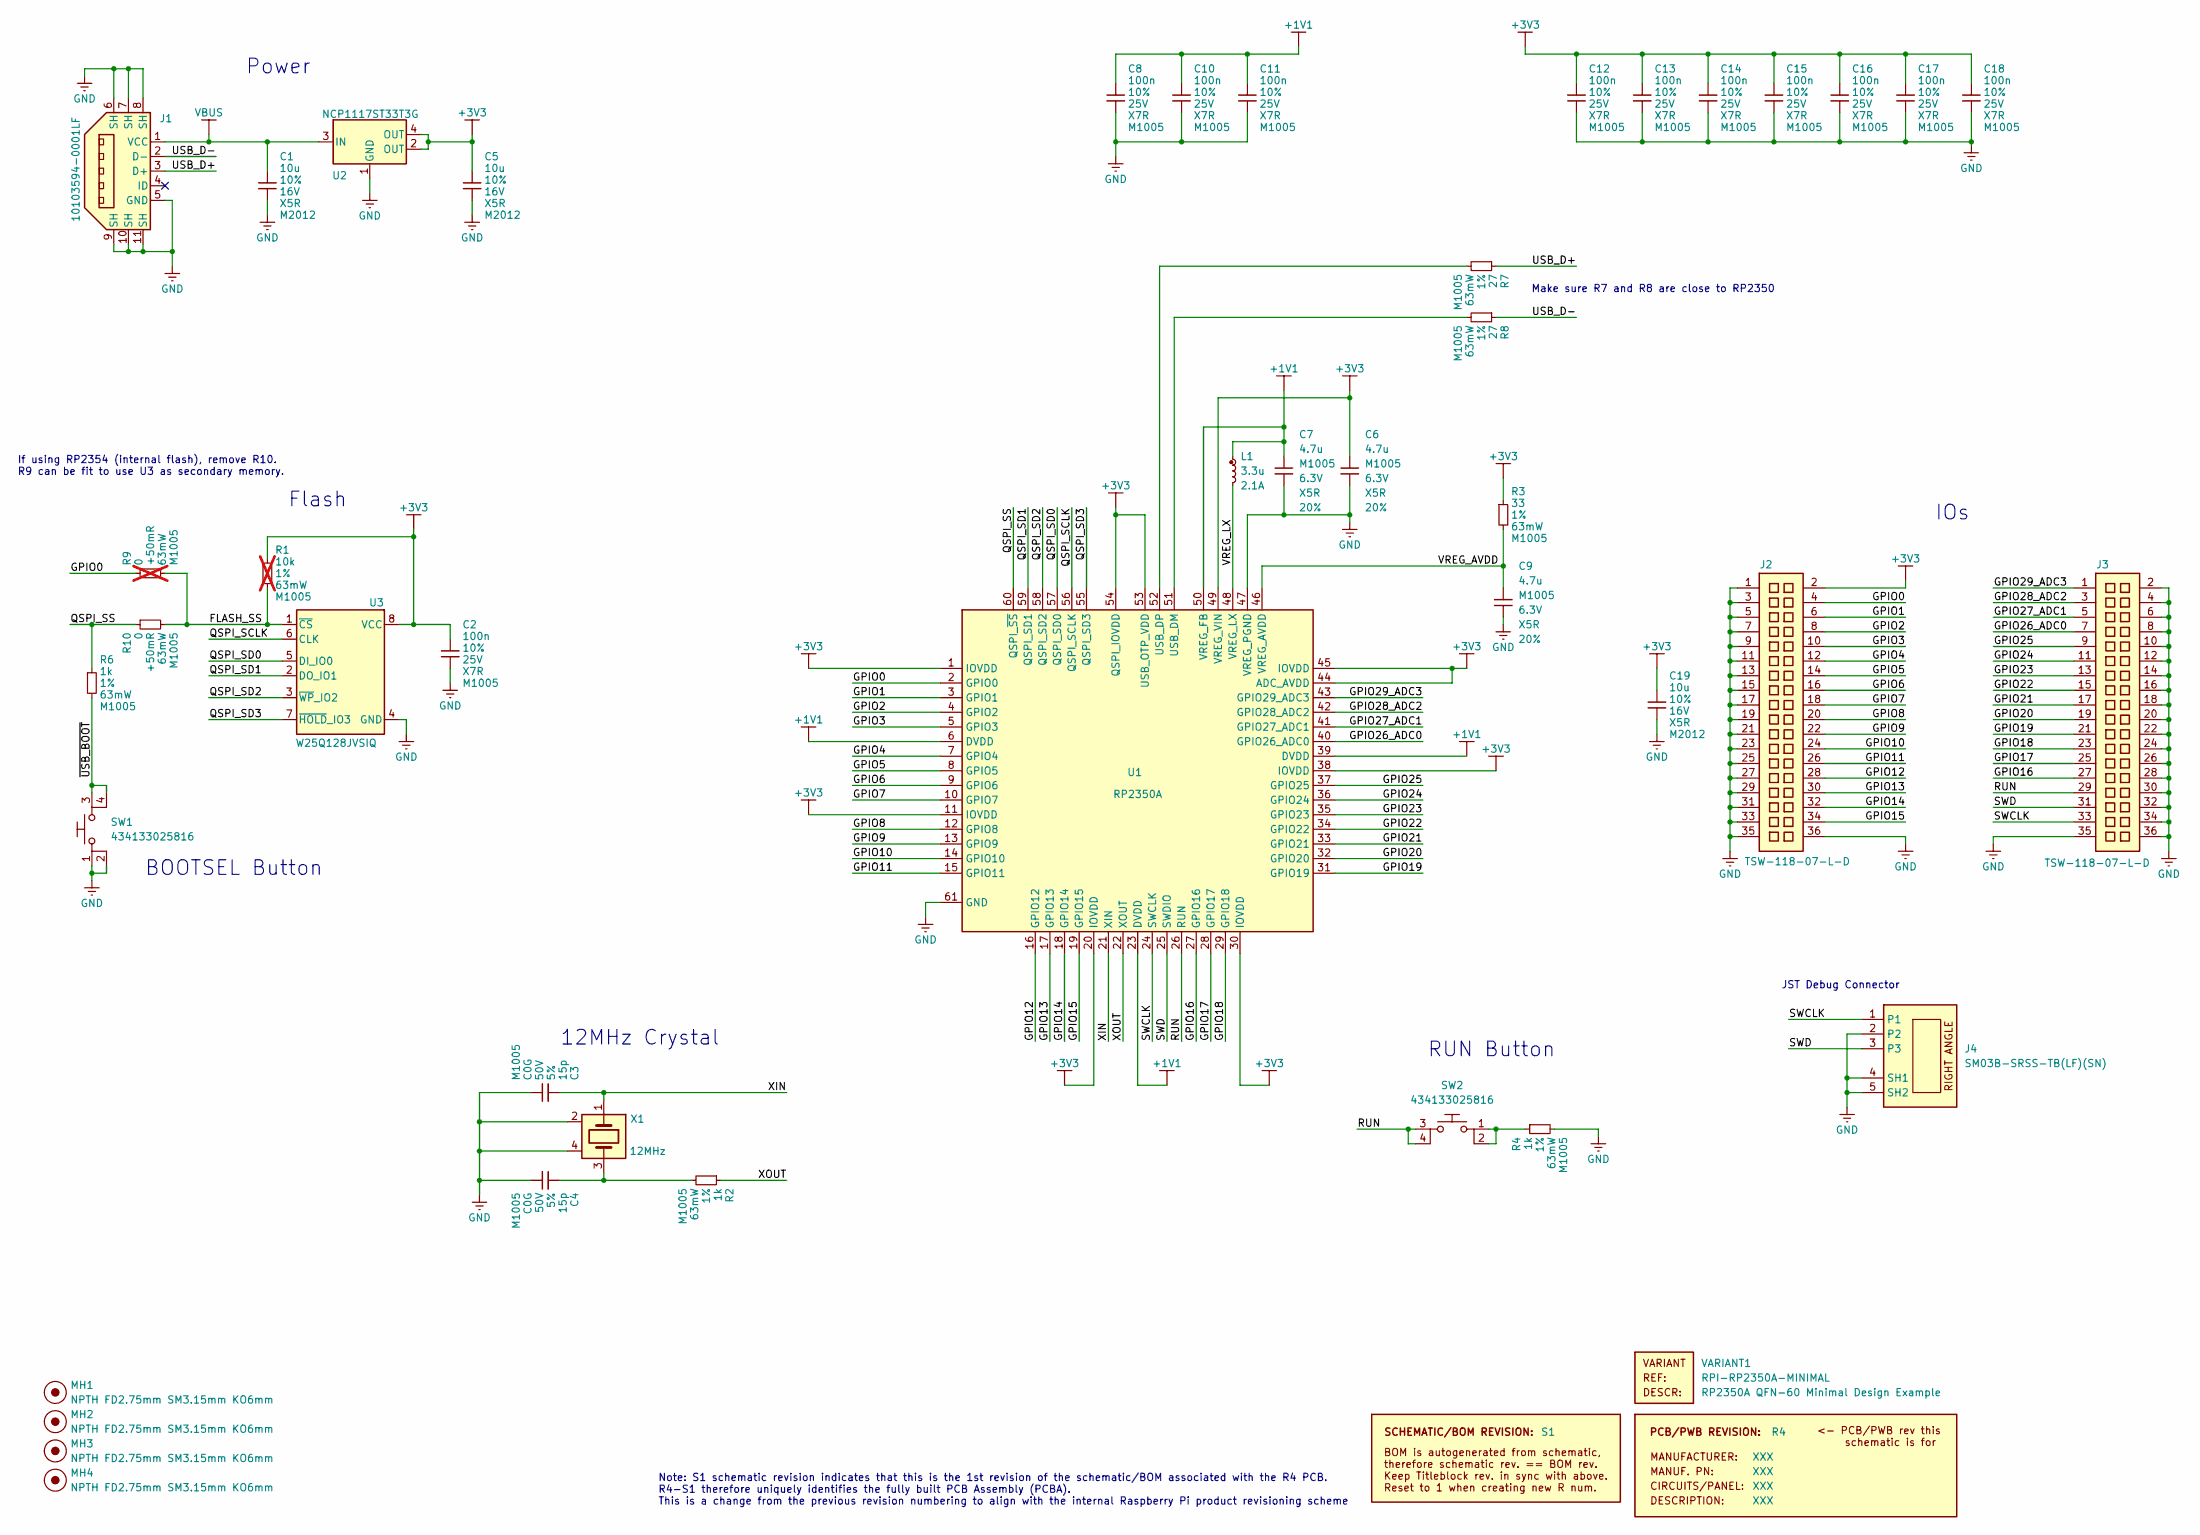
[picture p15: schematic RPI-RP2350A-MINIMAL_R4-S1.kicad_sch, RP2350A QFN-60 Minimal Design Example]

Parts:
C1, C5, C19: 10u; generic_capc2012x125; voltage 16V; tolerance 10%; part_uid RP-01GYSK-AVBE41
C2, C8, C10, C11, C12, C13, C14, C15, C16, C17, C18: 100n; generic_capc1005x50; voltage 25V; tolerance 10%; part_uid RP-01BJ9Y-KRGF41
C3, C4: 15p; generic_capc1005x50; voltage 50V; tolerance 5%; part_uid RP-01C89W-LLY9XV
C6, C7: 4.7u; generic_capc1005x50_wide; voltage 6.3V; tolerance 20%; part_uid RP-019A1P-0C2GHY
C9: 4.7u; generic_capc1005x50; voltage 6.3V; tolerance 20%; part_uid RP-019A1P-0C2GHY
J1: 10103594-0001LF; amphenol_10103594-0001lf; part_uid RP-019A1P-1JAX7V
J2, J3: TSW-118-07-L-D; samtec_tsw-118-07-l-d; part_uid RP-01JWH2-G371Y4
J4: SM03B-SRSS-TB(LF)(SN); jst_sm03b-srss-tb-lf--sn-; part_uid RP-01EKJ1-8V9SV1
L1: 3.3u; abracon_aota-b201610s3r3-101-t; tolerance 20%; part_uid RP-01GY5D-2VC7WP
MH1, MH2, MH3, MH4: NPTH FD2.75mm SM3.15mm KO6mm; none_mh_npth_fd2p75mm_sm3p15mm_ko6mm; part_uid RP-01HF5R-LCTEJS
PCB1: R4; manufacturer_pn XXX
R1: 10k; generic_resc1005x35; tolerance 1%; voltage 50V; part_uid RP-019A1P-53DHSX; not fitted
R2, R4, R6: 1k; generic_resc1005x35; tolerance 1%; voltage 50V; part_uid RP-019A1P-4Z6ZWY
R3: 33; generic_resc1005x35; tolerance 1%; voltage 50V; part_uid RP-019A1P-58PW9L
R7, R8: 27; generic_resc1005x35; tolerance 1%; voltage 50V; part_uid RP-01C89V-LTEYC4
R9: 0; generic_resc1005x35; tolerance +50mR; voltage 50V; part_uid RP-019A1P-4Y4V63; not fitted
R10: 0; generic_resc1005x35; tolerance +50mR; voltage 50V; part_uid RP-019A1P-4Y4V63
SBREV1: S1
SW1, SW2: 434133025816; wurthelek_434133025816; part_uid RP-01H0MT-6E9H8F
U1: RP2350A; rpi_rp2350a_vias; part_uid RP-01HA9H-9K5E8T
U2: NCP1117ST33T3G; onsemi_ncp1117st33t3g; voltage 3.3V; part_uid RP-01JWD9-7JRX6J
U3: W25Q128JVSIQ; generic_soic127p790x195-8; voltage 2.7-3.6V; part_uid RP-01JWD4-F1H4N9
VARIANT1: RPI-RP2350A-MINIMAL
X1: 12MHz; generic_xtalcc320x250x80-4; tolerance 30ppm; part_uid RP-01G8X7-GS352B

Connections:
+1V1: C7.1, C8.1, C10.1, C11.1, L1.1, U1.6 (DVDD), U1.23 (DVDD), U1.39 (DVDD), U1.50 (VREG_FB)
+3V3: C2.1, C5.1, C6.1, C12.1, C13.1, C14.1, C15.1, C16.1, C17.1, C18.1, C19.1, J2.2, R1.1, R3.1, U1.1 (IOVDD), U1.11 (IOVDD), U1.20 (IOVDD), U1.30 (IOVDD), U1.38 (IOVDD), U1.44 (ADC_AVDD), U1.45 (IOVDD), U1.49 (VREG_VIN), U1.53 (USB_OTP_VDD), U1.54 (QSPI_IOVDD), U2.2 (OUT), U2.4 (OUT), U3.8 (VCC)
/FLASH_SS: R1.2, R9.2, R10.2, U3.1 (~CS)
/GPIO0: J2.4, R9.1, U1.2 (GPIO0)
/GPIO1: J2.6, U1.3 (GPIO1)
/GPIO2: J2.8, U1.4 (GPIO2)
/GPIO3: J2.10, U1.5 (GPIO3)
/GPIO4: J2.12, U1.7 (GPIO4)
/GPIO5: J2.14, U1.8 (GPIO5)
/GPIO6: J2.16, U1.9 (GPIO6)
/GPIO7: J2.18, U1.10 (GPIO7)
/GPIO8: J2.20, U1.12 (GPIO8)
/GPIO9: J2.22, U1.13 (GPIO9)
/GPIO10: J2.24, U1.14 (GPIO10)
/GPIO11: J2.26, U1.15 (GPIO11)
/GPIO12: J2.28, U1.16 (GPIO12)
/GPIO13: J2.30, U1.17 (GPIO13)
/GPIO14: J2.32, U1.18 (GPIO14)
/GPIO15: J2.34, U1.19 (GPIO15)
/GPIO16: J3.27, U1.27 (GPIO16)
/GPIO17: J3.25, U1.28 (GPIO17)
/GPIO18: J3.23, U1.29 (GPIO18)
/GPIO19: J3.21, U1.31 (GPIO19)
/GPIO20: J3.19, U1.32 (GPIO20)
/GPIO21: J3.17, U1.33 (GPIO21)
/GPIO22: J3.15, U1.34 (GPIO22)
/GPIO23: J3.13, U1.35 (GPIO23)
/GPIO24: J3.11, U1.36 (GPIO24)
/GPIO25: J3.9, U1.37 (GPIO25)
/GPIO26_ADC0: J3.7, U1.40 (GPIO26_ADC0)
/GPIO27_ADC1: J3.5, U1.41 (GPIO27_ADC1)
/GPIO28_ADC2: J3.3, U1.42 (GPIO28_ADC2)
/GPIO29_ADC3: J3.1, U1.43 (GPIO29_ADC3)
/QSPI_SCLK: U1.56 (QSPI_SCLK), U3.6 (CLK)
/QSPI_SD0: U1.57 (QSPI_SD0), U3.5 (DI_IO0)
/QSPI_SD1: U1.59 (QSPI_SD1), U3.2 (DO_IO1)
/QSPI_SD2: U1.58 (QSPI_SD2), U3.3 (~WP_IO2)
/QSPI_SD3: U1.55 (QSPI_SD3), U3.7 (~HOLD_IO3)
/QSPI_SS: R6.1, R10.1, U1.60 (QSPI_~SS)
/RUN: J3.29, SW2.3, SW2.4, U1.26 (RUN)
/SWCLK: J3.33, J4.1, U1.24 (SWCLK)
/SWD: J3.31, J4.3, U1.25 (SWDIO)
/USB_D+: J1.3 (D+), R7.1
/USB_D-: J1.2 (D-), R8.1
/VREG_AVDD: C9.1, R3.2, U1.46 (VREG_AVDD)
/VREG_LX: L1.2, U1.48 (VREG_LX)
/XIN: C3.1, U1.21 (XIN), X1.1
/XOUT: R2.1, U1.22 (XOUT)
/~USB_BOOT: R6.2, SW1.3, SW1.4
GND: C1.2, C2.2, C3.2, C4.2, C5.2, C6.2, C7.2, C8.2, C9.2, C10.2, C11.2, C12.2, C13.2, C14.2, C15.2, C16.2, C17.2, C18.2, C19.2, J1.5 (GND), J1.6 (SH), J1.7 (SH), J1.8 (SH), J1.9 (SH), J1.10 (SH), J1.11 (SH), J2.1, J2.3, J2.5, J2.7, J2.9, J2.11, J2.13, J2.15, J2.17, J2.19, J2.21, J2.23, J2.25, J2.27, J2.29, J2.31, J2.33, J2.35, J2.36, J3.2, J3.4, J3.6, J3.8, J3.10, J3.12, J3.14, J3.16, J3.18, J3.20, J3.22, J3.24, J3.26, J3.28, J3.30, J3.32, J3.34, J3.35, J3.36, J4.2, J4.4 (SH1), J4.5 (SH2), R4.2, SW1.1, SW1.2, U1.47 (VREG_PGND), U1.61 (GND), U2.1 (GND), U3.4 (GND), X1.2, X1.4
unnamed: C4.1, R2.2, X1.3
unnamed: R4.1, SW2.1, SW2.2
unnamed: R8.2, U1.51 (USB_DM)
unnamed: R7.2, U1.52 (USB_DP)
VBUS: C1.1, J1.1 (VCC), U2.3 (IN)

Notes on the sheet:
JST Debug Connector
IOs
RUN Button
BOOTSEL Button
If using RP2354 (internal flash), remove R10. R9 can be fit to use U3 as secondary memory.
Flash
Note: S1 schematic revision indicates that this is the 1st revision of the schematic/BOM associated with the R4 PCB. R4-S1 therefore uniquely identifies the fully built PCB Assembly (PCBA). This is a change from the previous revision numbering to align with the internal Raspberry Pi product revisio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
Make sure R7 and R8 are close to RP2350
12MHz Crystal
Power

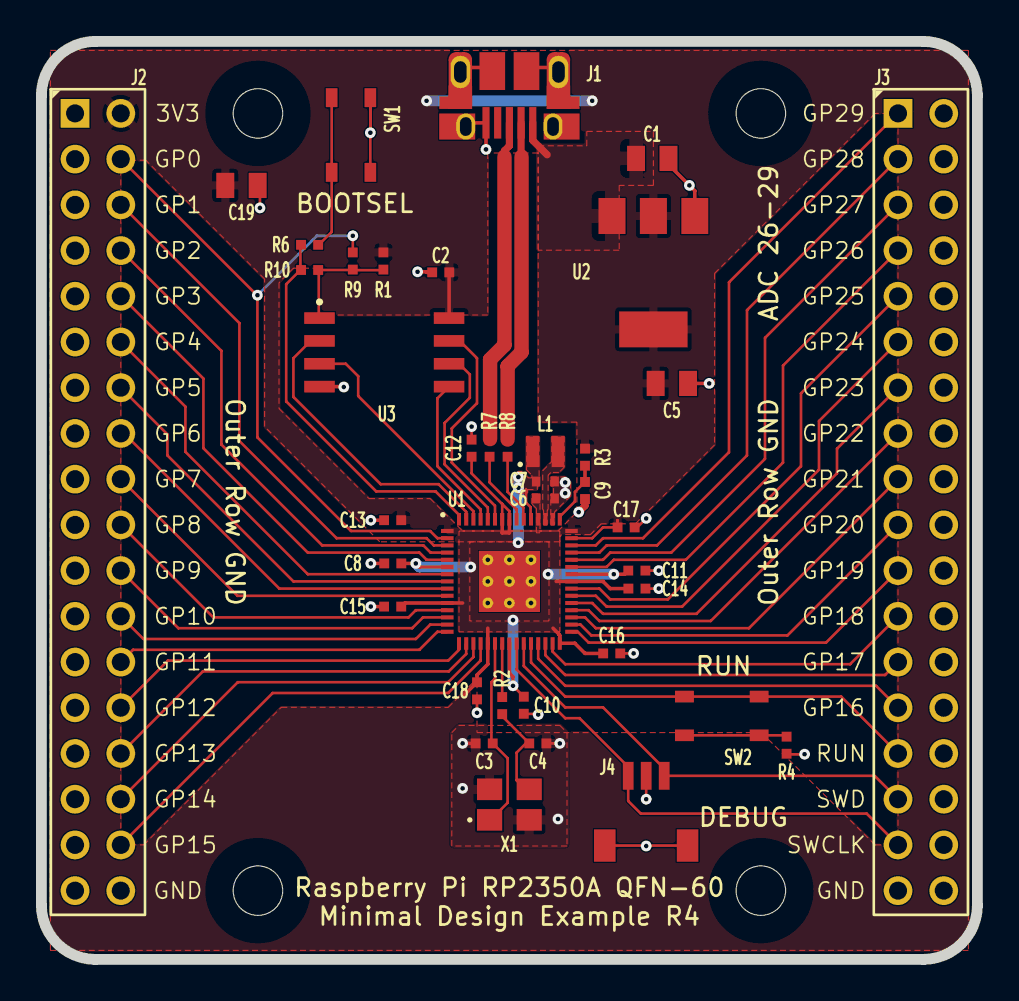
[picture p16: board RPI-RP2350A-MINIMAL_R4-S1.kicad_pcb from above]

Board: 2 copper layers, 52.0 x 51.0 mm, 43 parts (0 on the bottom side), 55 nets.

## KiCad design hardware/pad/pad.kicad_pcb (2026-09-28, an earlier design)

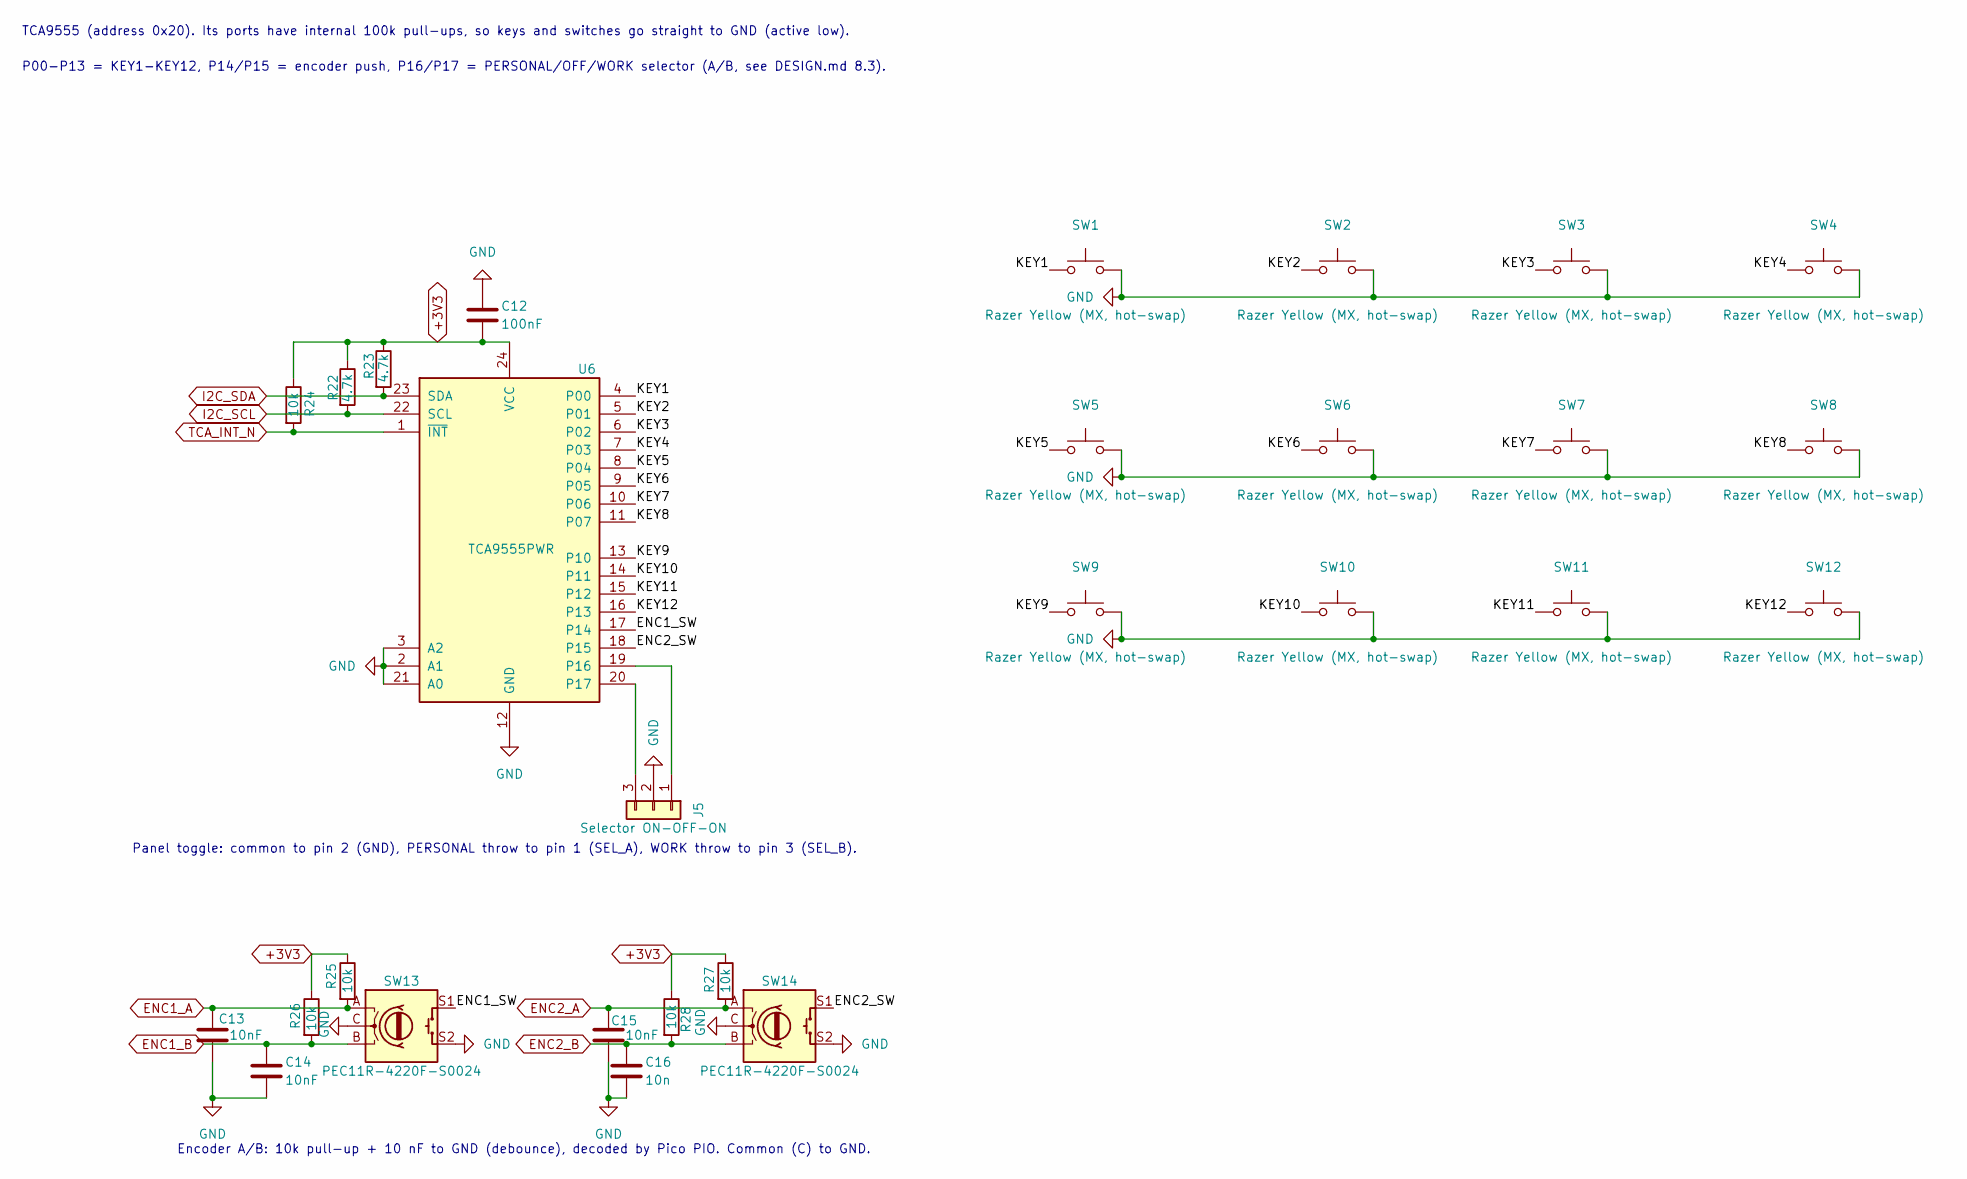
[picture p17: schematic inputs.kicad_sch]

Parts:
C12: 100nF; C_0805_2012Metric_Pad1.18x1.45mm_HandSolder
C13, C14, C15: 10nF; C_0805_2012Metric_Pad1.18x1.45mm_HandSolder
C16: 10n; C_0805_2012Metric_Pad1.18x1.45mm_HandSolder
J5: Selector ON-OFF-ON; JST_XH_B3B-XH-A_1x03_P2.50mm_Vertical
R22, R23: 4.7k; R_0805_2012Metric_Pad1.20x1.40mm_HandSolder
R24, R25, R26, R27, R28: 10k; R_0805_2012Metric_Pad1.20x1.40mm_HandSolder
SW1, SW2, SW3, SW4, SW5, SW6, SW7, SW8, SW9, SW10, SW11, SW12: Razer Yellow (MX, hot-swap); SW_MX_Hotswap_Kailh
SW13, SW14: PEC11R-4220F-S0024; RotaryEncoder_Bourns_PEC11R-4xxxF-S_Vertical
U6: TCA9555PWR; TSSOP-24_4.4x7.8mm_P0.65mm

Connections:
+3V3: C12.2, R22.1, R23.1, R24.1, R25.1, R26.1, R27.1, R28.1, U6.24 (VCC); also elsewhere on the board
/INPUTS/ENC1_SW: SW13.S1, U6.17 (P14)
/INPUTS/ENC2_SW: SW14.S1, U6.18 (P15)
/INPUTS/KEY1: SW1.1, U6.4 (P00)
/INPUTS/KEY2: SW2.1, U6.5 (P01)
/INPUTS/KEY3: SW3.1, U6.6 (P02)
/INPUTS/KEY4: SW4.1, U6.7 (P03)
/INPUTS/KEY5: SW5.1, U6.8 (P04)
/INPUTS/KEY6: SW6.1, U6.9 (P05)
/INPUTS/KEY7: SW7.1, U6.10 (P06)
/INPUTS/KEY8: SW8.1, U6.11 (P07)
/INPUTS/KEY9: SW9.1, U6.13 (P10)
/INPUTS/KEY10: SW10.1, U6.14 (P11)
/INPUTS/KEY11: SW11.1, U6.15 (P12)
/INPUTS/KEY12: SW12.1, U6.16 (P13)
ENC1_A: C13.1, R25.2, SW13.A; also elsewhere on the board
ENC1_B: C14.1, R26.2, SW13.B; also elsewhere on the board
ENC2_A: C15.1, R27.2, SW14.A; also elsewhere on the board
ENC2_B: C16.1, R28.2, SW14.B; also elsewhere on the board
GND: C12.1, C13.2, C14.2, C15.2, C16.2, J5.2, SW1.2, SW2.2, SW3.2, SW4.2, SW5.2, SW6.2, SW7.2, SW8.2, SW9.2, SW10.2, SW11.2, SW12.2, SW13.C, SW13.S2, SW14.C, SW14.S2, U6.2 (A1), U6.3 (A2), U6.12 (GND), U6.21 (A0); also elsewhere on the board
I2C_SCL: R22.2, U6.22 (SCL); also elsewhere on the board
I2C_SDA: R23.2, U6.23 (SDA); also elsewhere on the board
unnamed: J5.1, U6.19 (P16)
unnamed: J5.3, U6.20 (P17)
TCA_INT_N: R24.2, U6.1 (~INT); also elsewhere on the board

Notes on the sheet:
P00-P13 = KEY1-KEY12, P14/P15 = encoder push, P16/P17 = PERSONAL/OFF/WORK selector (A/B, see DESIGN.md 8.3).
Encoder A/B: 10k pull-up + 10 nF to GND (debounce), decoded by Pico PIO. Common (C) to GND.
TCA9555 (address 0x20). Its ports have internal 100k pull-ups, so keys and switches go straight to GND (active low).
Panel toggle: common to pin 2 (GND), PERSONAL throw to pin 1 (SEL_A), WORK throw to pin 3 (SEL_B).

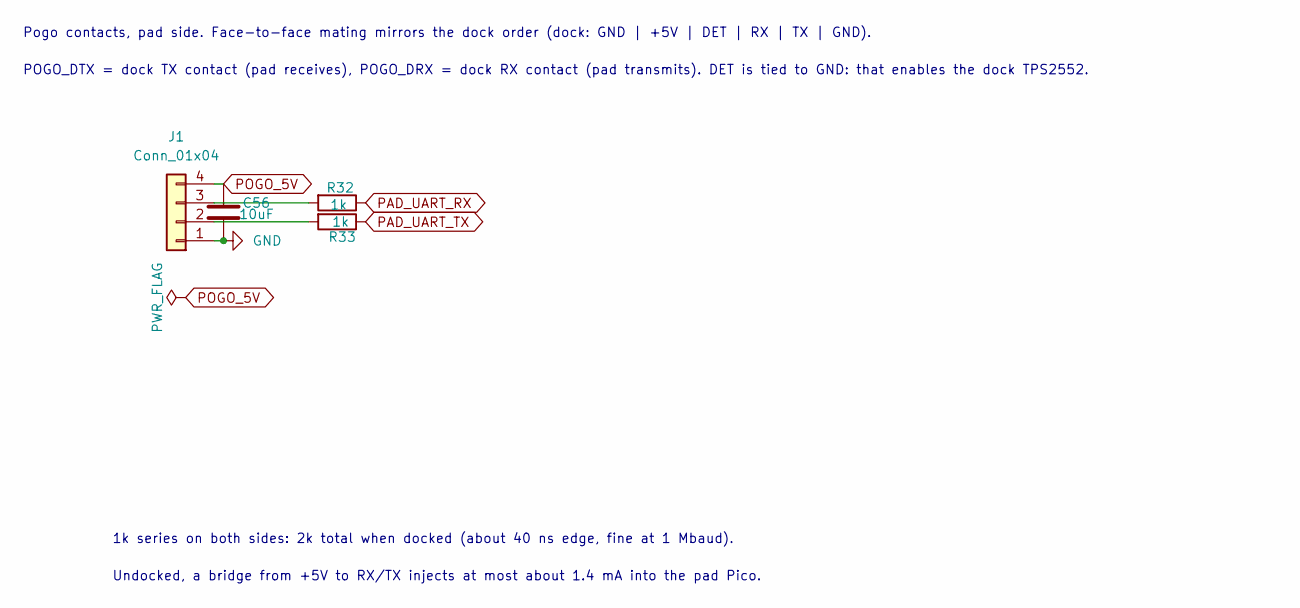
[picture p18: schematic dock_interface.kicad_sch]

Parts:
C56: 10uF; C_0805_2012Metric_Pad1.18x1.45mm_HandSolder
J1: Conn_01x04; JST_XH_S4B-XH-A_1x04_P2.50mm_Horizontal
R32, R33: 1k; R_0805_2012Metric_Pad1.20x1.40mm_HandSolder

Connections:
GND: C56.1, J1.1; also elsewhere on the board
unnamed: J1.2, R33.2
unnamed: J1.3, R32.2
PAD_UART_RX: R32.1; also elsewhere on the board
PAD_UART_TX: R33.1; also elsewhere on the board
POGO_5V: C56.2, J1.4; also elsewhere on the board

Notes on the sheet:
Undocked, a bridge from +5V to RX/TX injects at most about 1.4 mA into the pad Pico.
Pogo contacts, pad side. Face-to-face mating mirrors the dock order (dock: GND | +5V | DET | RX | TX | GND).
POGO_DTX = dock TX contact (pad receives), POGO_DRX = dock RX contact (pad transmits). DET is tied to GND: that enables the dock TPS2552.
1k series on both sides: 2k total when docked (about 40 ns edge, fine at 1 Mbaud).


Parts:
C2, C3: 10uF; C_0805_2012Metric_Pad1.18x1.45mm_HandSolder
C4: 100n; C_0805_2012Metric_Pad1.18x1.45mm_HandSolder
C5: 100nF; C_0805_2012Metric_Pad1.18x1.45mm_HandSolder
J2: NTC 10k B3950; JST_XH_S2B-XH-A_1x02_P2.50mm_Horizontal
J3: Battery 2x21700 1S2P; JST_XH_S2B-XH-A_1x02_P2.50mm_Horizontal
Q1, Q2: 2N7002; SOT-23
Q3: FS8205A; TSSOP-8_4.4x3mm_P0.65mm
R3: 5.6k; R_0805_2012Metric_Pad1.20x1.40mm_HandSolder
R4: 75k; R_0805_2012Metric_Pad1.20x1.40mm_HandSolder
R5: 8.2k; R_0805_2012Metric_Pad1.20x1.40mm_HandSolder
R6: 3.3k; R_0805_2012Metric_Pad1.20x1.40mm_HandSolder
R7, R8, R9, R14, R15: 100k; R_0805_2012Metric_Pad1.20x1.40mm_HandSolder
R10, R11: 10k; R_0805_2012Metric_Pad1.20x1.40mm_HandSolder
R12: 100; R_0805_2012Metric_Pad1.20x1.40mm_HandSolder
R13: 1k; R_0805_2012Metric_Pad1.20x1.40mm_HandSolder
U2: TP4056; SOIC-8-1EP_3.9x4.9mm_HandSolder
U3: DW01A; SOT-23-6

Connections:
+3V3: R10.2, R11.2; also elsewhere on the board
/BATTERY_CHARGER/CELL_N: C4.2, J3.2, Q3.2 (S1), Q3.3 (S1), U3.6 (GND)
/BATTERY_CHARGER/CHG_TEMP: J2.1, R3.2, R4.1, U2.1 (TEMP)
/BATTERY_CHARGER/DW_CS: R13.2, U3.2 (CS)
/BATTERY_CHARGER/DW_VCC: C4.1, R12.1, U3.5 (VCC)
/BATTERY_CHARGER/FET_D12: Q3.1 (D12), Q3.8 (D12)
CHG_CHRG_N: R10.1, U2.7 (~CHRG); also elsewhere on the board
CHG_FAST: Q1.1 (G), R7.1; also elsewhere on the board
CHG_INHIBIT: Q2.1 (G), R9.2; also elsewhere on the board
CHG_STDBY_N: R11.1, U2.6 (~STDBY); also elsewhere on the board
GND: C2.2, C3.1, C5.1, J2.2, Q1.2 (S), Q2.2 (S), Q3.6 (S2), Q3.7 (S2), R4.2, R5.2, R7.2, R9.1, R13.1, R15.1, U2.3 (GND), U2.9 (EPAD); also elsewhere on the board
unnamed: Q1.3 (D), R6.2
unnamed: Q2.3 (D), R8.1, U2.8 (CE)
unnamed: Q3.4 (G1), U3.1 (OD)
unnamed: Q3.5 (G2), U3.3 (OC)
unnamed: R5.1, R6.1, U2.2 (PROG)
POGO_5V: C2.1, R3.1, R8.2, U2.4 (V_{CC}); also elsewhere on the board
VBAT: C3.2, J3.1, R12.2, R14.2, U2.5 (BAT); also elsewhere on the board
VBAT_SENSE: C5.2, R14.1, R15.2; also elsewhere on the board

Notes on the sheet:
CELL_N = cell negative (DW01A ground). GND = pack negative = board ground.
TEMP window 45-80 % of VCC: R 5.6k to VCC, NTC 10k B3950 parallel 75k to GND = charge only between about 0 and 45 C.
CE defaults high (charging on) through 100k from POGO_5V; CHG_INHIBIT high pulls CE low (Pico holds the docked 3.90-4.00 V window).
Cell protection DW01A + FS8205A in the negative lead: over-discharge 2.40 V, overcharge 4.30 V, overcurrent 150 mV / (2 x 25 mOhm) = about 3 A.
Li-ion charger TP4056: 4.2 V CC-CV. I = 1200 / R_PROG. 8.2k alone = 146 mA (slow); Q with CHG_FAST high adds 3.3k in parallel = 510 mA (fast).
VBAT_SENSE = VBAT / 2 to Pico ADC0 (GP26). Permanent divider, about 18 uA.


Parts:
C54, C55: 1uF; C_0805_2012Metric_Pad1.18x1.45mm_HandSolder
J7: Conn_01x09; JST_PH_S9B-PH-K_1x09_P2.00mm_Horizontal
Q4: AO3401A; SOT-23
R30, R34: 100k; R_0805_2012Metric_Pad1.20x1.40mm_HandSolder
R31: 100; R_0805_2012Metric_Pad1.20x1.40mm_HandSolder
U8: TPS22919DCK; SOT-363_SC-70-6

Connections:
+3V3: C54.2, U8.1 (IN); also elsewhere on the board
GND: C54.1, C55.2, J7.1, J7.9, R30.2, U8.2 (GND); also elsewhere on the board
unnamed: C55.1, J7.2, Q4.2 (S), R31.1, R34.2, U8.6 (OUT)
unnamed: J7.8, Q4.3 (D)
unnamed: R31.2, U8.5 (QOD)
OLED_BLK: Q4.1 (G), R34.1; also elsewhere on the board
OLED_CS: J7.7; also elsewhere on the board
OLED_DC: J7.6; also elsewhere on the board
OLED_EN: R30.1, U8.3 (ON); also elsewhere on the board
OLED_MOSI: J7.4; also elsewhere on the board
OLED_RES: J7.5; also elsewhere on the board
OLED_SCK: J7.3; also elsewhere on the board

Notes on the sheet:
1.3 inch 128x64 SPI OLED (SH1106 or SSD1306, chosen in firmware). Pin order on the module: GND VCC SCK SDA(MOSI) RES DC CS.
TPS22919 switches +3V3 to the module (OLED_EN from the Pico, 100k pull-down = off at boot). QOD to OUT through 100R = controlled quick discharge when off (datasheet option).


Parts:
C17, C18, C19, C20, C21, C22, C23, C24, C25, C26, C27, C28, C29, C30, C31, C32, C33, C34, C35, C36, C37, C38, C39, C40, C41, C42, C43, C44, C45, C46, C47, C48, C49, C50, C51, C52, C53: 100n; C_0805_2012Metric_Pad1.18x1.45mm_HandSolder
D2, D3, D4, D5, D6, D7, D8, D9, D10, D11, D12, D13, D14, D15, D16, D17, D18, D19, D20, D21, D22, D23, D24, D25, D26, D27, D28, D29, D30, D31, D32, D33, D34, D35, D36, D37: SK6812MINI-E; LED_SK6812MINI-E_3.2x2.8mm_P1.5mm_ReverseMount
R29: 47; R_0805_2012Metric_Pad1.20x1.40mm_HandSolder
U7: 74AHCT1G125; SOT-23-5

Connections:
5V_RGB: C17.1, C18.1, C19.1, C20.1, C21.1, C22.1, C23.1, C24.1, C25.1, C26.1, C27.1, C28.1, C29.1, C30.1, C31.1, C32.1, C33.1, C34.1, C35.1, C36.1, C37.1, C38.1, C39.1, C40.1, C41.1, C42.1, C43.1, C44.1, C45.1, C46.1, C47.1, C48.1, C49.1, C50.1, C51.1, C52.1, C53.1, D2.3 (VDD), D3.3 (VDD), D4.3 (VDD), D5.3 (VDD), D6.3 (VDD), D7.3 (VDD), D8.3 (VDD), D9.3 (VDD), D10.3 (VDD), D11.3 (VDD), D12.3 (VDD), D13.3 (VDD), D14.3 (VDD), D15.3 (VDD), D16.3 (VDD), D17.3 (VDD), D18.3 (VDD), D19.3 (VDD), D20.3 (VDD), D21.3 (VDD), D22.3 (VDD), D23.3 (VDD), D24.3 (VDD), D25.3 (VDD), D26.3 (VDD), D27.3 (VDD), D28.3 (VDD), D29.3 (VDD), D30.3 (VDD), D31.3 (VDD), D32.3 (VDD), D33.3 (VDD), D34.3 (VDD), D35.3 (VDD), D36.3 (VDD), D37.3 (VDD), U7.5 (VCC); also elsewhere on the board
/RGB/LED_DIN1: D2.2 (DIN), R29.2
/RGB/LED_DIN2: D24.4 (DOUT), D25.2 (DIN)
GND: C17.2, C18.2, C19.2, C20.2, C21.2, C22.2, C23.2, C24.2, C25.2, C26.2, C27.2, C28.2, C29.2, C30.2, C31.2, C32.2, C33.2, C34.2, C35.2, C36.2, C37.2, C38.2, C39.2, C40.2, C41.2, C42.2, C43.2, C44.2, C45.2, C46.2, C47.2, C48.2, C49.2, C50.2, C51.2, C52.2, C53.2, D2.1 (VSS), D3.1 (VSS), D4.1 (VSS), D5.1 (VSS), D6.1 (VSS), D7.1 (VSS), D8.1 (VSS), D9.1 (VSS), D10.1 (VSS), D11.1 (VSS), D12.1 (VSS), D13.1 (VSS), D14.1 (VSS), D15.1 (VSS), D16.1 (VSS), D17.1 (VSS), D18.1 (VSS), D19.1 (VSS), D20.1 (VSS), D21.1 (VSS), D22.1 (VSS), D23.1 (VSS), D24.1 (VSS), D25.1 (VSS), D26.1 (VSS), D27.1 (VSS), D28.1 (VSS), D29.1 (VSS), D30.1 (VSS), D31.1 (VSS), D32.1 (VSS), D33.1 (VSS), D34.1 (VSS), D35.1 (VSS), D36.1 (VSS), D37.1 (VSS), U7.1, U7.3 (GND); also elsewhere on the board
unnamed: D2.4 (DOUT), D3.2 (DIN)
unnamed: D3.4 (DOUT), D4.2 (DIN)
unnamed: D4.4 (DOUT), D5.2 (DIN)
unnamed: D5.4 (DOUT), D6.2 (DIN)
unnamed: D6.4 (DOUT), D7.2 (DIN)
unnamed: D7.4 (DOUT), D8.2 (DIN)
unnamed: D8.4 (DOUT), D9.2 (DIN)
unnamed: D9.4 (DOUT), D10.2 (DIN)
unnamed: D10.4 (DOUT), D11.2 (DIN)
unnamed: D11.4 (DOUT), D12.2 (DIN)
unnamed: D12.4 (DOUT), D13.2 (DIN)
unnamed: D13.4 (DOUT), D14.2 (DIN)
unnamed: D14.4 (DOUT), D15.2 (DIN)
unnamed: D15.4 (DOUT), D16.2 (DIN)
unnamed: D16.4 (DOUT), D17.2 (DIN)
unnamed: D17.4 (DOUT), D18.2 (DIN)
unnamed: D18.4 (DOUT), D19.2 (DIN)
unnamed: D19.4 (DOUT), D20.2 (DIN)
unnamed: D20.4 (DOUT), D21.2 (DIN)
unnamed: D21.4 (DOUT), D22.2 (DIN)
unnamed: D22.4 (DOUT), D23.2 (DIN)
unnamed: D23.4 (DOUT), D24.2 (DIN)
unnamed: D25.4 (DOUT), D26.2 (DIN)
unnamed: D26.4 (DOUT), D27.2 (DIN)
unnamed: D27.4 (DOUT), D28.2 (DIN)
unnamed: D28.4 (DOUT), D29.2 (DIN)
unnamed: D29.4 (DOUT), D30.2 (DIN)
unnamed: D30.4 (DOUT), D31.2 (DIN)
unnamed: D31.4 (DOUT), D32.2 (DIN)
unnamed: D32.4 (DOUT), D33.2 (DIN)
unnamed: D33.4 (DOUT), D34.2 (DIN)
unnamed: D34.4 (DOUT), D35.2 (DIN)
unnamed: D35.4 (DOUT), D36.2 (DIN)
unnamed: D36.4 (DOUT), D37.2 (DIN)
unnamed: R29.1, U7.4
RGB_DATA_3V3: U7.2; also elsewhere on the board

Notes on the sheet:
Data: Pico 3.3 V (PIO) through SN74AHCT1G125 (VCC = 5V_RGB, so data drive dies with the rail) and a 47R series resistor.
36 x SK6812MINI-E on 5V_RGB, one chain. Order to be fixed at layout (keys 1-12, ring 1, ring 2). 100 nF per LED.


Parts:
C6: 1uF; C_0805_2012Metric_Pad1.18x1.45mm_HandSolder
C7, C8: 10uF; C_0805_2012Metric_Pad1.18x1.45mm_HandSolder
C9: 10uF; C_1206_3216Metric_Pad1.33x1.80mm_HandSolder
C10, C11: 22uF; C_1206_3216Metric_Pad1.33x1.80mm_HandSolder
L1: 1u; L_Coilcraft_XxL4030
R16: 300k; R_0805_2012Metric_Pad1.20x1.40mm_HandSolder
R17, R19, R21: 100k; R_0805_2012Metric_Pad1.20x1.40mm_HandSolder
R18: 10k; R_0805_2012Metric_Pad1.20x1.40mm_HandSolder
R20: 750k; R_0805_2012Metric_Pad1.20x1.40mm_HandSolder
U4: TPS2116DRL; SOT-583-8_HandSolder
U5: TPS61023DRLR; SOT-563-6_HandSolder

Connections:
5V_RGB: C10.2, C11.2, R20.1, U5.6 (VOUT); also elsewhere on the board
+3V3: R18.2; also elsewhere on the board
DOCKED: R18.1, U4.8 (ST); also elsewhere on the board
GND: C6.1, C7.1, C8.1, C9.1, C10.1, C11.1, R17.1, R19.2, R21.2, U4.1 (GND), U5.4 (GND); also elsewhere on the board
unnamed: R16.2, R17.2, U4.4 (PR1)
unnamed: R20.2, R21.1, U5.1 (FB)
unnamed: L1.1, U5.5 (SW)
PAD_SYS: C7.2, C8.2, C9.2, L1.2, U4.2 (VOUT), U4.7 (VOUT), U5.3 (VIN); also elsewhere on the board
POGO_5V: R16.1, U4.3 (VIN1), U4.5 (MODE); also elsewhere on the board
RGB_EN: R19.1, U5.2 (EN); also elsewhere on the board
VBAT: C6.2, U4.6 (VIN2); also elsewhere on the board

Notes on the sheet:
L: 1 uH shielded 4x4 mm, Isat >= 4.5 A, DCR <= 20 mOhm (Wurth 74438357010 / Coilcraft XEL4030-102ME).
ST is high while VIN1 (pogo) is in use: DOCKED to the Pico. Reverse-current blocking keeps Pico USB VBUS out of the cell.
TPS2116 power path: POGO_5V (VIN1, priority) or VBAT (VIN2) to PAD_SYS. PR1 300k/100k = switchover at about 4.0 V; MODE tied to VIN1 (as on the dock).
TPS61023 boost: PAD_SYS to 5V_RGB. VOUT = 0.6 V x (1 + 750k/100k) = about 5.05 V. Pass-through when docked.

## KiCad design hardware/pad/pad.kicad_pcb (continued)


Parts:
A1: Pico 2 WH; RaspberryPi_Pico2W_Socket_NoSWD

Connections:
+3V3: A1.36 (3V3); also elsewhere on the board
CHG_CHRG_N: A1.25 (GPIO19); also elsewhere on the board
CHG_FAST: A1.22 (GPIO17); also elsewhere on the board
CHG_INHIBIT: A1.24 (GPIO18); also elsewhere on the board
CHG_STDBY_N: A1.26 (GPIO20); also elsewhere on the board
DOCKED: A1.27 (GPIO21); also elsewhere on the board
ENC1_A: A1.4 (GPIO2); also elsewhere on the board
ENC1_B: A1.5 (GPIO3); also elsewhere on the board
ENC2_A: A1.9 (GPIO6); also elsewhere on the board
ENC2_B: A1.10 (GPIO7); also elsewhere on the board
GND: A1.3 (GND), A1.8 (GND), A1.13 (GND), A1.18 (GND), A1.23 (GND), A1.28 (GND), A1.33 (AGND), A1.38 (GND), A1.D2 (GND); also elsewhere on the board
I2C_SCL: A1.7 (GPIO5); also elsewhere on the board
I2C_SDA: A1.6 (GPIO4); also elsewhere on the board
OLED_BLK: A1.32 (GPIO27_ADC1); also elsewhere on the board
OLED_CS: A1.17 (GPIO13); also elsewhere on the board
OLED_DC: A1.16 (GPIO12); also elsewhere on the board
OLED_EN: A1.29 (GPIO22); also elsewhere on the board
OLED_MOSI: A1.15 (GPIO11); also elsewhere on the board
OLED_RES: A1.19 (GPIO14); also elsewhere on the board
OLED_SCK: A1.14 (GPIO10); also elsewhere on the board
PAD_SYS: A1.39 (VSYS); also elsewhere on the board
PAD_UART_RX: A1.2 (GPIO1); also elsewhere on the board
PAD_UART_TX: A1.1 (GPIO0); also elsewhere on the board
RGB_DATA_3V3: A1.12 (GPIO9); also elsewhere on the board
RGB_EN: A1.21 (GPIO16); also elsewhere on the board
TCA_INT_N: A1.11 (GPIO8); also elsewhere on the board
VBAT_SENSE: A1.31 (GPIO26_ADC0); also elsewhere on the board

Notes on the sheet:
GP15 (pin 20) is left free so a 1x19 socket can be used on that side. SWD comes down through the debug holes (D1-D3) to J SWD.
Pico 2 WH, socketed like the dock host. VSYS takes PAD_SYS (1.8-5.5 V); its buck-boost makes +3V3 (keep load under 300 mA).
SWD header, same pinout as the dock (1 SWCLK, 2 SWDIO, 3 GND, 4 RUN, 5 3V3 reference only).



Board: 2 copper layers, 100.0 x 92.0 mm, 159 parts (141 on the bottom side), 101 nets.

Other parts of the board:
H1, H2, H3, H4: M3; MountingHole_3.2mm_M3

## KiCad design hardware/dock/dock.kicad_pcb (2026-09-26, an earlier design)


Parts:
C11, C12: 1uF; C_0805_2012Metric_Pad1.18x1.45mm_HandSolder
J7: Conn_01x06; Pogo-6
R18: 10K; R_0805_2012Metric_Pad1.20x1.40mm_HandSolder
R23: 26.1k; R_0805_2012Metric_Pad1.20x1.40mm_HandSolder
R24: 10k; R_0805_2012Metric_Pad1.20x1.40mm_HandSolder
R25, R26, R27: 1k; R_0805_2012Metric_Pad1.20x1.40mm_HandSolder
U8: TPS2552DBVR; SOT-23-6
U9: TPD4E1U06DBVR; SOT-23-6

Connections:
/BLE_BASE/POGO_5V: C12.1, J7.2, U8.6 (OUT), U9.1 (D1+)
/BLE_BASE/POGO_DET_CONN: J7.3, R27.1, U9.6 (D1-)
/BLE_BASE/POGO_RX_CONN: J7.4, R26.1, U9.3 (D2+)
/BLE_BASE/POGO_TX_CONN: J7.5, R25.1, U9.4 (D2-)
GND: C11.2, C12.2, J7.1, J7.6, R23.2, U8.2 (GND), U9.2 (GND); also elsewhere on the board
HOST_3V3: R18.2, R24.1; also elsewhere on the board
unnamed: R23.1, U8.5 (ILIM)
POGO_5V_FAULT: R24.2, U8.4 (FAULT); also elsewhere on the board
POGO_DET: R18.1, R27.2, U8.3 (~EN); also elsewhere on the board
POGO_RX: R26.2; also elsewhere on the board
POGO_TX: R25.2; also elsewhere on the board
SYS_5V: C11.1, U8.1 (IN); also elsewhere on the board


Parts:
A2: Raspberry Pi Pico 2; RaspberryPi_Pico2_Socket_Pogo
C2: 100nF; C_0805_2012Metric_Pad1.18x1.45mm_HandSolder
J3: Conn_01x05_Pin; PinHeader_1x05_P2.54mm_Vertical
J4: L-KLS1-5416-L1-01-R; KLS L-KLS1-5416-L1-01-R
R10: 330; R_0805_2012Metric_Pad1.20x1.40mm_HandSolder
R11, R12: 5.1k; R_0805_2012Metric_Pad1.20x1.40mm_HandSolder
R13, R29, R30, R36: 10k; R_0805_2012Metric_Pad1.20x1.40mm_HandSolder
R19: 22k; R_0805_2012Metric_Pad1.20x1.40mm_HandSolder
R20: 33k; R_0805_2012Metric_Pad1.20x1.40mm_HandSolder
R33: 1k; R_0805_2012Metric_Pad1.20x1.40mm_HandSolder
U5: TPD4E1U06DBVR; SOT-23-6

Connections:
/HID_PERSONAL/CC1: J4.4 (CC1_A5), R11.1, R30.2, U5.3 (D2+)
/HID_PERSONAL/CC2: J4.10 (CC2_B5), R12.1, R29.2, U5.4 (D2-)
/HID_PERSONAL/PICO_3V3: A2.36 (3V3), J3.5, R36.1
/HID_PERSONAL/RUN: A2.30 (RUN), J3.4, R33.2, R36.2
/HID_PERSONAL/USB_PERSONAL_D_N: A2.TP2 (USB_DM), J4.5 (DM_B7), J4.7 (DM_A7), U5.6 (D1-)
/HID_PERSONAL/USB_PERSONAL_D_P: A2.TP3 (USB_DP), J4.6 (DP_A6), J4.8 (DP_B6), U5.1 (D1+)
GND: A2.3 (GND), A2.8 (GND), A2.13 (GND), A2.18 (GND), A2.23 (GND), A2.28 (GND), A2.33 (AGND), A2.38 (GND), A2.D2 (GND), A2.TP1 (USB_GND), C2.1, J3.3, J4.1 (GND_A1_B12), J4.12 (GND_B1_A12), R10.2, R11.2, R12.2, R13.1, R20.2, U5.2 (GND); also elsewhere on the board
HID_PERSONAL_RUN_CTRL: R33.1; also elsewhere on the board
HID_PERSONAL_RX: A2.21 (GPIO16); also elsewhere on the board
HID_PERSONAL_TX: A2.22 (GPIO17); also elsewhere on the board
unnamed: A2.4 (GPIO2), R13.2
unnamed: A2.6 (GPIO4), R19.2, R20.1
unnamed: A2.31 (GPIO26_ADC0), R29.1
unnamed: A2.32 (GPIO27_ADC1), R30.1
unnamed: A2.D1 (SWCLK), J3.1
unnamed: A2.D3 (SWDIO), J3.2
unnamed: C2.2, J4.SH (SHIELD), R10.1
PERSONAL_VBUS: J4.2 (VBUS_A4_B9), J4.11 (VBUS_B4_A9), R19.1; also elsewhere on the board
SYS_5V: A2.39 (VSYS); also elsewhere on the board

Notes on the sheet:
Role_Strap


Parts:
A3: Raspberry Pi Pico 2; RaspberryPi_Pico2_Socket_Pogo
C10: 100nF; C_0805_2012Metric_Pad1.18x1.45mm_HandSolder
J5: L-KLS1-5416-L1-01-R; KLS L-KLS1-5416-L1-01-R
J6: Conn_01x05_Pin; PinHeader_1x05_P2.54mm_Vertical
R14: 330; R_0805_2012Metric_Pad1.20x1.40mm_HandSolder
R15, R16: 5.1k; R_0805_2012Metric_Pad1.20x1.40mm_HandSolder
R17, R31, R32, R37: 10k; R_0805_2012Metric_Pad1.20x1.40mm_HandSolder
R21: 22k; R_0805_2012Metric_Pad1.20x1.40mm_HandSolder
R22: 33k; R_0805_2012Metric_Pad1.20x1.40mm_HandSolder
R34: 1k; R_0805_2012Metric_Pad1.20x1.40mm_HandSolder
U6: TPD4E1U06DBVR; SOT-23-6

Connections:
/HID_WORK/CC1: J5.4 (CC1_A5), R15.1, R31.2, U6.3 (D2+)
/HID_WORK/CC2: J5.10 (CC2_B5), R16.1, R32.2, U6.4 (D2-)
/HID_WORK/PICO_3V3: A3.36 (3V3), J6.5, R17.1, R37.1
/HID_WORK/RUN: A3.30 (RUN), J6.4, R34.2, R37.2
/HID_WORK/USB_WORK_D_N: A3.TP2 (USB_DM), J5.5 (DM_B7), J5.7 (DM_A7), U6.6 (D1-)
/HID_WORK/USB_WORK_D_P: A3.TP3 (USB_DP), J5.6 (DP_A6), J5.8 (DP_B6), U6.1 (D1+)
GND: A3.3 (GND), A3.8 (GND), A3.13 (GND), A3.18 (GND), A3.23 (GND), A3.28 (GND), A3.33 (AGND), A3.38 (GND), A3.D2 (GND), A3.TP1 (USB_GND), C10.2, J5.1 (GND_A1_B12), J5.12 (GND_B1_A12), J6.3, R14.2, R15.2, R16.2, R22.2, U6.2 (GND); also elsewhere on the board
HID_WORK_RUN_CTRL: R34.1; also elsewhere on the board
HID_WORK_RX: A3.16 (GPIO12); also elsewhere on the board
HID_WORK_TX: A3.17 (GPIO13); also elsewhere on the board
unnamed: A3.4 (GPIO2), R17.2
unnamed: A3.6 (GPIO4), R21.2, R22.1
unnamed: A3.31 (GPIO26_ADC0), R31.1
unnamed: A3.32 (GPIO27_ADC1), R32.1
unnamed: A3.D1 (SWCLK), J6.1
unnamed: A3.D3 (SWDIO), J6.2
unnamed: C10.1, J5.SH (SHIELD), R14.1
SYS_5V: A3.39 (VSYS); also elsewhere on the board
WORK_VBUS: J5.2 (VBUS_A4_B9), J5.11 (VBUS_B4_A9), R21.1; also elsewhere on the board

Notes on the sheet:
Role_Strap


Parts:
A1: Raspberry Pi Pico 2 W; RaspberryPi_Pico2W_Socket_Pogo
J2: Conn_01x05_Pin; PinHeader_1x05_P2.54mm_Vertical

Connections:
GND: A1.3 (GND), A1.8 (GND), A1.13 (GND), A1.18 (GND), A1.23 (GND), A1.28 (GND), A1.33 (AGND), A1.38 (GND), A1.D2 (GND), A1.TP1 (USB_GND), J2.3; also elsewhere on the board
HID_PERSONAL_RUN_CTRL: A1.4 (GPIO2); also elsewhere on the board
HID_PERSONAL_RX: A1.17 (GPIO13); also elsewhere on the board
HID_PERSONAL_TX: A1.16 (GPIO12); also elsewhere on the board
HID_WORK_RUN_CTRL: A1.25 (GPIO19); also elsewhere on the board
HID_WORK_RX: A1.27 (GPIO21); also elsewhere on the board
HID_WORK_TX: A1.26 (GPIO20); also elsewhere on the board
HOST_3V3: A1.36 (3V3), J2.5; also elsewhere on the board
KEYBOARD_VBUS_EN: A1.31 (GPIO26_ADC0); also elsewhere on the board
KEYBOARD_VBUS_FAULT: A1.32 (GPIO27_ADC1); also elsewhere on the board
MUX_STATUS: A1.34 (GPIO28_ADC2); also elsewhere on the board
unnamed: A1.30 (RUN), J2.4
unnamed: A1.D1 (SWCLK), J2.1
unnamed: A1.D3 (SWDIO), J2.2
POGO_5V_FAULT: A1.24 (GPIO18); also elsewhere on the board
POGO_DET: A1.29 (GPIO22); also elsewhere on the board
POGO_RX: A1.22 (GPIO17); also elsewhere on the board
POGO_TX: A1.21 (GPIO16); also elsewhere on the board
SYS_5V: A1.39 (VSYS); also elsewhere on the board
USB_HOST_D_N: A1.TP2 (USB_DM); also elsewhere on the board
USB_HOST_D_P: A1.TP3 (USB_DP); also elsewhere on the board


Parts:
C1: 100nF; C_0805_2012Metric_Pad1.18x1.45mm_HandSolder
C6, C7: 1uF; C_0805_2012Metric_Pad1.18x1.45mm_HandSolder
C15, C16: 100uF; CP_Elec_6.3x7.7
J1: L-KLS1-5416-L1-01-R; KLS L-KLS1-5416-L1-01-R
R5: 26.1k; R_0805_2012Metric_Pad1.20x1.40mm_HandSolder
R6: 10k; R_0805_2012Metric_Pad1.20x1.40mm_HandSolder
R7, R8: 56k; R_0805_2012Metric_Pad1.20x1.40mm_HandSolder
R9: 330; R_0805_2012Metric_Pad1.20x1.40mm_HandSolder
R28: 100k; R_0805_2012Metric_Pad1.20x1.40mm_HandSolder
U3: TPS2553DBVR; SOT-23-6
U4: TPD4E1U06DBVR; SOT-23-6

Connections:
/USB_KEYBOARD_HOST/CC1: J1.4 (CC1_A5), R8.1, U4.3 (D2+)
/USB_KEYBOARD_HOST/CC2: J1.10 (CC2_B5), R7.1, U4.4 (D2-)
GND: C1.1, C6.1, C7.1, C15.2, C16.2, J1.1 (GND_A1_B12), J1.12 (GND_B1_A12), R5.2, R9.2, R28.2, U3.2 (GND), U4.2 (GND); also elsewhere on the board
HOST_3V3: R6.1; also elsewhere on the board
KEYBOARD_VBUS: C7.2, C15.1, C16.1, J1.2 (VBUS_A4_B9), J1.11 (VBUS_B4_A9), R7.2, R8.2, U3.6 (OUT)
KEYBOARD_VBUS_EN: R28.1, U3.3 (EN); also elsewhere on the board
KEYBOARD_VBUS_FAULT: R6.2, U3.4 (FAULT); also elsewhere on the board
unnamed: C1.2, J1.SH (SHIELD), R9.1
unnamed: R5.1, U3.5 (ILIM)
SYS_5V: C6.2, U3.1 (IN); also elsewhere on the board
USB_HOST_D_N: J1.5 (DM_B7), J1.7 (DM_A7), U4.6 (D1-); also elsewhere on the board
USB_HOST_D_P: J1.6 (DP_A6), J1.8 (DP_B6), U4.1 (D1+); also elsewhere on the board


Board: 2 copper layers, 100.0 x 100.0 mm, 72 parts (0 on the bottom side), 60 nets.

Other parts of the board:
C3: 1µF; C_0805_2012Metric_Pad1.18x1.45mm_HandSolder
C8, C9: 1uF; C_0805_2012Metric_Pad1.18x1.45mm_HandSolder
C13, C14: 100uF; CP_Elec_6.3x7.7
H1, H2, H3, H4, H5, H6: MountingHole_3.2mm_M3
R1: 300K; R_0805_2012Metric_Pad1.20x1.40mm_HandSolder
R2: 100K; R_0805_2012Metric_Pad1.20x1.40mm_HandSolder
R3: 10k; R_0805_2012Metric_Pad1.20x1.40mm_HandSolder
U1: TPS2116DRL; SOT-583-8_HandSolder

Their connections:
GND: C3.1, C8.2, C9.1, C13.2, C14.2, R2.1, U1.1 (GND); also elsewhere on the board
HOST_3V3: R3.1; also elsewhere on the board
MUX_STATUS: R3.2, U1.8 (ST); also elsewhere on the board
unnamed: R1.1, R2.2, U1.4 (PR1)
PERSONAL_VBUS: C9.2, R1.2, U1.3 (VIN1), U1.5 (MODE); also elsewhere on the board
SYS_5V: C3.2, C13.1, C14.1, U1.2 (VOUT), U1.7 (VOUT); also elsewhere on the board
WORK_VBUS: C8.1, U1.6 (VIN2); also elsewhere on the board

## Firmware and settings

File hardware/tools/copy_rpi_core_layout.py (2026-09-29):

#!/usr/bin/python3
"""Copy Raspberry Pi's RP2350A core layout (regulator, crystal, decoupling) onto one MCU of a board.

Source: hardware/reference/rpi-rp2350a-minimal (Raspberry Pi RP2350A Minimal design, MIT license).

What it does, for one target MCU (e.g. U301):
  1. Maps each Raspberry Pi net to your net through the MCU's pads (U1 pad n <-> U301 pad n).
  2. Finds your support parts on the same schematic sheet as the MCU, matched by value and nets
     (L1 3.3u, C6/C7/C9 4.7u, R3 33, C8/C10/C11 100n on 1.1 V, C12-C18 100n on 3.3 V,
     X1 12 MHz, C3/C4 15p, R2 1k), and places them at Raspberry Pi's positions around your MCU,
     rotated with it.
  3. Copies the copper pours, tracks and vias of those nets around the chip, with your net names.

Run with KiCad's Python (KiCad closed, board saved), after "Update PCB from Schematic" (F8)
and after placing the MCU itself where you want it:

    /usr/bin/python3 hardware/tools/copy_rpi_core_layout.py hardware/dock-v2/dock-v2.kicad_pcb U301
    /usr/bin/python3 hardware/tools/copy_rpi_core_layout.py hardware/dock-v2/dock-v2.kicad_pcb U401

Options: --dry-run (report only), --no-copper (place parts only).
A backup <board>.before-<REF>.kicad_pcb is written first.
"""
import argparse
import math
import os
import re
import shutil
import sys

import pcbnew

HERE = os.path.dirname(os.path.abspath(__file__))
REF_BOARD = os.path.join(HERE, '..', 'reference', 'rpi-rp2350a-minimal', 'RPI-RP2350A-MINIMAL_R4-S1.kicad_pcb')
REF_MCU = 'U1'
# Raspberry Pi parts that belong to the MCU core (placed around the chip).
CORE_PARTS = ['L1', 'C6', 'C7', 'C9', 'R3', 'C8', 'C10', 'C11',
              'C12', 'C13', 'C14', 'C15', 'C16', 'C17', 'C18', 'X1', 'C3', 'C4', 'R2']
# Raspberry Pi nets whose copper around the chip is copied.
CORE_NETS = {'+3V3', 'GND', '+1V1', '/VREG_LX', '/VREG_AVDD', '/XIN', '/XOUT', 'Net-(C4-Pad1)'}
# Copper is copied only inside this box around the reference MCU (mm, reference coordinates).
REF_CENTRE = (100.0, 100.0)
BOX = (-12.0, -12.0, 12.0, 15.0)    # dx_min, dy_min, dx_max, dy_max
BOARD_WIDE = 20.0                   # zones larger than this (mm) are board-wide pours: skipped


# ----------------------------------------------------------------------------- reference file
def _blocks(s, tag):
    """Top-level (tag ...) blocks of a board file."""
    out, k = [], 0
    while True:
        i = s.find('\n\t(' + tag, k)
        if i < 0:
            return out
        d, j = 0, i + 1
        while True:
            c = s[j]
            if c == '"':
                j += 1
                while s[j] != '"':
                    j += 2 if s[j] == '\\' else 1
            elif c == '(':
                d += 1
            elif c == ')':
                d -= 1
                if d == 0:
                    break
            j += 1
        out.append(s[i + 1:j + 1])
        k = j


def _net(b):
    return re.search(r'\(net "?([^")]*)"?\)', b).group(1)


def read_reference():
    s = open(REF_BOARD).read()
    segs, vias, zones = [], [], []
    for b in _blocks(s, 'segment'):
        (x1, y1), (x2, y2) = [tuple(map(float, re.search(r'\(%s ([-\d.]+) ([-\d.]+)\)' % k, b).groups()))
                              for k in ('start', 'end')]
        segs.append(dict(a=(x1, y1), b=(x2, y2), w=float(re.search(r'\(width ([\d.]+)\)', b).group(1)),
                         layer=re.search(r'\(layer "([^"]+)"\)', b).group(1), net=_net(b)))
    for b in _blocks(s, 'via'):
        at = tuple(map(float, re.search(r'\(at ([-\d.]+) ([-\d.]+)\)', b).groups()))
        vias.append(dict(at=at, size=float(re.search(r'\(size ([\d.]+)\)', b).group(1)),
                         drill=float(re.search(r'\(drill ([\d.]+)\)', b).group(1)), net=_net(b)))
    for b in _blocks(s, 'zone'):
        if '(keepout' in b:
            continue
        poly = b[b.index('(polygon'):]
        if '(filled_polygon' in poly:
            poly = poly[:poly.index('(filled_polygon')]
        pts = [tuple(map(float, p)) for p in re.findall(r'\(xy ([-\d.]+) ([-\d.]+)\)', poly)]
        num = lambda pat, dflt: float(re.search(pat, b).group(1)) if re.search(pat, b) else dflt
        zones.append(dict(net=_net(b), layer=re.search(r'\(layers? "([^"]+)"', b).group(1), pts=pts,
                          prio=int(num(r'\(priority (\d+)\)', 0)),
                          clearance=num(r'\(connect_pads[^()]*\s*\(clearance ([\d.]+)\)', 0.2),
                          min_thickness=num(r'\(min_thickness ([\d.]+)\)', 0.2),
                          solid='(connect_pads yes' in b,
                          thermal_gap=num(r'\(thermal_gap ([\d.]+)\)', 0.5),
                          thermal_width=num(r'\(thermal_bridge_width ([\d.]+)\)', 0.5)))
    return segs, vias, zones


# ----------------------------------------------------------------------------- helpers
def mm(v):
    return pcbnew.ToMM(v)


def iu(v):
    return pcbnew.FromMM(v)


def norm_value(v):
    v = v.strip().lower().replace('µ', 'u').replace('ω', '').replace('ohm', '').replace(' ', '')
    v = re.sub(r'(?<=\d)f$', '', v)           # 100nf -> 100n, 15pf -> 15p
    v = re.sub(r'(?<=\d)h$', '', v)           # 3.3uh -> 3.3u
    v = re.sub(r'(?<=\d)hz$', '', v)          # 12mhz -> 12m
    v = re.sub(r'^(\d+)r(\d*)$', r'\1', v)    # 33r -> 33
    v = v.replace('12m', '12mhz')
    return v


def in_box(p):
    dx, dy = p[0] - REF_CENTRE[0], p[1] - REF_CENTRE[1]
    return BOX[0] <= dx <= BOX[2] and BOX[1] <= dy <= BOX[3]


def main():
    ap = argparse.ArgumentParser(description=__doc__, formatter_class=argparse.RawDescriptionHelpFormatter)
    ap.add_argument('board')
    ap.add_argument('mcu', help='reference of your RP2354A, e.g. U301')
    ap.add_argument('--dry-run', action='store_true')
    ap.add_argument('--no-copper', action='store_true')
    a = ap.parse_args()

    ref = pcbnew.LoadBoard(REF_BOARD)
    rfp = {f.GetReference(): f for f in ref.GetFootprints()}
    brd = pcbnew.LoadBoard(a.board)
    tfp = {f.GetReference(): f for f in brd.GetFootprints()}
    if a.mcu not in tfp:
        sys.exit(f'{a.mcu} not found on {a.board}. Run Update PCB from Schematic (F8) first.')
    rmcu, tmcu = rfp[REF_MCU], tfp[a.mcu]
    if tmcu.IsFlipped():
        sys.exit(f'{a.mcu} is on the back side; this script only handles the front side.')

    # 1. net map through the MCU pads
    netmap = {}
    rp = {p.GetNumber(): p.GetNetname() for p in rmcu.Pads()}
    for p in tmcu.Pads():
        rn, tn = rp.get(p.GetNumber()), p.GetNetname()
        if rn and tn:
            netmap.setdefault(rn, tn)
    missing = [n for n in CORE_NETS if n not in netmap and n not in ('/XOUT', 'Net-(C4-Pad1)')]
    if missing:
        print('warning: no net on', a.mcu, 'for', missing)

    # transform: reference frame (U1 at REF_CENTRE, 0 deg) -> target MCU frame
    tpos = tmcu.GetPosition()
    tx, ty, rot = mm(tpos.x), mm(tpos.y), tmcu.GetOrientationDegrees() - rmcu.GetOrientationDegrees()
    c, s_ = math.cos(math.radians(-rot)), math.sin(math.radians(-rot))   # KiCad: y down, angles CCW

    def T(p):
        dx, dy = p[0] - REF_CENTRE[0], p[1] - REF_CENTRE[1]
        return (tx + dx * c - dy * s_, ty + dx * s_ + dy * c)

    # 2. match support parts on the same sheet
    def sheet(f):
        return f.GetPath().AsString().rsplit('/', 1)[0]
    tsheet = sheet(tmcu)
    pool = [f for r, f in tfp.items() if r != a.mcu and sheet(f) == tsheet]
    placed = {}
    # nets of each ref part through the net map; XOUT/C4 net come from the chain X1-R2-C4
    for rr in CORE_PARTS:
        if rr not in rfp:
            continue
        rf = rfp[rr]
        want_val = norm_value(rf.GetValue())
        rnets = sorted({pd.GetNetname() for pd in rf.Pads() if pd.GetNetname()})
        want = sorted({netmap.get(n) for n in rnets if n in netmap})
        best = None
        for f in pool:
            if f in placed.values() or norm_value(f.GetValue()) != want_val:
                continue
            fn = {pd.GetNetname() for pd in f.Pads() if pd.GetNetname()}
            if set(want) <= fn:
                best = f
                break
        if best is None:
            print(f'  {rr:4} {rf.GetValue():6} nets {rnets}: no matching part on the sheet, skipped')
            continue
        placed[rr] = best
        # learn nets that only the support parts know (XOUT side of R2, C4-X1 node)
        for rpd in rf.Pads():
            n = rpd.GetNetname()
            if n and n not in netmap:
                for tpd in best.Pads():
                    if tpd.GetNumber() == rpd.GetNumber() and tpd.GetNetname():
                        netmap[n] = tpd.GetNetname()

    print(f'{a.mcu}: at ({tx:.3f}, {ty:.3f}) mm, {rot:.1f} deg; {len(placed)} of {len(CORE_PARTS)} core parts matched')
    for rr, f in placed.items():
        rf = rfp[rr]
        p = T((mm(rf.GetPosition().x), mm(rf.GetPosition().y)))
        print(f'  {rr:4} -> {f.GetReference():6} {f.GetValue():8} at ({p[0]:.3f}, {p[1]:.3f}) '
              f'rot {rf.GetOrientationDegrees() + rot:.1f}')
    if a.dry_run:
        print('net map:', {k: v for k, v in netmap.items() if k in CORE_NETS or k.startswith('Net-(C4')})

    # pad-by-pad check: does each pad carry the net RPi has on the same pad number?
    extra = {}
    for rr, f in placed.items():
        rnet = {pd.GetNumber(): netmap.get(pd.GetNetname()) for pd in rfp[rr].Pads()}
        tnet = {pd.GetNumber(): pd.GetNetname() for pd in f.Pads()}
        if all(rnet[n] is None or rnet[n] == tnet.get(n) for n in rnet):
            continue
        if len(rnet) == 2 and not rr.startswith(('L', 'X')) and \
                rnet.get('1') == tnet.get('2') and rnet.get('2') == tnet.get('1'):
            extra[rr] = 180          # non-polar part drawn the other way round: turn it
            print(f'  {rr} -> {f.GetReference()}: pins swapped in your schematic, turned 180 deg (fine for R/C)')
        else:
            print(f'  WARNING {rr} -> {f.GetReference()}: pad nets differ from RPi '
                  f'(RPi {rnet}, yours {tnet}). For the inductor, pin 1 (dot) must be the 1.1 V side. '
                  f'Fix the schematic; placed as RPi, check it in the PCB.')
    if a.dry_run:
        return

    shutil.copyfile(a.board, re.sub(r'\.kicad_pcb$', f'.before-{a.mcu}.kicad_pcb', a.board))
    for rr, f in placed.items():
        rf = rfp[rr]
        p = T((mm(rf.GetPosition().x), mm(rf.GetPosition().y)))
        if f.IsFlipped():
            f.Flip(f.GetPosition(), pcbnew.FLIP_DIRECTION_LEFT_RIGHT)
        f.SetOrientationDegrees(rf.GetOrientationDegrees() + rot + extra.get(rr, 0))
        f.SetPosition(pcbnew.VECTOR2I(iu(p[0]), iu(p[1])))

    if not a.no_copper:
        segs, vias, zones = read_reference()
        nets = brd.GetNetsByName()
        layer = {n: brd.GetLayerID(n) for n in ('F.Cu', 'B.Cu')}
        added = [0, 0, 0]

        def tnet(rn):
            n = netmap.get(rn)
            return nets[n] if n and nets.has_key(n) else None
        for sg in segs:
            n = tnet(sg['net'])
            if sg['net'] in CORE_NETS | {'Net-(C4-Pad1)'} and n and in_box(sg['a']) and in_box(sg['b']):
                t = pcbnew.PCB_TRACK(brd)
                t.SetStart(pcbnew.VECTOR2I(*map(iu, T(sg['a']))))
                t.SetEnd(pcbnew.VECTOR2I(*map(iu, T(sg['b']))))
                t.SetWidth(iu(sg['w'])); t.SetLayer(layer[sg['layer']]); t.SetNet(n)
                brd.Add(t); added[0] += 1
        for v in vias:
            n = tnet(v['net'])
            if v['net'] in CORE_NETS and n and in_box(v['at']):
                t = pcbnew.PCB_VIA(brd)
                t.SetPosition(pcbnew.VECTOR2I(*map(iu, T(v['at']))))
                t.SetWidth(iu(v['size'])); t.SetDrill(iu(v['drill'])); t.SetNet(n)
                t.SetViaType(pcbnew.VIATYPE_THROUGH); t.SetLayerPair(layer['F.Cu'], layer['B.Cu'])
                brd.Add(t); added[1] += 1
        for z in zones:
            xs = [p[0] for p in z['pts']]; ys = [p[1] for p in z['pts']]
            if max(xs) - min(xs) > BOARD_WIDE or max(ys) - min(ys) > BOARD_WIDE:
                continue
            n = tnet(z['net'])
            if z['net'] not in CORE_NETS or not n or not all(in_box(p) for p in z['pts']):
                continue
            zn = pcbnew.ZONE(brd)
            zn.SetLayer(layer[z['layer']]); zn.SetNet(n)
            zn.SetAssignedPriority(z['prio'])
            zn.SetLocalClearance(iu(z['clearance']))
            zn.SetMinThickness(iu(z['min_thickness']))
            zn.SetPadConnection(pcbnew.ZONE_CONNECTION_FULL if z['solid'] else pcbnew.ZONE_CONNECTION_THERMAL)
            zn.SetThermalReliefGap(iu(z['thermal_gap']))
            zn.SetThermalReliefSpokeWidth(iu(z['thermal_width']))
            ol = zn.Outline(); ol.NewOutline()
            for p in z['pts']:
                q = T(p); ol.Append(iu(q[0]), iu(q[1]))
            brd.Add(zn); added[2] += 1
        pcbnew.ZONE_FILLER(brd).Fill(brd.Zones())
        print(f'copied {added[0]} tracks, {added[1]} vias, {added[2]} pours')
    pcbnew.SaveBoard(a.board, brd)
    print('saved', a.board)


if __name__ == '__main__':
    main()

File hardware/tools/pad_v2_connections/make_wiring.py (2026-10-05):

"""Generate hardware/pad-v2/PAD_WIRING.md: a component-by-component wiring list (needs kicad-cli).

For every part, in the order of the groups on its sheet: every pin and exactly what it connects to,
plus which kind of label to draw. Built from pad_nets.py.
"""
import json, os, re, subprocess, sys, tempfile
HERE = os.path.dirname(os.path.abspath(__file__))
sys.path.insert(0, HERE)
from pad_nets import NETS, NC, GPIO, ESP_PIN, ESP_SIDE, GOES, CHAIN

NETFILE = os.path.join(tempfile.gettempdir(), 'pad_v2_wiring.net')
subprocess.run(['kicad-cli', 'sch', 'export', 'netlist', '-o', NETFILE,
                os.path.join(HERE, '..', '..', 'pad-v2', 'pad-v2.kicad_sch')], check=True, capture_output=True)
s = open(NETFILE).read()
COMP = {}
for m in re.finditer(r'\(comp\s*\(ref "([^"]+)"\)(.*?)\n\t\t\)', s, re.S):
    b = m.group(2)
    f = {fm.group(1): fm.group(2) for fm in re.finditer(r'\(field\s*\(name "([^"]+)"\)\s*"((?:[^"\\]|\\.)*)"', b)}
    COMP[m.group(1)] = dict(value=re.search(r'\(value "([^"]*)"\)', b).group(1),
                            part=re.search(r'\(part "([^"]+)"\)', b).group(1), note=f.get('Note', ''))
# parts in the connection model / groups but not (or no longer) in the schematic
_model_refs = {p.split('.')[0] for p in [q for v in NETS.values() for q in v] + NC}
_model_refs |= {r for g in json.load(open(os.path.join(HERE, 'groups.json'))).values() for _, rs in g for r in rs}
for _r in _model_refs:
    COMP.setdefault(_r, dict(value='(not in the schematic)', fp='', part='', lcsc='', note='not in the schematic'))
PINNAME = {}
for m in re.finditer(r'\(libpart\s*\(lib "[^"]*"\)\s*\(part "([^"]+)"\)(.*?)\n\t\t\)', s, re.S):
    PINNAME[m.group(1)] = dict(re.findall(r'\(pin\s*\(num "([^"]+)"\)\s*\(name "([^"]*)"', m.group(2)))
GROUPS = json.load(open(os.path.join(HERE, 'groups.json')))

SHEET = {'1': 'POWER', '2': 'MCU', '3': 'INPUTS', '4': 'RGB', '5': 'DISPLAY'}
FILE = {'POWER': 'power.kicad_sch', 'MCU': 'mcu.kicad_sch', 'INPUTS': 'inputs.kicad_sch', 'RGB': 'rgb.kicad_sch', 'DISPLAY': 'display.kicad_sch'}
POWER_SYMBOLS = {'GND', '+3V3'}
PWR_FLAGS = {'POGO_5V': 'POWER', 'VIN_PROT': 'POWER', 'VSYS': 'POWER', 'VBAT': 'POWER', 'BAT_N': 'POWER', '+3V3': 'POWER', 'GND': 'POWER', '5V_RGB': 'RGB', 'DISP_VCC': 'DISPLAY'}
ZONE = {}

where = {p: n for n, pins in NETS.items() for p in pins}
ncset = set(NC)
sheet_of = lambda ref: SHEET[re.sub(r'\D', '', ref)[0]]

def pname(ref, pin):
    n = PINNAME.get(COMP[ref]['part'], {}).get(pin, '')
    n = n.replace('~{', '').replace('}', '')
    return n if n and n != pin and n != '~' else ''

def pinref(p):
    r, q = p.split('.', 1)
    n = pname(r, q)
    return f'{r}.{q}' + (f' ({n})' if n else '')

def net_sheets(net):
    return {sheet_of(p.split('.')[0]) for p in NETS[net]}

def draw(net, sheet):
    if net in POWER_SYMBOLS:
        return f'power symbol `{net}`'
    if len(net_sheets(net)) > 1:
        return f'**global label `{net}`**'
    return f'wire (or local label `{net}`)'

def partners(net, me, sheet):
    if net in POWER_SYMBOLS:
        return ''
    others = [p for p in NETS[net] if p.split('.')[0] != me]
    if len(others) > 12:
        return f'{len(others)} other pins: use the label'
    here = [pinref(p) for p in others if sheet_of(p.split('.')[0]) == sheet]
    away = {}
    for p in others:
        sh = sheet_of(p.split('.')[0])
        if sh != sheet:
            away.setdefault(sh, []).append(pinref(p))
    txt = ', '.join(here) if here else ''
    for sh, lst in away.items():
        txt += ('; ' if txt else '') + f'{sh} sheet: ' + ', '.join(lst)
    return txt or '(only this part)'

def pins_of(ref):
    ps = [p.split('.', 1)[1] for p in list(where) + NC if p.split('.', 1)[0] == ref]
    return sorted(set(ps), key=lambda x: (re.sub(r'\d', '', x), int(re.sub(r'\D', '', x) or 0)))

def component(ref, sheet):
    c = COMP[ref]
    head = f'#### {ref} · {c["value"]}' + (f' · {c["note"]}' if c['note'] else '')
    pins = pins_of(ref)
    if not pins:
        return head + '\n\nNo pins (mechanical only).\n'
    rows = ['| Pin | Net | Connects to | Draw |', '|---|---|---|---|']
    for q in pins:
        key = f'{ref}.{q}'
        n = pname(ref, q)
        pin = f'{q}' + (f' {n}' if n else '')
        if key in ncset:
            rows.append(f'| {pin} | — | nothing | no-connect flag (X) |')
        else:
            net = where[key]
            rows.append(f'| {pin} | {net} | {partners(net, ref, sheet)} | {draw(net, sheet)} |')
    return head + '\n\n' + '\n'.join(rows) + '\n'
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

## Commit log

2026-09-23 Scaffold KiCad projects for dock and pad boards
    Blank, KiCad-10-validated .kicad_pro/.kicad_sch/.kicad_pcb files with
    the hierarchical sheet structure from README.md/DESIGN.md section 19
    (dock: POWER, USB_KEYBOARD_HOST, RP2350_HOST, HID_PERSONAL, HID_WORK,
    BLE_BASE; pad: BATTERY_CHARGER, POWER_RAILS, NRF52840, INPUTS, RGB,
    DISPLAY, DOCK_INTERFACE). Root sheets reference each sub-sheet; all
    files verified to parse via kicad-cli sch erc / pcb drc.
    [battery_charger.kicad_sch, ble_base.kicad_sch, display.kicad_sch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]
2026-09-24 Dock schematic: review fixes, Pico 2/XIAO socket+pogo mounting
    - Cross HID UART TX/RX; split ROLE_STRAP per endpoint
    - VBUS sense (GP4) and USB-C CC current sensing (GP26/27) on HID endpoints
    - Pogo +5V via TPS2552 enabled by DET, TPD4E1U06 ESD + 1k on pogo lines
    - 2x100uF bulk on SYS_5V and keyboard VBUS; 100k EN pull-down
    - Remove TPS62162 rail: XIAO from 5V, pull-ups on module 3V3 rails
    - Socketed Pico 2 / XIAO footprints with P50-B1 probe holes for USB+SWD
    - XIAO SWD header J8; RP2350 reset control of HID/BLE endpoints
    - DESIGN.md: UART allocation, power budget, mounting, reset control
    - Add .gitignore, custom libraries and datasheets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
    [ble_base.kicad_sch, dock.kicad_pcb, dock.kicad_sch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]
2026-09-24 Net classes, project lib tables, docs and datasheets; PCB synced
    - Rename USB pairs to *_D_P/*_D_N; add Power and USB net classes
    - Project-relative fp-lib-table and new sym-lib-table
    - Pico values set to "Raspberry Pi Pico 2"; J1 symbol synced with library
    - DESIGN.md/README: Pico 2 x3 + XIAO modules, TPS2116, pogo switch/ESD,
    VBUS/CC sensing, SWD pinout, resolved and open items
    - Add TPS2552/2553, TPD2EUSB30 and P50 probe datasheets
    - PCB updated from schematic (F8)
    [ble_base.kicad_sch, dock.kicad_pcb, hid_personal.kicad_sch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]
2026-09-24 USB ESD: TPD2EUSB30 -> TPD4E1U06 on all ports; Pico TP4-6 pads
    - U4-U6 now TPD4E1U06 (SOT-23-6, hand-solderable): D+, D-, CC1, CC2
    per port; clamps to GND only, so no back-feed path into PC VBUS
    - Keyboard port CC nets named CC1/CC2 (R7/R8 moved along their rows)
    - Pico 2 footprint: TP4-TP6 as covered copper-only pads at datasheet
    positions (satisfies F8 pad check, no extra holes)
    - Drop unused cached symbols; docs updated; remove TPD2EUSB30 datasheet
    [hid_personal.kicad_sch, hid_work.kicad_sch, power.kicad_sch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]
2026-09-25 Set part values; drop unused Seeed library; add Panasonic FK datasheet
    - U3 value TPS2553DBVR, J1/J4/J5 value L-KLS1-5416-L1-01-R
    - Remove hardware/libraries/seed-xio and its fp-lib-table entry (XIAO now
    uses dock:XIAO_nRF52840_Socket_Pogo; nothing references xiao:)
    - Add Panasonic FK series catalog (C13-C16, EEE-FK1E101XP)
    [hid_personal.kicad_sch, hid_work.kicad_sch, usb_keyboard_host.kicad_sch]
2026-09-25 TPS2116: hand-solder SOT-583-8 footprint with extended pads
    Pads 1.2 x 0.3 mm (inner edge unchanged, outer edge +0.53 mm) so the
    0.5 mm-pitch DRL package can be soldered with an iron. TPS2116 is only
    available in DRL, so the package itself cannot be enlarged.
    [power.kicad_sch]
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2026-09-25 Re-pin host/endpoint GPIOs by PCB position; update placement guide
    - Host A1: HID-A UART0 -> GP12/13, HID-B UART1 -> GP20/21, BLE PIO ->
    GP16/17, KEYBOARD_VBUS_EN/FAULT -> GP26/27, MUX_STATUS -> GP28,
    POGO_5V_FAULT -> GP18, HID_PERSONAL_RUN_CTRL -> GP2,
    HID_WORK_RUN_CTRL -> GP19 (BLE_RST_CTRL stays GP22)
    - HID-A UART0 -> GP16/17, HID-B UART0 -> GP12/13 (pins facing the host)
    - Ratsnest crossings on current placement 132 -> 95
    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
    [ble_base.kicad_sch, dock.kicad_pcb, dock.kicad_sch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]
2026-09-25 Host becomes Pico 2 W (on-board BLE); remove XIAO nRF52840
    - A1 -> Raspberry Pi Pico 2 W, new footprint RaspberryPi_Pico2W_Socket_Pogo
    (TP1-3 probes unchanged, SWD via 1x3 socket under the debug holes,
    TP4-6 at Pico 2 W positions, 14x9 mm antenna keep-out)
    - Remove U7 (XIAO), J8 and R35; BLE UART and BLE_RST_CTRL gone
    - Pogo TX/RX/DET now go to the host: GP16 (PIO TX), GP17 (PIO RX),
    GP22 (DET); R18 pulls DET up to HOST_3V3
    - HID-A: CC1/CC2 on U5 and R29/R30 swapped for routing (user change)
    - DESIGN.md/README/PCB_PLACEMENT.md updated; board includes in-progress
    routing and B.Cu GND zone (not yet updated from schematic)
    [ble_base.kicad_sch, dock.kicad_pcb, hid_personal.kicad_sch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]
2026-09-25 Dock PCB routing complete; add dock BOM
    - Board: all nets routed, 0 unconnected, 0 schematic-parity errors;
    B.Cu GND plane; USB-C second D+/D-/VBUS pads and shield tabs joined;
    power paths at 0.6 mm with short neck-downs at U1
    - Remaining DRC: courtyard overlaps for resistors under the Picos
    (excluded, intentional) and minor silkscreen notes
    - hardware/dock/BOM.xlsx: 28 lines (66 schematic parts + mechanical +
    PCB) with editable spares/pack/price/shop/URL and formula totals
    [BOM.xlsx, ble_base.kicad_sch, dock.kicad_pcb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]
2026-09-26 BOM: H-version Picos (pre-soldered headers); host debug JST replaced by 1x3 header
    [BOM.xlsx]
2026-09-26 Dock PCB: J7 moved to board edge, zones refilled; add JLCPCB fab outputs
    [dock-B_Cu.gbl, dock-B_Mask.gbs, dock-B_Paste.gbp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]
2026-09-26 Dock: add six M3 mounting holes; BOM gets PCB price, USD rate cell and 1x19 socket note
    [BOM.xlsx, dock.kicad_pcb]
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2026-09-27 Pad schematic: first capture (all sheets), custom symbols, hand-solder SOT-563 and MX hot-swap footprints, GPIO map
    [battery_charger.kicad_sch, display.kicad_sch, dock_interface.kicad_sch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]
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2026-09-28 Pad schematic: hand-redrawn from the connection guide; netlist verified against the reference
    [battery_charger.kicad_sch, display.kicad_sch, dock_interface.kicad_sch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]
2026-09-28 Pad: single main PCB layout, 1.69in display on 9-pin JST-PH cable, pogo board split (empty project), concept drawing, heights 25/44 mm
    [pogo.kicad_pcb, pogo.kicad_sch]
2026-09-28 Pad: display on 9-pin JST-PH with backlight MOSFET (GP27), pogo cable connector; pogo board schematic; guide updated to final refs
    [display.kicad_sch, dock_interface.kicad_sch, mcu.kicad_sch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]
2026-09-28 Pad PCB: first placement; SWD header removed, side-entry JST connectors, new footprints
    - J4 (SWD) removed; A1 on the NoSWD Pico socket footprint (holes would sit under key 5)
    - J1/J7/J2/J3 side-entry JST (S*B), J5 stays vertical
    - New footprints: PEC11R encoder (13.2 mm lugs), SOIC-8-1EP hand-solder (TP4056),
    narrower SOT-563 pads
    - All footprints placed on the 100 x 92 board; ring LEDs radial at R 12.7,
    encoders at 16.6 / 83.4; edge clearance rule 0.2 mm
    - PCB_PLACEMENT.md and placement drawings in docs/
    [battery_charger.kicad_sch, display.kicad_sch, dock_interface.kicad_sch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]
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2026-09-29 Dock v2 design review: part decisions and placement groups
    Research and decisions per topic in docs/:
    - MCUs: 2x RP2354A + ESP32-C3-MINI-1 (no single chip has three usable USB 2.0 controllers)
    - Power input: CH224A 9 V (I2C to MCU A) -> TPS54331 -> AMS1117, no PC-power fallback
    - USB ports: four TYPE-C-31-M-12, TPD4E1U06 ESD, keyboard port as a USB-C source with
    firmware CC detection, 22 ohm series, 220 uF THT bulk on keyboard VBUS
    - Pogo: SY6280 switched by DET through a 2N7002 (hardware enable), 1 A limit
    - MCU support: ABM8-272-T3 crystal, RPi Minimal regulator layout, A resets/flashes B (SWD)
    and the ESP32-C3
    hardware/dock-v2/PCB_PLACEMENT.md: edges (PCs back, keyboard left, power r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
2026-09-29 Dock v2: empty KiCad project (6 sheets, 4-layer board)
    hardware/dock-v2/: top-level schematic with empty POWER, USB_PORTS, MCU_A,
    MCU_B, BLE and POGO sheets (annotation: sheet number x 100), empty 4-layer
    board with v1's design rules, v1 net classes with v2 net-name patterns,
    project symbol library seeded with TPD4E1U06DBV. PCB_PLACEMENT.md gains a
    list of which parts have stock KiCad symbols/footprints and which need custom ones.
    [ble.kicad_sch, dock-v2.kicad_pcb, dock-v2.kicad_sch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]
2026-09-29 Dock v2: custom symbols/footprints, RPi reference design, core-layout copy script
    Symbols (dock_v2_custom): RP2354A_RPiFP, ESP32-C3-MINI-1 (Espressif), CH224A
    (from KiCad's CH224K, CH224A pin names), TPS54331DR, SY6280AAC, TPD4E1U06DBV.
    Every symbol's pins match its footprint's pads one to one.
    Footprints (libraries/dock_v2.pretty): Raspberry Pi's RP2350A QFN-60 with
    thermal vias, AOTA 0806 inductor (pad 1 = polarity dot) and wide 0402 cap,
    extracted from the RP2350A Minimal design (MIT); Espressif's ESP32-C3-MINI-1
    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
    [RPI-RP2350A-MINIMAL_R4-S1.kicad_pcb, RPI-RP2350A-MINIMAL_R4-S1.kicad_sch]
2026-09-29 Dock v2: all parts placed on their sheets (not wired)
    149 parts across POWER, USB_PORTS, MCU_A, MCU_B, BLE and POGO (A3), in
    labelled groups, with references (sheet x 100), values, footprints, LCSC
    numbers (hidden LCSC field) and a Note per part. Only unconnected-pin ERC
    messages remain.
    5 V buck values from TI's TPS54331 Table 7-1 (5 V design), moved to Basic
    parts: 12k/2.2k feedback (5.16 V), 51k + 4.7nF + 47pF compensation, 10 nF
    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
    [ble.kicad_sch, mcu_a.kicad_sch, mcu_b.kicad_sch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]
2026-09-29 Dock v2: connection guide (DOCK_CONNECTIONS.md), pin maps, wiring checker
    hardware/dock-v2/DOCK_CONNECTIONS.md, in the style of the pad's guide: per
    sheet a sketch, parts table (value, footprint, LCSC, job), pin-by-pin wiring
    tables, placement notes; MCU A/B pin maps; nets that cross sheets (global
    labels); PWR_FLAG and no-connect lists; full net index. Tables are generated
    from one connection model (tools/dock_v2_connections/dock_nets.py) that is
    checked against the placed schematic: 570 pins, each on a net or NC exactly once.
    Found while making the pin map: MCU A's pins are weak pull-downs at reset, so
    added 10k pull-ups on B_RUN, B_BOOTSEL (R406, R407) and ESP32 GPIO9 (R504),
    and POGO_OF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
    [ble.kicad_sch, mcu_a.kicad_sch, mcu_b.kicad_sch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]
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2026-09-29 7-pin pogo (2 x +5V, 2 x GND), README and DESIGN for the v2 dock
    Pogo: both halves move from the 6-pin to the Motorobit 7-pin 2.54 mm magnetic
    set (1 A per contact). Dock side GND | +5V | +5V | DET | RX | TX | GND, pad side
    mirrored. New footprint dock:Pogo-7 (scaled from Pogo-6, marked through-hole).
    Dock J601 -> Conn_01x07; pogo switch R606 6.8k -> 4.7k (1.45 A, 1.09-1.81 A,
    below the 2 A of two contacts), so the pad no longer has to dim its LEDs while
    docked. Pad pogo board J1 -> 7 pins, pins 5+6 = POGO_5V, pin 7 = GND (nets
    verified before/after). Connection model, guide, pogo/power/placement docs and
    PAD_CONNECTIONS updated.
    README and DESIGN rewritten for the v2 dock (sections 1-7, 15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
    [pogo.kicad_sch]
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2026-09-30 Dock v2 schematic: wiring in progress (user's work, snapshot before fixes)
    [ble.kicad_sch, dock-v2.kicad_sch, mcu_a.kicad_sch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]
2026-09-30 Dock v2 schematic fixes after review (J601 7-pin, Q602/R609, part data)
    KiCad had the sheets open when the 7-pin pogo and the pull-up/veto parts were
    added, and its save restored the old state. Restored now (KiCad closed):
    - J601 -> Conn_01x07, footprint dock:Pogo-7; R606 4.7k (1.45 A)
    - Q602 + R609 (POGO_OFF veto) added back to the pogo sheet
    - L101 footprint L_TechFuse_SL0630 / LCSC C207841 again
    - R406/R407 had the 1k LCSC number (copied from R405): now C25744; notes fixed
    on R406, R407, R504
    - references back to the docs: C205->C107, R223->R106, R306->R201, R304->R202;
    R103/R104 swapped so R103 is on SCL and R104 on SDA (they were swapped, harmless)
    - global label typo PD_SCA -> PD_S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
    [ble.kicad_sch, mcu_a.kicad_sch, mcu_b.kicad_sch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]
2026-10-01 Dock v2 schematic: pogo sheet wired, fixes from review (user's work, snapshot)
    [ble.kicad_sch, mcu_a.kicad_sch, mcu_b.kicad_sch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]
2026-10-01 Pogo order GND | +5V | DET | RX | TX | +5V | GND (5 V at both ends)
    The dock's J601 now has +5V on pins 2 and 6, like GND on 1 and 7 (user's change
    in the schematic). Pad side mirrors to GND | +5V | TX | RX | DET | +5V | GND.
    Power pins are mirror-symmetric, so a reversed pad is still powered correctly;
    only the UART lines cross (through 1 kOhm, harmless).
    - connection model: J601 pins and the U601 ESD channels as wired
    - guides regenerated (DOCK_CONNECTIONS, DOCK_WIRING); generators now list parts
    that aren't in the schematic instead of failing
    - pad pogo board (hardware/pogo) rewired to the mirrored order with labels;
    nets verified (POGO_5V J1.2/J1.6, DTX J1.3, DRX J1.4, GND J1.1/5/7)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
    [pogo.kicad_sch]
2026-10-01 Dock v2 schematic: user's fixes (snapshot)
    [mcu_a.kicad_sch, pogo.kicad_sch]
2026-10-01 Dock v2 schematic: PWR_FLAGs, one name per power net, ESP32 USB test pads dropped
    - PWR_FLAGs on GND, VBUS_IN, 5V_PWR, A_1V1, A_VREG_AVDD, B_1V1, B_VREG_AVDD
    (each with a label at a pin of the net, which also names the five nets that
    were unnamed: VBUS_IN, A/B_1V1, A/B_VREG_AVDD)
    - GNDPWR symbol -> GND; duplicate +3.3V/+5V power symbols and their now-dangling
    3V3_PWR/5V_PWR labels removed (connectivity verified identical before/after)
    - TP501/TP502 (ESP32 GPIO18/19 USB pads) not needed: pins 26/27 are no-connects
    in the model; docs and guides updated (fallback flashing: TXD0/RXD0 pads)
    ERC: 0 errors, 0 warnings. check_wiring.py: OK, wiring matches the guide.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
    [mcu_a.kicad_sch, mcu_b.kicad_sch, power.kicad_sch]
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2026-10-03 Dock v2: MCU A/B GPIO map reassigned for routing (ESP32 front-left, 2-layer goal)
    A: KBD PIO-USB on GPIO2/3 (DMDP), BLE on UART0 GPIO12/13, pogo on the
    bottom pins, CH224A on I2C1 GPIO18/19 (+PG 17) routed under B, B
    RUN/SWD on GPIO20-22, B link on UART1 GPIO23/24, BOOTSEL B on GPIO25,
    ADC order reversed. B: link on GPIO5/6, WRK_VBUS_DET on GPIO29.
    Docs: GPIO numbers in DOCK_CONNECTIONS now come from dock_nets.py.
    [mcu_a.kicad_sch, mcu_b.kicad_sch]
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2026-10-04 Dock v2 PCB: fix unconnected nets, widen power traces, readable silkscreen, 2 copper layers
    - MCU A and B IOVDD (pins 30/38) had no 3V3 feed: added an under-chip jumper (A)
    and a top-layer feed to the 3V3 via by the buck (B)
    - MCU B's exposed pad sat in a GND pour island: 3V3 bottom ring via moved so the
    plane reaches it; crystal B GND vias added; pour clearance 0.5 -> 0.3 mm
    - power traces widened where clearance allows (switch node 1.5 mm, 5 V 1.0 mm,
    VBUS_IN/POGO_5V/KBD_VBUS as far as fits); VBUS_IN vias 0.8/0.4
    - silkscreen: refs 0.8/1.0 mm, re-placed clear of pads and parts, labels for
    connectors, buttons, LEDs and ESP32 UART pads; 22 small passives hidden
    - copper layers 4 -> 2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
    [dock-v2.kicad_pcb, mcu_a.kicad_sch, mcu_b.kicad_sch]
2026-10-04 Dock v2: six M3 mounting holes, U102 CFG1/PG tracks joined, SWD headers in the model
    - H1-H6 (MountingHole_3.2mm_M3, unplated) added to the root schematic and placed:
    back (146,39)/(212,39) beside the USB-C ports, sides (133,58)/(225,58),
    front (160,131)/(200,131) either side of the pogo; symmetric about x = 179-180,
    clear of the ESP32 antenna
    - R101/R102 tracks ended 1 mm short of U102 pins 9/10: joined
    - J401 (SWD A) and J501 (SWD B) added to the connection model and docs
    DRC: 0 violations, 0 unconnected, 0 parity issues. ERC: 1 old warning.
    [dock-v2.kicad_pcb, dock-v2.kicad_sch]
2026-10-04 Dock v2: extra mounting holes around the USB-C ports (user's work), H7-H10 given own symbols
    The four added holes were copies of H5 (same reference and schematic link);
    renamed H7-H10 with their own MountingHole symbols on the root sheet.
    DRC: 0 violations, 0 unconnected, 0 parity issues.
    [dock-v2.kicad_pcb, dock-v2.kicad_sch]
2026-10-04 Dock v2: J601 becomes a JST-XH 7-pin cable header (pad docks on top)
    - pad sits on top of the dock (decided): straight Motorobit 7-pin pogo contacts
    on a small lid board (same design as the pad's pogo board), cabled 1:1 to J601
    - J601: B7B-XH-A (LCSC C144398) on the original pin row; 5 V link between
    pins 2/6 moved 0.75 mm lower to clear the larger XH pads; silk trimmed at the edge
    - pad MCU decided: ESP32-S3-MINI-1-N8 (README)
    - docs: pogo, placement, DESIGN §15/§17, README, generated guides
    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
    [dock-v2.kicad_pcb, pogo.kicad_sch]
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

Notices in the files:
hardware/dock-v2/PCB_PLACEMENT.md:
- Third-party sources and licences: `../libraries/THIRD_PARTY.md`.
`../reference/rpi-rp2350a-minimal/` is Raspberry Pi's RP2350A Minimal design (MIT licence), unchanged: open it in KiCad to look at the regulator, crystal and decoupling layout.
